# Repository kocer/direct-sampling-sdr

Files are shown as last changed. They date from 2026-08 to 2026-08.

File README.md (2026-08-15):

# Direct-Sampling SDR

A direct-sampling software-defined radio transceiver and its power
amplifier for the amateur bands from 1.8 MHz to 54 MHz.

## What the equipment does

The receiver samples the antenna signal directly. It does not use a
mixer and it does not use an intermediate frequency. Four receive
channels operate at the same time. The four channels use one clock.
Thus the channels keep a constant phase relation.

The transmitter uses the same four channels in the opposite direction.
The power amplifier increases the transmit power to a maximum of 100 W.

| Item | Value |
|---|---|
| Frequency range | 1.8 MHz to 54 MHz |
| Receive channels | 4, phase coherent |
| Transmit channels | 4 |
| ADC | AD9251BCPZ-80, 14 bit, dual, 80 MSPS |
| DAC | AD9767, 14 bit, dual, operated at 80 MSPS |
| FPGA | Lattice ECP5 LFE5U-25F, BG256 |
| Filter bands | 7 for each channel |
| Amplifier power | 5, 10, 25, 50, 75 and 100 W |
| Amplifier class | A, at all power levels |
| Host interface | 2 x gigabit ethernet |
| Sample clock | 80.000 MHz VCXO, ABLNO-V |
| Clock jitter | 81 fs narrow band, 162 fs wide band |
| Reference | 10 MHz external, or GPS |

## The three boards

| Board | Function | Size | Layers |
|---|---|---|---|
| A | Main board: ADC, DAC, FPGA, ethernet | 235 x 225 mm | 6 |
| C | RF board: filters, transmit/receive relays | 350 x 235 mm | 2 |
| D | Power amplifier: driver, finals, low-pass filters | 275 x 185 mm | 2 |

Board B does not exist. The first design had a separate clock board.
The clock circuit is now on board A, because the distance from the clock
to the ADC controls the phase accuracy.

## Signal path

The receive path:

1. The antenna connects to board C.
2. The band filter removes the unwanted signals.
3. The transmit/receive relay connects the filter to the receive path.
4. The attenuator sets the signal level.
5. Board A receives the signal.
6. The transformer makes the signal differential.
7. The ADC samples the signal.
8. The FPGA processes the samples.
9. The ethernet interface sends the data to the host.

The transmit path:

1. The host sends the data to board A.
2. The DAC makes the analog signal.
3. Board D receives the signal.
4. The driver stage increases the power.
5. The four final transistors increase the power to 100 W.
6. The low-pass filter removes the harmonics.
7. The directional coupler measures the forward and the reflected power.
8. The antenna radiates the signal.

## Why direct sampling

A superheterodyne receiver mixes the input signal to a lower frequency.
The mixer makes unwanted products. The local oscillator adds noise.
Each conversion stage adds distortion.

A direct-sampling receiver has none of these stages. The ADC samples the
antenna signal. The remaining signal path is digital, thus it is exact
and it does not change with the temperature.

The clock sets the limit at high frequency. The jitter of the clock
gives this maximum signal-to-noise ratio:

    SNR = -20 x log10(2 x pi x f x t_jitter)

The VCXO contributes 60 fs and the fan-out buffer adds 54 fs in a narrow
band or 150 fs in a wide band. Together they give 81 fs and 162 fs.

| Input frequency | Jitter | SNR limit | What limits the result |
|---|---|---|---|
| 30 MHz | 81 fs | 96 dB | The noise of the ADC |
| 500 MHz | 81 fs | 72 dB | At the limit |
| 500 MHz | 162 fs | 66 dB | The jitter of the clock |

In the amateur bands the noise of the ADC is the limit and the clock is
not. The clock becomes the limit only when the receiver undersamples
near 500 MHz. A better clock part costs ten times more, and 66 dB is
still 11 effective bits.

## Why four coherent channels

Four channels that share one clock keep a constant phase relation. This
makes these functions possible:

- Removal of a local noise source with a second antenna
- Measurement of the direction of a signal
- Increase of the antenna gain in one direction
- Measurement of meteor trails with two or more sites

A receiver with one channel cannot do these functions.

## Licenses

| Content | License |
|---|---|
| Hardware design | CERN-OHL-S-2.0 |
| Software and scripts | GPL-3.0 |
| Documentation | CC-BY-SA-4.0 |

## Repository content

| Directory | Content |
|---|---|
| `hardware/kicad/A_main` | Board A: schematic, PCB, generator scripts |
| `hardware/kicad/C_rf` | Board C |
| `hardware/kicad/D_pa` | Board D |
| `hardware/kicad/lib` | Symbols and footprints |
| `gateware/rtl` | Verilog source for the ECP5 |
| `gateware/sim` | Test benches |
| `gateware/sentez` | Synthesis and place-and-route scripts |
| `docs` | Design documentation |

The schematics are not drawn by hand. Python scripts make them. Each
script writes one sheet. To change a sheet, change the script and run
it again. The document `docs/TOOLS.md` gives the procedure.

## Status

The three schematics are complete. The electrical rule check finds no
errors on the three boards. The placement is complete. The routing is
in progress. No board is ready for manufacture.

The gateware operates in simulation. 21 test benches pass. The design
fits in the ECP5-25F and it meets the timing of all five clocks. The
receive chain, the transmit chain, the packet interface and the
control interface are complete. The SDRAM interface and the digital
predistortion do not exist.

Verification tools examine the boards and the schematics. They find
faults that the electrical rule check cannot find. An example: a
symbol pin number that does not agree with a footprint pad number
makes a net that goes nowhere, but the rule check sees a correct
wire. The commit messages give the details of each fault.

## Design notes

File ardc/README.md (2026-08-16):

# Direct-sampling SDR transceiver — ARDC technical annex

**Project:** a four-channel, phase-coherent, direct RF sampling transceiver
**For:** the amateur radio club of TEVITOL (Gebze, Kocaeli), station callsign **YM2X**
**Licence:** GPL-3.0 (gateware) · CERN-OHL-S v2 (hardware) · CC-BY-SA 4.0 (documents)

This folder is the technical annex of the ARDC grant application.

**Numbers are not written here.** They are in `VERIFICATION.md`, which
`ardc/topla.py` generates by running the tools and recording what they
report. A document that carries its own copy of the numbers becomes
old without anyone seeing it. That happened once in this project: the
bill of materials in this folder gave 150 nH for a filter inductor
when the board had 68 nH, after two redesigns.

---

## 1. What the unit does

There is no mixer and no intermediate frequency. The antenna goes to a
band-pass preselector and then to a 14-bit ADC that samples at
80 MSPS. All down-conversion, filtering and demodulation happen inside
the FPGA.

| Item | Value |
|---|---|
| Receive coverage | 1 MHz to 500 MHz (undersampling above 40 MHz) |
| Receive channels | 4, phase-coherent |
| Instantaneous window | 40 MHz per channel |
| Transmit coverage | 1.8 MHz to 30 MHz |
| Transmit power | 5 / 10 / 25 / 50 / 75 / 100 W, class A throughout |
| Clock | 80.000 MHz VCXO, less than 100 fs jitter, GPS disciplined |
| FPGA | Lattice ECP5 LFE5U-25F, caBGA-256 |
| Host interface | 2 × gigabit Ethernet |

The four phase-coherent channels are the distinctive property of the
design. `RATIONALE.md` gives the reason.

**The transmit envelope has limits.** A sampling DAC makes images as
well as the wanted frequency, and the images must be filtered. Four
channel transmit works from 160 m to 30 m. Two channel transmit works
from 160 m to 10 m. There is no transmit on 6 m: the band is above
Nyquist, the fundamental at 26 MHz to 30 MHz is stronger than the
carrier, and no practical filter removes it. Receive works on all
bands, 6 m included. Section 4.3.1 of `docs/DATASHEET.md` gives the
measurements.

---

## 2. The three boards

| Board | Role | Layers | Size |
|---|---|---|---|
| **A** — `A_main` | ADC, DAC, ECP5 FPGA, SDRAM, 2 × gigabit PHY, clock, power tree | 6 | 235 × 225 mm |
| **C** — `C_rf` | RF filter bank: 4 channels × 7 bands, protection, T/R, attenuator | 2 | 350 × 235 mm |
| **D** — `D_pa` | Power amplifier: class A 5 W to 100 W, bias servo, harmonic filter bank, SWR protection | 2 | 275 × 185 mm |

The boards connect through 2×10 and 1×6 headers. The RF paths use SMA.
Boards C and D take their shift-register data from one chain on board
A, so an added PA board needs no more pins from A.

---

## 3. Present state — the honest table

### Complete

- **Schematics.** All three boards are complete and ERC gives no
  violations. The schematics are not drawn by hand: each sheet comes
  from a Python generator (`gen_*.py`), so it is repeatable and it can
  be reviewed as source.
- **Part selection.** All three bills of materials have a verified
  order code on every line. A tool queries the supplier and checks the
  package, the value, the stock and the real properties of the part.
- **Gateware.** The Verilog RTL synthesises with Yosys and places with
  nextpnr-ecp5, and it produces a bitstream. All clocks meet their
  constraints.
- **Circuit simulation.** The receive chain, the transmit chain, the
  bias servo, the power distribution network and the thermal path are
  all simulated. Connectivity checks cannot see this class of fault.
- **Tolerance analysis.** The design is measured with real component
  tolerances and over temperature, by worst case and by Monte Carlo.
  Two filter positions were redesigned because of the result.
- **Formal verification.** Three properties are proven, and each proof
  was tested by mutation.

### Not complete — stated plainly

- **Routing is not finished.** The copper of the three boards is still
  in the automatic router. **No board in this package can go to
  manufacture.**
- **Five items need a measurement or a datasheet value.** The exposed
  pad dimensions of the RTL8211F and the AD8318, the AD8318 TADJ
  resistor at HF, the crystal stray capacitance, and the PE4312 series
  resistor timing. None of them is invented; where a choice was
  necessary, the safe direction was taken.
- **No board is built and nothing is measured.** The performance
  figures in `TASARIM.md` are calculations and datasheet values.

### Deliberately not in scope

- Enclosure, panel and cable harness design.
- Host-side software. The Ethernet packet format is defined.

---

## 4. Contents of this folder

```
ardc/
  README.md          this file
  VERIFICATION.md    generated: what ran, and what it reported
  RATIONALE.md       why direct sampling, why the ECP5, why four channels
  topla.py           the script that builds this package
  sema/              schematics of the three boards, PDF
  bom/               bills of materials of the three boards, CSV
```

Run `python3 ardc/topla.py` to rebuild the package. The script
regenerates the schematics and the bills of materials from the design
source, runs every verification tool, and writes `VERIFICATION.md`
with what they report. If a tool fails, the script says so and the
package is marked incomplete.

Related documents in the repository root: `docs/DATASHEET.md` (the
electrical specification, with the source of each row), `TASARIM.md`
(full design rationale, Turkish), `PA_TASARIM.md` (power amplifier),
`kicad/NETLIST.md` (the source of the net list).

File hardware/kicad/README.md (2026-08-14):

# KiCad çalışma dizini

```
lib/dogrudan-sdr.kicad_sym   sembol kütüphanesi
lib/gen_symbols.py           üreteç — sembolleri BU yazıyor, elle düzenleme
lib/ATTRIBUTION.md           ECP5 sembolü kaynağı ve lisansı
A_main/                      A kartı (ADC+DAC+saat+FPGA+PHY+güç)
C_frontend/                  C kartı (koruma+T/R+zayıflatıcı+ön seçici)
```

## Semboller

| Sembol | Pin | Birim | Kaynak | Durum |
|---|---|---|---|---|
| ECP5-BGA256 | 256 | 8 | Cynthion (CERN-OHL-P) | pin uyumu doğrulandı |
| AD9251 | 65 | 4 | datasheet Rev.C s.11-12 | görsel doğrulandı |
| AD9767 | 48 | 3 | datasheet Rev.G s.9-10 | pin sayımı doğrulandı |
| RTL8211F | 41 | 2 | datasheet Rev.1.1 s.14-17 | görsel doğrulandı |
| PE4312 | 21 | 1 | DOC-81482-4.01 s.15 | pin sayımı doğrulandı |
| ADP150 | 5 | 1 | datasheet Rev.E s.6 | — |
| ABLNO-V | 4 | 1 | Abracon ABLNO s.8 | **doğrulandı** |

KiCad standart kütüphanesinden ayrıca: `W25Q128JVS`, `TPS62130`, `TPS7A20`.

## Üreteci kullan, dosyayı elle düzenleme

```bash
cd lib
python3 gen_symbols.py          # kütüphaneye ekler
kicad-cli sym export svg -o /tmp/s dogrudan-sdr.kicad_sym
rsvg-convert -w 800 /tmp/s/AD9251_unit1.svg -o /tmp/x.png   # gözle bak
```

`gen_symbols.py` kutu geometrisini pin sayısı **ve isim uzunluklarından**
hesaplıyor. Elle kutu yazma; iki kere denedim, ikisinde de pin gövdesi
kutunun içinde kaldı ve o pine tel bağlanamadı.

> Üreteç kütüphaneye **ekliyor**, sıfırlamıyor. Yeniden üretmeden önce
> temiz kütüphaneyi geri yükle, yoksa semboller tekrarlanır.

## Doğrulanmış footprint'ler

Hepsi KiCad 10 standart kütüphanesinde:

```
BGA-256_14.0x14.0mm_Layout16x16_P0.8mm      ECP5 caBGA-256
QFN-64-1EP_9x9mm_P0.5mm_EP3.8x3.8mm         AD9251 LFCSP-64
LQFP-48_7x7mm_P0.5mm                        AD9767
QFN-40-1EP_5x5mm_P0.4mm_EP3.8x3.8mm         RTL8211F
QFN-20-1EP_4x4mm_P0.5mm_EP2.6x2.6mm         PE4312
TSOT-23-5                                   ADP150
```

ABLNO ayak izi bu depoda çizildi: `lib/dogrudan-sdr.pretty/`
`Oscillator_Abracon_ABLNO_4pad_14.3x8.7mm.kicad_mod`
Gövde 14.30 × 8.70 mm, 4 ped 2.5 × 1.5 mm, aralık 5.08 × 5.80 mm.

> Pin-1 işaretini ilk çizişte yanlış köşeye koydum (pad 4'ün yanına).
> Parçanın 180° ters lehimlenmesine yol açardı. SVG'ye bakınca yakalandı.
> **Her ayak izini çizdikten sonra render edip gözle bak.**

## Sıradaki adım: netlist şartnamesi

Şema üretmeden önce **hangi pin nereye** yazılacak, insan okuyabilir metin
olarak. Sebep: 256 pinlik BGA'nın bağlantılarını doğrudan `.kicad_sch`
dosyasına yazmak görsel olarak doğrulanamaz. Şartname gözden geçirilebilir,
şema ondan üretilir.

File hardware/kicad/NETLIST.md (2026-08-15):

# A KARTI — NETLİST ŞARTNAMESİ

Şema bundan üretilecek. Amaç: bağlantıları **gözden geçirilebilir** hale
getirmek. 256 pinlik BGA'yı doğrudan `.kicad_sch`'e yazmak görsel olarak
doğrulanamaz; bu dosya doğrulanabilir.

> **Pin ataması BANKA bazında.** Tek tek BGA topu yazılmıyor. FPGA pinleri
> banka içinde takas edilebilir ve doğru atama layout sırasında, yol
> kesişmelerine göre kesinleşir. Şartname bankayı ve sayıyı sabitler.

---

## 0. ECP5 banka planı

`LFE5U-25F-7BG256I`, 184 kullanılabilir I/O + bank 8'de 13 konfig pini.

| Banka | Birim | I/O | VCCIO | İşlev | Kullanılan |
|---|---|---|---|---|---|
| 6 (sol) | 6 | 32 | **1.8 V** | ADC-1 + ADC-2 (çoğullamalı) | 30 |
| 7 (sol) | 7 | 32 | **3.3 V** | SDRAM (39'un 32'si) | 32 |
| 2 (sağ) | 4 | 32 | **3.3 V** | DAC-1 çift port | 32 |
| 3 (sağ) | 5 | 32 | **1.8 V** | PHY-1 + PHY-2 RGMII | 26 |
| 0 (üst) | 2 | 24 | **3.3 V** | SDRAM taşması 7 + kontrol 15 | 22 |
| 1 (üst) | 3 | 32 | **3.3 V** | DAC-2 interleaved 18 + GPS/VCXO/LED 14 | 32 |
| 8 (alt) | 8 | 13 | **3.3 V** | konfigürasyon + SPI flash | 6 |
| — | 1 | — | — | VCC/GND/VCCAUX | 35 pin |

**Toplam 180 / 197.** Banka 1 tam dolu, marj yok — oraya bir şey daha
eklenirse başka bankadan yer açılacak.

> **Şema çizilirken düzeltildi (08_control).** Banka 0'ın 24 I/O'su
> §7'deki listeye yetmedi: `RLY_RCLK` ve T/R kontrolün dört hattı
> banka 1'e kaydı. Banka 1 böylece 32/32 doldu ve durum LED'leri
> dışarıda kaldı — onlar röle kaydırmalı yazmacının boş çıkışlarından
> sürülecek, FPGA pini harcamayacak. Gerçek dağılım şemada.

> **HER ŞEY REV A'DA DOLDURULUYOR.** Ayak izi bırakıp sonra doldurma yok:
> iki ADC, iki DAC, iki PHY, SDRAM, GPSDO, harici referans girişi. Karar
> bilinçli — parça parça yapmak yerine tek seferde tam sürüm.

### Banka gerilimi neden böyle

```
ADC veri     1.8 V   DRVDD'yi 1.8'e alıyoruz — 3.3 V CMOS anahtarlama
                     gürültüsü aynı kartta analog girişe geri kuple oluyor
DAC veri     3.3 V   AD9767 lojik-1 eşiği 2.1 V @ DVDD 3.3 V
RGMII        1.8 V   RTL8211F 3.3/2.5/1.8/1.5 destekliyor; düşük EMI
konfig       3.3 V   W25Q128 3.3 V
```

---

## 1. GÜÇ AĞACI

Giriş 9–18 V DC, ters polarite korumalı (bkz §9).

```
VIN 9-18V ─► ters polarite (P-MOSFET) ─► TPS62130 ─► +3.3V  (ana ray)
                                                       │
   ┌───────────────────────────────────────────────────┤
   │                                                   │
   ├─► TPS62130 #2 ──► +1.1V   FPGA cekirdek           │
   ├─► TPS7A2033 ────► +1.8V   FPGA bank 6/7/3 VCCIO   │
   ├─► ADP150-2.5 ───► +2.5V   FPGA VCCAUX  (ZORUNLU)  │
   ├─► ADP150-1.8 ───► +1.8V_A ADC AVDD  (AYRI ADA)    │
   ├─► ADP150-1.8 ───► +1.8V_D ADC DRVDD               │
   ├─► ADP150-3.3 ───► +3.3V_CLK  VCXO   (AYRI ADA)    │
   └─► ADP150-3.3 ───► +3.3V_A    DAC AVDD             │
                                                        │
   PHY: DVDD33, AVDD33 ◄───────────────────────────────┘
        DVDD10, AVDD10 ◄── PHY dahili regülatör (REG_OUT + 2.2µH bobin)
```

> **+2.5 V atlanmıştı.** ECP5'in VCCAUX rayı 2.5 V ister (Cynthion'un
> güç şemasından doğrulandı). İlk güç ağacında yoktu; FPGA'yı çalıştırmayan
> türden bir eksik. `ADP150AUJZ-2.5-R7`, LCSC C144257, $1.00, 302 stok.

**Kritik ayrımlar:**
- `+3.3V_CLK` sadece VCXO'yu besler, kendi LDO'su, ferrit boncukla ayrılmış.
  Besleme gürültüsü doğrudan faz gürültüsüne dönüşüyor.
- `+1.8V_A` sadece ADC AVDD. Anahtarlamalı regülatörden **beslenmez**,
  3.3 V'tan LDO ile düşürülür.
- FPGA çekirdeği ve PHY anahtarlamalıdan beslenebilir, fiziksel olarak uzak.

### Güç sıralaması

ECP5: **VCCIO (3.3) → VCCAUX (2.5) → VCC (1.1)**. TPS62130'ların EN'leri
zincirlenir. ADC: AVDD ve DRVDD sırası serbest (datasheet kısıt koymuyor).

> **Bu satır önce ters yazılmıştı** ("VCC → VCCAUX → VCCIO"). Kart
> baştan beri doğrusunu yapıyor, yanlış olan belgeydi:
> U1 (VIN_PROT→+3V3) EN'i doğrudan girişte, hep açık; U8 (+3V3→+2V5);
> U2 (+3V3→+1V1) EN'i PG_3V3'ten, yani 3.3 V oturduktan sonra kalkıyor.
> Lattice'in kendi kılavuzu da bunu istiyor (ECP5 Hardware Checklist /
> sysIO Usage Guide): *"It is recommended that the I/O buffers be
> powered-up prior to the FPGA core fabric, which means VCCIO supplies
> should be powered before VCC and VCCAUX."*
> Ayrıca eski sıra topolojik olarak imkânsızdı: +1V1 buck'ı girişini
> +3V3'ten alıyor, çekirdek rayı önce kalkamaz.
> Yanlış belgeye bakıp "sırayı düzeltelim" diyen biri çalışan bir
> tasarımı bozardı; kaynak burada yazılı ki bir daha tartışılmasın.

### Ayrıştırma

| Nerede | Ne |
|---|---|
| Her ECP5 VCC/VCCIO topu | 100 nF, topa en yakın, viası doğrudan düzleme |
| ECP5 toplu | 4× 10 µF + 2× 47 µF |
| ADC AVDD ×8 | pin başına 100 nF + toplu 10 µF |
| ADC DRVDD ×4 | pin başına 100 nF |
| VCXO Vdd | 100 nF + 10 µF + **ferrit boncuk** |
| DAC AVDD/DVDD | 100 nF her pinde |
| PHY | datasheet önerisi, 10 µF X5R (Y5V KULLANMA — datasheet uyarıyor) |

---

## 2. SAAT DAĞITIMI

```
ABLNO-V-80.000MHZ
  pin 4 Vdd  ◄── +3.3V_CLK (ayrı LDO + ferrit)
  pin 2 GND
  pin 1 Vc   ◄── GPSDO kontrol (§7)
  pin 3 OUT  ──► saat tamponu ──┬─► ADC-1 CLK+/CLK−
                                ├─► ADC-2 CLK+/CLK−
                                ├─► DAC CLK1, CLK2
                                └─► FPGA PCLK girişi (bank 6 veya 7)
```

**Saat tamponu: ADCLK846BCPZ-REEL7** (LCSC C578957, $2.31, 1640 stok).
1:6 LVDS fanout, LFCSP-24 4×4, ADI saat dağıtım ailesi.

Neden bu: LMK1D1204'ten ucuz ve altı çıkışlı (dört yetmiyor). AD9251 saat
girişi PECL/LVDS/1.8 V CMOS kabul ediyor, LVDS doğrudan bağlanıyor.

```
çıkış 1 ──► ADC-1 CLK+/CLK−     LVDS, doğrudan
çıkış 2 ──► ADC-2 CLK+/CLK−     LVDS, doğrudan
çıkış 3 ──► FPGA PCLK           LVDS girişi
çıkış 4 ──► DAC saat yolu       ** çevirici gerekiyor, §10 **
çıkış 5 ──► test noktası
çıkış 6 ──► harici referans çıkışı (opsiyonel)
```

> **DAC saati sorunlu.** AD9767'nin CLK1/CLK2 girişi CMOS seviyesi
> (DVDD 3.3 V'ta lojik-1 eşiği 2.1 V), LVDS doğrudan süremiyor. İki yol:
> LVDS→CMOS çevirici, ya da saati FPGA'dan yeniden üret. İkincisi bedava
> ama FPGA çıkış jitter'ı (ps mertebesi) verilen sinyalin faz gürültüsüne
> giriyor. **Çevirici tercih edilmeli.** §10'a taşındı.

```
√(60² + 50²) = 78 fs      VCXO 60 fs + tampon 50 fs
```

ADC saat girişi diferansiyel (PECL/LVDS/1.8 V CMOS kabul ediyor). LVCMOS
tampondan tek uçlu sürülecekse CLK− uygun şekilde biaslanmalı; tercih
**diferansiyel tampon**, faz uyumu için de daha iyi.

> **FAZ UYUMU BURADAN GELİYOR.** Dört ADC kanalı ve iki DAC kanalı aynı
> saatten besleniyor. Tampon çıkışları arasındaki gecikme farkı sabit
> olmalı; eşit uzunlukta yol çek. Gürültü iptali, yön bulma ve ışın
> şekillendirme bu eşitliğe bağlı.

---

## 3. ADC — 2× AD9251

Her çip iki kanal. Toplam dört faz-uyumlu kanal.

### 3.1 Analog giriş (çip başına, iki kanal)

```
BNC ─► C kartı (koruma, zayıflatıcı, ön seçici) ─► ADT1-1WT+ ─┬─► VIN+
                                                              └─► VIN−
                                              VCM (pin 57) ───► trafo orta ucu
```

- Trafo ADT1-1WT+, 1:1. **Pinout (Rev.G s.2):** 3 PRI DOT · 1 PRI ·
  6 SEC DOT · 4 SEC · **2 SEC CT** · 5 kullanılmıyor
- **VCM (pin 57)** trafonun ikincil orta ucuna (pin 2) → ortak mod 0.9 V
- VIN çifti: eş boy, sıkı çift, kısa
- Giriş kapasitansı 6 pF, sürüş direnci ile birlikte kutup oluşturur

**Referans devre — AD9251 Şekil 42 + Tablo 9.** İlk çizimde bunların
üçü de eksikti; trafonun birincili açık devre görüyordu, yani 50 Ω hat
hiç sonlanmıyordu.

```
SMA ─┬─ 49.9Ω → GND          hattın sonlandığı yer
     └─ trafo PRI DOT (3),  PRI (1) → GND
        trafo SEC DOT (6) ─ Rs ─┬─ VIN+
        trafo SEC     (4) ─ Rs ─┴─ VIN−     C_dif VIN+ ↔ VIN−
        trafo SEC CT  (2) ─────── VCM
```

| Giriş frekansı | Rs (her biri) | C_dif |
|---|---|---|
| 0–70 MHz | 33 Ω | 22 pF |
| 70–200 MHz | 125 Ω | takılmıyor |

Tek değer ikisine birden uymuyor; alet hem tabanbant hem alt-örnekleme
yapıyor. Şemada 33 Ω + 22 pF çizili (HF/6 m). VHF/UHF alt-örneklemede
aynı ayak izine 125 Ω takılıp C sökülüyor — hepsi 0603, kart değişmiyor,
seçim montajda.

### 3.2 Referans ve bias

| Pin | Bağlantı |
|---|---|
| 55 VREF | 1 µF → AGND (dahili referans kullanılıyor) |
| 56 SENSE | **AGND'ye** → dahili 1.0 V referans seçilir |
| 57 VCM | 0.1 µF → AGND, ve trafo orta ucuna |
| 58 RBIAS | **10 kΩ %1** → AGND |

### 3.3 Dijital çıkış → FPGA

**Çoğullama KULLANILIYOR** (MUX açık). Karar değişti — önce reddetmiştim,
iki gerekçeyle geri alındı:

```
çoğullamasız   30 hat/çip, 80 MHz     → iki çip 60 pin, bütçe tutmuyor
çoğullamalı    15 hat/çip, 160 MHz    → iki çip 30 pin
```

1. ECP5 −7 hız derecesi pin başına 400+ Mbps DDR yapıyor. 160 MHz SDR
   agresif değil.
2. **Gürültü avantajı:** 30 yerine 15 anahtarlanan hat. Hassas analog ön
   ucun yanında daha az dijital gürültü. Bunu ilk seferde kaçırmıştım.

Çip başına 15 hat, iki çip **aynı bankada** (banka 6) — zamanlama eşleşmesi
ve faz uyumu için önemli:

| ADC pini | FPGA | Not |
|---|---|---|
| D0A…D13A (27,29-36,38-42) | banka 6 | çoğullanmış veri, A ve B dönüşümlü |
| DCOA (24) | banka 6, **saat-yetenekli pin** | 160 MHz veri saati |
| D0B…D13B | **kullanılmıyor** — çoğullama modunda boşta | |
| DCOB (23) | kullanılmıyor | |

Çoğullama SPI üzerinden açılıyor (bkz datasheet "Data Output Multiplex
Option"). Kanal sırası (önce A mı B mi) SPI'dan okunacak ve firmware'de
sabitlenecek.

ORA (43) / ORB (22) aralık-dışı bayrakları: bağlanabilir ama şart değil,
FPGA'da doygunluk zaten tespit edilebilir. **Bağla** — bedava ve ADC
doyduğunu bilmek panorama için değerli.

### 3.4 Kontrol

SPI, iki çip ortak yol, ayrı seçme:

| ADC pini | FPGA / bağlantı |
|---|---|
| 44 SDIO/DCS | bank 0, ortak (çift yönlü) |
| 45 SCLK/DFS | bank 0, ortak |
| 46 ~CSB | bank 0, **çip başına ayrı** (2 hat) |
| 47 ~OEB | AGND'ye (çıkışlar hep açık) |
| 48 PDWN | bank 0, çip başına ayrı, ya da GND |
| 3 SYNC | bank 0, **iki çipe ORTAK** ← faz uyumu için kritik |

> **SYNC iki çipe ortak ve eş uzunlukta gitmeli.** İki ADC'nin iç
> bölücülerini aynı anda sıfırlıyor. Faz uyumu buna bağlı.

### 3.5 Toprak

Pin 0 (exposed paddle) **çipin tek toprak bağlantısı.** Termal via dizisi
ile doğrudan toprak düzlemine. Datasheet: "must be soldered to PCB ground".

---

## 4. DAC — 2× AD9767

Çift port modu (**MODE pin 48 = HIGH**). Interleaved kullanılmıyor: veri
yolunu 160 MHz'e çıkarır, ADC'deki aynı gerekçe.

### 4.1 Dijital (çip başına 32 hat, bank 2)

| DAC pini | FPGA |
|---|---|
| DB0P1…DB13P1 (14…1) | bank 2, port 1 veri |
| DB0P2…DB13P2 (36…23) | bank 2, port 2 veri |
| 17 WRT1, 18 CLK1 | bank 2 |
| 20 WRT2, 19 CLK2 | bank 2 |

### 4.1b İkinci AD9767 — interleaved, bank 1 (KARAR VERİLDİ)

Bank 2'yi birinci DAC tam dolduruyor. İkinci çip için çift portta 32 pin
gerekiyor, boş banka yok.

**Karar: ikinci DAC interleaved modda (MODE = LOW), bank 1'e.**

```
interleaved pin sayısı   14 veri + IQWRT + IQCLK + IQRESET + IQSEL = 18
bank 1 boş pin           ~20
```

Bedeli: tek veri yolu iki kanalı taşıyor, yani yol 160 MHz'de sürülüyor.
ECP5-25 hız derecesi −7'de yapılabilir ama zamanlama sıkı.

> **Bu paragraf değişti.** Eskiden "rev A'da doldurulmuyor, yolları çizili
> duruyor" yazıyordu. Karar "tek seferde en iyisi" olduğu için ikinci
> AD9767 **rev A'da doldurulıyor** — BOM'da iki adet var, şemada (04_dac)
> tam çizili. Dolayısıyla 160 MHz zamanlama riski rev A'yı **etkiliyor**:
> ECP5 −7'de yapılabilir ama marj dar, bringup'ta ölçülecek. Tutmazsa
> rev B'de çift porta geçilir ve bank planı yeniden düzenlenir.

### 4.2 Analog çıkış

```
IOUTA1 (46) ─┬─► rekonstrüksiyon LPF 36 MHz ─► sürücü ─► BNC
IOUTB1 (45) ─┘   diferansiyel, trafo kuplaj, 50 Ω çift sonlandirmali
```
Datasheet: "differential transformer-coupled output, 50 Ω doubly terminated,
IOUTFS = 20 mA".

### 4.3 Referans

| Pin | Bağlantı |
|---|---|
| 43 REFIO | 0.1 µF → ACOM (dahili 1.2 V referans) |
| 44 FSADJ1 | R_set → ACOM, IOUTFS = 32 × (1.2 / R_set) |
| 41 FSADJ2 | aynı |
| 42 GAINCTRL | ACOM (master/slave modu, dahili referans) |
| 37 SLEEP | FPGA bank 0 (veya ACOM) |
| 48 MODE | **+3.3V** (çift port) |

20 mA için R_set = 32 × 1.2 / 0.020 = **1.92 kΩ**.

---

## 4b. SDRAM — W9825G6KH-6I

**W9825G6KH-6I**, LCSC C97572, $7.41, 7181 stok, TSOP-54, endüstriyel.
32 MB (256 Mbit), 16 bit veri, 166 MHz.

Neden var: patlama yakalama. ECP5'in dahili blok RAM'i 1008 kbit = 126 KB,
tam hızda **0.79 ms** eder. Meteor olayı 10 ms ile birkaç saniye arası,
yani dahili RAM olayın sadece ön kenarını yakalıyor.

```
32 MB / 160 MB/s = 200 ms tam hız yakalama     ← 250 kat
```

> **160 MB/s SDRAM'e yazılabiliyor mu — hesap yapıldı, sınırda.**
>
> ```
> 16 bit @ 166 MHz SDR   = 332 MB/s tepe
> refresh + satır açma payı ~%65-75 → 215-250 MB/s sürdürülebilir   ✓
>
> 16 bit @ 100 MHz SDR   = 200 MB/s tepe
> aynı pay              → 130-150 MB/s                              ✗
> ```
>
> Yani SDRAM'i **133 MHz'in altında koşturamayız.** "Rahat olsun" diye
> 100 MHz seçilirse tam hız yakalama tutmaz ve 200 ms rakamı düşer.
> W9825G6KH-**6I** zaten 166 MHz'lik parça, marj var ama yönlendirme
> buna göre yapılacak: CLK seri sonlandırmalı, DQ grubuyla eş boy.
>
> **Ayrıca: tam hızda yakalanan tek kanal.** Dört kanal aynı anda
> 4 × 160 = 640 MB/s eder, hiçbir şekilde olmaz. Dört kanallı yakalama
> için desimasyon şart (kanal başına ~20 MSPS). Meteor/girişim
> yakalamada tek kanal tam hız, yön bulmada dört kanal desimeli.

**DDR3 değil, SDR SDRAM.** Kasten: DDR3 yönlendirmesi (fly-by, ODT,
kalibrasyon) rev A'ya ağır yük. SDR SDRAM tek çip, düz yönlendirme,
LiteX'in `LiteDRAM`'i destekliyor.

| Sinyal | Adet | Banka |
|---|---|---|
| DQ0–15 | 16 | 7 |
| A0–A12 | 13 | 7 (9) + 0 (4) |
| BA0–BA1 | 2 | 0 |
| CLK, CKE, ~CS, ~RAS, ~CAS, ~WE | 6 | 7 |
| DQM0–1 | 2 | 0 |
| **toplam** | **39** | 32 + 7 |

Adres hatlarının bir kısmı banka 0'a taşıyor. Veri yolu (DQ) ve strobe
tek bankada kalıyor — zamanlama açısından önemli olan bu.

CLK hattı eş boy ve mümkünse seri sonlandırmalı. 166 MHz'de yol uzunluğu
farkı setup marjını yiyor.

---

## 5. ETHERNET — 2× RTL8211F

### 5.1 RGMII → FPGA bank 3 (1.8 V)

| PHY pini | FPGA | Yön |
|---|---|---|
| 20 TXC, 18 TXD0, 17 TXD1, 16 TXD2, 15 TXD3, 19 TXCTL | bank 3 | FPGA → PHY |
| 27 RXC, 25 RXD0, 24 RXD1, 23 RXD2, 22 RXD3, 26 RXCTL | bank 3 | PHY → FPGA |

**Uzunluk eşleme:** TXC ile TXD[3:0]/TXCTL grubu ±5 mm içinde; RXC ile
RXD grubu aynı. Gruplar arası eşleme gerekmez.

MDC (13) ve MDIO (14): **iki PHY ortak**, MDIO'ya 1.5 kΩ pull-up (1.8 V).
PHY adresleri strap ile ayrılır (aşağı).

### 5.2 Strap dirençleri — reset anında okunuyor

Pin 22/23/24/25/26/27 hem RGMII verisi hem strap. Reset sırasında
seviyeleri okunuyor, sonra normal işlev.

| Pin | Strap | PHY-1 | PHY-2 |
|---|---|---|---|
| 22 PHYAD0 | PHY adresi bit 0 | pull-down | **pull-up** |
| 27 PHYAD1 | bit 1 | pull-down | pull-down |
| 26 PHYAD2 | bit 2 | pull-down | pull-down |
| 24 TXDLY | TXC'ye 2 ns gecikme | **pull-up** | **pull-up** |
| 25 RXDLY | RXC'ye 2 ns gecikme | **pull-up** | **pull-up** |
| 23 PLLOFF | ALDPS'te PLL kapat | pull-down | pull-down |

TXDLY/RXDLY yukarı çekilerek RGMII'nin 2 ns iç gecikmesi PHY'da üretilir;
FPGA tarafında gecikme yaratmak gerekmez. Adres 0 ve 1 olur.

> Strap dirençleri **1 kΩ**, RGMII sinyal bütünlüğünü bozmayacak kadar
> yüksek, strap'i belirleyecek kadar düşük.

### 5.3 Saat

```
25 MHz kristal (X322525MOB4SI) ─► XTAL_IN (36) / XTAL_OUT (37)
yük kondansatörleri kristal spec'ine göre
```
İki PHY'a **ayrı kristal** (paylaşım denenmesin, PHY'ın kendi osilatörü var).
CLKOUT (35) boşta bırakılır.

### 5.4 MDI ve manyetik

```
MDIP0/N0 (1,2) ┐
MDIP1/N1 (4,5) ├─► HR911105A (dahili manyetik + RJ45)
MDIP2/N2 (6,7) │
MDIP3/N3 (9,10)┘
```
Çift içi eş boy, çiftler arası eşleme gerekmez. Bob Smith sonlandırma
manyetik tarafında.

### 5.5 Regülatör ve referans

| Pin | Bağlantı |
|---|---|
| 39 RSET | datasheet direnci → GND |
| 30 REG_OUT | **2.2 µH veya 4.7 µH bobin** → DVDD10/AVDD10 (anahtarlamalı reg) |
| 32/33/34 LED0-2 | LED + direnç → 3.3 V (ve strap görevi) |
| 12 ~PHYRSTB | FPGA bank 3, ≥10 ms low |
| 31 ~INTB | FPGA bank 3, 3.3 V pull-up |
| 28 DVDD_RG | **+1.8 V** (RGMII I/O gerilimi) |
| 32 CFG_EXT | **pull-up** → harici güç kaynağı modu (DVDD_RG'yi biz veriyoruz) |

> Datasheet uyarısı: REG_OUT bobini ve çıkış kondansatörü seçimi kritik,
> **Y5V seramik kullanma** (s.46-53 dalgalanma ölçümleri).

---

## 6. KONFİGÜRASYON — bank 8

```
W25Q128JVS ─► ECP5 master SPI modu
  CS   ◄── ~CSSPI / PB15A
  CLK  ◄── CCLK
  MOSI ◄── DOUT/~CSO / PB15B
  MISO ──► ~HOLD/DI/BUSY / PB15A grubu
```

| ECP5 | Bağlantı |
|---|---|
| CFG0/1/2 | master SPI modu için datasheet kombinasyonu |
| ~PROGRAMN | 10 kΩ pull-up + buton |
| INITN | 10 kΩ pull-up |
| DONE | 10 kΩ pull-up + LED |
| TCK/TMS/TDI/TDO | **JTAG başlığı** (2.54 mm, 6 pin) |

JTAG başlığı şart — bringup'ta flash boş olacak, JTAG'den yüklenecek.

---

## 7. KONTROL VE MUHTELİF — bank 0/1

| İşlev | Hat | Banka |
|---|---|---|
| ADC SPI (SDIO, SCLK) | 2 | 0 |
| ADC ~CSB ×2 | 2 | 0 |
| ADC SYNC (ortak) | 1 | 0 |
| DAC SLEEP | 1 | 0 |
| PE4312 #1 (Data, Clock, LE) | 3 | 0 |
| PE4312 #2 | 3 | 0 |
| C kartı röle kaydırmalı yazmaç (SER, SRCLK) | 2 | 0 |
| röle RCLK (banka 0'dan taştı) | 1 | **1** |
| T/R kontrol (banka 0'dan taştı) | 4 | **1** |
| **GPS 1PPS girişi** | 1 | 1, saat-yetenekli pin |
| GPS UART (RX/TX) | 2 | 1 |
| VCXO Vc → DAC (SPI: CS, CLK, DIN) | 3 | 1 |
| Durum LED'leri | 4 | 1 |
| Hata ayıklama UART | 2 | 1 |
| Harici 10 MHz ref girişi (opsiyonel) | 1 | 1, saat-yetenekli |

**GPS 1PPS saat-yetenekli pine bağlanmalı** — kenarı doğrudan sayaçla
yakalanacak, yumuşak I/O'da jitter olur.

---

## 8. KART ARASI — A ↔ C

| Sinyal | Adet | Not |
|---|---|---|
| RF anten girişi | 4 | koaks kuyruk ya da SMA kart-arası |
| RF veriş çıkışı | 2 | aynı |
| Röle kontrol (kaydırmalı yazmaç) | 3 | + güç ve toprak |
| T/R kontrol | 4 | port başına |
| PE4312 seri hat | 6 | iki zayıflatıcı |
| +3.3 V, +12 V, GND | 3 | röle bobinleri 12 V |

Konnektör: RF için koaks kuyruk (kart-arası SMA sinyal bütünlüğü için
daha iyi ama pahalı), dijital için 2.54 mm başlık.

---

## 9. GİRİŞ KORUMASI VE BESLEME

```
XT60 ─► P-MOSFET ters polarite ─► TVS (SMBJ20A) ─► sigorta 2 A ─► TPS62130
```
- P-MOSFET ters polarite: düşük düşüş, akü ucu ters takılınca kurtarır
- TVS 20 V: akü hattındaki geçici aşırı gerilim
- Sigorta 2 A: 2.8 W @ 9 V = 310 mA, 2 A bol marj

---

## 10. AÇIK KARARLAR — şema çizilmeden kapanacak

1. ~~İkinci AD9767'nin pinleri~~ **KAPANDI** — interleaved, bank 1. §4.1b
2. ~~Saat tamponu parçası~~ **KAPANDI** — ADCLK846. §2
2b. ~~ADCLK846 eklemeli jitter~~ **KAPANDI** — Rev.C Tablo 1:
   54 fs (12 kHz–20 MHz), 86 fs (10 Hz–100 MHz), 150 fs geniş bant.
   VCXO ile toplam **81 fs dar bant / 162 fs geniş bant.**
   SNR tavanı: 30 MHz'de 96 dB (ADC'nin kendi gürültüsü sınır),
   500 MHz'de 66–72 dB (**saat jitter'ı sınırlıyor**). UHF alt-örneklemede
   ~11 bit efektif; kabul edildi. Daha iyisi LMK04828 sınıfı, on kat pahalı.
2c. ~~DAC saati LVDS→CMOS çevirici~~ **KAPANDI** — `SN65LVDS2DBVR`,
   LCSC C38204, $0.36, 1244 stok, SOT-23-5. İki adet, DAC başına bir.
   ADCLK846'nın CMOS modu kullanılamadı: çıkışı 1.8 V CMOS olurdu,
   AD9767'nin lojik-1 eşiği 2.1 V.
2d. **ADCLK846 VS = 1.8 V, 3.3 V değil.** Veri sayfası başlığı. Güç
   ağacında saat bölümü baştan 3.3 V varsayılmıştı; tampona kendi
   `+1V8_CLK` rayı eklendi (01_power U9, ADP150-1.8, +2.5 V'tan
   besleniyor). Bu ray olmadan tampon hiç çalışmaz.
2e. **VCXO → tampon seviye uyumu.** VCXO çıkışı 3.3 V LVCMOS, ADCLK846
   girişinin azami seviyesi **1.8 V p-p**: "Larger voltage swings can turn
   on the protection diodes and can degrade jitter performance."
   Doğrudan bağlansaydı koruma diyotları iletime girer, aletin manşet
   özelliği ilk bağlantıda ölürdü. 220R/100R bölücü (1.03 V p-p) +
   AC kuplaj + VREF (VS/2) bias eklendi.
3. **ECP5 saat-yetenekli pinler.** Hangi banka hangi PLL girişine bağlı —
   Lattice pinout dosyasından çıkarılacak. DCOA/DCOB ve 80 MHz saat oraya
   gidecek.
4. **PHY REG_OUT bobini** değeri ve kondansatör tipi (datasheet s.46-53).
5. **AD9251 SYNC kullanımı** — iki çipi gerçekten hizalıyor mu, yoksa
   ek prosedür mü gerekiyor? Datasheet "Channel/Chip Synchronization"
   bölümü okunacak.
6. **Kart ölçüsü ve kutu** — layout başlamadan kutu seçilecek.

### Şema çizilirken açılan yeni maddeler

7. **ADT1-1WT+ pinout.** Sembol CD542 gövdesinin alışıldık dizilimiyle
   çizildi, veri sayfası elde yok. Yanlışsa RX ön ucunun tamamı ölü.
   Kart basılmadan pin 1/3/4/5/6 tek tek doğrulanacak. (03_adc)
8. **MAGJACK PARÇASI DEĞİŞTİ — HR911105A gigabit değilmiş.** Veri sayfası
   kapağı: "for 10/100Base-T NIC Applications". Şemasında yalnızca **iki**
   çift sargı var (TD, RD); gigabit dört çift ister. O parçayla iki GbE
   portu 100 Mbit'e düşerdi — aletin veri borusu on kat daralır, dört
   kanal IQ akışı imkânsız olurdu. BOM'a alınıp basılsaydı kart çöpe
   gitmezdi ama Ethernet'in tamamı yeniden tasarlanırdı.
   **Yeni parça: HR911130A**, LCSC C54408, $1.58, 6005 stok.
   Hâlâ açık: 130A'nın pinout'u ve ayak izi doğrulanmadı (KiCad'de
   sadece 105A'nın ayak izi var, gövde aynı mı bilinmiyor). Bacaklar
   şemada numarayla duruyor. **HR911130A veri sayfası gerekiyor.**
   (06_ethernet)
9. **W9825G6KH pin dizilimi** JEDEC 54 bacaklı x16 SDRAM standardından
   girildi. Özellikle 40. bacak (bazı üreticilerde NC, bazılarında ikinci
   CKE) doğrulanacak. (05_sdram)
10. **VCXO Vc DAC parçası** seçilmedi. 16 bit, düşük gürültülü, SPI;
    beslemesi +3.3V_CLK. Şemada başlık olarak duruyor. (08_control)
11. **Harici 10 MHz'in doğrudan FPGA girişine bağlanması.** ECP5 girişinin
    10 MHz sinüsü (>0.5 Vpp) yakalayacağı varsayıldı, komparatör konmadı.
    Bringup'ta ölçülecek. (08_control)
12. **Harici 10 MHz girişinde DC yolu yok — DEVRE HATASI.** Çizdiğim
    ağ: SMA → 50R → 100nF seri → FPGA. Kondansatörden sonra girişin
    hiçbir DC referansı yok, bacak havada kalıyor. Üstelik DC bias
    eklense bile 3.3 V LVCMOS eşikleri (VIH ~2.0 V, VIL ~0.8 V) 0.5 Vpp
    sinüsle aşılmıyor. İki çözüm:
    - **(a) diferansiyel giriş:** sinyal P bacağına, orta-gerilim bias
      N bacağına; ECP5 diferansiyel alıcısı küçük sinyali yakalar.
      Bedeli **bir pin daha** — banka 1 zaten 32/32, yer açmak lazım.
    - **(b) komparatör:** TLV3501 / LMV7219 sınıfı, SOT-23-5, ~$1.
      Pin harcamıyor, BOM'a bir satır ekliyor.
    Seçim yapılmadan bu giriş çalışmaz. Şimdilik (b) öneriliyor:
    banka 1'de yer yok ve harici referans zaten opsiyonel bir özellik,
    bir dolarlık parça pin planını bozmaktan ucuz.

14. **ADT1-1WT+ 75 Ω'luk bir parça.** Veri sayfası kapağı: "RF
    Transformer 75Ω 0.4 to 800 MHz". Empedans oranı 1:1 olduğu için
    50 Ω sistemde de dönüşüm yapıyor, ama parça 75 Ω için
    karakterize edilmiş — 50 Ω'da dönüş kaybı bozuluyor (|Γ| = 0.2,
    ~0.18 dB uyumsuzluk kaybı). ADC girişini yüksek empedanslı ve
    49.9 Ω'la sonlandırılmış sürdüğümüz için etkisi sınırlı, ama
    **TX tarafında SMA gerçek 50 Ω yüke bakıyor**, orada daha önemli.
    Mini-Circuits'in 50 Ω 1:1 muadilleriyle (ADT1-1+, TC1-1-13M+
    sınıfı) frekans aralığı ve fiyat karşılaştırılacak. Şu anki BOM
    satırı kalıyor; değişirse aynı CD542 gövdesi kullanılabiliyorsa
    kart değişmez.

13. **CFG[2:0] kombinasyonu** — Master SPI için Lattice sysCONFIG (TN1260)
    tablosundan. Her bacakta hem yukarı hem aşağı direnç ayak izi var,
    biri doldurulacak. **Değer girilmeden kart basılmaz.** (07_fpga_power)

---

## 11. ŞEMA DURUMU (kicad/A_main)

| Sayfa | Durum | ERC |
|---|---|---|
| 01_power | tam | temiz |
| 02_clock | **boş** — ADCLK846 veri sayfası bekliyor | — |
| 03_adc | tam | temiz |
| 04_dac | tam | temiz |
| 05_sdram | tam | temiz |
| 06_ethernet | tam (magjack eşlemesi hariç) | temiz |
| 07_fpga_power | tam | temiz |
| 08_control | tam | temiz |

Projede hata (error) kalmadı. Kalan uyarılar tek tek yukarıdaki açık
maddelere karşılık geliyor: 4 ADC saat hattı (02_clock), 24 magjack
bacağı + 16 MDI (§10.8), 4 zayıflatıcı RF ucu (C kartında, kasıtlı),
VCXO_VC (§10.10).

Üretim: `cd kicad/A_main && ./build.sh` — iskeleti kurar, sekiz sayfayı
üretir, kanonikleştirir, ERC koşar. `./build.sh pdf` PDF ve SVG de çıkarır.

## 11. DRC status, board A

Clean except two categories, both understood:

| Category | Count | Status |
|---|---|---|
| `unconnected_items` | 499 | Expected — board is placed, not routed |
| `copper_edge_clearance` | 49 | **By design** — edge-mount connector pads must touch the board edge |
| everything else | 0 | Courtyard overlaps, clearance, mask bridges, shorts: none |

The 49 edge-clearance violations belong to the SMA connectors (J20-J23,
J30-J33, J61), the magjacks (J40, J41) and the interboard headers. Their
pads reach the board outline because that is what an edge-mount part is.

A `kenar_montaj` PCB group is created by `ayir.py` and `dogrudan_sdr_A.kicad_dru`
grants it `edge_clearance (min 0mm)`. KiCad applies this to the footprint
bodies but **not** to their pads — `memberOfGroup()` does not resolve a pad
to its parent footprint's group. The remaining 49 must therefore be reviewed
and excluded individually in the GUI before fabrication, or the rule rewritten
against a drawn rule area once the outline is final.

A blanket exemption was deliberately not used: it would also hide a genuine
edge violation in the middle of the board.

### Verified placement geometry

| Constraint | Result |
|---|---|
| ADCLK846 to ADC-1 / ADC-2 | 30.0 mm / 30.0 mm, delta **0.00 mm** |
| RX chain SMA to transformer, all 4 | 29.5 mm, identical |
| RX chain transformer to ADC, all 4 | 36.2 mm, identical |
| Courtyard overlaps | 0 |
| Connectors on board edge | 17 of 19 (J1 power, J10 JTAG interior by choice) |
| FPGA decoupling | back side, 2.5 mm grid under the BGA |
| Mounting holes | H1-H4, four corners, 5 mm inset |

## 12. FPGA ball assignment is derived from geometry

The sheet generators used to map bank pins to bus signals alphabetically:

    io7 = sorted(n for n, nm in B7.items() if nm.startswith("PL"))
    for p, net in zip(io7, nets7): ...

"A10, A11, A12, B2, B3..." carries no information about where a ball
physically sits. SDRAM DQ0 could land on a ball at the far side of the
package, forcing its track to cut diagonally across the whole bundle.
Every such cut costs a via, a layer change, an impedance discontinuity
and extra delay, and it makes length matching impractical.

An ECP5 user I/O is interchangeable within its bank, so this mapping is
ours to choose. `ball_atama.py` reads the placed board, projects both
ends of each bus onto the axis perpendicular to the bundle, sorts both,
and pairs them in order. A monotonic mapping cannot cross.

Two constraints are preserved: the bank never changes (same I/O voltage,
same driver delay, same temperature behaviour), and differential and
clock-capable pins are left alone.

The flow is two-pass — generate, place, compute, regenerate — and
converges in one iteration because placement coordinates come from the
floorplan, not from the netlist.

### Result, board A

| Bundle | Lines | Crossings | Mean length | Spread |
|---|---|---|---|---|
| ADC1 | 16 | 0 | 59.6 mm | 7.5 mm |
| ADC2 | 16 | 0 | 91.2 mm | 5.1 mm |
| SDRAM bank 7 | 25 | 0 | 61.3 mm | 17.7 mm |
| SDRAM bank 0 | 7 | 0 | 54.4 mm | 6.4 mm |
| DAC1 port 1 | 14 | 0 | 86.5 mm | 8.7 mm |
| DAC1 port 2 | 14 | 0 | 93.2 mm | 8.2 mm |
| DAC2 | 14 | 0 | 63.3 mm | 8.1 mm |
| PHY1 RGMII | 12 | 0 | 69.2 mm | 6.4 mm |
| PHY2 RGMII | 12 | 0 | 92.5 mm | 1.5 mm |
| **Total** | **130** | **0** | | |

Before: 116 crossings. The spread column is the meander budget for the
length-matching pass.

SDRAM is measured as two bundles because its address lines overflow into
bank 0. They are two physically separate corridors on opposite faces of
the FPGA; measuring them as one list counted them as crossing each other
when they never share a channel.

## 13. Clocks were on pins with no clock capability

Eight of the nine clock nets landed on ordinary I/O balls. Only
SD_CLK_FPGA was on a PCLK pin, and only by chance -- the ball assignment
was alphabetical, so nothing steered a clock towards a clock pin.

A clock on a general I/O does not enter the clock tree directly. It goes
through general routing, collects skew and jitter, and at 125 MHz RGMII
receive it does not close timing. This would not have shown up until
gateware bring-up, on fabricated boards.

The ECP5 pin capability table is extracted from prjtrellis-db
(`ECP5/LFE5U-25F/iodb.json`, YosysHQ, open source) into `ecp5_saat.py`
so the build needs no network. CABGA256 has 36 clock-capable balls:
PCLKT/PCLKC are primary clock inputs, GR_PCLK reach the clock tree
through general routing and are the second choice.

`ball_atama.py` now places clocks before anything else, then lets the
geometric sort fill in around them.

| Net | Was | Now | Function |
|---|---|---|---|
| ADC1_DCO | N4 | M1 | PCLKT6_0 |
| ADC2_DCO | P1 | M2 | PCLKC6_0 |
| PHY1_RXC | K12 | M16 | PCLKT3_0 |
| PHY1_TXC | M11 | L16 | PCLKT3_1 |
| PHY2_RXC | N16 | M15 | PCLKC3_0 |
| PHY2_TXC | P13 | L15 | PCLKC3_1 |
| REF10_IN | D9 | B8 | PCLKC1_0 |
| SD_CLK_FPGA | K2 | J1 | PCLKT7_1 |

GPS_1PPS is deliberately left on an ordinary pin. At 1 Hz it never
enters the clock tree; it is captured against the system clock, and
spending a PCLK on it would waste one.

Clocks are assigned as a group rather than one at a time. Assigning them
in sequence let one clock take another's pin -- PHY1_RXC moved onto
PHY2_RXC's ball and ERC reported three violations. Every (clock, pin)
pair is now ranked by distance from the clock's own peripheral pad and
handed out nearest-first, each clock and each pin used once. Ranking by
distance also matters for crossings: taking the first free PCLK
satisfied the constraint but ran ADC1's data clock through the middle of
its own bundle, crossing five data lines.

Bundle crossings went from 0 to 6 as a result, all of them in the four
bundles that carry a clock. That is the right trade -- a clock pinned to
PCLK is worth more than a via on one line -- and the other five bundles
are still at zero.

## 14. W9825G6KH pinout verified against the datasheet

Closed. The symbol was built from the JEDEC 54-pin x16 layout with a
note that pin 40 differs between vendors -- No Connect on some, a second
CKE on others -- and had to be checked before fabrication.

Checked against Winbond's own datasheet, revision A04
(<https://www.winbond.com/resource-files/w9825g6kh_a04.pdf>). All 54 pins
were extracted from the pin table and compared with the symbol
mechanically rather than by eye. Every pin matches. Pin 40 is **NC**.

The only difference the comparison reported was pin 22, where the
datasheet writes A10/AP and the symbol writes A10. Same pin; AP is the
auto-precharge role the pin takes during a read or write command.

Confirmed in passing: 15 LDQM, 16 WE, 17 CAS, 18 RAS, 19 CS, 20 BS0,
21 BS1, 35 A11, 36 A12, 37 CKE, 38 CLK, 39 UDQM, 41 VSS.

Remaining open items are the HR911130A footprint against a 1:1 print,
and the AD8318 TADJ resistor value, which needs a temperature sweep at
bring-up rather than a document.

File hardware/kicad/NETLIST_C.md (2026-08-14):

# C KARTI — RF ön uç şartnamesi

A kartı bitti (`kicad/A_main`, 264 bileşen, ERC temiz). Bu kart onun
anten tarafı: koruma, T/R, zayıflatıcı, bant filtresi bankası.

---

## 0. Neden dört özdeş zincir

Bu aletin ayırt edici özelliği dört faz-uyumlu kanal. Faz uyumu ADC'de
başlamıyor, **antende** başlıyor: dört yolun genlik ve faz cevabı aynı
değilse gürültü iptali, yön bulma ve ışın şekillendirme çalışmaz.

Bu yüzden dört RX zinciri **birebir aynı** olmak zorunda — aynı röle,
aynı filtre, aynı yol uzunluğu. "Bir kanala filtre koyalım, ötekiler
düz geçsin" kalıcı faz farkı yaratır ve kalibrasyonla tam kapanmaz
(bant kenarlarında faz eğimi frekansla değişir).

**Sonuç: ne yapılırsa dört kere yapılıyor.** Aşağıdaki adetler hep ×4.

---

## 1. Röle seçimi — KİLİTLENEN röle şart

İlk hesap kartı düşürdü:

```
normal röle, 12 V bobin, ~30 mA
dört kanal x bir aktif bant = 4 role surekli cekili
4 x 12 V x 30 mA = 1.44 W     A kartinin toplam butcesi 2.8 W
```

Sadece filtre seçimi güç bütçesinin yarısını yiyordu. Saha modunda
aküyle çalışacak bir alette kabul edilemez.

**Kilitlenen (latching) röle**: sadece anahtarlama anında akım çeker,
sonra sıfır. Bir HF filtre bankasında zaten standart çözüm.

| Parça | LCSC | Stok | Fiyat | Not |
|---|---|---|---|---|
| **G6KU-2F-Y-TR DC5** | C2153173 | 7613 | $0.84 | Omron, 2 Form C, kilitlenen, RF için (50 Ω, 3 GHz'e kadar) |
| TQ2SA-L2-5V-Z | C2684450 | 3102 | $1.88 | Panasonic, çift bobin, alternatif |
| AGQ200A12Z | C2684439 | 7454 | $0.70 | Panasonic, ucuz alternatif |

**G6KU seçildi.** G6K ailesi RF sinyal rölesi olarak zaten standart;
U harfi kilitlenen sürüm. 2 Form C, yani **tek röle bir filtre
bölümünün hem girişini hem çıkışını** anahtarlıyor.

Bobin 5 V → C kartında bir +5 V rayı gerekiyor. Kilitlenen olduğu için
akım sadece darbe süresince (~20 ms) akıyor; küçük bir buck yeter.

---

## 2. Bant planı — KARAR BEKLİYOR

Filtre bankası kartın boyunu ve maliyetini belirleyen tek şey.

| Seçenek | Bant | Röle (×4 kanal) | Filtre parçası | Röle maliyeti |
|---|---|---|---|---|
| **A** dar | 5 | 20 | ~160 | $17 |
| **B** tam | 7 | 28 | ~224 | $24 |
| **C** geniş | 9 | 36 | ~288 | $30 |

Seçenek **B** (7 pozisyon) öneriliyor:

```
1  160 m      1.8 - 2.0 MHz
2  80/60 m    3.5 - 5.4
3  40/30 m    7.0 - 10.2
4  20/17 m    14.0 - 18.2
5  15/12/10 m 21.0 - 29.7
6  6 m        50 - 54
7  BYPASS     doğrudan geçiş — VHF/UHF alt-örnekleme ve genel tarama
```

7. pozisyon şart: alet HF telsizi değil, 1–500 MHz alıcısı. Bant
filtresi bandın dışını öldürür; uydu, radiosonde ve UHF deneyleri
bypass'tan geçecek.

Maliyet farkı küçük (5 ↔ 7 arası $7 ve ~64 pasif parça). Asıl bedel
**kart alanı**: bölüm başına ~18 × 12 mm, 28 bölüm ≈ 6000 mm² sadece
filtreler. Kartı 200 × 150 mm bandına oturtuyor. 2 katman olduğu için
maliyeti düşük.

> **Bu kararı vermeden filtre çizilmez.** Bant sayısı kartın ölçüsünü,
> ölçü de kutuyu belirliyor.

---

## 3. Kanal başına zincir

```
anten SMA
  │
  ├─ gaz deşarj tüpü → toprak            yıldırım / statik
  ├─ SMBJ TVS                            hızlı geçici
  │
  T/R rölesi (G6KU)  ──TX──► TX yolu (A kartından IOUT)
  │
  RX
  │
  ├─ PIN limitleyici (BAV99 sırt sırta)  yakındaki vericiye karşı
  │
  bant filtresi bankası (7 pozisyon, G6KU ×7)
  │
  PE4312 zayıflatıcı 0-31.5 dB
  │
  A kartına (koaks kuyruk)
```

### Koruma katmanları — neden üç tane

Okul istasyonunda kendi vericimiz aynı çatıda. Üç ayrı tehdit:

1. **Yıldırım / statik** — gaz deşarj tüpü, kilovoltları toprağa
2. **Hızlı geçici** — TVS, nanosaniye mertebesinde kenetler
3. **Yakın verici** — PIN/diyot limitleyici, sürekli RF gücü sınırlar

Üçü farklı zaman ölçeğinde çalışıyor; biri diğerinin yerine geçmiyor.
Gaz tüpü yavaş (µs), TVS hızlı ama sürekli güç taşımaz, diyot
limitleyici sürekli çalışır ama kilovolt görürse ölür.

---

## 4. Zayıflatıcı — açılış durumu kritik

PE4312 ×2 A kartından buraya taşındı (RF zincirinin parçası).

> **Dört kanal için dört zayıflatıcı gerekiyor**, iki değil. Faz uyumu
> zincirlerin özdeş olmasını şart koşuyor. BOM'da iki vardı; bu şartname
> dörde çıkarıyor. Ek maliyet 2 × $1.45 = $2.90, ve A kartında iki
> kontrol hattı seti daha gerekiyor — **banka 0 dolu, yer yok.**
>
> Çözüm: dört zayıflatıcı **aynı seri hattı** paylaşsın, LE hatları
> ayrı olsun. Data+Clock ortak (2 hat) + 4 LE = 6 hat. Şu an ayrılan
> hat sayısı da 6. **A kartı değişmiyor**, sadece anlamı değişiyor.
> C kartı şeması bunu böyle bağlayacak.

Açılış durumu (veri sayfası s.6): seri modda bile C0.5–C16 bacaklarındaki
seviye belirliyor. Altısı da 10k ile yukarı → **31.5 dB**, alıcı en sağır
halinde açılıyor. Boş bırakılsa zayıflatma tanımsız olurdu.

---

## 5. Röle sürücü

28 filtre + 4 T/R = **32 kilitlenen röle**. Tek bobinli kilitlenen röle
her iki yön için de darbe ister → sürücü iki yönlü olmalı.

| Yaklaşım | Parça | Hat | Not |
|---|---|---|---|
| kaydırmalı yazmaç + sürücü | TPIC6B595 ×5 | 3 | 40 çıkış, açık drenaj, 150 mA |
| H köprü dizisi | pahalı | — | tek bobinli röleyi iki yönde sürer |

Tek bobinli G6KU için **iki TPIC6B595 seti** (biri "set", biri "reset")
ya da yarım köprü. En basit: her röleye iki açık drenaj çıkışı
(set ve reset), yani 64 çıkış → **TPIC6B595 ×8**, $0.68 × 8 = $5.44.

3 hat (SER, SRCLK, RCLK) A kartından geliyor, zaten ayrılmış.

---

## 6. Güç

```
VIN_PROT (9-18 V, A kartından)
  └─► buck ─► +5 V   role bobinleri (darbeli)
+3V3 (A kartından)   PE4312 VDD, kaydırmalı yazmaç lojik
```

Röleler kilitlenen olduğu için sürekli tüketim ~0. Darbe sırasında
32 × 100 mA olası ama **hepsi aynı anda anahtarlanmaz** — firmware
sırayla darbeler. 5 V rayı 200 mA yeterli.

---

## 7. Kart arası

A kartındaki iki başlık (`J63` 2×10, `J65` 1×6) + RF için koaks kuyruk.

| Sinyal | Adet | Nerede |
|---|---|---|
| RLY_SER, RLY_SRCLK, RLY_RCLK | 3 | J63 |
| TR1..TR4 | 4 | J63 |
| ATT_DATA, ATT_CLK (ortak) | 2 | J63/J65 |
| ATT_LE ×4 | 4 | J63/J65 |
| VIN_PROT, +3V3, GND | 3 | ikisinde de |
| RF RX ×4, RF TX ×4 | 8 | **koaks kuyruk**, başlık DEĞİL |

Dijital hatların yanında toprak var (J63'te her tek pin sinyal, çift pin
toprak) — röleler 12 V anahtarlıyor ve kenarları sert, yanındaki RF'e
kuplaj yapmasın.

---

## 8. Açık kararlar

1. **Bant sayısı** (§2). Kartın ölçüsünü belirliyor. 7 öneriliyor.
2. **Kutu.** A ve C aynı kutuya mı, ayrı mı? Layout ikisi için de
   kutudan sonra başlıyor.
3. **Filtre topolojisi ve Q.** JLCPCB'de yüksek Q'lu RF bobini yok;
   jenerik bobinle 5. derece Chebyshev'in kenar dikliği ve ekleme
   kaybı hesaplanacak. Yetmezse bobinler ayrı getirtilip elde
   lehimlenecek — kartın geri kalanı yine dizdirilebilir.
4. **UHF T/R rölesi.** G6K 3 GHz'e kadar spec'li, sorun yok. Ama
   6 m üstü için filtre bankası bypass'ta kalıyor; UHF ön seçici
   isteniyorsa ayrı bir pozisyon gerekir.
5. **Gaz deşarj tüpü parçası** seçilmedi.

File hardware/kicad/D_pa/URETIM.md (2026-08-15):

# Board D — Fabrication Notes

## Copper weight

Order board D with **2 oz (70 um) outer copper**. Do not order 1 oz.

In class A at 100 W the amplifier takes 6.67 A from the 50 V rail. On
1 oz copper, IPC-2221 asks about 4 mm of track width for that current at
a 20 C rise. A 4 mm track does not find a path on a crowded two-layer
board; the router ran for half an hour without finishing.

At 2 oz the same current at the same temperature rise needs 2.2 mm,
which routes. JLCPCB lists 2 oz outer copper as a standard option.

This is the correct choice for a 100 W amplifier for its own sake. The
copper also carries heat away from the device tabs.

## Other requirements

| Item | Value |
|---|---|
| Layers | 2 |
| Outer copper | 2 oz (70 um) |
| Thickness | 1.6 mm |
| Surface finish | ENIG |
| Minimum track | 0.25 mm |
| Minimum clearance | 0.3 mm |

The edge-mount connector pads reach the board outline. This is by
design. Do not pull them back.

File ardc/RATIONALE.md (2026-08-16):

# Technical rationale — four decisions

This document gives the four main decisions of the design and the
reason for each. The Turkish original is `docs/gerekce.md`; the longer form is
`TASARIM.md` in the repository root.

---

## 1. Why direct sampling

The predecessor of this project was a direct-conversion receiver with
a Tayloe detector. It was a good receiver, and it met three ceilings:

| Problem | With the Tayloe detector | With direct sampling |
|---|---|---|
| Instantaneous window | 96 kHz, the limit of the audio codec | **40 MHz**, all of HF at once |
| Phase noise | The noise of the local oscillator goes into the signal | **No local oscillator** |
| Transmit cleanliness | Software I/Q calibration, −25 dBc to −50 dBc | **No analogue modulator** |

When you remove the mixer you do not remove only a part. The phase
noise of the local oscillator, the intermodulation of the mixer, the
I/Q imbalance and the image frequency all go with it. Two sources of
error remain: the jitter of the sample clock, and the linearity of the
ADC. Both are measurable and both are in a datasheet. They are not
quantities that you chase with calibration.

**The cost, stated plainly:** all of HF enters the chip at the same
time. A megawatt broadcast station at 6 MHz takes the top of the ADC
while you listen at 14 MHz. This, not the number of bits, is the real
weakness of a direct-sampling receiver.

**The answer, without a compromise:** the usual answer is a
preselector, but a preselector removes the ability to see the whole
band. The AD9251 is a **dual** ADC, so the design does both:

```
main antenna -> protection -+- ADC-1A - no preselector ----> panorama and raw IQ
                            +- ADC-1B - switched bandpass -> serious receiver
```

One chip, one clock. The datasheet gives −110 dBc of crosstalk between
the channels, so the wide path does not pollute the narrow one. Board
C exists for this switched filter bank: 4 channels × 7 bands.

The band filters also do a second job that only appeared under
simulation. Above Nyquist, every signal folds onto the band, and after
the fold the receiver cannot tell it from the wanted signal. The
filters are the only protection. Two positions needed a transmission
zero for this reason; `VERIFICATION.md` records the measurement.

---

## 2. Why four channels — beam steering and noise cancelling

The second AD9251 makes four channels. All four take the same VCXO, so
they are phase-coherent. Three things start here that two separate
receivers cannot do:

**Noise cancelling.** The station is on a school campus, with
switching power supplies, LED lighting and chargers. If you sample the
noise with a separate antenna and subtract it adaptively from the main
channel, you can gain 10 dB to 20 dB in the real world.

**Direction finding.** Two antennas, a phase difference, an angle of
arrival. Radiosonde chasing, interference hunting, the direction of a
meteor trail.

**Beam forming.** Two vertical antennas give a steerable null. You can
suppress a station in a direction that you do not want.

All three depend on phase coherence, and phase coherence comes from
the common clock. This has a cost: one VCXO cannot drive two ADCs
directly, so a buffer with low additive jitter is necessary.

```
sqrt(100^2 + 50^2) = 112 fs        VCXO 100 fs + buffer 50 fs
```

From 100 fs to 112 fs, which does not matter. But the buffer must be a
part that specifies its additive jitter. If it does not, the whole
clock budget is lost.

Phase coherence is kept on the transmit side also: the four transmit
channels take the same clock, so the transmit beam can be steered.
This is why board C has four attenuators. The specification said two.
Phase coherence requires the chains to be **identical**, so you cannot
attenuate two channels and leave two.

---

## 3. Why the ECP5 (LFE5U-25F)

**A fully open toolchain.** Yosys, nextpnr-ecp5 and Project Trellis go
from source to bitstream with no vendor software. For a school club
this is not a question of licence but of continuity: when the student
graduates, the toolchain must still be possible to install, and it
must not be behind an account. The gateware in this repository is
really built with that chain.

**The variant follows from supply.** The LFE5U-45F cannot be obtained
in practice. The LFE5U-25F is available, and the `I` in `-7BG256I`
means the industrial temperature range, −40 °C to +100 °C. For a unit
that will sit on a cliff, in the sun, in a sealed box, that matters
more than the commercial grade.

**The size of the ECP5-25 set the architecture.** The naive approach,
a full-rate mixer for each of eight channels, needs 32 multipliers and
the device has 28. A two-stage DDC solves it:

```
ADC -> COMMON first decimator (CIC, no multipliers)  80 MHz -> 10 MHz
         +- channels 1..8: NCO, mixer, FIR -> 50 kHz
         |  (one multiplier set, shared in time)
         +- wide path: raw IQ output
```

The FIR load is 8 × 50 kHz × 100 taps, which is 40 M MAC/s, or about
half a multiplier at 80 MHz. The bottleneck is not the DSP count; it
is the timing closure of the full-rate CIC.

The measured use is LUT4 49 %, DSP 78 %, block RAM 21 %. There is room
in the logic and none in the multipliers, which shows that the design
was built to the multiplier budget.

**Why a BGA-256 was accepted.** The smaller packages do not give
enough I/O. Two ADCs need 28 data lines, two DACs need 31, the SDRAM
needs 39, and two gigabit PHYs need 24. With the control bus and the
board-to-board connections, the banks fill: bank 1 is at 32 of 32. A
0.8 mm pitch BGA is the limit that a 6-layer board can carry in the
standard process of the manufacturer.

---

## 4. Why a class-A power amplifier

Direct sampling uses no analogue modulator on transmit; the output of
the DAC is already clean. The only place that can spoil it is the
power amplifier. A class-AB stage makes crossover distortion and gives
back the spectral cleanliness that direct sampling won.

Class A does not make it. The cost is efficiency, about 233 W of heat
for 100 W of output, and a school station can pay it: a fixed
installation, mains power, a suitable heatsink. In exchange there is a
measurable intermodulation figure and a spectrum that needs no digital
predistortion.

What this forces onto the board: a bias servo for each device, flange
temperature measurement with a cut-off, and forward and reflected
power measurement with SWR protection. Most of the parts on board D
are this protection and feedback chain. The output stage itself is
four IRFP250N devices.

**Two consequences were measured, not assumed.**

The bias servo has a single-fault destruction path. If the measurement
arm opens, the measured current reads zero and the integrator drives
the gate to the supply rail. Simulation gives 57.6 A and 2878 W in
each device, against a continuous limit of 214 W. A gate clamp does
not solve it, because the transconductance is 8 S and 1 V above the
threshold already gives 8 A. The board detects the condition already,
but `PA_INHIBIT` removes only the driver supply, and in a class-A
stage the quiescent current does the damage. A signal that
short-circuits the integrator capacitor closes the path.

The mounting method matters more than the heatsink. The tab of the
TO-247 package is the drain, and this is a push-pull stage, so the
devices cannot go directly on a common heatsink. With an insulated
pad the device drops 55 °C inside itself at 58.3 W, and no heatsink
can correct that drop. The requirement is an AlN ceramic pad and
forced air, with a heatsink of 0.24 °C/W or better.

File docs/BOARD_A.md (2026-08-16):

# Board A — Main Board

Board A holds the converters, the FPGA, the clock and the host
interface. The board has 6 layers and it measures 235 x 225 mm.

## Layer stack

| Layer | Function |
|---|---|
| 1 | Signal, RF and high-speed |
| 2 | Ground |
| 3 | Signal |
| 4 | Power |
| 5 | Signal |
| 6 | Ground |

Layer 2 is a continuous ground plane. The plane has no split below the
ADC. A split in the ground below a converter makes the return current
go around the split. This adds inductance and it makes the noise worse.

## Receive chain

Each channel has these parts in this order:

1. SMA connector at the board edge
2. Termination resistor, 49.9 ohm
3. Transformer ADT1-1WT+, ratio 1:1
4. Two series resistors, one for each polarity
5. Differential capacitor
6. ADC input

The four chains have the same geometry. The distance from the SMA to
the transformer is 28.9 mm in all four chains. The distance from the
transformer to the ADC is 36.2 mm in all four chains.

The transformer makes the signal differential. The ADC needs a
differential input. The transformer also removes the direct current and
it isolates the antenna from the board ground.

**Note:** The ADT1-1WT+ has an impedance of 75 ohm. It is not 50 ohm.
The termination resistor corrects for this.

## Clock

The clock circuit has these parts:

| Reference | Part | Function |
|---|---|---|
| Y10 | VCXO | Makes the reference frequency |
| U15 | ADCLK846 | Divides the clock to the two ADCs |

The buffer U15 is at the same distance from each ADC. The distance is
30.0 mm to ADC 1 and 30.0 mm to ADC 2. The difference is 0.00 mm.

**Warning:** Do not move the clock buffer. A difference in the two
clock paths makes a phase error between the ADCs. You cannot calibrate
this error, because it changes with the temperature.

## FPGA banks

The peripherals are on the side of the FPGA bank that connects to them:

| Bank | Peripheral | Side of the FPGA |
|---|---|---|
| 0 | Control, SDRAM address overflow | Top |
| 1 | GPS, debug, transmit/receive control | Top |
| 2 | DAC 1 | Right, upper |
| 3 | Ethernet PHY 1 and 2 | Right, lower |
| 6 | ADC 1 and ADC 2 | Left, lower |
| 7 | SDRAM data | Left, upper |

## Ball assignment

The ball assignment is not alphabetical. A script calculates it from the
board geometry.

An ECP5 user input/output can change place with another input/output in
the same bank. Thus the assignment is a design choice. The script
projects the two ends of each bus on the axis that is at 90 degrees to
the bus. Then it sorts the two ends and it connects them in order. A
mapping in the same order cannot cross.

Result: 130 signals in 9 buses, 6 crossings. The 6 crossings are in the
four buses that contain a clock.

| Bus | Signals | Crossings | Mean length | Difference |
|---|---|---|---|---|
| ADC 1 | 16 | 0 | 59.5 mm | 7.8 mm |
| ADC 2 | 16 | 1 | 91.3 mm | 6.8 mm |
| SDRAM bank 7 | 25 | 0 | 61.3 mm | 17.7 mm |
| SDRAM bank 0 | 7 | 0 | 54.4 mm | 6.4 mm |
| DAC 1 port 1 | 14 | 0 | 86.5 mm | 8.7 mm |
| DAC 1 port 2 | 14 | 0 | 93.2 mm | 8.2 mm |
| DAC 2 | 14 | 0 | 63.3 mm | 8.0 mm |
| PHY 1 RGMII | 12 | 2 | 69.1 mm | 4.8 mm |
| PHY 2 RGMII | 12 | 3 | 92.6 mm | 1.7 mm |

The last column shows the difference between the longest signal and the
shortest signal. This is the quantity of meander that the routing must
add.

## Clock pins

Each clock connects to a clock-capable ball. The ECP5 calls these balls
PCLKT and PCLKC.

| Signal | Ball | Function of the ball |
|---|---|---|
| ADC1_DCO | M1 | PCLKT6_0 |
| ADC2_DCO | M2 | PCLKC6_0 |
| PHY1_RXC | M16 | PCLKT3_0 |
| PHY1_TXC | L16 | PCLKT3_1 |
| PHY2_RXC | M15 | PCLKC3_0 |
| PHY2_TXC | L15 | PCLKC3_1 |
| REF10_IN | B8 | PCLKC1_0 |
| SD_CLK_FPGA | J1 | PCLKT7_1 |

**Warning:** A clock on a normal input/output does not go directly into
the clock tree. It goes through the general routing and it collects
skew. The RGMII receive clock operates at 125 MHz. At this frequency
the timing does not close.

GPS_1PPS is on a normal input/output. This is correct. A signal at 1 Hz
does not go into the clock tree.

## Decoupling

Each decoupling capacitor is at the power pin that it decouples.

| Quantity | Value |
|---|---|
| Capacitors | 75 |
| Mean distance to the pin | 2.8 mm |
| Median distance | 2.7 mm |
| Maximum distance | 7.1 mm |
| Distance less than 3 mm | 52 |

The capacitors for the FPGA are on the bottom of the board. They are in
a grid with 2.5 mm between the positions. A capacitor at each ball is
not possible: the balls have 0.8 mm between them and a 0402 capacitor
needs 1.5 mm.

**Counting the capacitors is not enough.** What matters is the
impedance that the chip sees on the rail, against frequency. No
connectivity check can see this: the schematic is correct, the netlist
is correct, the design rule check is clean, and the rail still rings.

A simulation of the network found that the 1.8 V rails had no bulk
capacitor at all. The regulator loop holds the impedance low to about
100 kHz, and the ceramics hold it above about 1 MHz. Between them
there was nothing. This result does not depend on any assumption about
the transient current: a rail with no bulk capacitor is a gap whatever
you assume.

In the upper band the impedance comes from the mounting inductance
divided by the number of capacitors, not from the value of the
capacitor. So where the impedance was too high, the number changed and
not the value.

## Reset

There is no external reset and no button. A counter in the `clk_sys`
domain makes the power-on reset.

The chip has five clock domains. The reset went directly to all of
them, and a structural check found that it was the source of 44
crossings. The danger is at the release: the falling edge of the reset
is random against the edges of the other clocks, so one register
catches it and its neighbour does not, and they leave reset in
different cycles.

Each domain now has its own two-register reset synchroniser. The
synchroniser is fully synchronous, with an initial value. An
asynchronous reset was tried first, in the usual form, and all five
placement seeds then failed timing: on the ECP5 an asynchronous reset
goes to the LSR input of each flip-flop and the reset becomes a global
signal on a limited routing resource. An asynchronous assert is not
necessary here, because the FPGA sets all registers at configuration.

## Status indicators

| Reference | Color | Function |
|---|---|---|
| D60 | Green | The gateware operates and the PLL is locked |
| D61 | Blue | The receive chain makes data |
| D62 | Red | The transmitter operates |
| D63 | Yellow | Ethernet traffic |

The anode connects to +3V3. The FPGA pulls the cathode to ground. The
ECP5 input/output sinks more current than it sources. A 3.3 V bank
sinks 8 mA.

Each indicator has a 1 kilohm resistor. The current is 1.6 mA.

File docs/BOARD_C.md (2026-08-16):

# Board C — RF Board

Board C holds the band filters, the transmit/receive relays and the
attenuators. The board has 2 layers and it measures 350 x 235 mm.

**Warning:** The board carries 100 W during transmission.

## Structure

The board has four channels. Each channel has seven bands.

| Position | Content | Y coordinate |
|---|---|---|
| Channel 1 | Antenna 1 to receiver 1 | 25 mm |
| Channel 2 | Antenna 2 to receiver 2 | 80 mm |
| Channel 3 | Antenna 3 to receiver 3 | 135 mm |
| Channel 4 | Antenna 4 to receiver 4 | 190 mm |

The four channels have the same geometry. Each part is at the same
relative position in its channel. Thus the four signal paths have the
same length.

| Measurement | Value in all four channels |
|---|---|
| SMA to band 1 | 41.0 mm |
| Band 1 to band 7 | 240.0 mm |
| Band 7 to the transmit/receive relay | 26.0 mm |
| Relay to the output | 40.9 mm |

**Warning:** Do not move one channel without the other three. The
value of this board is the phase relation between the four channels.

## Signal path in one channel

Receive:

1. The antenna connects to the SMA connector at the left edge.
2. The protection circuit limits the voltage.
3. The transmit/receive relay is not energized, thus it connects the
   antenna to the receive path.
4. The band filter removes the unwanted signals.
5. The attenuator PE4312 sets the level.
6. The signal goes to board A.

Transmit:

1. The signal comes from board A.
2. The transmit/receive relay is energized, thus it connects the
   transmit path to the antenna.
3. The antenna radiates the signal.

**Note:** The transmit path does not go through the band filter of
board C. Board D contains the low-pass filter for the transmit path.

## Connectors

Each channel has one antenna connector and two connectors to board A.

| Connector | Function |
|---|---|
| J1 to J4 | Antenna 1 to 4, left edge |
| J82 to J85 | Receive output to board A, right edge |
| J86 to J89 | Transmit input from board A, right edge |
| J80, J81 | Control, bottom edge |
| J90 | Control to board D, bottom edge |

## Protection

The receive path has three protection stages. Each stage operates on a
different time scale.

| Stage | Part | Event | Time |
|---|---|---|---|
| 1 | Gas discharge tube | Lightning, static | Microseconds |
| 2 | TVS diode | Fast transient | Nanoseconds |
| 3 | Diode limiter | Nearby transmitter | Continuous |

One stage cannot replace another stage. A transmitter can be near the
antenna. Thus all three stages are necessary.

The second pole of the transmit/receive relay connects the filter
return line to ground during transmission. This protects the front end
of the adjacent channel.

## Band filters

Each position is a three-pole ladder bandpass filter. All inductors
are SMD.

**The first design passed nothing.** It used three top-coupled
resonators. Simulation showed that the peak of every band was BELOW
the band it had to pass, and the band itself was 24 dB to 41 dB down.
The receiver would have been deaf on every band.

The cause: the coupling capacitors sit in parallel with the
resonators and pull the frequency down, and the design did not
compensate. A top-coupled structure is for a narrow band. The
positions here are wide: 80 m and 60 m together need 3.5 MHz to
5.4 MHz, which is 44 % fractional bandwidth. A ladder is the correct
structure at that width.

```
F_A --+-- Ls --- Cs --+-- F_B
      |               |
    Lp||Cp          Lp||Cp
      |               |
     GND             GND
```

**No toroids.** The first ladder design used T50 toroids on the three
lowest bands, for the higher Q of 150 against 40. Two costs were
measured. Three toroids do not fit in one filter section: the
courtyard is 13.8 mm and three need 42.4 mm, and eight overlaps
appeared across four channels. And four channels × three bands ×
three inductors is 48 parts to wind by hand, which no assembly
machine can place.

With Q = 40 the worst band edge goes from 0.68 dB to 1.71 dB on
160 m. At the low end of HF the atmospheric noise sets the noise
floor, so 1 dB of noise figure has no measurable effect. The
transmit side is different: there is 100 W there, and board D does
use toroids.

**Two positions have a transmission zero.** The ADC samples at
80 MSPS, so any signal above 40 MHz folds onto the band and cannot
then be separated from the wanted signal. The band filter is the
only protection.

On 15 m to 10 m a signal at 50.3 MHz folds onto 29.7 MHz, and that
frequency is inside the 6 m band: the station's own transmitter
lands on its own receiver. A capacitor across the series inductor
gives a zero above the band.

On 6 m the interference comes from below, at 30 MHz. A series-arm
trap cannot help, because it always puts the zero above the
passband. A capacitor in series with the shunt inductor gives a zero
below the band.

**The values are chosen for tolerance, not for nominal.** The first
values maximised the nominal result. Monte Carlo analysis then
showed that only 54 % of boards would pass on 6 m, because that band
is 7.7 % wide and a ±5 % tolerance moves the resonance by about 5 %.
The filters are now designed for a band that is wider than the
necessary band, by the tolerance. The nominal rejection is lower and
99.9 % of boards pass.

`ardc/VERIFICATION.md` carries the current numbers.

## Relay control

The relay drivers are in one line at the bottom edge of the board. The
RF channels are above them.

**Note:** The pulse into a latching relay coil is some amperes. Do not
put this current next to an RF channel. The coil lines go up between the
band positions. There is 40 mm between the positions. The lines are on
an inner layer, below the ground plane.

| Reference | Part | Function |
|---|---|---|
| U60 to U66 | 74HC595 | Shift registers |
| U70 to U83 | DRV8833 | Relay drivers |
| KT1 to KT4 | G6K-2F-Y | Transmit/receive relays |

**Warning:** The transmit/receive relay is a single-side-stable type.
It is not a latching type. A latching relay keeps its position when it
has no power. If the power fails during transmission, a latching relay
keeps the antenna connected to the amplifier. Then 100 W can go into the
receiver input. A single-side-stable relay returns to the receive
position. The safe condition must come from the hardware and not from
the software.

The band relays are latching. This is correct: a band selection has no
safety function, and a latching relay uses no continuous coil power.

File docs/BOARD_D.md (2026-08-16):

# Board D — Power Amplifier

Board D increases the transmit power. The board has 2 layers and it
measures 240 x 185 mm.

**Warning:** The board operates at 50 V. The output is 100 W of radio
frequency energy. The heatsink becomes hot. Do not touch the board when
it operates.

## Power levels

The amplifier gives these output levels:

    5 W, 10 W, 25 W, 50 W, 75 W, 100 W

The amplifier operates in class A at each level. The bias current
changes with the level. The class does not change.

    Idq = Pout / (0.3 x Vcc)

| Output | Bias current | DC input |
|---|---|---|
| 5 W | 0.33 A | 17 W |
| 10 W | 0.67 A | 33 W |
| 25 W | 1.67 A | 83 W |
| 50 W | 3.33 A | 167 W |
| 75 W | 5.00 A | 250 W |
| 100 W | 6.67 A | 333 W |

**Note:** In class A the direct current does not change with the
signal. The amplifier takes the full current when there is no signal.
This is the cost of class A. The result is that the third-order
intermodulation stays low at all levels.

## Signal path

The signal goes from the left to the right. There is no return path.

| Reference | Part | Function |
|---|---|---|
| J10 | SMA | Input from board A |
| U10 | PE4312 | Digital attenuator, sets the drive level |
| U11 | PGA-103+ | Preamplifier |
| T12 | BN43-202, 2:3 | Driver output transformer |
| Q20, Q21 | IRF530N | Driver transistors |
| T10 | BN43-202, 3:1 | Final input transformer |
| Q10 to Q13 | IRFP250N | Final transistors, 4 |
| T11 | BN43-3312, 2:4 | Final output transformer |
| KL1 to KL7 | G2RL-2 | Low-pass filter selection |
| T20, T21 | FT50-43, 1:32 | Directional coupler |
| U30, U31 | AD8318 | Power detectors |
| J40 | Terminal | Antenna output |

## Thermal design

The four final transistors dissipate 233 W at 100 W of output. Each
transistor dissipates 58 W.

The four transistors are in one line at the top edge of the board. The
tab of each transistor points away from the board.

**Do not put the tabs on one common bar.** The tab of the TO-247
package is the drain, and this is a push-pull stage: the two arms have
different drain voltages. A common bar short-circuits the primary of
the output transformer. Each device needs an insulated pad.

The insulation costs temperature, and the cost is more than half of
the budget. At 58.3 W the device drops 70 °C inside itself with mica
and grease, 55 °C with an AlN ceramic pad, and 50 °C with a thick AlN
pad. No heatsink can correct that drop: even with a perfect heatsink
the junction sits that much above the heatsink surface.

The first two thermal steps see the power of ONE device. The
heatsink-to-air step sees the TOTAL power. Confusing these changes the
answer by a factor of two.

For a 40 °C ambient and a 150 °C junction limit, the heatsink must be
0.24 °C/W or better, with forced air. Natural convection cannot remove
233 W.

**Warning:** The transistors must be in one line and they must have the
same thermal path. A transistor at a different temperature has a
different bias. A difference in the bias makes the intermodulation
worse.

## Symmetry

The amplifier uses a push-pull circuit. The two arms must be equal. If
the arms are not equal, the even harmonics do not cancel.

| Measurement | Value |
|---|---|
| Driver Q20 to final Q10 | 19.5 mm |
| Driver Q20 to final Q11 | 19.5 mm |
| Driver Q21 to final Q12 | 19.5 mm |
| Driver Q21 to final Q13 | 19.5 mm |
| Arm 1 to the output transformer | 73.3 mm |
| Arm 2 to the output transformer | 73.3 mm |

## Low-pass filter bank

The bank has 7 sections. Each section has a relay and a filter. The
filter is a Chebyshev type of the 5th order with 0.1 dB of ripple.

| Section | Band | Cut-off frequency |
|---|---|---|
| 1 | 160 m | 2.2 MHz |
| 2 | 80 m | 6.0 MHz |
| 3 | 40 m | 11 MHz |
| 4 | 30 m and 20 m | 19 MHz |
| 5 | 17 m and 15 m | 31 MHz |
| 6 | 12 m and 10 m | 56 MHz |
| 7 | 6 m | Bypass |

**Warning:** Use powdered-iron cores. Do not use ferrite cores. At
100 W a ferrite core saturates. A saturated core makes harmonics. The
filter must remove harmonics, thus a ferrite core defeats the filter.

The inductors of two adjacent sections are at 90 degrees to each other.
Two inductors in the same direction have a mutual inductance. Then the
signal of one band goes into the stop band of the other band.

The relays are the G2RL-2 type. The contact rating is 8 A at 250 VAC.

**Note:** A signal relay is not sufficient. At 100 W into 50 ohm the
current is 1.4 A and the peak voltage is 100 V. A 1 A signal relay welds
at the first operation.

## Bias fault protection

Each device has its own closed-loop bias servo: a sense resistor, an
INA240A1 current amplifier, an LM358 integrator, and the gate.

The measurement arm is a single point of failure. If it opens, the
measured current reads zero, the integrator cannot close the error,
and it drives the gate to the supply rail. Simulation gives 57.6 A
and 2878 W in each device against a continuous limit of 214 W.

A gate clamp does not solve this. The transconductance is 8 S, so 1 V
above the threshold already gives 8 A, and a safe clamp voltage would
be too near the operating point.

`PA_INHIBIT` alone does not solve it either. It removes the driver
supply, and in a class-A stage the quiescent current does the damage,
not the drive.

`BIAS_KILL` short-circuits the integrator capacitor. A pull-down on
the gate is not sufficient: the integrator would stay charged at the
rail and the gate would jump when the fault cleared. With the
capacitor short-circuited the op-amp follows the set voltage and the
gate stays at 0.33 V, against a threshold of 3.2 V.

## Measurement

The directional coupler gives two samples: the forward power and the
reflected power. Each sample goes to an AD8318 logarithmic detector.

The coupler ratio is -30 dB. At 100 W the sample is 100 mW, which is
+20 dBm. An attenuator of 20 dB follows. Thus the detector receives
0 dBm at 100 W and -30 dBm at 100 mW. The full power range is inside
the input range of the detector.

The TADJ pin of each detector has a 500 ohm resistor to ground. This
resistor sets the temperature correction.

**Note:** Do not connect TADJ directly to ground. The datasheet gives
no value of 0 ohm. Without the resistor the intercept moves with the
temperature. The amplifier dissipates 233 W, thus the temperature
changes. If the power measurement moves, the protection operates at the
wrong level.

The value of 500 ohm is the recommended value at four of the six
frequencies in the datasheet table. HF is below the table. Measure the
correct value during the temperature test.

## Antenna output

The signal goes from the coupler to terminal J40. A short coaxial cable
connects J40 to an SO-239 connector on the enclosure.

**Note:** The connector is on the enclosure and not on the board. The
station cables use PL-259 connectors. An adapter at each joint makes a
loss and it makes a contact that can fail.

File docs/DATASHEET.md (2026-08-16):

# Direct-Sampling SDR Transceiver — Data Sheet

**Preliminary. No board is manufactured. Every number in this document has a
source label. Read the label before you use the number.**

Document revision A, 16 August 2026.
Project `dogrudan-sdr`, amateur radio club of TEVİTÖL, station callsign YM2X.

---

## 1. Description

The unit is a four-channel phase-coherent direct-sampling transceiver for
amateur radio. It has no mixer and no intermediate frequency. The antenna
feeds a band-pass preselector. A 14-bit analog-to-digital converter (ADC)
then samples the radio-frequency (RF) signal at 80 MSPS. The field
programmable gate array (FPGA) does all down-conversion and filtering.

Four receive channels keep a constant phase relation. This lets the user do
adaptive noise cancellation, direction finding and beam forming. A host
computer controls the unit through gigabit Ethernet.

The unit has three printed circuit boards. Board A holds the converters, the
clock, the FPGA and the Ethernet interface. Board C holds the protection, the
transmit/receive switch and the preselector. Board D holds the power
amplifier (PA).

### 1.1 Key features

| Feature | Value | Source |
|---|---|---|
| Receive coverage | 1 MHz to 500 MHz | design |
| Receive channels | 4, phase-coherent | design |
| Transmit coverage | 1.8 MHz to 30 MHz | design |
| Transmit channels | 4, phase-coherent with receive | design |
| Transmit power | 5 W to 100 W, class A | TARGET — not verified |
| ADC | 2 × AD9251, dual 14-bit, 80 MSPS | datasheet |
| DAC | 2 × AD9767, dual 14-bit | datasheet |
| FPGA | Lattice ECP5 LFE5U-25F, BGA-256 | datasheet |
| Reference clock | 80.000 MHz VCXO, GPS-disciplined | datasheet |
| Host interface | 2 × 1000BASE-T | design |
| Burst memory | 32 MB SDRAM | datasheet |

---

## 2. Absolute maximum ratings

Do not exceed these limits. The unit can fail permanently above them.

| Parameter | Symbol | Min | Max | Unit | Source |
|---|---|---|---|---|---|
| Logic supply, board A input | VIN_PROT | −0.3 | 20 | V | TPS62130 datasheet (SLVSBC3F), Table 7.1 |
| PA supply, board D input | VIN50 | −65 | 65 | V | LM74700-Q1 datasheet |
| PA supply, protected rail | +50V | 0 | 54 | V | SMBJ54A stand-off voltage |
| ADC analog supply | +1V8_A | 0 | 2.0 | V | AD9251 datasheet, Table 3 |
| ADC digital supply | +1V8_D | 0 | 2.0 | V | AD9251 datasheet, Table 3 |
| DAC analog supply | +3V3_A | −0.3 | 6.5 | V | AD9767 datasheet (Rev. C), Table 4 |
| RF input, receive port | — | — | +10 | dBm | TARGET — not verified |
| Detector RF input | — | — | +12 | dBm | AD8318 datasheet (Rev. B), Table 2, single-ended re 50 Ω |
| Operating temperature | TA | −40 | +85 | °C | industrial-grade parts, for example RTL8211FI-CG |

**Warning.** The 1.8 V rails feed the ADC. The ADC absolute maximum is 2.0 V.
A wrong regulator part number destroys both ADCs at the first power-up. The
tool `kicad/regulator_denetim.py` checks each part number against its output
rail.

---

## 3. Recommended operating conditions

| Parameter | Min | Typical | Max | Unit | Source |
|---|---|---|---|---|---|
| Logic supply (board A, XT60) | 9 | 12 | 17 | V | TPS62130 datasheet, Table 7.3 |
| Logic supply current | — | 230 | — | mA at 12 V | calculated, 2.8 W budget |
| PA supply (board D, terminal) | 45 | 50 | 54 | V | design |
| PA supply current at 100 W | — | 6.7 | — | A | calculated, class A |
| Antenna impedance | — | 50 | — | Ω | design |
| Host link | — | 1000BASE-T | — | — | design |

---

## 4. Electrical characteristics

Each row shows where the number comes from. Rows marked "TARGET — not
verified" have no measurement and no simulation. They are design goals.

### 4.1 Receive path

| Parameter | Value | Source |
|---|---|---|
| Sample rate | 80.000 MSPS | datasheet, ABLNO-V VCXO |
| ADC resolution | 14 bit | datasheet, AD9251 |
| Instantaneous bandwidth per channel | 40 MHz (first Nyquist zone) | calculated |
| Output sample rate to host | 1.25 MSPS per channel | design, `ddc_kanal.v` |
| Decimation range (CIC) | R = 1 to 2048 | design, `cic_azalt.v` |
| Sample word to host | 24 bit signed, I and Q | design, `paketleyici.v` |
| Preselector insertion loss | 0.52 dB to 1.72 dB | simulated (ngspice), `filtre_tasarim.py` |
| Preselector band-edge loss | 0.97 dB to 2.37 dB | simulated (ngspice), `filtre_tasarim.py` |
| Step attenuator range | 0 dB to 31.5 dB, 0.5 dB step | datasheet, PE4312 |
| Chain loss, antenna to ADC pin | 2.2 dB to 8.2 dB | simulated (ngspice), `zincir_sim.py` |
| In-band flatness | 0.01 dB to 1.72 dB | simulated (ngspice), `zincir_sim.py` |
| Alias rejection | 53 dB to 124 dB | simulated (ngspice), `zincir_sim.py` |
| Antenna power for ADC full scale | +3.0 dBm to +12.8 dBm | calculated from chain loss |
| Noise figure | — | TARGET — not verified |
| Dynamic range | — | TARGET — not verified |

**Alias rejection.** The ADC samples at 80 MSPS. Nyquist is 40 MHz. Any
signal above 40 MHz folds onto the band as `|f − 80|`. After the fold,
the receiver cannot tell it from the wanted signal. Digital processing
cannot remove it.

The preselector is the only protection. Two bands needed a transmission
zero to meet the 40 dB requirement:

- On 15 m to 10 m, a signal at 50.3 MHz folds onto 29.7 MHz. That
  frequency is inside the 6 m band. A capacitor across the series
  inductor gives a zero above the band. Rejection went from 24 dB to
  55 dB.
- On 6 m, a signal at 30.0 MHz folds onto 50.0 MHz. A series-arm trap
  cannot help, because it always puts the zero above the passband. A
  capacitor in series with the shunt inductor gives a zero below the
  band. Rejection went from 36 dB to 68 dB.

Inductor Q is not one number. The suppliers give Q at different
frequencies, and some give none. The chain is therefore simulated at
Q = 25, 40 and 60. All six bands meet the requirement at all three
values. Only 160 m is sensitive: the loss goes from 6.0 dB to 11.8 dB.
At 160 m the atmospheric noise sets the noise floor, so the effect is
not measurable.

### 4.2 Clock

| Parameter | Value | Source |
|---|---|---|
| VCXO frequency | 80.000 MHz | datasheet, ABLNO-V |
| VCXO jitter | 90.3 fs at 50 MHz | datasheet, ABLNO-V |
| Clock buffer additive jitter | 54 fs narrowband, 150 fs broadband | datasheet, ADCLK846 |
| SNR limit at 30 MHz, 81 fs | 96 dB | calculated |
| SNR limit at 500 MHz, 81 fs | 72 dB | calculated |
| Reference input | 10 MHz, SMA | design |

The clock jitter sets the signal-to-noise ratio (SNR) ceiling. The formula is
`SNR = −20·log₁₀(2π·f·t_jitter)`. Below 50 MHz the ADC noise floor is the
limit. Above 100 MHz the clock jitter becomes the limit.

### 4.3 Transmit path

| Parameter | Value | Source |
|---|---|---|
| DAC resolution | 14 bit | datasheet, AD9767 |
| DAC write clock | 80 MHz | design |
| DAC update rate, 4-channel mode | 40 MSPS per channel | measured, `dac_cogullu.v` |
| DAC update rate, 2-channel mode | 80 MSPS per channel | design |
| Reconstruction filter | none — see 4.3.1 | simulated, `tx_zincir_sim.py` |
| PA class | A, all stages | design |
| PA output power | 100 W | TARGET — not verified |
| PA supply current at 100 W | 6.7 A at 50 V | calculated |
| PA dissipation at 100 W | 233 W | calculated |
| Final device | 4 × IRFP250N | datasheet |
| Reverse-polarity switch loss | 0.17 W at 6.67 A | calculated, LM74700-Q1 + IRFB4110 |
| Harmonic suppression, 2nd | 58.7 dB to 83.7 dB | simulated (ngspice), `lpf_sim.py` |
| Harmonic suppression, 3rd | 76.3 dB to 98.8 dB | simulated (ngspice), `lpf_sim.py` |
| Output filter insertion loss | 0.45 dB to 1.44 dB | simulated (ngspice), `lpf_sim.py` |
| Intermodulation distortion | — | TARGET — not verified |
| Efficiency | — | TARGET — not verified |
| Drive level for 100 W | +22.4 dBm | calculated, `kazanc_butcesi.py` |
| Required heatsink | ≤ 0.24 °C/W, forced air | calculated, `termal_hesap.py` |
| Device mounting | AlN ceramic pad, insulated | required — see below |
| Temperature rise inside device | 55 °C at 58.3 W | calculated, `termal_hesap.py` |
| Driver chain maximum | +39.0 dBm | calculated, `kazanc_butcesi.py` |
| Gate swing for full output | 0.42 V peak per arm | calculated, `kazanc_butcesi.py` |
| Drain voltage swing for 100 W | 29.9 V peak (50 V supply) | calculated |
| Bias servo crossover frequency | 25.7 Hz | simulated (ngspice), `bias_sim.py` |
| Bias servo phase margin | 90° | simulated (ngspice), `bias_sim.py` |
| Bias settling time to 5% | 106 ms | simulated (ngspice), `bias_sim.py` |

**Cooling.** Class A gives the most linear operating point, but it makes
heat. At 100 W output the DC input is 333 W. The difference, 233 W, is
heat. Each device dissipates 58.3 W.

Do not mount the devices directly on the heatsink. The tab of the
TO-247 package is the drain. This is a push-pull stage, and the two arms
have different drain voltages. Direct mounting short-circuits the output
transformer primary. Use an insulated pad.

The insulation costs temperature. With an AlN ceramic pad the device
drops 55 °C internally, at 58.3 W. A heatsink cannot correct this drop.
Even with a perfect heatsink, the junction is 55 °C above the heatsink
surface.

The first two thermal steps see the power of ONE device. The
heatsink-to-air step sees the TOTAL power. Do not confuse these.

For a 40 °C ambient and a 150 °C junction limit, the heatsink must be
0.24 °C/W or better. Forced air is necessary. Natural convection cannot
remove this power.

A fan failure is a hazard. The board measures the flange temperature
with a TMP235. It reduces power at 85 °C and cuts at 100 °C. This
measures the correct quantity: not that the fan turns, but that the heat
leaves.

**Bias servo.** Each final device has its own closed-loop bias servo. A
0.01 Ω resistor senses the source current. An INA240A1 amplifies it 20
times. An LM358 integrator drives the gate. Separate servos are
necessary: paralleled MOSFETs have different threshold voltages, and
one device can take most of the current.

The loop is stable. The crossover is at 25.7 Hz and the phase margin is
90°. The bias reaches the set value in 106 ms.

The measurement arm is a single point of failure. If it opens, the
measured current reads zero. The integrator cannot then correct the
error. It drives the gate to the supply rail. Simulation gives 10.4 V
at the gate after 285 ms. That is 57.6 A and 2878 W in each device. The
continuous limit of the IRFP250N is 214 W.

A gate clamp does not solve this. The transconductance is 8 S, so 1 V
above the threshold already gives 8 A. A safe clamp voltage would be
too near the operating point.

The board detects the condition already: the FPGA compares the measured
current with the set value. But `PA_INHIBIT` removes only the driver
supply. In a class-A stage the quiescent current does the damage, not
the drive.

The fix is `BIAS_KILL`. It short-circuits the integrator capacitor. The
op-amp then follows the set voltage and the gate stays at 0.33 V. The
threshold is 3.2 V, so the device stays off. A pull-down on the gate
alone is not sufficient: the integrator would stay charged at the rail,
and the gate would jump to 10.5 V when the fault clears.

Simulation gives 0.00 A peak current after the fault with `BIAS_KILL`.

#### 4.3.1 Transmit envelope

The unit has no reconstruction filter. The DAC output goes to a
transformer and then to board D. The harmonic filter on board D is the
only filter in the transmit path.

A sampling DAC does not make one frequency. It makes the wanted
frequency and also images at `|k·fs ± fd|`. The zero-order hold gives
each image a different level. The relation is
`|H(f)| = |sin(πf/fs) / (πf/fs)|`.

This function falls slowly. If the carrier is near Nyquist, the
hold attenuates the carrier. An image at a lower frequency can then be
stronger than the carrier.

Simulation gives these limits. Use the unit only inside this envelope.

| Band | 4-channel mode (40 MSPS) | 2-channel mode (80 MSPS) |
|---|---|---|
| 160 m | yes | yes |
| 80 m | yes | yes |
| 60 m | yes | yes |
| 40 m, 30 m | yes | yes |
| 20 m, 17 m | **no** | yes |
| 15 m, 12 m, 10 m | **no** | yes |
| 6 m | **no** | **no** |

The reasons are these:

- In 4-channel mode on 20 m, the carrier is 18.2 MHz and the first
  image is 21.8 MHz. The ratio is 1.2. A filter cannot separate them.
- In 4-channel mode on 10 m, the carrier is above Nyquist. The carrier
  is itself an image. The fundamental at 10.3 MHz is 10 dB stronger.
- On 6 m, the same problem occurs in both modes. At 80 MSPS the band
  is still above Nyquist. The fundamental at 26 MHz to 30 MHz is 7 dB
  stronger than the carrier.

Receive works on all bands, 6 m included. Section 4.1 gives the
alias rejection. The limit applies only to transmit.

To transmit on 6 m, use an external transverter.

### 4.4 Gateware

| Parameter | Value | Source |
|---|---|---|
| Logic cells used | 11885 / 24288 (49 %) | measured (nextpnr), `sentez/pnr.log` |
| Flip-flops used | 11186 / 24288 (46 %) | measured (nextpnr) |
| Multipliers used | 22 / 28 (78 %) | measured (nextpnr) |
| Block RAM used | 12 / 56 (21 %) | measured (nextpnr) |
| Input/output pins used | 121 / 197 (61 %) | measured (nextpnr) |
| `clk_sys` maximum frequency | 86.57 MHz (target 80.00 MHz) | measured (nextpnr) |
| `clk_eth` maximum frequency | 134.59 MHz (target 125.00 MHz) | measured (nextpnr) |
| `rgmii_rxc` maximum frequency | 140.06 MHz (target 125.00 MHz) | measured (nextpnr) |
| ADC capture clock margin | 164.20 MHz and 168.01 MHz (target 80.00 MHz) | measured (nextpnr) |
| Placement seeds that meet timing | 4 of 5 | measured (nextpnr) |

The multiplier use is 78 %. This is the tightest resource. A fifth receive
channel does not fit in this device.

`clk_eth` was the bottleneck. The CRC32 byte step in the transmit path
was written as a bit-serial loop, and the eight steps depend on each
other, so the tool builds a long chain. Six placement seeds failed in
a row at 112 MHz to 124 MHz. The function is linear, so it was
flattened into a balanced XOR tree by a generator that extracts the
transform from the reference algorithm. The equivalence is proven in
`sim/tb_crc32.v`. Four of five seeds now meet timing.

---

## 5. Block diagram

```mermaid
flowchart LR
  ANT[4 × antenna<br/>SMA] --> C

  subgraph C["Board C — RF front end (2 layers)"]
    PROT[Gas tube +<br/>TVS + limiter] --> TR[T/R relay]
    TR --> BPF[7-band<br/>preselector]
    BPF --> ATT[PE4312<br/>0 to 31.5 dB]
  end

  ATT --> A
  subgraph A["Board A — Converter and logic (6 layers)"]
    ADC[2 × AD9251<br/>14 bit, 80 MSPS] --> FPGA
    FPGA[ECP5 LFE5U-25F<br/>4 × DDC, 4 × DUC]
    FPGA --> DAC[2 × AD9767<br/>14 bit]
    VCXO[80 MHz VCXO] --> CLK[ADCLK846<br/>fan-out]
    CLK --> ADC
    CLK --> DAC
    GPS[GPS 1PPS] --> FPGA
    FPGA <--> SDRAM[32 MB SDRAM]
    FPGA <--> PHY[2 × RTL8211F<br/>1000BASE-T]
  end

  PHY --> HOST[Host computer]
  DAC --> D
  subgraph D["Board D — Power amplifier (2 layers)"]
    DRV[Driver stages] --> FIN[4 × IRFP250N<br/>class A]
    FIN --> LPF[7-position<br/>harmonic filter]
    LPF --> CPL[Directional coupler<br/>+ 2 × AD8318]
  end
  CPL --> OUT[Antenna<br/>SO-239]
```

---

## 6. Board descriptions

### 6.1 Board A — converter and logic

Board A is the centre of the unit. It has 6 copper layers and 297 placed
footprints. The outline is 235.1 mm × 225.1 mm. The BOM has 290 components
in 79 lines. The rest are mounting holes, fiducials and test points.

The board holds these functions:

- Two AD9251 dual ADCs give four receive channels.
- Two AD9767 dual DACs give four transmit channels.
- One ECP5 LFE5U-25F FPGA does all signal processing.
- One 80 MHz VCXO and one ADCLK846 buffer make the clock.
- Two RTL8211F PHYs give two gigabit Ethernet ports.
- One 32 MB SDRAM holds burst captures.
- One power tree makes all rails from a 9 V to 17 V input.

The 6-layer stack is necessary. The FPGA is a 256-ball BGA with 0.8 mm pitch.
Escape routing from the inner ball rows needs more than two signal layers.

### 6.2 Board C — RF front end

Board C has 2 copper layers and 406 placed footprints. The BOM has 392
components in 59 lines. The outline is 350.1 mm × 235.1 mm. It is the largest board because the preselector has
4 channels × 7 band positions.

Each channel has this chain:

1. A gas discharge tube and a TVS diode protect the input.
2. A non-latching relay (G6K-2F-Y) selects transmit or receive.
3. A 7-position band filter bank selects the band.
4. A PE4312 step attenuator sets the level.

The filters are ladder band-pass sections with three resonators. All
inductors are surface-mount parts. Board C carries no wound magnetics.

The filter relays are latching (G6KU-2F-Y). A latching relay holds its
position with no coil current. This saves 1.44 W, which is half of the
board A power budget. The transmit/receive relay is not latching, on
purpose: it must fall back to receive when the power fails.

The seventh relay position is a through path with no filter. It is the
default state, and it gives wideband coverage for VHF and UHF
undersampling.

### 6.3 Board D — power amplifier

Board D has 2 copper layers and 265 placed footprints. The BOM has 243
components in 109 lines. The outline is 275.1 mm × 185.1 mm.

The amplifier is class A in every stage. Class A gives the lowest
intermodulation distortion but the worst efficiency. At 100 W output the
board dissipates about 233 W. The final stage uses four IRFP250N devices in
parallel. Four devices are necessary for the heat, not for the current.

The output filter bank has seven positions. Each position is a 5-pole
Chebyshev low-pass filter with two traps. The traps put transmission zeros on
the second and third harmonic. All output filter inductors are hand-wound
toroids. Ferrite cores must not be used here, because ferrite saturates at
100 W and then generates the harmonics that the filter must remove.

### 6.4 Board interfaces

| From | To | Connector | Signals |
|---|---|---|---|
| A | C | J63 ↔ J80, 2×10 header | +3V3, VIN_PROT, relay chain, T/R, attenuator bus |
| A | C | J65 ↔ J81, 1×6 header | attenuator latch enables 2 to 4 |
| C | A | J82…J85, SMA | four receive signals |
| A | C | J30…J33 ↔ J86…J89, SMA | four transmit signals |
| A | D | J66 ↔ J31, 2×10 header | attenuator bus, bias control, PA inhibit |
| C | D | J90 ↔ J32, 1×6 header | relay shift-register chain |
| D | C | J20, SMA | digital pre-distortion feedback |
| D | next PA | J33, 2×10 header | control bus for a second amplifier |

---

## 7. Power tree

Board A makes all logic rails. Board C and board D take their logic supply
from board A through the inter-board headers.

```
XT60 9-17 V
  |  reverse polarity: DMP3098L P-MOSFET, 12 V zener gate clamp
  |  2 A fuse, SMBJ20A TVS
  +-> VIN_PROT ---> U1  TPS62130 buck  -> +3V3   (111 pads)
  |                  |                     |
  |                  |                     +-> U2 TPS62130 buck -> +1V1  (14 pads, FPGA core)
  |                  |                     +-> U3 TPS7A2018 LDO -> +1V8  (20 pads, FPGA VCCIO)
  |                  |                     +-> U4 ADP150-1.8    -> +1V8_A (35 pads, ADC AVDD)
  |                  |                     +-> U5 ADP150-1.8    -> +1V8_D (19 pads, ADC DRVDD)
  |                  |                     +-> U8 ADP150-2.5    -> +2V5  (9 pads, FPGA VCCAUX)
  |                  |                     |     +-> U9 ADP150-1.8 -> +1V8_CLK (13 pads, ADCLK846)
  |                  |                     +-> FB6 ferrite 600R -> +3V3_CLK (5 pads, VCXO chain)
  |                  |                     +-> FB7 ferrite 600R -> +3V3_A  (9 pads, DAC AVDD)
  +-> to board C ---> U90 TPS62130 buck -> +5V   (63 pads, relay coils)
  +-> +3V3 to board C and board D

Terminal block 45-54 V (board D)
  +-> U52 LM74700-Q1 ideal diode + IRFB4110 -> +50V (10 pads, PA finals)
        +-> U50 LM5164 buck -> +12V (30 pads, drivers and relays)
              +-> U51 TPS62130 buck -> +5V (30 pads, detectors and logic)
```

Notes on the tree:

- Rail names and pad counts come from the board files. They are extracted,
  not estimated.
- `+3V3_CLK` and `+3V3_A` use ferrite beads, not regulators. A regulator
  cannot make 3.3 V from a 3.3 V input. See section 11.1.
- `+1V8_CLK` comes from `+2V5`, not from `+3V3`. This halves the dissipation
  in the TSOT-23-5 package.
- Board C and board D have no ground source. The ground comes through the
  headers.

---

## 8. Connectors

All pin lists come from the board files.

### 8.1 Board A

| Reference | Function | Type |
|---|---|---|
| J1 | 9–18 V power input | XT60 |
| J10 | FPGA JTAG | 2×3 header, 2.54 mm |
| J20…J23 | Receive inputs A1, B1, A2, B2 | SMA edge mount |
| J30…J33 | Transmit outputs TX1…TX4 | SMA edge mount |
| J40, J41 | Gigabit Ethernet | HR911130A RJ45 |
| J60 | GPS module | 1×6 header |
| J61 | 10 MHz reference | SMA edge mount |
| J62 | VCXO control DAC module | 1×6 header |
| J63 | To board C, main | 2×10 header |
| J64 | Debug UART, 3.3 V | 1×4 header |
| J65 | To board C, second | 1×6 header |
| J66 | To board D | 2×10 header |

**J63 — to board C (2×10).** Odd pins carry signals. Even pins 2 to 16 carry
the header ground.

| Pin | Net | Pin | Net |
|---|---|---|---|
| 1 | +3V3 | 11 | TR2 |
| 3 | RLY_SER | 13 | TR3 |
| 5 | RLY_SRCLK | 15 | TR4 |
| 7 | RLY_RCLK | 17 | ATT_DATA |
| 9 | TR1 | 18 | ATT_CLK |
| | | 19 | ATT1_LE |
| | | 20 | VIN_PROT |

**J66 — to board D (2×10).** Odd pins carry signals. Even pins carry the
header ground.

| Pin | Net | Pin | Net |
|---|---|---|---|
| 1 | +3V3 | 11 | BIAS_CS2 |
| 3 | ATT_DATA | 13 | PA_ADC_CS |
| 5 | ATT_CLK | 15 | PA_INHIBIT |
| 7 | PA_ATT_LE | 17 | ADC_SDIO |
| 9 | BIAS_CS1 | 19 | GND_HDR |

**J60 — GPS module (1×6).** 1 = +3V3, 2 = GPS_RX, 3 = GPS_TX,
4 = GPS_1PPS, 5 = GND, 6 = GND.

**J62 — VCXO control DAC (1×6).** 1 = +3V3_CLK, 2 = VCXO_CS, 3 = VCXO_CLK,
4 = VCXO_DIN, 5 = VCXO_VC, 6 = GND.

**J64 — debug UART (1×4).** 1 = +3V3, 2 = DBG_RX, 3 = DBG_TX, 4 = GND.

**J10 — JTAG (2×3).** 1 = TCK, 2 = TDO, 3 = TMS, 4 = +3V3, 5 = TDI, 6 = GND.

### 8.2 Board C

| Reference | Function | Type |
|---|---|---|
| J1…J4 | Antenna inputs 1 to 4 | SMA edge mount |
| J80 | To board A, main | 2×10 header |
| J81 | To board A, second | 1×6 header |
| J82…J85 | Receive outputs to board A | SMA edge mount |
| J86…J89 | Transmit inputs from board A | SMA edge mount |
| J90 | To board D | 1×6 header |

**J81 (1×6).** 1 = ATT2_LE, 2 = ATT3_LE, 3 = ATT4_LE, 4 = VIN_PROT,
5 = +3V3, 6 = GND.

**J90 (1×6).** 1 = RLY_SER_OUT, 2 = RLY_SRCLK, 3 = RLY_RCLK, 4 = +3V3,
5 = GND, 6 = GND.

### 8.3 Board D

| Reference | Function | Type |
|---|---|---|
| J10 | Drive input from board A, TX1 | SMA edge mount |
| J20 | Pre-distortion feedback to board C | SMA edge mount |
| J30 | 50 V supply input | 2-pin terminal block, 5.08 mm |
| J31 | To board A | 2×10 header |
| J32 | From board C | 1×6 header |
| J33 | To the next PA module | 2×10 header |
| J40 | Antenna output to the SO-239 panel jack | 2-pin terminal block |

**J30.** 1 = VIN50, 2 = GND. **J40.** 1 = ANT_OUT, 2 = GND.

**J33 — to the next PA (2×10).** 1 = +3V3, 3 = ATT_DATA, 5 = ATT_CLK,
7 = ADC_SDIO, 9 = RLY_SER_NEXT, 11 = RLY_SRCLK, 13 = RLY_RCLK,
15 = PA_INHIBIT. All even pins are ground.

---

## 9. Filter performance

This is the strongest part of the document. Every number below comes from an
ngspice AC analysis of the exact component values in the schematic. The
inductor Q is included. Run the tools to reproduce the numbers.

### 9.1 Receive preselector, board C

Topology: three-resonator ladder band-pass, 3-pole Chebyshev, 0.1 dB ripple.
Inductor Q = 40 (surface-mount). Component values are E12, because E12 is
stocked everywhere. The simulation uses the same E12 values as the
schematic.

Tool: `kicad/filtre_tasarim.py`.

| Position | Centre (MHz) | Fractional BW | Insertion loss (dB) | Band-edge loss (dB) | 2nd-harmonic rejection (dB) |
|---|---|---|---|---|---|
| 160 m | 1.90 | 0.26 | 1.31 | 1.71 | 41.7 |
| 80/60 m | 4.33 | 0.59 | 0.52 | 0.97 | 21.7 |
| 40/30 m | 8.43 | 0.53 | 0.73 | 1.49 | 26.6 |
| 20/17 m | 15.95 | 0.42 | 0.83 | 1.04 | 28.6 |
| 15/10 m | 24.97 | 0.51 | 0.71 | 1.00 | 22.2 |
| 6 m | 51.96 | 0.23 | 1.72 | 2.37 | 45.1 |

Each of the four channels has its own copy of these six sections. A seventh
relay position gives the through path.
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

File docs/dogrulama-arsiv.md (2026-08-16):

> **ARSIV — 15 Agustos 2026 anlik goruntusu.**
>
> Bu belge ARDC paketinden CIKARILDI ve arsiv olarak burada duruyor.
> Icindeki sayilar yazildigi andaki tasarima ait ve o tarihten sonra
> iki ayri yeniden tasarim oldu (katlanma bastirmasi ve tolerans
> merkezleme), ustune formal dogrulama ve CDC duzeltmeleri geldi.
>
> GUNCEL DOGRULAMA KANITI: `ardc/VERIFICATION.md`. O dosya elle
> yazilmiyor — `ardc/topla.py` araclari kosturup ciktilarini yakalayarak
> uretiyor, yani eskiyemez. Bu belgenin eskimesi de zaten o araci
> yazmanin sebebi oldu.
>
> Burada tutulmasinin sebebi: hangi hatanin NASIL bulundugunu anlatiyor
> ve o anlatim hala degerli.
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

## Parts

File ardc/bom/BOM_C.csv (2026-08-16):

Comment | Designator | Footprint | LCSC
0R | R107,R108,R116,R117,R125,R126,R134,R135,R607,R608,R612,R613,R617,R618,R622,R623,R627,R628,R632,R633,R637,R638,R642,R643,R647,R648,R652,R653,R657,R658,R662,R663,R667,R668,R672,R673,R677,R678,R682,R683,R90 | Resistor_SMD:R_0603_1608Metric | C21189
1.5uH | L1022,L1061,L1100,L1139 | Inductor_SMD:L_1210_3225Metric | BASE
100k | R104,R113,R122,R131 | Resistor_SMD:R_0603_1608Metric | C25741
100nF | C407,C408,C416,C417,C425,C426,C434,C435 | Capacitor_SMD:C_0402_1005Metric | C1525
100nF | C600,C601,C602,C603,C604,C605,C606,C611,C616,C621,C626,C631,C636,C641,C646,C651,C656,C661,C666,C671,C676,C681,C686,C82,C84 | Capacitor_SMD:C_0603_1608Metric | C1525
105k | R80 | Resistor_SMD:R_0603_1608Metric | C25081
10k | R400,R401,R402,R403,R404,R405,R406,R409,R410,R411,R412,R413,R414,R415,R418,R419,R420,R421,R422,R423,R424,R427,R428,R429,R430,R431,R432,R433,R690 | Resistor_SMD:R_0603_1608Metric | C25744
10nF | C609,C614,C619,C624,C629,C634,C639,C644,C649,C654,C659,C664,C669,C674,C679,C684 | Capacitor_SMD:C_0603_1608Metric | BASE
10uF | C83 | Capacitor_SMD:C_1206_3216Metric | C15850
1200pF | C1007,C1009,C1032,C1035,C1046,C1048,C1071,C1074,C1085,C1087,C1110,C1113,C1124,C1126,C1149,C1152 | Capacitor_SMD:C_0603_1608Metric | BASE
12pF | C1038,C1077,C1116,C1155 | Capacitor_SMD:C_0603_1608Metric | BASE
180pF | C1017,C1056,C1095,C1134 | Capacitor_SMD:C_0603_1608Metric | BASE
18uH | L1004,L1043,L1082,L1121 | Inductor_SMD:L_1210_3225Metric | BASE
1N4148WS | D102,D105,D106,D111,D114,D115,D120,D123,D124,D129,D132,D133 | Diode_SMD:D_SOD-323 | C129905
1k | R103,R112,R121,R130 | Resistor_SMD:R_0603_1608Metric | C21190
1uH | L1000,L1002,L1006,L1008,L1039,L1041,L1045,L1047,L1078,L1080,L1084,L1086,L1117,L1119,L1123,L1125 | Inductor_SMD:L_1210_3225Metric | BASE
2.2uF | C610,C615,C620,C625,C630,C635,C640,C645,C650,C655,C660,C665,C670,C675,C680,C685 | Capacitor_SMD:C_0603_1608Metric | BASE
2.2uH | L1016,L1055,L1094,L1133 | Inductor_SMD:L_1210_3225Metric | C1017
2.2uH | L80 | Inductor_SMD:L_Taiyo-Yuden_NR-30xx | C1017
20k | R81 | Resistor_SMD:R_0603_1608Metric | C25765
220nH | L1018,L1020,L1057,L1059,L1096,L1098,L1135,L1137 | Inductor_SMD:L_0603_1608Metric | BASE
22pF | C1030,C1069,C1108,C1147 | Capacitor_SMD:C_0603_1608Metric | C1554
22uF | C80,C81 | Capacitor_SMD:C_0603_1608Metric | C45783
2N7002 | QT1,QT2,QT3,QT4 | Package_TO_SOT_SMD:SOT-23 | C8545
3.3uH | L1010,L1049,L1088,L1127 | Inductor_SMD:L_1210_3225Metric | BASE
33nH | L1031,L1034,L1070,L1073,L1109,L1112,L1148,L1151 | Inductor_SMD:L_0603_1608Metric | BASE
390nH | L1028,L1067,L1106,L1145 | Inductor_SMD:L_0805_2012Metric | BASE
390pF | C1005,C1011,C1033,C1036,C1044,C1050,C1072,C1075,C1083,C1089,C1111,C1114,C1122,C1128,C1150,C1153 | Capacitor_SMD:C_0603_1608Metric | BASE
470nH | L1012,L1014,L1051,L1053,L1090,L1092,L1129,L1131 | Inductor_SMD:L_0805_2012Metric | BASE
470pF | C1019,C1021,C1058,C1060,C1097,C1099,C1136,C1138 | Capacitor_SMD:C_0603_1608Metric | BASE
560pF | C1025,C1027,C1064,C1066,C1103,C1105,C1142,C1144 | Capacitor_SMD:C_0603_1608Metric | BASE
6800pF | C1001,C1003,C1040,C1042,C1079,C1081,C1118,C1120 | Capacitor_SMD:C_0603_1608Metric | BASE
680pF | C1013,C1015,C1052,C1054,C1091,C1093,C1130,C1132 | Capacitor_SMD:C_0603_1608Metric | BASE
68nH | L1024,L1026,L1063,L1065,L1102,L1104,L1141,L1143 | Inductor_SMD:L_0603_1608Metric | BASE
68pF | C1023,C1062,C1101,C1140 | Capacitor_SMD:C_0603_1608Metric | BASE
74HC595D | U60,U61,U62,U63,U64,U65,U66 | Package_SO:SOIC-16_3.9x9.9mm_P1.27mm | C5947
820nH | L1037,L1076,L1115,L1154 | Inductor_SMD:L_1210_3225Metric | BASE
82pF | C1029,C1068,C1107,C1146 | Capacitor_SMD:C_0603_1608Metric | BASE
A kartina | J80 | Connector_PinHeader_2.54mm:PinHeader_2x10_P2.54mm_Vertical | EL
A kartina #2 | J81 | Connector_PinHeader_2.54mm:PinHeader_1x06_P2.54mm_Vertical | EL
D kartina | J90 | Connector_PinHeader_2.54mm:PinHeader_1x06_P2.54mm_Vertical | EL
DRV8833PWPR | U70,U71,U72,U73,U74,U75,U76,U77,U78,U79,U80,U81,U82,U83,U84,U85 | Package_SO:HTSSOP-16-1EP_4.4x5mm_P0.65mm_EP3.4x5mm_Mask2.46x2.31mm_ThermalVias | C53055901
G6K-2F-Y | KT1,KT2,KT3,KT4 | Relay_SMD:Relay_DPDT_Omron_G6K-2F-Y | C80087
G6KU-2F-Y | K11,K12,K13,K14,K15,K16,K17,K21,K22,K23,K24,K25,K26,K27,K31,K32,K33,K34,K35,K36,K37,K41,K42,K43,K44,K45,K46,K47 | Relay_SMD:Relay_DPDT_Omron_G6K-2F-Y | C2153173
GDT 90V | E100,E109,E118,E127 | dogrudan-sdr:GDT_Disc_D12mm_W3.9mm_P7.5mm | C2909520
PE4312C-Z | U40,U41,U42,U43 | Package_DFN_QFN:TQFN-20-1EP_4x4mm_P0.5mm_EP2.1x2.1mm | C500480
RX1 -> A | J82 | Connector_Coaxial:SMA_Amphenol_132289_EdgeMount | C496550
RX2 -> A | J83 | Connector_Coaxial:SMA_Amphenol_132289_EdgeMount | C496550
RX3 -> A | J84 | Connector_Coaxial:SMA_Amphenol_132289_EdgeMount | C496550
RX4 -> A | J85 | Connector_Coaxial:SMA_Amphenol_132289_EdgeMount | C496550
SMA anten 1 | J1 | Connector_Coaxial:SMA_Amphenol_132289_EdgeMount | C496550
SMA anten 2 | J2 | Connector_Coaxial:SMA_Amphenol_132289_EdgeMount | C496550
SMA anten 3 | J3 | Connector_Coaxial:SMA_Amphenol_132289_EdgeMount | C496550
SMA anten 4 | J4 | Connector_Coaxial:SMA_Amphenol_132289_EdgeMount | C496550
SMBJ20A | D101,D110,D119,D128 | Diode_SMD:D_SMB | C364296
TPS62130 | U90 | Package_DFN_QFN:VQFN-16-1EP_3x3mm_P0.5mm_EP1.68x1.68mm | C337502
TX1 <- A | J86 | Connector_Coaxial:SMA_Amphenol_132289_EdgeMount | C496550
TX2 <- A | J87 | Connector_Coaxial:SMA_Amphenol_132289_EdgeMount | C496550
TX3 <- A | J88 | Connector_Coaxial:SMA_Amphenol_132289_EdgeMount | C496550
TX4 <- A | J89 | Connector_Coaxial:SMA_Amphenol_132289_EdgeMount | C496550

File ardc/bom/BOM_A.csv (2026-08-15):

Comment | Designator | Footprint | LCSC
0R | R450,R691,R692,R801 | Resistor_SMD:R_0603_1608Metric | C21189
1.5k | R690 | Resistor_SMD:R_0603_1608Metric | C4310
1.92k 1% | R401,R402,R404,R405 | Resistor_SMD:R_0603_1608Metric | C23025
100R | R207,R209,R211,R220,R221,R222,R230 | Resistor_SMD:R_0603_1608Metric | C25076
100k | R1,R2,R3 | Resistor_SMD:R_0603_1608Metric | C25741
100nF | C200,C201,C202,C203,C204,C205,C206,C207,C208,C209,C210,C211,C212,C213,C220,C221,C222,C223,C224,C225,C226,C227,C228,C240,C241,C242,C243,C244,C245,C246,C247,C400,C401,C402,C403,C404,C405,C406,C407,C408,C409,C410,C411,C412,C413,C414,C415,C420,C421,C422,C423,C424,C425,C426,C427,C460,C461,C470,C471,C472,C473,C700,C701,C702,C703,C704,C705,C706,C707,C720,C721,C722,C723,C724,C725,C726,C727 | Capacitor_SMD:C_0402_1005Metric | C1525
100nF | C19,C200,C202,C203,C204,C205,C208,C21,C210,C211,C212,C318,C321,C4,C400,C403,C500,C501,C502,C503,C504,C505,C6,C900,C901,C902 | Capacitor_SMD:C_0603_1608Metric | C1525
100nF 2kV | C615,C631 | Capacitor_SMD:C_0603_1608Metric | C336276
10k | R20,R21,R36,R37,R38,R5,R609,R625,R901,R902,R903,R904 | Resistor_SMD:R_0603_1608Metric | C25744
10k 1% | R317,R320 | Resistor_SMD:R_0603_1608Metric | C25744
10uF | C430,C431,C480,C481 | Capacitor_SMD:C_0402_1005Metric | C15850
10uF | C101,C102,C103,C105,C107,C108,C18,C20,C201,C206,C506 | Capacitor_SMD:C_0603_1608Metric | C15850
10uF | C5 | Capacitor_SMD:C_0805_2012Metric | C15850
10uF | C3 | Capacitor_SMD:C_1206_3216Metric | C15850
10uF X5R | C607,C623 | Capacitor_SMD:C_0603_1608Metric | C15850
12V | D2 | Diode_SMD:D_SOD-323 | C8062
18pF | C611,C612,C627,C628 | Capacitor_SMD:C_0603_1608Metric | C1584
1k | R212,R213,R39,R60,R600,R601,R602,R603,R604,R605,R61,R616,R617,R618,R619,R62,R620,R621,R63 | Resistor_SMD:R_0603_1608Metric | C21190
1uF | C10,C11,C12,C13,C14,C15,C16,C17,C22,C23,C316,C319 | Capacitor_SMD:C_0603_1608Metric | C52923
2.2k 1% | R608,R624 | Resistor_SMD:R_0603_1608Metric | C4190
2.2uH | L1,L2 | Inductor_SMD:L_Taiyo-Yuden_NR-30xx | C1017
220R | R210 | Resistor_SMD:R_0603_1608Metric | C25091
22R | R550 | Resistor_SMD:R_0603_1608Metric | C25092
22pF | C303,C307,C311,C315 | Capacitor_SMD:C_0603_1608Metric | C1554
22uF | C1,C2 | Capacitor_SMD:C_0603_1608Metric | C45783
22uF | C106 | Capacitor_SMD:C_1206_3216Metric | C45783
25MHz CL12pF | Y610,Y626 | Crystal:Crystal_SMD_3225-4Pin_3.2x2.5mm | C9006
26.7k | R6 | Resistor_SMD:R_0603_1608Metric | C25765
2A | F1 | Fuse:Fuse_1206_3216Metric | C371166
32k | R4 | Resistor_SMD:R_0603_1608Metric | C25768
330R | R613,R614,R629,R630 | Resistor_SMD:R_0603_1608Metric | C25104
33R 1% | R301,R302,R305,R306,R309,R310,R313,R314 | Resistor_SMD:R_0603_1608Metric | C25105
4.7k | R32 | Resistor_SMD:R_0603_1608Metric | C23162
4.7uH | L606,L622 | Inductor_SMD:L_0805_2012Metric | C1018
470R | R31,R35 | Resistor_SMD:R_0603_1608Metric | C23179
47uF | C100,C104 | Capacitor_SMD:C_1206_3216Metric | C46653
49.9R 1% | R300,R304,R308,R312 | Resistor_SMD:R_0603_1608Metric | C25107
50R 1% | R406,R407,R408,R409,R410,R411,R412,R413,R900 | Resistor_SMD:R_0603_1608Metric | C22775
ABLNO-V-80.000MHZ | Y10 | dogrudan-sdr:Oscillator_Abracon_ABLNO_4pad_14.3x8.7mm | C5378891
AD9251BCPZ-80 | U20,U21 | Package_DFN_QFN:QFN-64-1EP_9x9mm_P0.5mm_EP4.7x4.7mm | C653380
AD9767ASTZ | U30,U31 | Package_QFP:LQFP-48_7x7mm_P0.5mm | C653820
ADCLK846BCPZ | U15 | Package_DFN_QFN:HVQFN-24-1EP_4x4mm_P0.5mm_EP2.5x2.5mm | C578957
ADP150-1.8 | U4,U5,U9 | Package_TO_SOT_SMD:TSOT-23-5 | C141959
ADP150-2.5 | U8 | Package_TO_SOT_SMD:TSOT-23-5 | C144257
ADT1-1WT+ | T1,T10,T11,T12,T13,T2,T3,T4 | RF_Mini-Circuits:Mini-Circuits_CD542_H2.84mm | C6835853
C kartina | J63 | Connector_PinHeader_2.54mm:PinHeader_2x10_P2.54mm_Vertical | EL
C kartina #2 | J65 | Connector_PinHeader_2.54mm:PinHeader_1x06_P2.54mm_Vertical | EL
D kartina | J66 | Connector_PinHeader_2.54mm:PinHeader_2x10_P2.54mm_Vertical | EL
DAC modul | J62 | Connector_PinHeader_2.54mm:PinHeader_1x06_P2.54mm_Vertical | EL
DMP3098L | Q1 | Package_TO_SOT_SMD:SOT-23 | C155039
GPS modul | J60 | Connector_PinHeader_2.54mm:PinHeader_1x06_P2.54mm_Vertical | EL
HR911130A | J40,J41 | dogrudan-sdr:RJ45_Hanrun_HR911130A | C54408
JTAG 2x3 | J10 | Connector_PinHeader_2.54mm:PinHeader_2x03_P2.54mm_Vertical | EL
LFE5U-25F-7BG256I | U10 | Package_BGA:BGA-256_14.0x14.0mm_Layout16x16_P0.8mm_Ball0.45mm_Pad0.32mm_NSMD | C1550762
PROG | SW1 | Button_Switch_SMD:SW_SPST_TL3342 | C318884
RTL8211FI-CG | U40,U41 | Package_DFN_QFN:QFN-40-1EP_5x5mm_P0.4mm_EP3.6x3.6mm | C717681
SMA 10MHz ref | J61 | Connector_Coaxial:SMA_Amphenol_132289_EdgeMount | C496550
SMA A1 | J20 | Connector_Coaxial:SMA_Amphenol_132289_EdgeMount | C496550
SMA A2 | J22 | Connector_Coaxial:SMA_Amphenol_132289_EdgeMount | C496550
SMA B1 | J21 | Connector_Coaxial:SMA_Amphenol_132289_EdgeMount | C496550
SMA B2 | J23 | Connector_Coaxial:SMA_Amphenol_132289_EdgeMount | C496550
SMA TX1 | J30 | Connector_Coaxial:SMA_Amphenol_132289_EdgeMount | C496550
SMA TX2 | J31 | Connector_Coaxial:SMA_Amphenol_132289_EdgeMount | C496550
SMA TX3 | J32 | Connector_Coaxial:SMA_Amphenol_132289_EdgeMount | C496550
SMA TX4 | J33 | Connector_Coaxial:SMA_Amphenol_132289_EdgeMount | C496550
SMBJ20A | D1 | Diode_SMD:D_SMB | C364296
SN65LVDS2DBVR | U16,U17,U18 | Package_TO_SOT_SMD:SOT-23-5 | C38204
TLV3501AIDBVR | U62 | Package_TO_SOT_SMD:SOT-23-6 | C193413
TPS62130 | U1,U2 | Package_DFN_QFN:VQFN-16-1EP_3x3mm_P0.5mm_EP1.68x1.68mm | C337502
TPS7A2018 | U3 | Package_TO_SOT_SMD:SOT-23-5 | C963430
UART 3.3V | J64 | Connector_PinHeader_2.54mm:PinHeader_1x04_P2.54mm_Vertical | EL
W25Q128JVSIQ | U11 | Package_SO:SOIC-8_5.3x5.3mm_P1.27mm | C97521
W9825G6KH-6I | U50 | Package_SO:TSOP-II-54_22.2x10.16mm_P0.8mm | C97572
XT60 | J1 | Connector_Wire:SolderWire-1.5sqmm_1x02_P6mm_D1.7mm_OD3mm_Relief | C98732
ferrit 600R | FB10,FB6,FB7 | Inductor_SMD:L_0603_1608Metric | C1015
kirmizi | D62 | LED_SMD:LED_0805_2012Metric | C84256
mavi | D61 | LED_SMD:LED_0805_2012Metric | C2293
sari | D63 | LED_SMD:LED_0805_2012Metric | C2296
yesil | D10 | LED_SMD:LED_0603_1608Metric | C72043
yesil | D60 | LED_SMD:LED_0805_2012Metric | C72043

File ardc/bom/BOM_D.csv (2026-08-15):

Comment | Designator | Footprint | LCSC
0.01R 2W | RS1,RS2,RS3,RS4 | Resistor_SMD:R_2512_6332Metric | C2907226
0R | R500,R501,R690 | Resistor_SMD:R_0603_1608Metric | C21189
1.1pF | C560 | Capacitor_SMD:C_0603_1608Metric | BASE
1.6pF | C534 | Capacitor_SMD:C_0603_1608Metric | BASE
1000pF | C522 | Capacitor_THT:C_Disc_D7.5mm_W5.0mm_P5.00mm | BASE
100R | R304,R308,R312,R316 | Resistor_SMD:R_0603_1608Metric | C25076
100k | R601,R606,R608 | Resistor_SMD:R_0603_1608Metric | C25741
100nF | C10,C11,C110,C111,C12,C230,C231,C232,C233,C300,C301,C407,C408,C409,C413,C414,C415,C441,C442,C443,C444,C460,C461,C600,C609,C617,C651,C660,C665,C667,C690 | Capacitor_SMD:C_0603_1608Metric | C1525
100nF | C662 | Capacitor_SMD:C_0805_2012Metric | C1525
100nF | C202 | Capacitor_SMD:C_1206_3216Metric | C1525
105k | R604 | Resistor_SMD:R_0603_1608Metric | C25081
10R | R106,R108,R240,R241,R242,R243 | Resistor_SMD:R_0603_1608Metric | C25190
10k | R100,R101,R102,R103,R104,R105,R107,R109,R302,R305,R306,R309,R310,R313,R314,R317,R470,R603,R99 | Resistor_SMD:R_0603_1608Metric | C25744
10uF | C204,C650 | Capacitor_SMD:C_1206_3216Metric | C15850
10uH bogucu | L11 | Inductor_SMD:L_0805_2012Metric | C1019
10uH bogucu | L20 | dogrudan-sdr:L_Toroid_T50_Vertical | C1019
110pF | C561 | Capacitor_THT:C_Disc_D7.5mm_W5.0mm_P5.00mm | BASE
120pF | C520 | Capacitor_THT:C_Disc_D7.5mm_W5.0mm_P5.00mm | BASE
13pF | C559 | Capacitor_THT:C_Disc_D7.5mm_W5.0mm_P5.00mm | BASE
140k | R602 | Resistor_SMD:R_0603_1608Metric | C25742
1500pF | C513 | Capacitor_THT:C_Disc_D7.5mm_W5.0mm_P5.00mm | BASE
150pF | C529 | Capacitor_THT:C_Disc_D7.5mm_W5.0mm_P5.00mm | BASE
15pF | C512,C556 | Capacitor_SMD:C_0603_1608Metric | BASE
15pF | C555 | Capacitor_THT:C_Disc_D7.5mm_W5.0mm_P5.00mm | BASE
1600pF | C500,C508 | Capacitor_THT:C_Disc_D7.5mm_W5.0mm_P5.00mm | BASE
160pF | C536,C544,C549 | Capacitor_THT:C_Disc_D7.5mm_W5.0mm_P5.00mm | BASE
180pF | C506 | Capacitor_THT:C_Disc_D7.5mm_W5.0mm_P5.00mm | BASE
18pF | C551 | Capacitor_THT:C_Disc_D7.5mm_W5.0mm_P5.00mm | C1584
19R1 | R404,R410 | Resistor_SMD:R_0603_1608Metric | C400656
1N4148WS | D607,D610,D611,D612,D613,D614,D615,D616 | Diode_SMD:D_SOD-323 | C129905
1R | R200,R201 | Resistor_SMD:R_2512_6332Metric | C22859
1k | R244,R245,R246,R247 | Resistor_SMD:R_0603_1608Metric | C21190
1nF | C401,C403 | Capacitor_SMD:C_0603_1608Metric | BASE
1nF | C206,C208 | Capacitor_SMD:C_1206_3216Metric | BASE
1uF | C303,C307,C311,C315 | Capacitor_SMD:C_0603_1608Metric | C52923
1uF | C203 | Capacitor_SMD:C_1206_3216Metric | C52923
1uH bogucu | L10 | Inductor_SMD:L_0805_2012Metric | C1016
2.2uF | C663 | Capacitor_SMD:C_1210_3225Metric | BASE
2.2uH | L51 | Inductor_SMD:L_Taiyo-Yuden_NR-30xx | C1017
200pF | C511 | Capacitor_THT:C_Disc_D7.5mm_W5.0mm_P5.00mm | BASE
20k | R605 | Resistor_SMD:R_0603_1608Metric | C25765
220pF | C406,C412 | Capacitor_SMD:C_0603_1608Metric | BASE
22nF | C661 | Capacitor_SMD:C_0805_2012Metric | BASE
22pF | C530 | Capacitor_SMD:C_0603_1608Metric | C1554
22uF | C666 | Capacitor_SMD:C_0603_1608Metric | C45783
22uF | C664 | Capacitor_SMD:C_1206_3216Metric | C45783
247R | R405,R411 | Resistor_SMD:R_0603_1608Metric | C25100
24pF | C542 | Capacitor_THT:C_Disc_D7.5mm_W5.0mm_P5.00mm | BASE
2700pF | C504 | Capacitor_THT:C_Disc_D7.5mm_W5.0mm_P5.00mm | BASE
270pF | C527,C535,C540 | Capacitor_THT:C_Disc_D7.5mm_W5.0mm_P5.00mm | BASE
2N7002 | Q31,Q32,Q40,QK1,QK2,QK3,QK4,QL1,QL2,QL3,QL4,QL5,QL6,QL7 | Package_TO_SOT_SMD:SOT-23 | C8545
3.3pF | C563 | Capacitor_THT:C_Disc_D7.5mm_W5.0mm_P5.00mm | BASE
3.9pF | C525 | Capacitor_SMD:C_0603_1608Metric | BASE
360pF | C502 | Capacitor_THT:C_Disc_D7.5mm_W5.0mm_P5.00mm | BASE
3pF | C521,C564 | Capacitor_SMD:C_0603_1608Metric | BASE
4.7pF | C507,C516 | Capacitor_SMD:C_0603_1608Metric | BASE
430pF | C531 | Capacitor_THT:C_Disc_D7.5mm_W5.0mm_P5.00mm | BASE
470uF | C601,C602 | Capacitor_THT:CP_Radial_D16.0mm_P7.50mm | BASE
47pF | C547 | Capacitor_THT:C_Disc_D7.5mm_W5.0mm_P5.00mm | BASE
47uH | L50 | Inductor_SMD:L_Taiyo-Yuden_NR-30xx | C1020
5.6pF | C552 | Capacitor_SMD:C_0603_1608Metric | BASE
500R | R160,R161 | Resistor_SMD:R_0603_1608Metric | BASE
50V giris | J30 | TerminalBlock_CUI:TerminalBlock_CUI_TB007-508-02_1x02_P5.08mm_Horizontal | C395880
51R | R416 | Resistor_SMD:R_0603_1608Metric | BASE
51R 1% | R400,R402 | Resistor_SMD:R_2512_6332Metric | C22790
51pF | C524 | Capacitor_THT:C_Disc_D7.5mm_W5.0mm_P5.00mm | BASE
560pF | C518,C526 | Capacitor_THT:C_Disc_D7.5mm_W5.0mm_P5.00mm | BASE
56R 1W | R10 | Resistor_SMD:R_2512_6332Metric | C22787
56pF | C503 | Capacitor_SMD:C_0603_1608Metric | BASE
6.2pF | C548 | Capacitor_SMD:C_0603_1608Metric | BASE
6.8pF | C539,C543 | Capacitor_SMD:C_0603_1608Metric | BASE
62pF | C538,C557,C565 | Capacitor_THT:C_Disc_D7.5mm_W5.0mm_P5.00mm | BASE
74HC595D | U56 | Package_SO:SOIC-16_3.9x9.9mm_P1.27mm | C5947
75pF | C533 | Capacitor_THT:C_Disc_D7.5mm_W5.0mm_P5.00mm | BASE
820R | R205,R207 | Resistor_SMD:R_2512_6332Metric | C23253
820pF | C509,C517 | Capacitor_THT:C_Disc_D7.5mm_W5.0mm_P5.00mm | BASE
91pF | C515,C545,C553 | Capacitor_THT:C_Disc_D7.5mm_W5.0mm_P5.00mm | BASE
A kartina | J31 | Connector_PinHeader_2.54mm:PinHeader_2x10_P2.54mm_Vertical | EL
A kartindan TX1 | J10 | Connector_Coaxial:SMA_Amphenol_132289_EdgeMount | C496550
AD8318ACPZ | U60,U61 | Package_DFN_QFN:NXP_VQFN-16-1EP_4x4mm_P0.65mm_EP2.1x2.1mm | C578694
ANTEN -> panel SO-239 | J40 | TerminalBlock_Altech:Altech_AK100_1x02_P5.00mm | EL
BN43-202 2:1 | T10 | dogrudan-sdr:XFMR_Toroid_4P_Vertical | EL
BN43-202 2:3 CT | T12 | dogrudan-sdr:XFMR_Toroid_5P_Vertical | EL
BN43-202 3:1 | T30 | dogrudan-sdr:XFMR_Toroid_4P_Vertical | EL
BN43-3312 2:4 CT | T31 | dogrudan-sdr:XFMR_Toroid_5P_Vertical | EL
C kartindan | J32 | Connector_PinHeader_2.54mm:PinHeader_1x06_P2.54mm_Vertical | EL
DPD -> C karti | J20 | Connector_Coaxial:SMA_Amphenol_132289_EdgeMount | C496550
FT50-43 1:32 | T20,T21 | dogrudan-sdr:XFMR_Toroid_4P_Vertical | EL
G2RL-2 DC12 | KL1,KL2,KL3,KL4,KL5,KL6,KL7 | Relay_THT:Relay_DPDT_Omron_G2RL-2 | C120133
G6K-2F-Y | K20 | Relay_SMD:Relay_DPDT_Omron_G6K-2F-Y | C80087
INA240A1DR | U31,U32,U33,U34 | Package_SO:SOIC-8_3.9x4.9mm_P1.27mm | C2060769
IRF530N | Q20,Q21 | Package_TO_SOT_THT:TO-220-3_Vertical | C2565
IRFB4110PBF | Q30 | Package_TO_SOT_THT:TO-220-3_Vertical | C2650
IRFP250N | Q10,Q11,Q12,Q13 | Package_TO_SOT_THT:TO-247-3_Vertical | C2580
LM358 | U41,U42 | Package_SO:SOIC-8_3.9x4.9mm_P1.27mm | C7950
LM5164DDAR | U50 | Package_SO:SOIC-8-1EP_3.9x4.9mm_P1.27mm_EP2.29x3mm_ThermalVias | C477928
LM74700QDBVRQ1 | U52 | Package_TO_SOT_SMD:SOT-23-6 | C2941042
MCP3208T-CI/SL | U57 | Package_SO:SOIC-16_3.9x9.9mm_P1.27mm | C626764
MCP4922-E/SL | U20,U21 | Package_SO:SOIC-14_3.9x8.7mm_P1.27mm | C39851
MCP9700AT | U55 | Package_TO_SOT_SMD:SOT-23 | C97258
PE4312C-Z | U10 | Package_DFN_QFN:TQFN-20-1EP_4x4mm_P0.5mm_EP2.1x2.1mm | C500480
PGA-103+ | U11 | Package_TO_SOT_SMD:SOT-89-3 | C3008207
SMBJ54A | D31 | Diode_SMD:D_SMB | C151266
T50-6 10s | L554 | dogrudan-sdr:L_Toroid_T50_Vertical | ?
T50-6 7s | L558,L562 | dogrudan-sdr:L_Toroid_T50_Vertical | EL
T50-6 9s | L546,L550 | dogrudan-sdr:L_Toroid_T50_Vertical | EL
T68-2 10s | L537,L541 | dogrudan-sdr:L_Toroid_T68_Vertical | EL
T68-2 12s | L528,L532 | dogrudan-sdr:L_Toroid_T68_Vertical | EL
T94-2 15s | L519,L523 | dogrudan-sdr:L_Toroid_T94_Vertical | EL
T94-2 17s | L510,L514 | dogrudan-sdr:L_Toroid_T94_Vertical | EL
T94-2 24s | L501,L505 | dogrudan-sdr:L_Toroid_T94_Vertical | EL
TPS62130 | U51 | Package_DFN_QFN:VQFN-16-1EP_3x3mm_P0.5mm_EP1.68x1.68mm | C337502
sonraki PA | J33 | Connector_PinHeader_2.54mm:PinHeader_2x10_P2.54mm_Vertical | EL

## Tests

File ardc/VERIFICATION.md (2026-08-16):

# Verification evidence

Project `dogrudan-sdr`. Amateur radio club of TEVITOL, station
callsign YM2X.

**This file is generated.** `python3 ardc/topla.py` writes it. Each
number below comes from a tool that ran when the file was written.
If a tool fails, the script stops and no package is produced.

Date of this package: 2026-08-16

---

## 1. Schematic checks

These tools examine the schematic and the netlist. They find faults
that ERC cannot see, because ERC looks at the schematic alone.

| Check | Result |
|---|---|
| Symbol pins against footprint pads | pass |
| Pads with no net | pass |
| Netlist against the design intent | pass |
| Schematic rules | pass |
| Regulator part number against its rail | pass |

## 2. Circuit simulation

Connectivity can be correct while the values are wrong. These runs
measure the circuit, not the connections. Each one found a fault
that would have made a board unusable.

| Simulation | Result | Tool |
|---|---|---|
| Receive chain, antenna to ADC pin | pass | `kicad/zincir_sim.py` |
| Transmit harmonic filters | pass | `kicad/lpf_sim.py` |
| Transmit chain, DAC images | pass | `kicad/tx_zincir_sim.py` |
| PA bias servo, stability and fault | pass | `kicad/bias_sim.py` |
| Power distribution network impedance | pass | `kicad/pdn_sim.py` |
| Gain budget from device parameters | pass | `kicad/kazanc_butcesi.py` |
| Thermal budget | pass | `kicad/termal_hesap.py` |
| Tolerance and Monte Carlo | pass | `kicad/tolerans_sim.py` |

## 3. Gateware verification

| Item | Value |
|---|---|
| Checks that pass | 29 |
| Checks that fail | 0 |

The set includes module testbenches, a full-chip simulation with an
observer on every output pin, gate-level runs against the
synthesised netlist, a structural clock-domain-crossing check, and
three formal proofs. Each formal proof was tested by mutation: a
proof that passes but catches nothing gives false confidence.

## 4. Timing

| Clock | Achieved | Required | Result |
|---|---|---|---|
| adc1_dco | 164.20 MHz | 80.00 MHz | pass |
| adc2_dco | 168.01 MHz | 80.00 MHz | pass |
| clk_eth | 134.59 MHz | 125.00 MHz | pass |
| clk_sys | 86.57 MHz | 80.00 MHz | pass |
| rgmii_rxc | 140.06 MHz | 125.00 MHz | pass |

## 5. Bill of materials

| Board | Lines | Components |
|---|---|---|
| A | 80 | 303 |
| C | 60 | 404 |
| D | 113 | 252 |

Every line has a verified order code. A separate tool queries the
supplier and checks three things: the package and the value must
agree exactly, the stock must exceed the quantity, and the real
properties of the part must suit the circuit. That last check found
filter capacitors specified as X7R, and trap capacitors rated at
50 V in a position that carries 93 V.

Through-hole parts do not go into machine assembly. `ELLE_TAKILAN.md`
on board D lists them with the necessary specification.

## 6. Files in this package

| File | Content |
|---|---|
| `sema/` | Schematics of the three boards, PDF |
| `bom/` | Bill of materials of the three boards, CSV |
| `VERIFICATION.md` | This file |
| `README.md` | What the unit is and what it is for |
| `RATIONALE.md` | Why the four main design decisions were made |

The schematics and the bills of materials are regenerated from the
source of this package. They cannot be older than the design.

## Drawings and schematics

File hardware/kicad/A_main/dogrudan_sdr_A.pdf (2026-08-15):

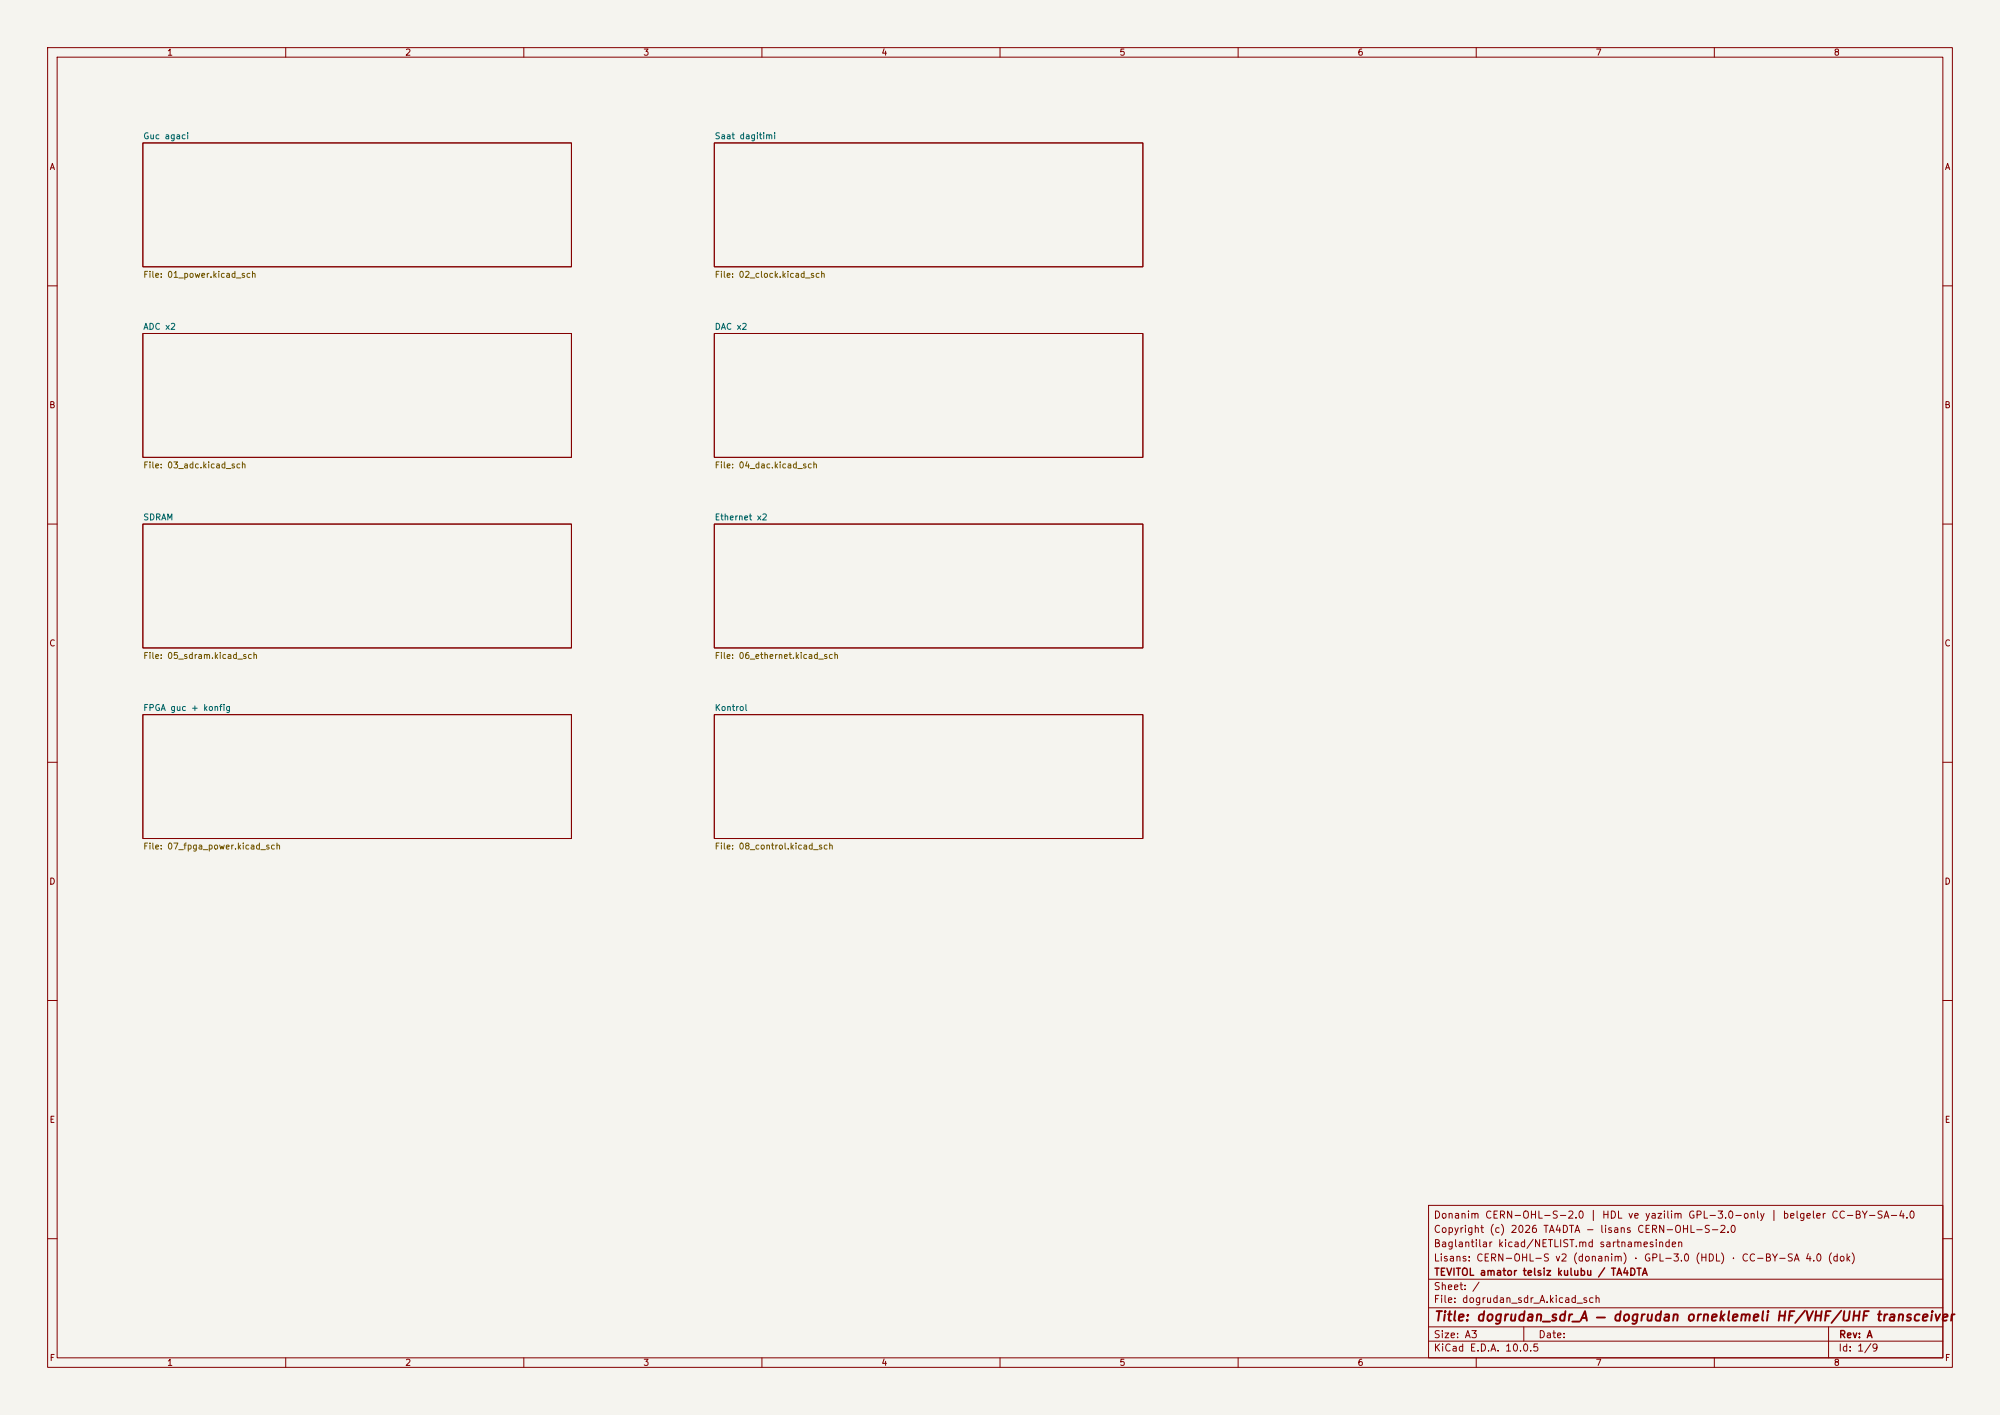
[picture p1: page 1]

Donanim CERN-OHL-S-2.0 | HDL ve yazilim GPL-3.0-only | belgeler CC-BY-SA-4.0
Copyright (c) 2026 TA4DTA - lisans CERN-OHL-S-2.0
Baglantilar kicad/NETLIST.md sartnamesinden
Lisans: CERN-OHL-S v2 (donanim) · GPL-3.0 (HDL) · CC-BY-SA 4.0 (dok)
TEVITOL amator telsiz kulubu / TA4DTA
Sheet: /
File: dogrudan_sdr_A.kicad_sch
Title: dogrudan_sdr_A — dogrudan orneklemeli HF/VHF/UHF transceiver

Size: A3 | Rev: A
KiCad E.D.A. 10.0.5 | Id: 1/9 | F Date:

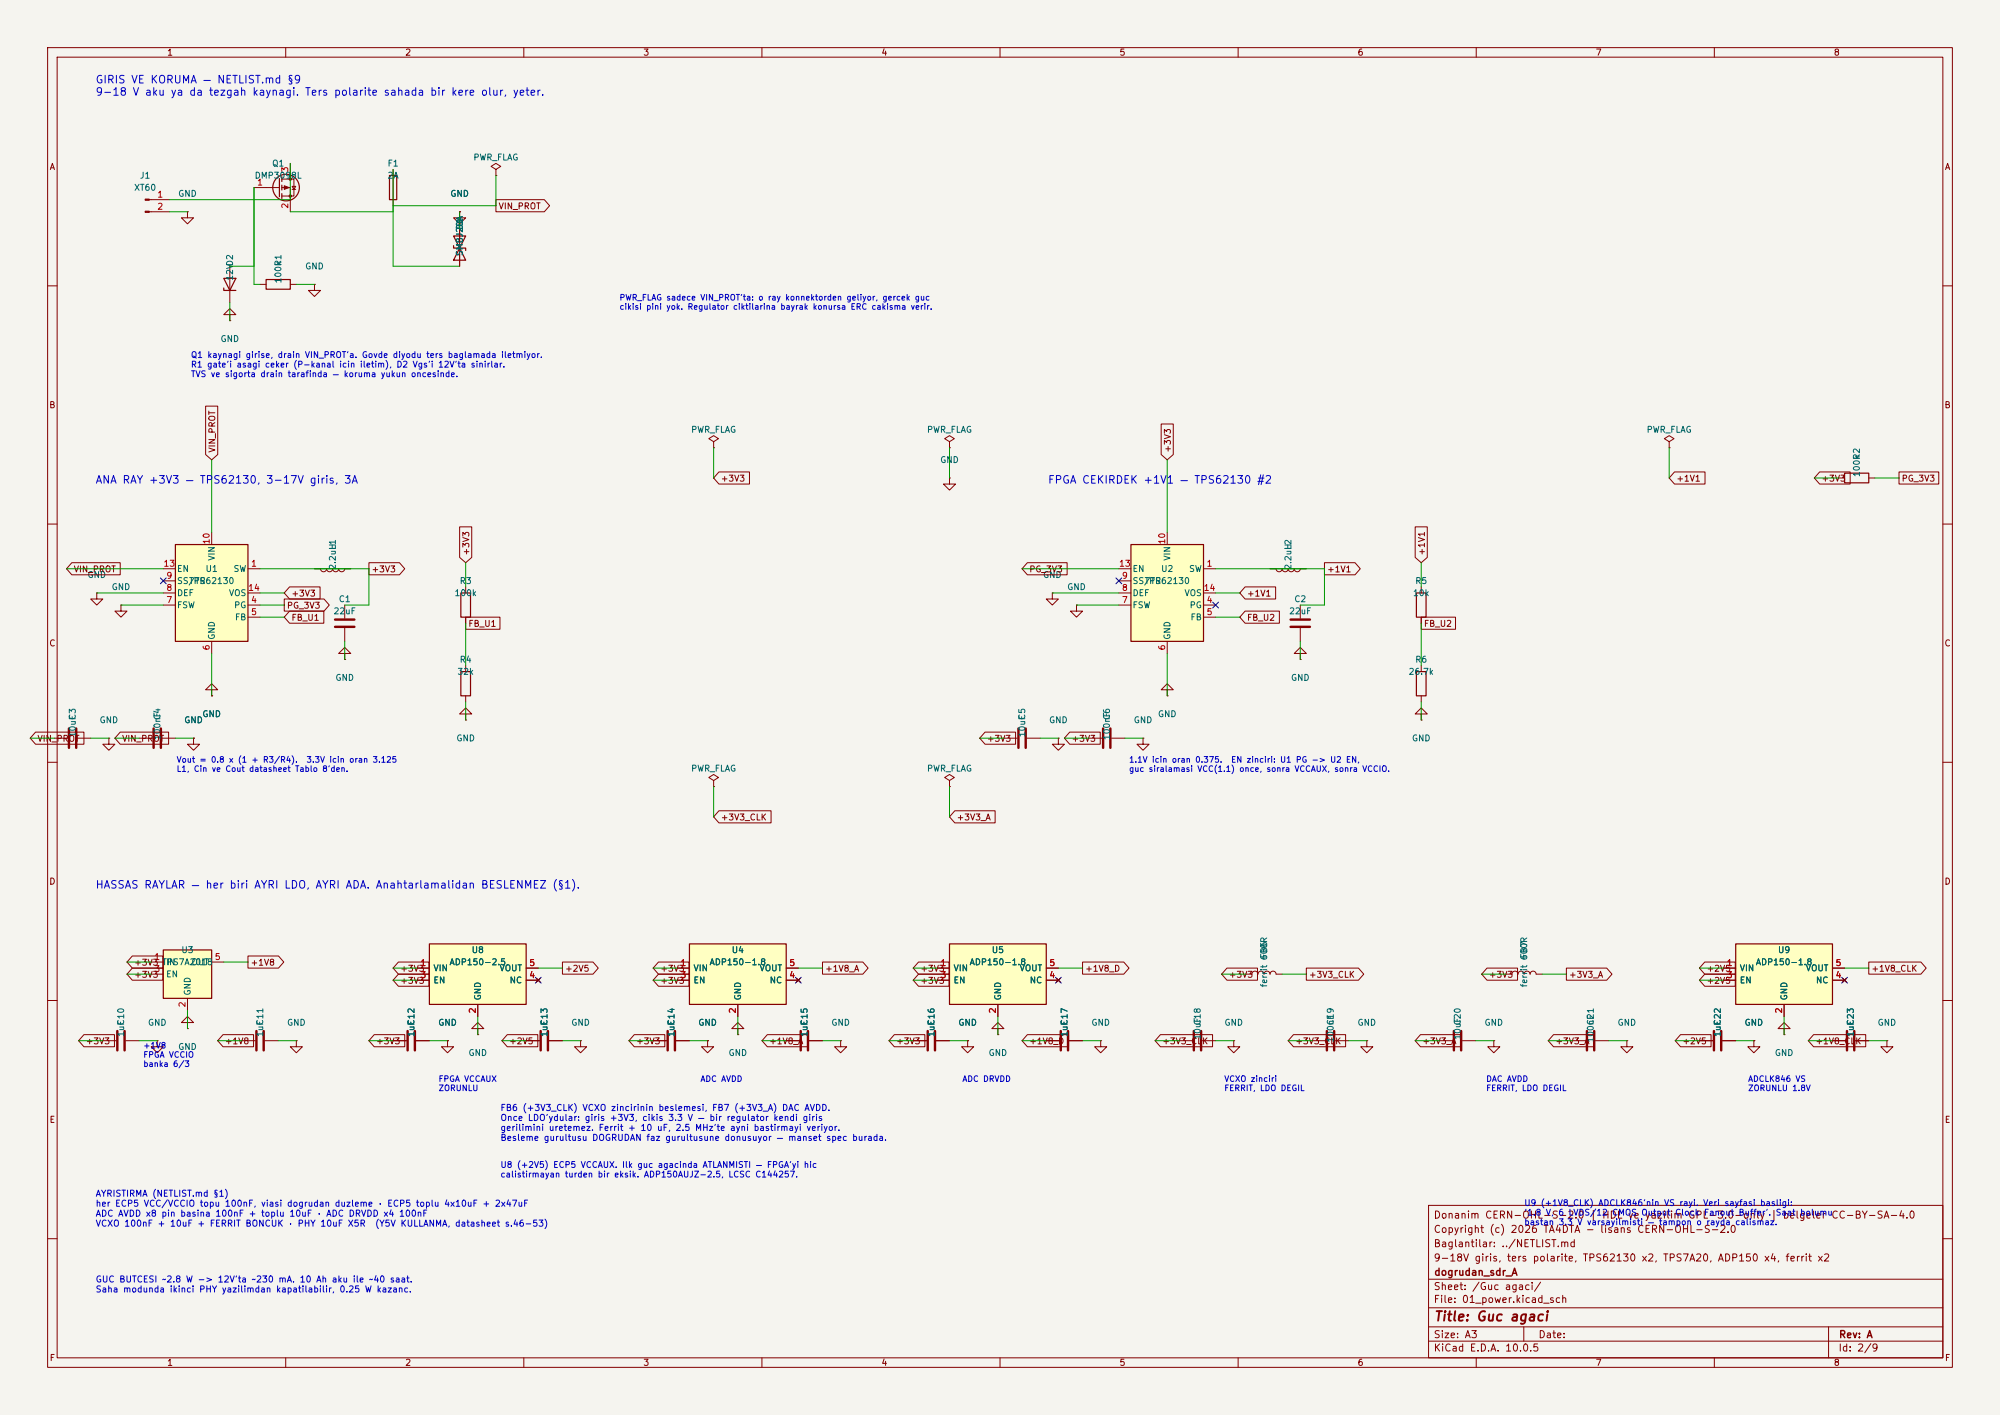
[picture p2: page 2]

Q1 kaynagi girise, drain VIN_PROT'a. Govde diyodu ters baglamada iletmiyor. R1 gate'i asagi ceker (P-kanal icin iletim), D2 Vgs'i 12V'ta sinirlar. TVS ve sigorta drain tarafinda — koruma yukun oncesinde. GIRIS VE KORUMA — NETLIST.md §9

cikisi pini yok. Regulator ciktilarina bayrak konursa ERC cakisma verir.
GND C5 10uF GND

L1, Cin ve Cout datasheet Tablo 8'den. HASSAS RAYLAR — her biri AYRI LDO, AYRI ADA. Anahtarlamalidan BESLENMEZ (§1).

VCXO 100nF + 10uF + FERRIT BONCUK · PHY 10uF X5R (Y5V KULLANMA, datasheet s.46-53) +1V8

bastan 3.3 V varsayilmisti — tampon o rayda calismaz. ADCLK846 VS

ZORUNLU GUC BUTCESI ~2.8 W -> 12V'ta ~230 mA. 10 Ah aku ile ~40 saat. Saha modunda ikinci PHY yazilimdan kapatilabilir, 0.25 W kazanc. AYRISTIRMA (NETLIST.md §1) her ECP5 VCC/VCCIO topu 100nF, viasi dogrudan duzleme · ECP5 toplu 4x10uF + 2x47uF

FB6 (+3V3_CLK) VCXO zincirinin beslemesi, FB7 (+3V3_A) DAC AVDD. Once LDO'ydular: giris +3V3, cikis 3.3 V — bir regulator kendi giris

gerilimini uretemez. Ferrit + 10 uF, 2.5 MHz'te ayni bastirmayi veriyor. Besleme gurultusu DOGRUDAN faz gurultusune donusuyor — manset spec burada. U8 (+2V5) ECP5 VCCAUX. Ilk guc agacinda ATLANMISTI — FPGA'yi hic

calistirmayan turden bir eksik. ADP150AUJZ-2.5, LCSC C144257.

U9 (+1V8_CLK) ADCLK846'nin VS rayi. Veri sayfasi basligi:
'1.8 V, 6 LVDS/12 CMOS Output Clock Fanout Buffer'. Saat bolumu

ADC AVDD x8 pin basina 100nF + toplu 10uF · ADC DRVDD x4 100nF

Donanim CERN-OHL-S-2.0 | HDL ve yazilim GPL-3.0-only | belgeler CC-BY-SA-4.0
Copyright (c) 2026 TA4DTA - lisans CERN-OHL-S-2.0
Baglantilar: ../NETLIST.md
9-18V giris, ters polarite, TPS62130 x2, TPS7A20, ADP150 x4, ferrit x2
dogrudan_sdr_A
Sheet: /Guc agaci/
File: 01_power.kicad_sch
Title: Guc agaci

Size: A3 | Rev: A

F Date:

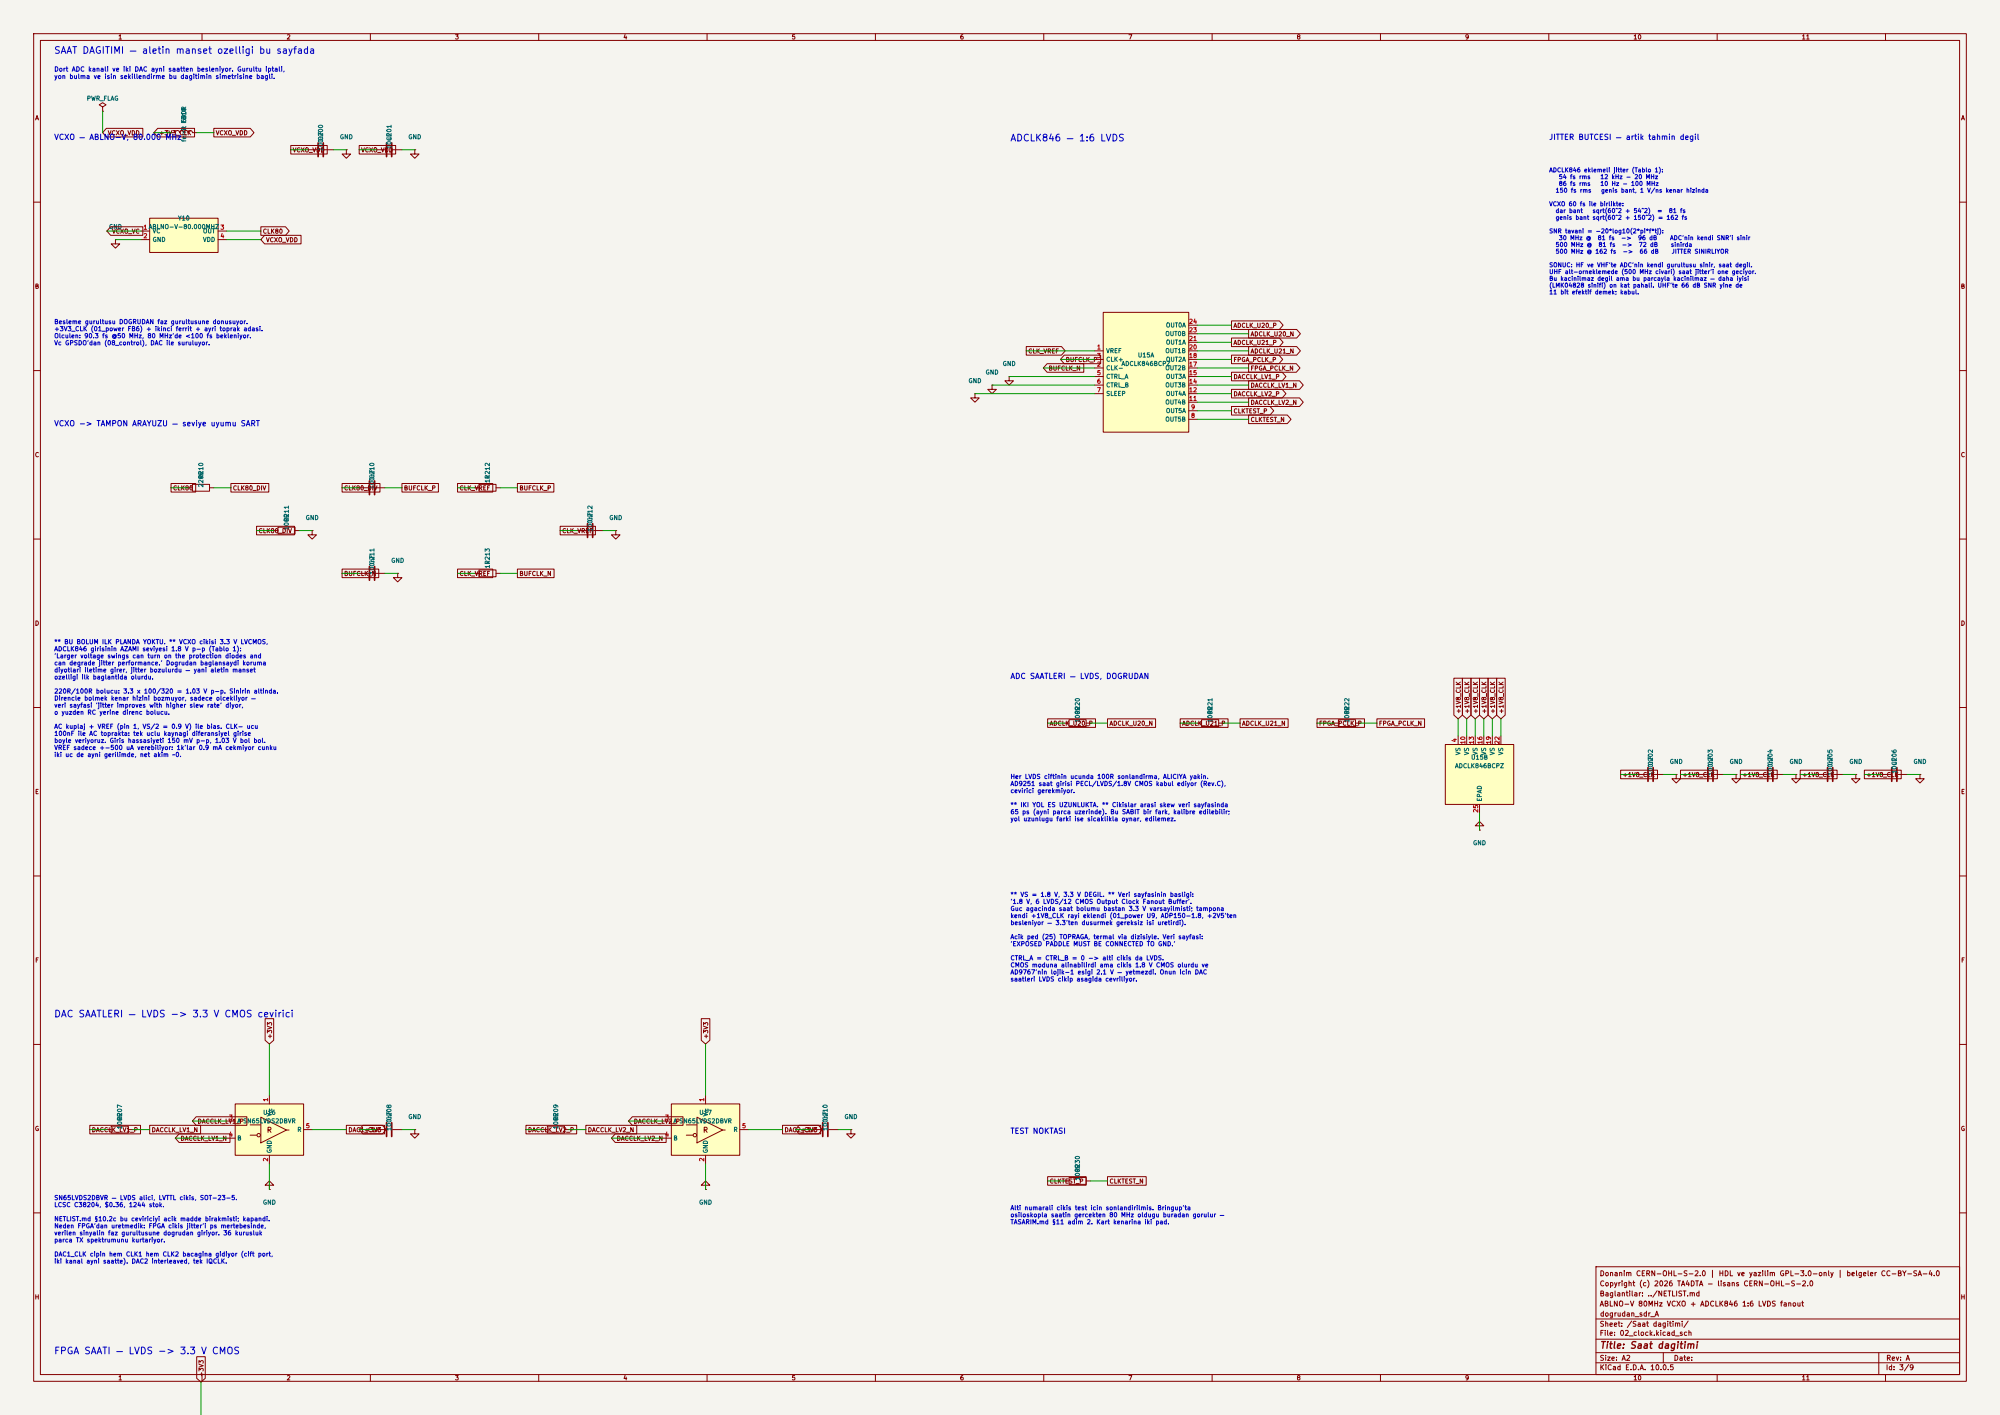
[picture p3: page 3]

SAAT DAGITIMI — aletin manset ozelligi bu sayfada

Dort ADC kanali ve iki DAC ayni saatten besleniyor. Gurultu iptali, yon bulma ve isin sekillendirme bu dagitimin simetrisine bagli.

SONUC: HF ve VHF'te ADC'nin kendi gurultusu sinir, saat degil. UHF alt-orneklemede (500 MHz civari) saat jitter'i one geciyor. Bu kacinilmaz degil ama bu parcayla kacinilmaz — daha iyisi

(LMK04828 sinifi) on kat pahali. UHF'te 66 dB SNR yine de 11 bit efektif demek; kabul.

Besleme gurultusu DOGRUDAN faz gurultusune donusuyor. +3V3_CLK (01_power FB6) + ikinci ferrit + ayri toprak adasi. Olculen: 90.3 fs @50 MHz, 80 MHz'de <100 fs bekleniyor. Vc GPSDO'dan (08_control), DAC ile suruluyor.

iki uc de ayni gerilimde, net akim ~0. FPGA SAATI — LVDS -> 3.3 V CMOS

VCXO -> TAMPON ARAYUZU — seviye uyumu SART

** BU BOLUM ILK PLANDA YOKTU. ** VCXO cikisi 3.3 V LVCMOS, ADCLK846 girisinin AZAMI seviyesi 1.8 V p-p (Tablo 1):

'Larger voltage swings can turn on the protection diodes and
can degrade jitter performance.' Dogrudan baglansaydi koruma
diyotlari iletime girer, jitter bozulurdu — yani aletin manset ozelligi ilk baglantida olurdu. 220R/100R bolucu: 3.3 x 100/320 = 1.03 V p-p. Sinirin altinda. Direncle bolmek kenar hizini bozmuyor, sadece olcekliyor —

ADC SAATLERI — LVDS, DOGRUDAN

veri sayfasi 'jitter improves with higher slew rate' diyor, o yuzden RC yerine direnc bolucu. AC kuplaj + VREF (pin 1, VS/2 = 0.9 V) ile bias. CLK- ucu 100nF ile AC toprakta: tek uclu kaynagi diferansiyel girise

4 VS 10 VS 13 VS 16 VS 19 VS 22 EPAD 25 U15B
Donanim CERN-OHL-S-2.0 | HDL ve yazilim GPL-3.0-only | belgeler CC-BY-SA-4.0 VS

boyle veriyoruz. Giris hassasiyeti 150 mV p-p, 1.03 V bol bol. VREF sadece +-500 uA verebiliyor: 1k'lar 0.9 mA cekmiyor cunku

Her LVDS ciftinin ucunda 100R sonlandirma, ALICIYA yakin. AD9251 saat girisi PECL/LVDS/1.8V CMOS kabul ediyor (Rev.C), cevirici gerekmiyor. ** IKI YOL ES UZUNLUKTA. ** Cikislar arasi skew veri sayfasinda 65 ps (ayni parca uzerinde). Bu SABIT bir fark, kalibre edilebilir;

yol uzunlugu farki ise sicaklikla oynar, edilemez. ** VS = 1.8 V, 3.3 V DEGIL. ** Veri sayfasinin basligi:
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

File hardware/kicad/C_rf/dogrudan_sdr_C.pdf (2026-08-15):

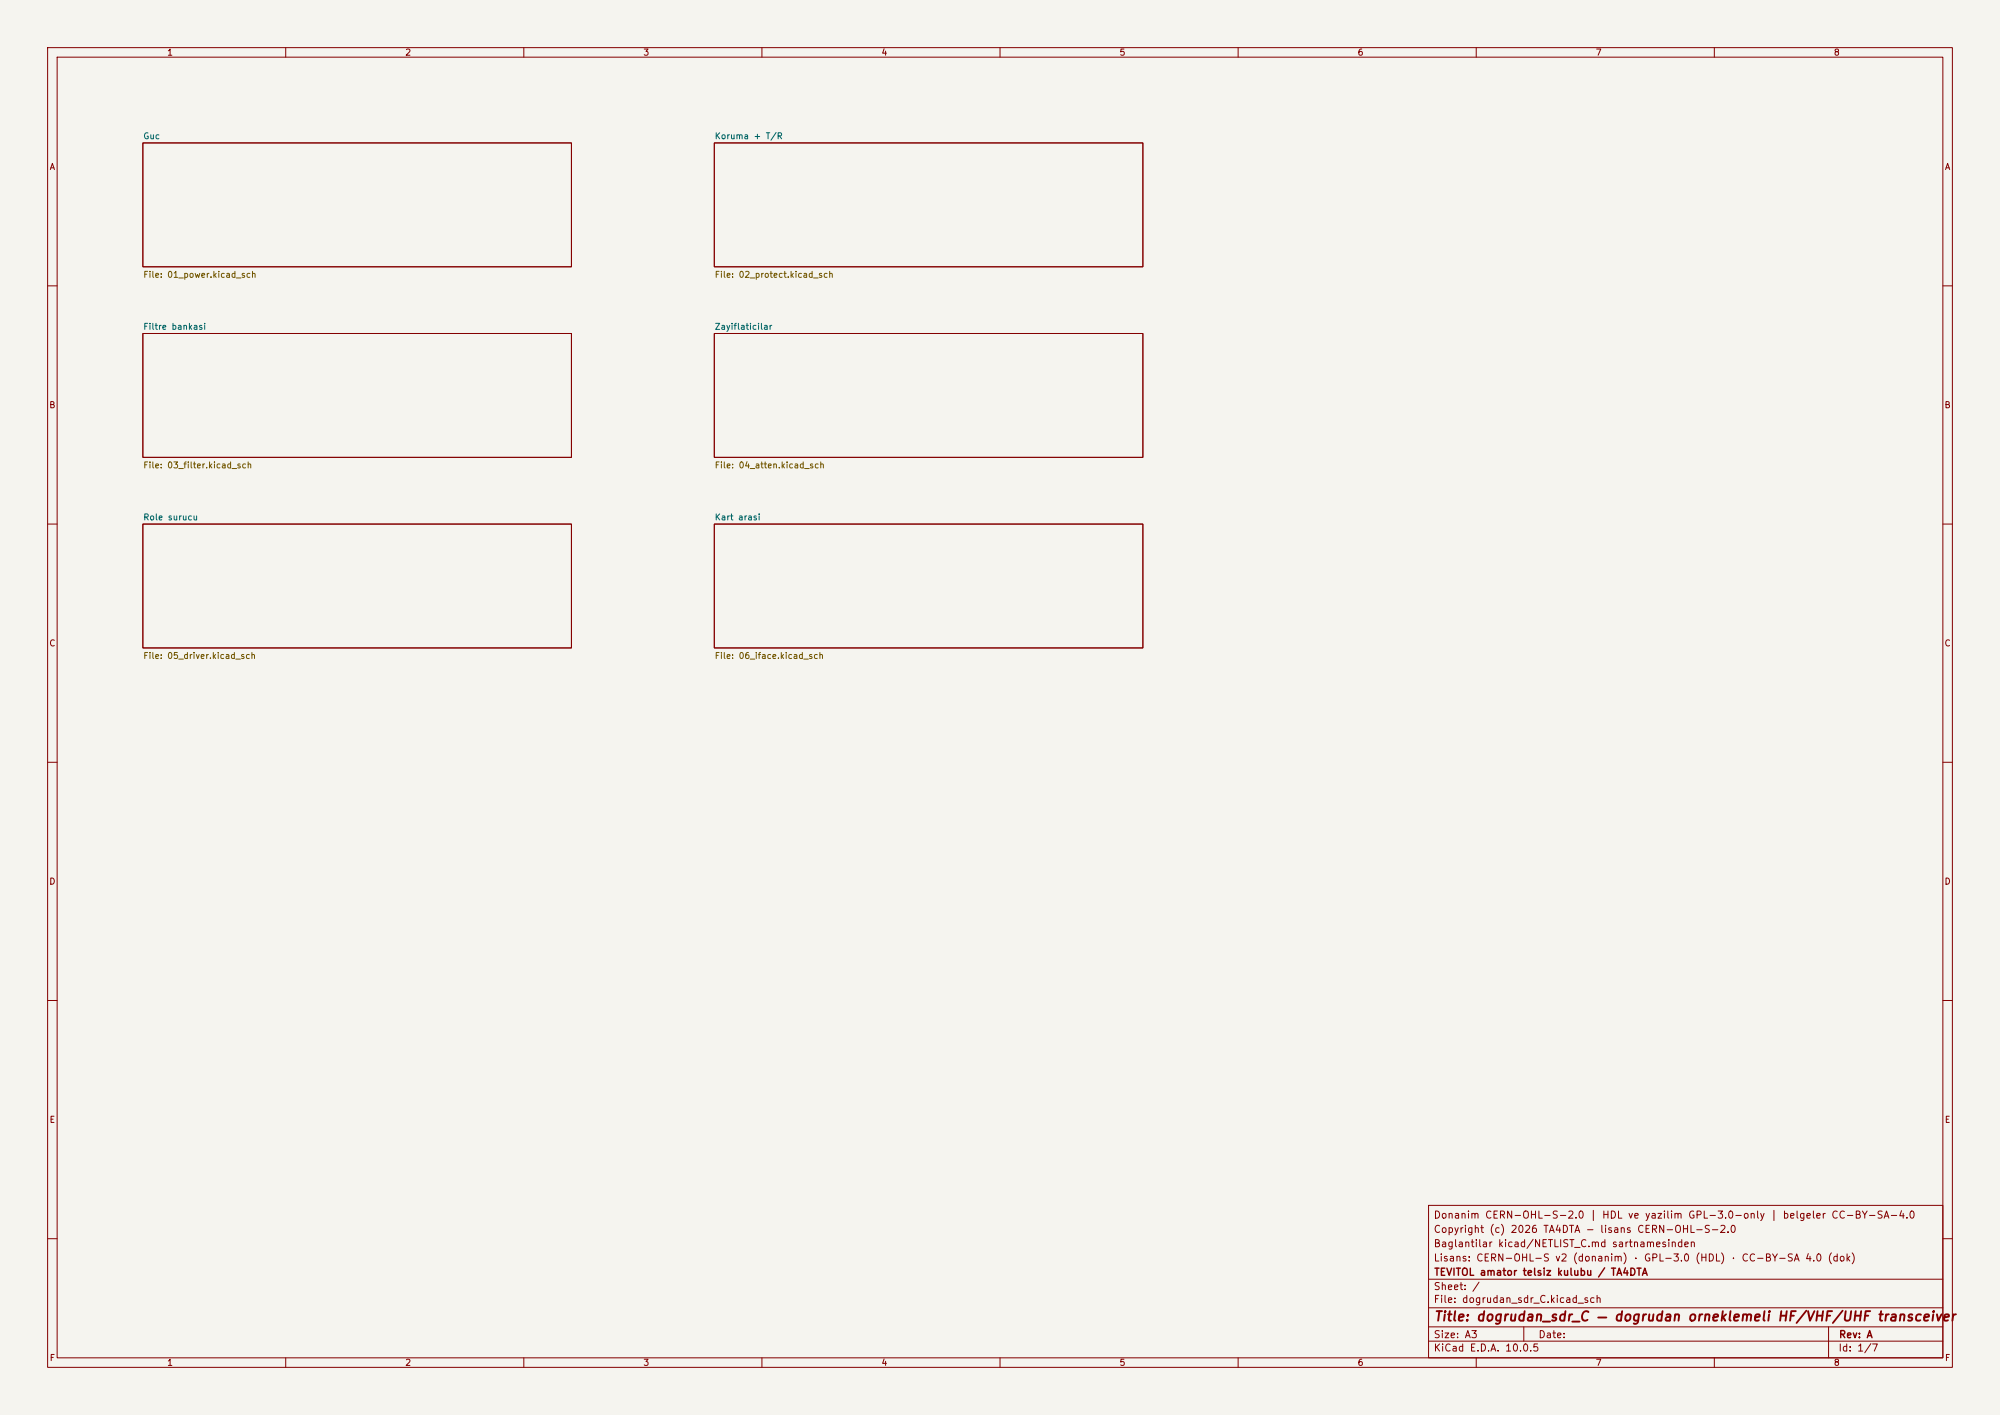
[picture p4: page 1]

File: 02_protect.kicad_sch Kart arasi File: 06_iface.kicad_sch

Donanim CERN-OHL-S-2.0 | HDL ve yazilim GPL-3.0-only | belgeler CC-BY-SA-4.0
Copyright (c) 2026 TA4DTA - lisans CERN-OHL-S-2.0
Baglantilar kicad/NETLIST_C.md sartnamesinden
Lisans: CERN-OHL-S v2 (donanim) · GPL-3.0 (HDL) · CC-BY-SA 4.0 (dok)
TEVITOL amator telsiz kulubu / TA4DTA
Sheet: /
File: dogrudan_sdr_C.kicad_sch
Title: dogrudan_sdr_C — dogrudan orneklemeli HF/VHF/UHF transceiver

Size: A3 | Rev: A
KiCad E.D.A. 10.0.5 | Id: 1/7 | F Date:

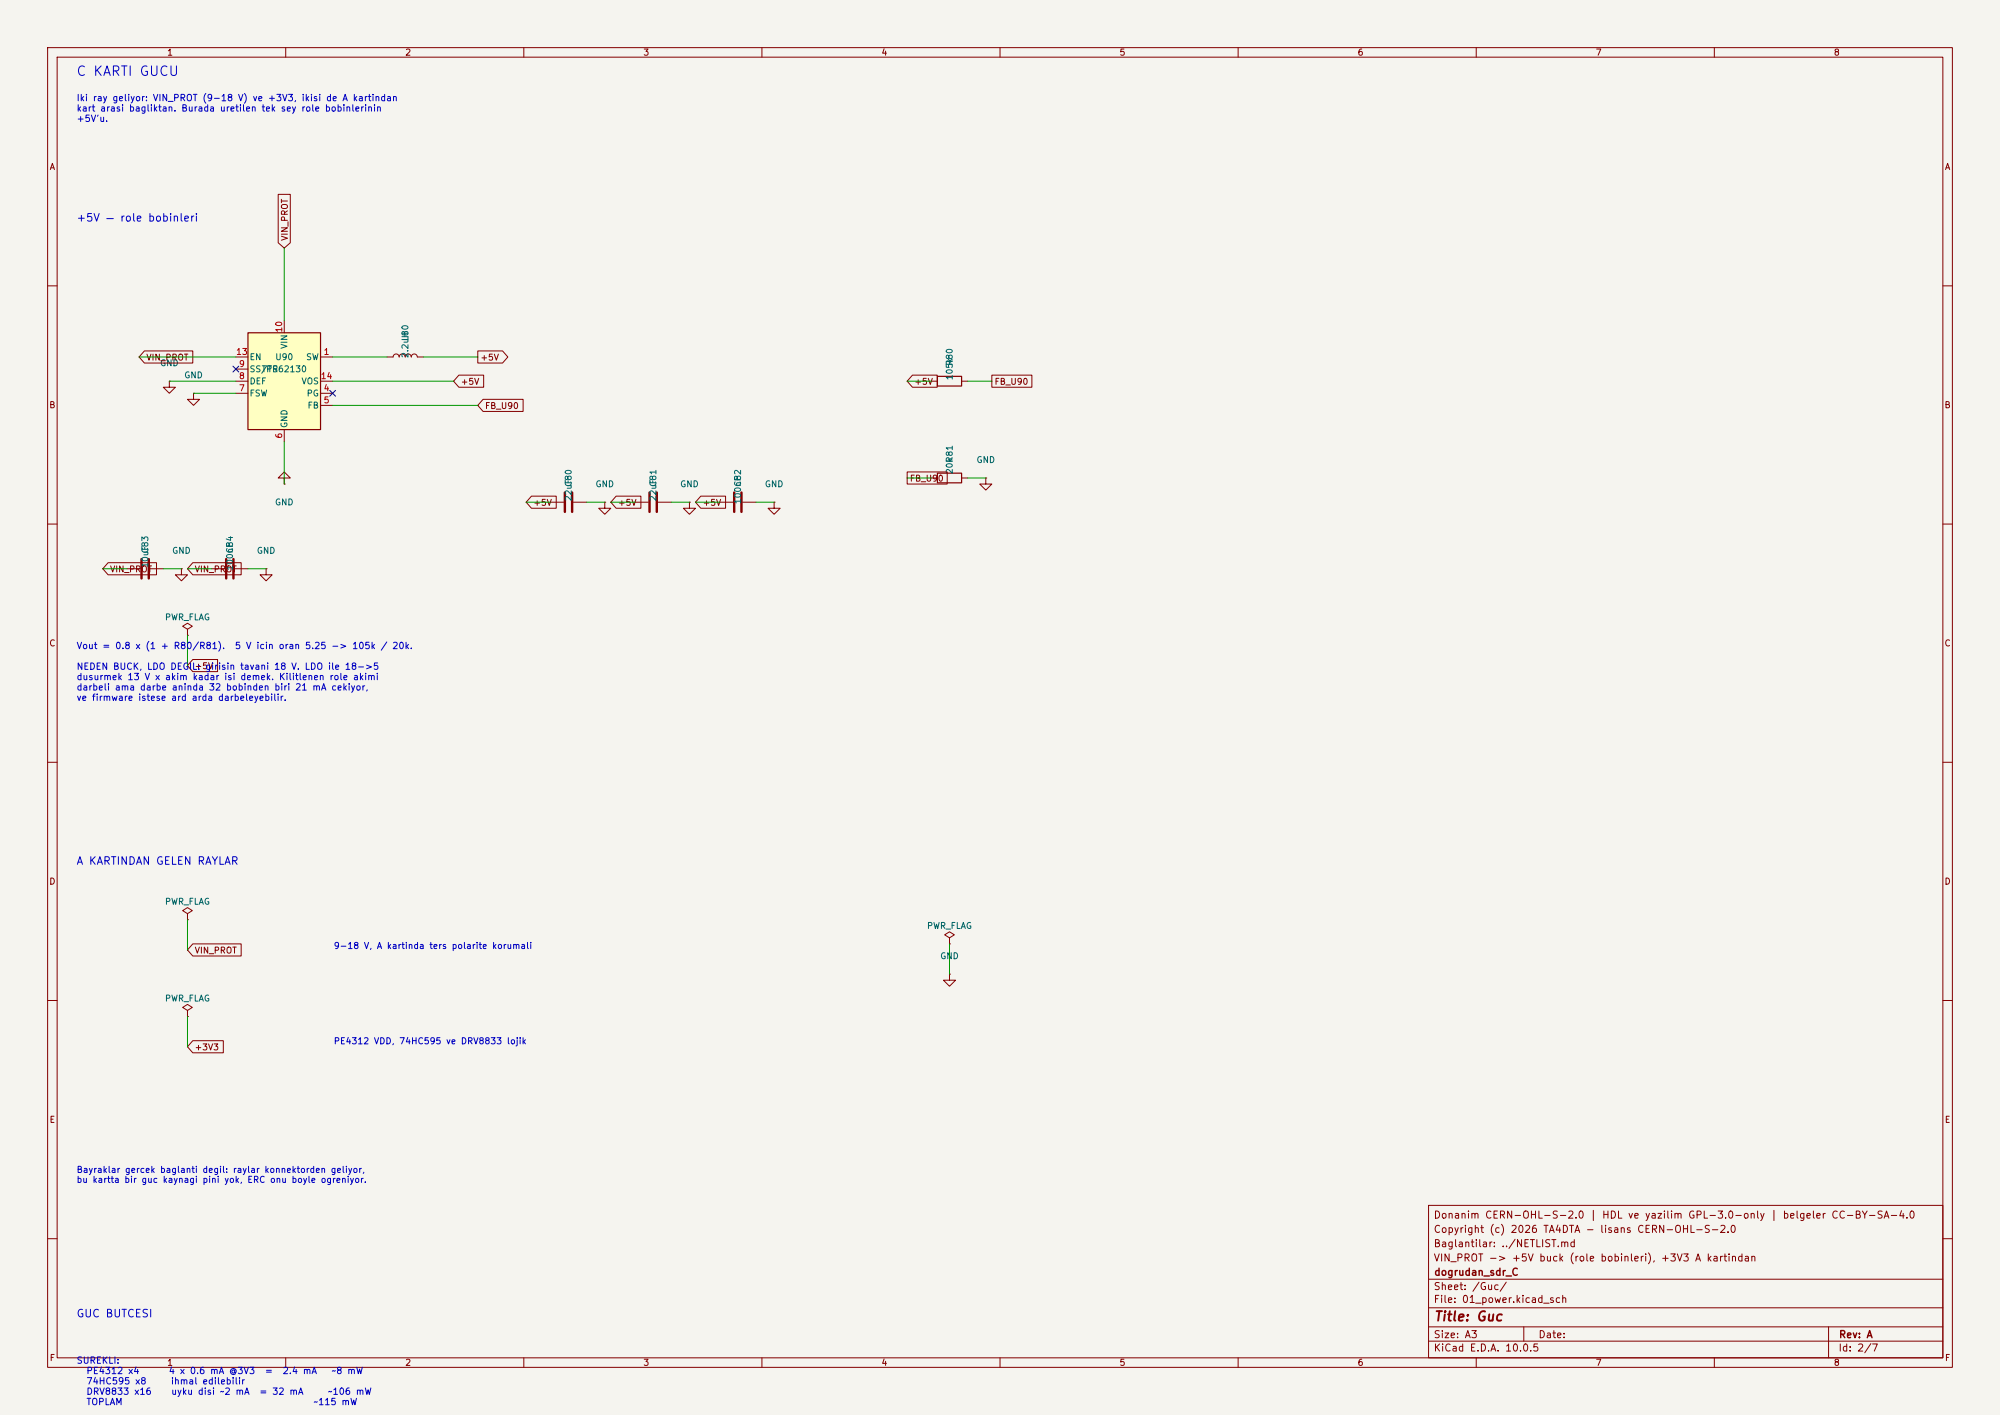
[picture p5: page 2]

Iki ray geliyor: VIN_PROT (9-18 V) ve +3V3, ikisi de A kartindan
kart arasi bagliktan. Burada uretilen tek sey role bobinlerinin +5V'u.

Vout = 0.8 x (1 + R80/R81). 5 V icin oran 5.25 -> 105k / 20k. NEDEN BUCK, LDO DEGIL: girisin tavani 18 V. LDO ile 18->5

dusurmek 13 V x akim kadar isi demek. Kilitlenen role akimi darbeli ama darbe aninda 32 bobinden biri 21 mA cekiyor, ve firmware istese ard arda darbeleyebilir.

9-18 V, A kartinda ters polarite korumali

Bayraklar gercek baglanti degil: raylar konnektorden geliyor, bu kartta bir guc kaynagi pini yok, ERC onu boyle ogreniyor.

Copyright (c) 2026 TA4DTA - lisans CERN-OHL-S-2.0
Baglantilar: ../NETLIST.md
VIN_PROT -> +5V buck (role bobinleri), +3V3 A kartindan
dogrudan_sdr_C
Sheet: /Guc/
File: 01_power.kicad_sch
Title: Guc

Size: A3 | Rev: A

F Date:

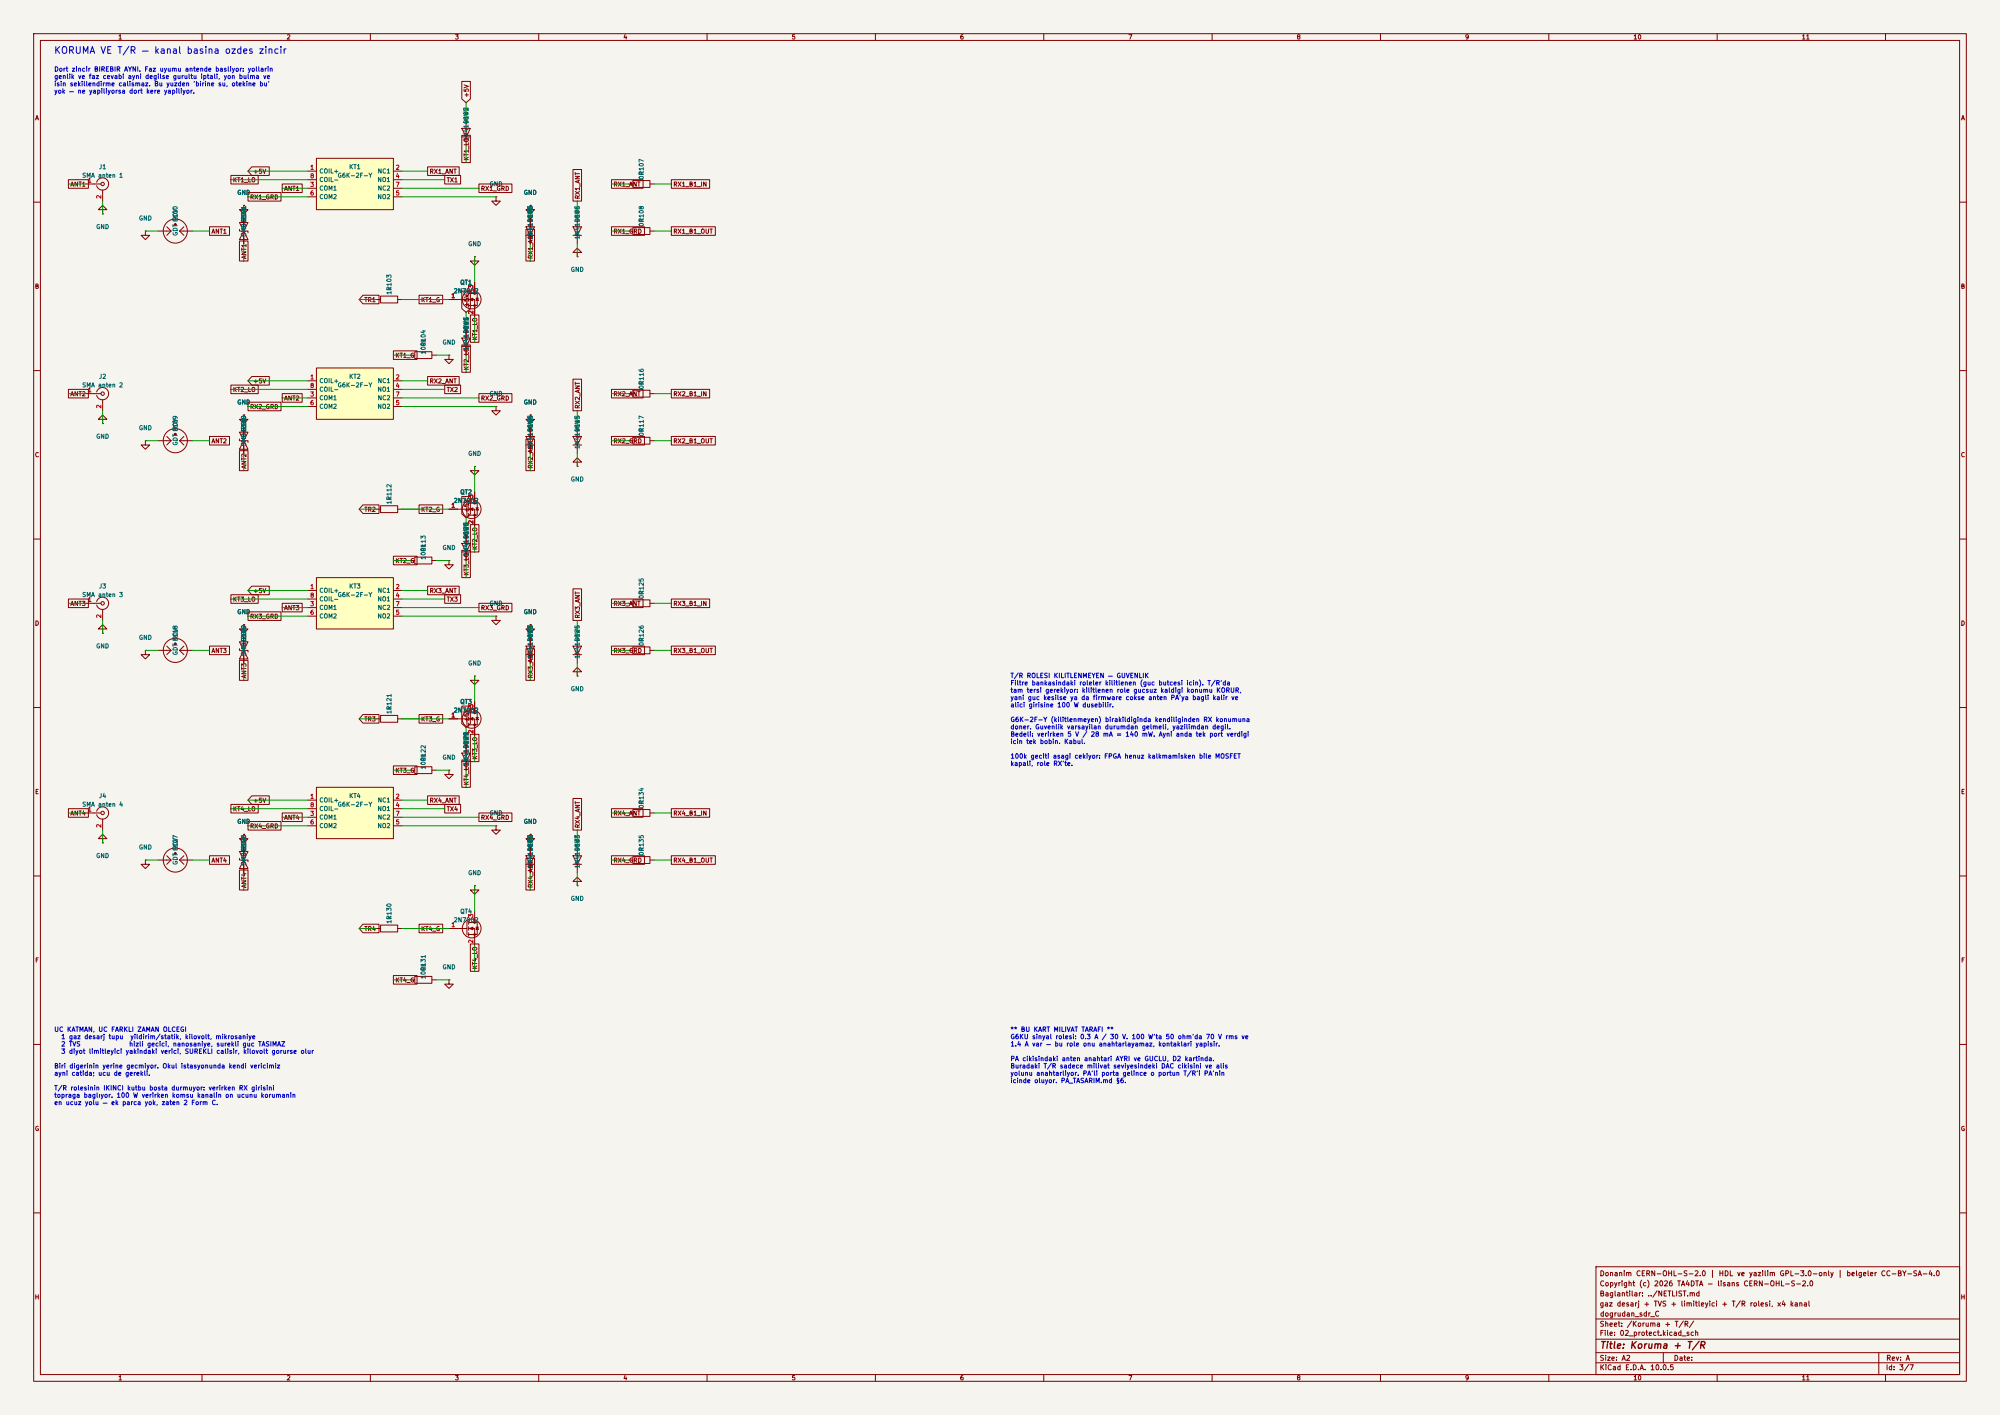
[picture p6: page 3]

RX1_B1_OUT KORUMA VE T/R — kanal basina ozdes zincir Dort zincir BIREBIR AYNI. Faz uyumu antende basliyor: yollarin
ANT1
TR2 +5V ANT1
TX2 RX2_ANT RX4_GRD
GND

genlik ve faz cevabi ayni degilse gurultu iptali, yon bulma ve
isin sekillendirme calismaz. Bu yuzden 'birine su, otekine bu' yok — ne yapiliyorsa dort kere yapiliyor.
RX1_GRD

T/R ROLESI KILITLENMEYEN — GUVENLIK
Filtre bankasindaki roleler kilitlenen (guc butcesi icin). T/R'da
tam tersi gerekiyor: kilitlenen role gucsuz kaldigi konumu KORUR,
yani guc kesilse ya da firmware cokse anten PA'ya bagli kalir ve alici girisine 100 W dusebilir. G6K-2F-Y (kilitlenmeyen) birakildiginda kendiliginden RX konumuna

doner. Guvenlik varsayilan durumdan gelmeli, yazilimdan degil. Bedeli: verirken 5 V / 28 mA = 140 mW. Ayni anda tek port verdigi

icin tek bobin. Kabul. 100k geciti asagi cekiyor: FPGA henuz kalkmamisken bile MOSFET kapali, role RX'te. ** BU KART MILIVAT TARAFI ** G6KU sinyal rolesi: 0.3 A / 30 V. 100 W'ta 50 ohm'da 70 V rms ve 1.4 A var — bu role onu anahtarlayamaz, kontaklari yapisir. PA cikisindaki anten anahtari AYRI ve GUCLU, D2 kartinda. Buradaki T/R sadece milivat seviyesindeki DAC cikisini ve alis

3 diyot limitleyici yakindaki verici, SUREKLI calisir, kilovolt gorurse olur Biri digerinin yerine gecmiyor. Okul istasyonunda kendi vericimiz ayni catida; ucu de gerekli.

yolunu anahtarliyor. PA'li porta gelince o portun T/R'i PA'nin

T/R rolesinin IKINCI kutbu bosta durmuyor: verirken RX girisini
topraga baglıyor. 100 W verirken komsu kanalin on ucunu korumanin
en ucuz yolu — ek parca yok, zaten 2 Form C.

Copyright (c) 2026 TA4DTA - lisans CERN-OHL-S-2.0
Baglantilar: ../NETLIST.md
gaz desarj + TVS + limitleyici + T/R rolesi, x4 kanal
dogrudan_sdr_C
Sheet: /Koruma + T/R/
File: 02_protect.kicad_sch
Title: Koruma + T/R

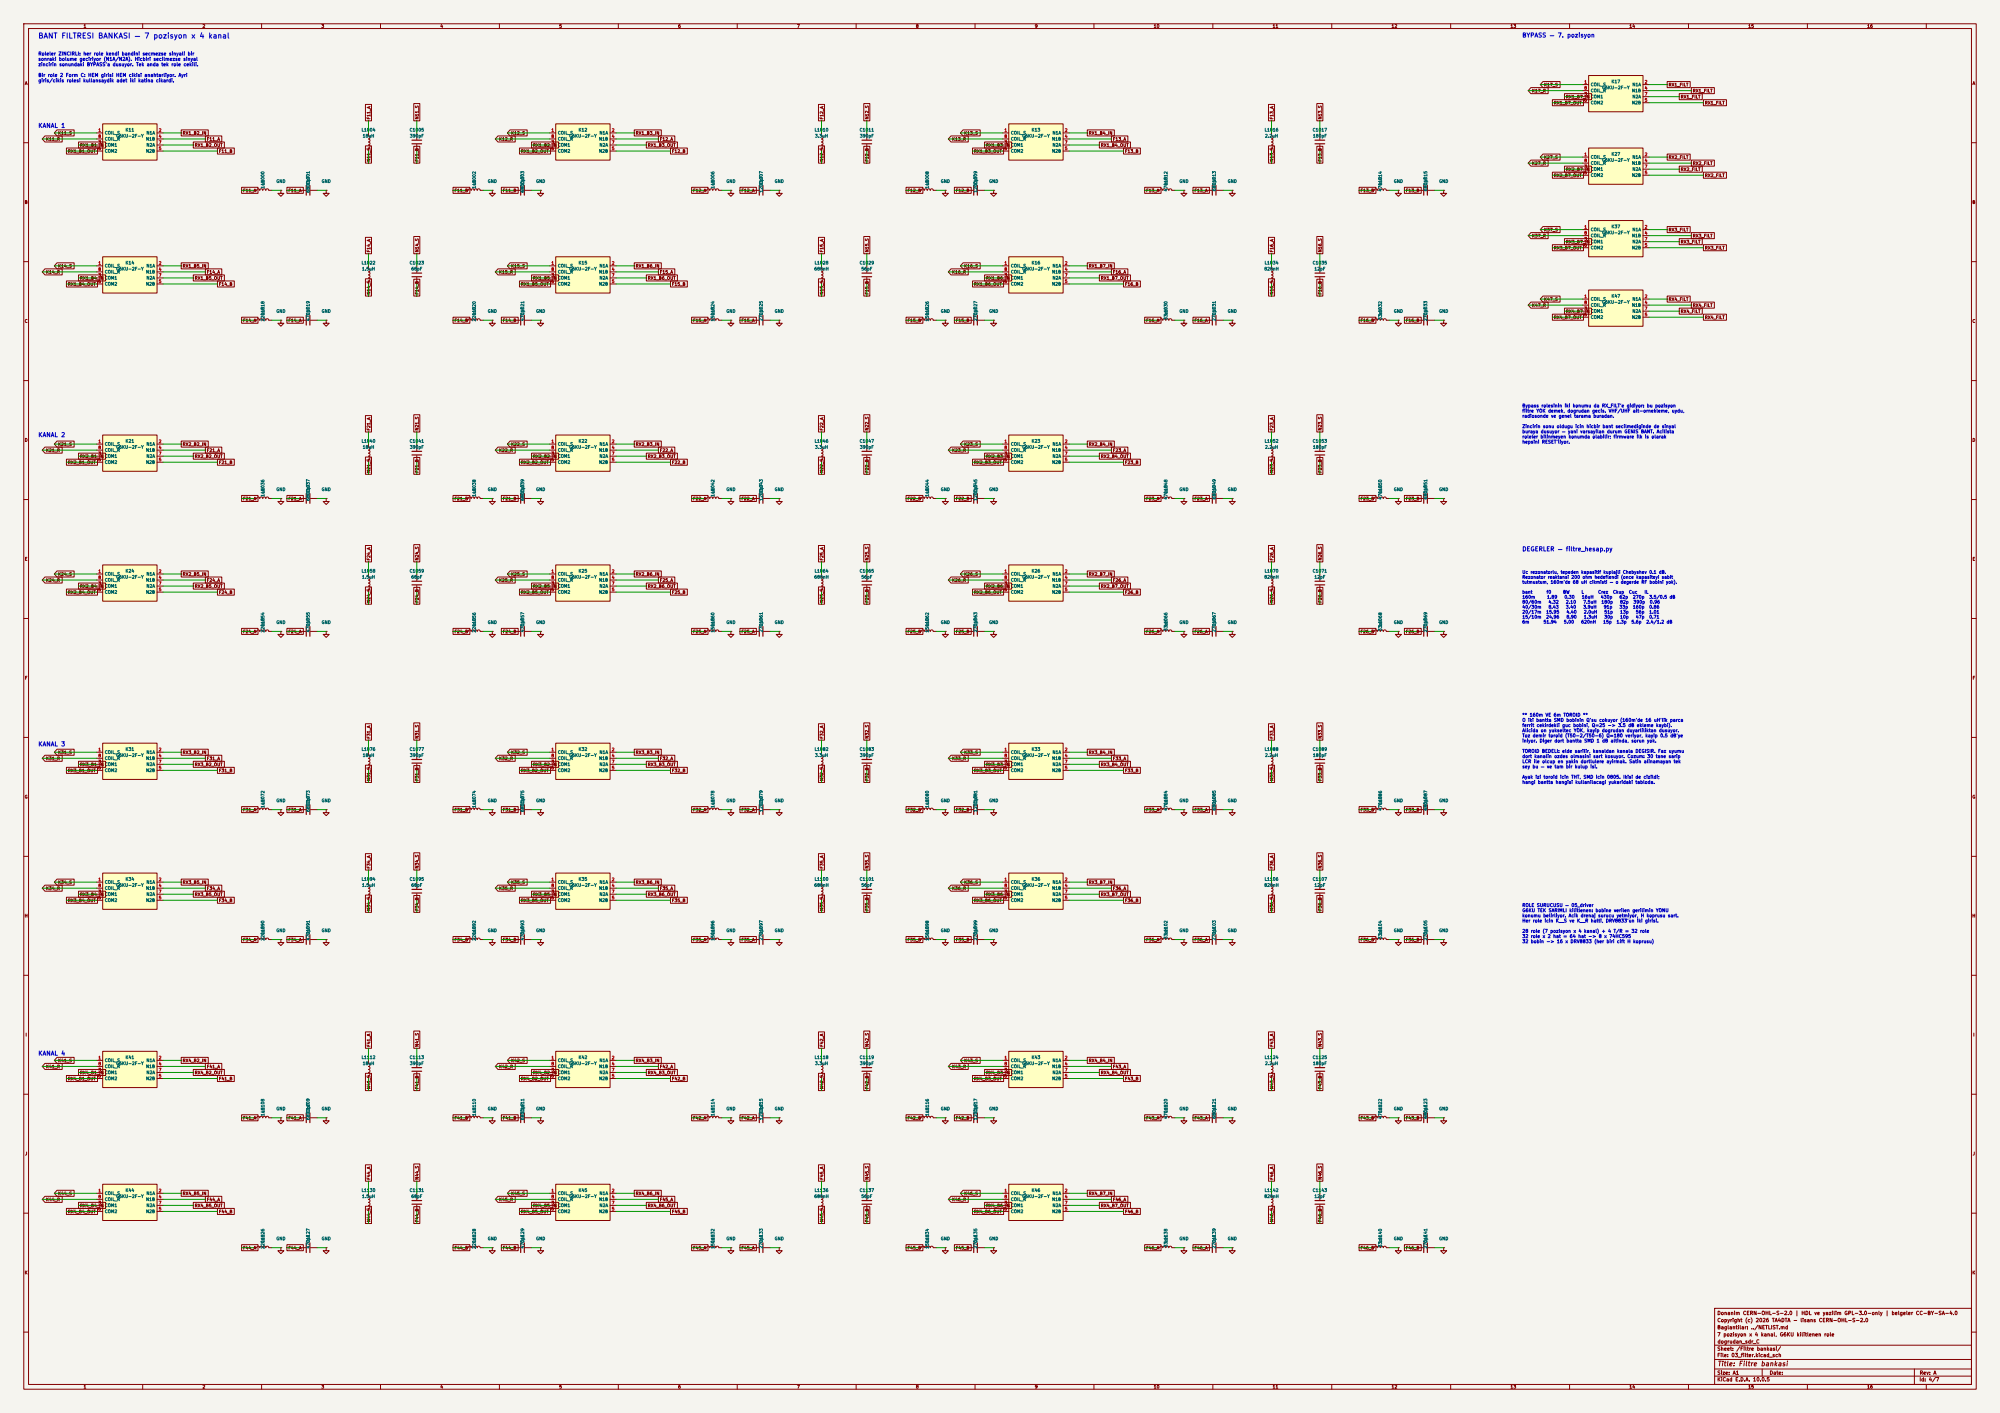
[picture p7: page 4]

BANT FILTRESI BANKASI — 7 pozisyon x 4 kanal

Roleler ZINCIRLI: her role kendi bandini secmezse sinyali bir sonraki bolume geciriyor (N1A/N2A). Hicbiri secilmezse sinyal zincirin sonundaki BYPASS'a dusuyor. Tek anda tek role cekili. Bir role 2 Form C: HEM girisi HEM cikisi anahtarliyor. Ayri

giris/cikis rolesi kullansaydik adet iki katina cikardi. KANAL 1

filtre YOK demek, dogrudan gecis. VHF/UHF alt-ornekleme, uydu, radiosonde ve genel tarama buradan. Zincirin sonu oldugu icin hicbir bant secilmediginde de sinyal

buraya dusuyor — yani varsayilan durum GENIS BANT. Acilista
roleler bilinmeyen konumda olabilir; firmware ilk is olarak hepsini RESET'liyor.

Uc rezonatorlu, tepeden kapasitif kuplajli Chebyshev 0.1 dB. Rezonator reaktansi 200 ohm hedeflendi (once kapasiteyi sabit

** 160m VE 6m TOROID ** O iki bantta SMD bobinin Q'su cokuyor (160m'de 16 uH'lik parca

ferrit cekirdekli guc bobini, Q=25 -> 3.5 dB ekleme kaybi). Alicida on yukseltec YOK, kayip dogrudan duyarliliktan dusuyor. Toz demir toroid (T50-2/T50-6) Q=180 veriyor, kayip 0.5 dB'ye

iniyor. Diger dort bantta SMD 1 dB altinda, sorun yok. TOROID BEDELI: elde sarilir, kanaldan kanala DEGISIR. Faz uyumu
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

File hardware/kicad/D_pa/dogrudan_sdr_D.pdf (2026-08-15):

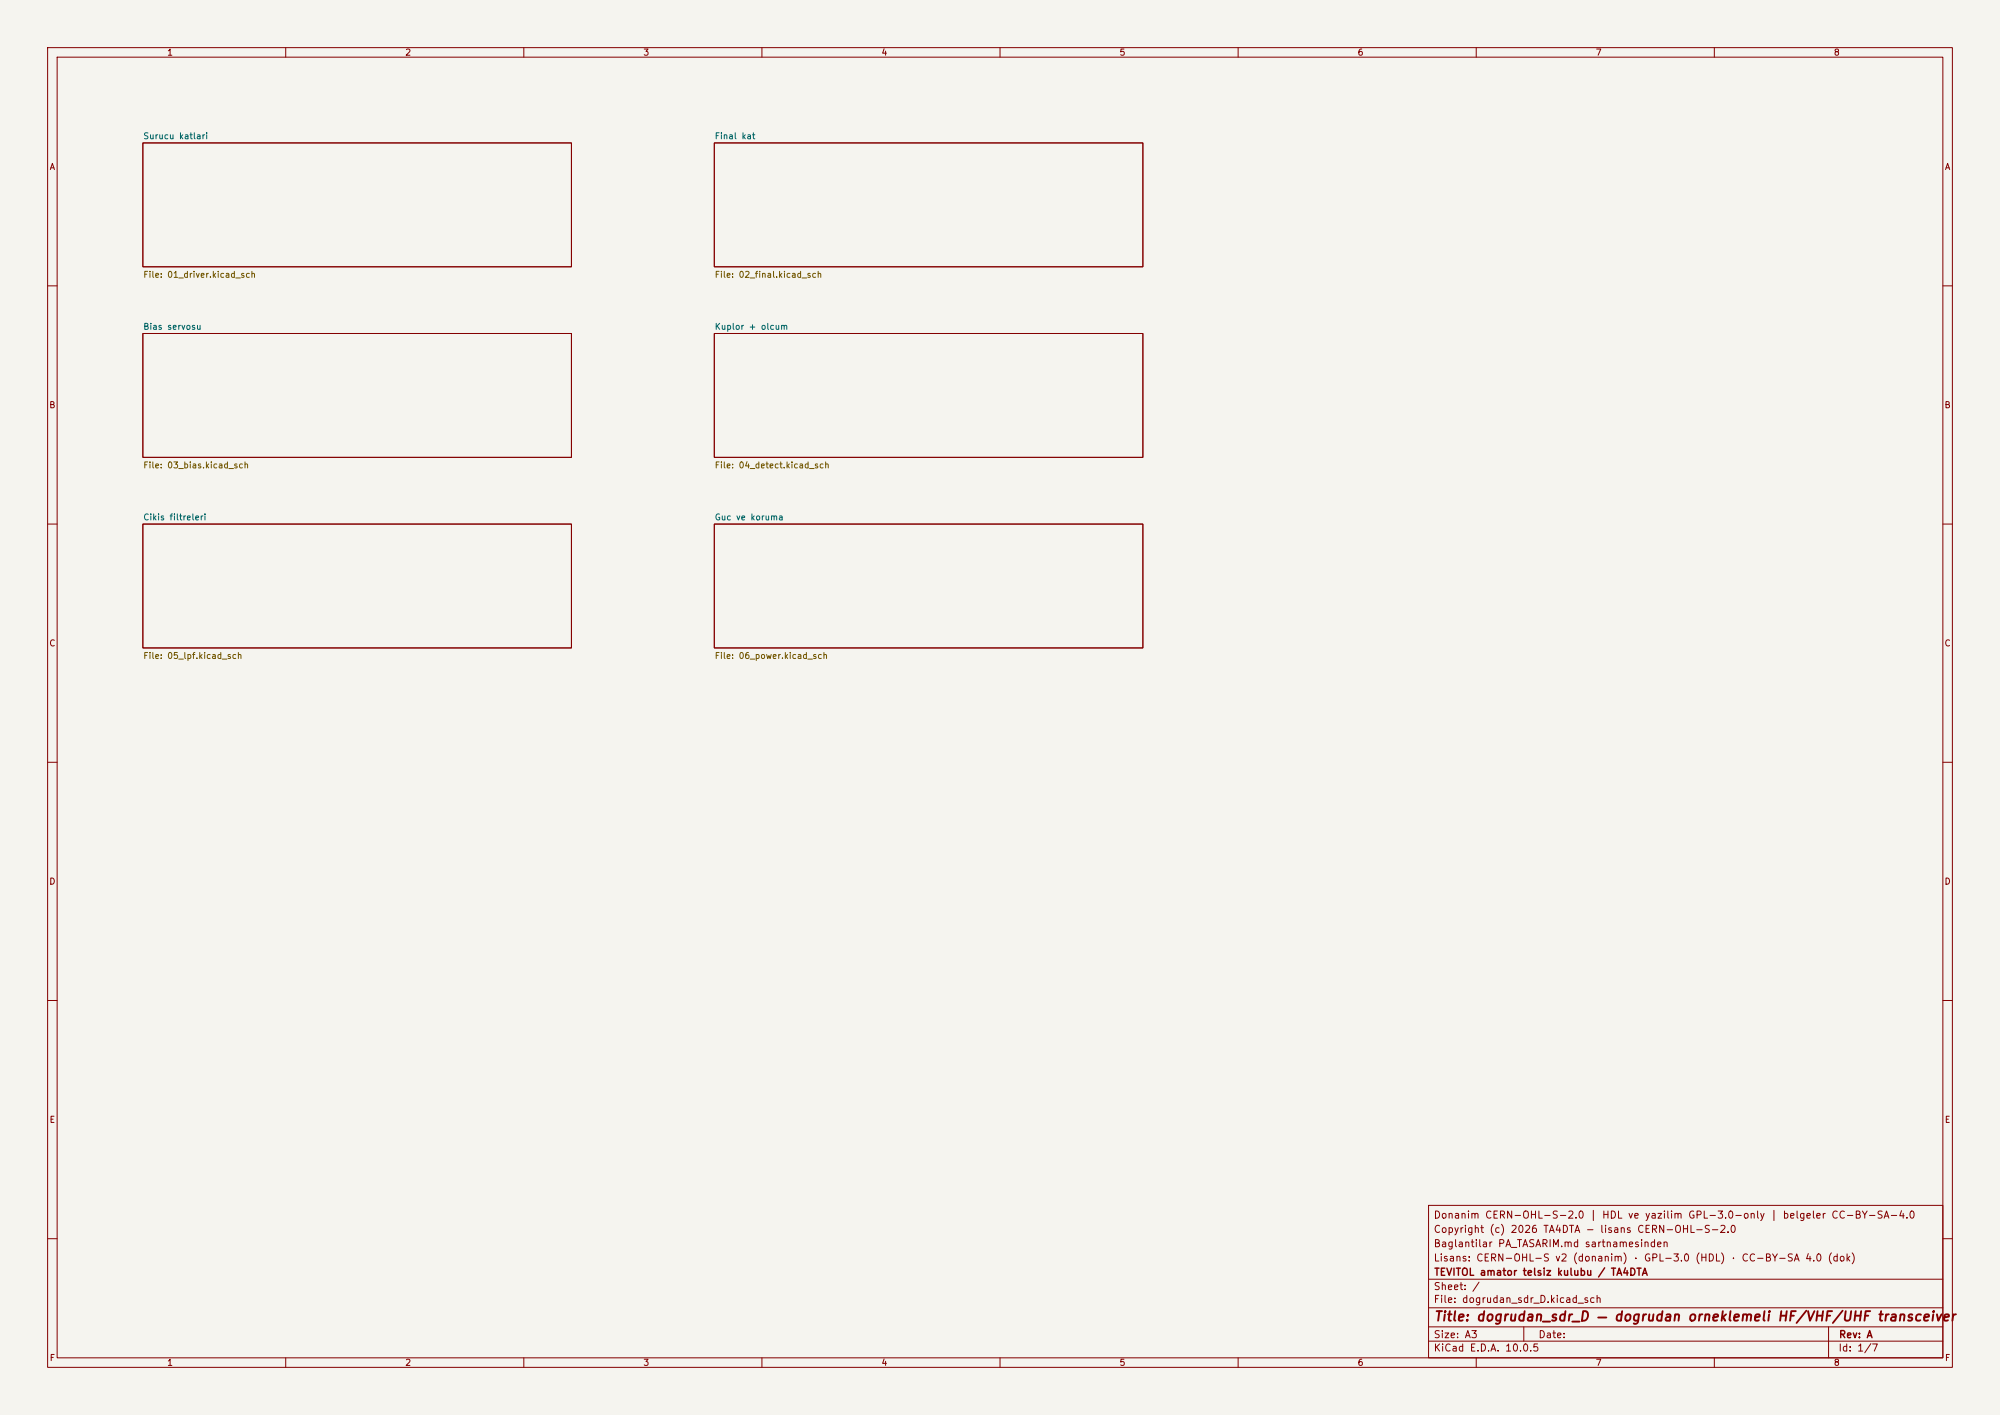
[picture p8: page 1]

Final kat File: 02_final.kicad_sch Bias servosu

File: 04_detect.kicad_sch Cikis filtreleri File: 05_lpf.kicad_sch

Donanim CERN-OHL-S-2.0 | HDL ve yazilim GPL-3.0-only | belgeler CC-BY-SA-4.0
Copyright (c) 2026 TA4DTA - lisans CERN-OHL-S-2.0
Baglantilar PA_TASARIM.md sartnamesinden
Lisans: CERN-OHL-S v2 (donanim) · GPL-3.0 (HDL) · CC-BY-SA 4.0 (dok)
TEVITOL amator telsiz kulubu / TA4DTA
Sheet: /
File: dogrudan_sdr_D.kicad_sch
Title: dogrudan_sdr_D — dogrudan orneklemeli HF/VHF/UHF transceiver

Size: A3 | Rev: A
KiCad E.D.A. 10.0.5 | Id: 1/7 | F Date:

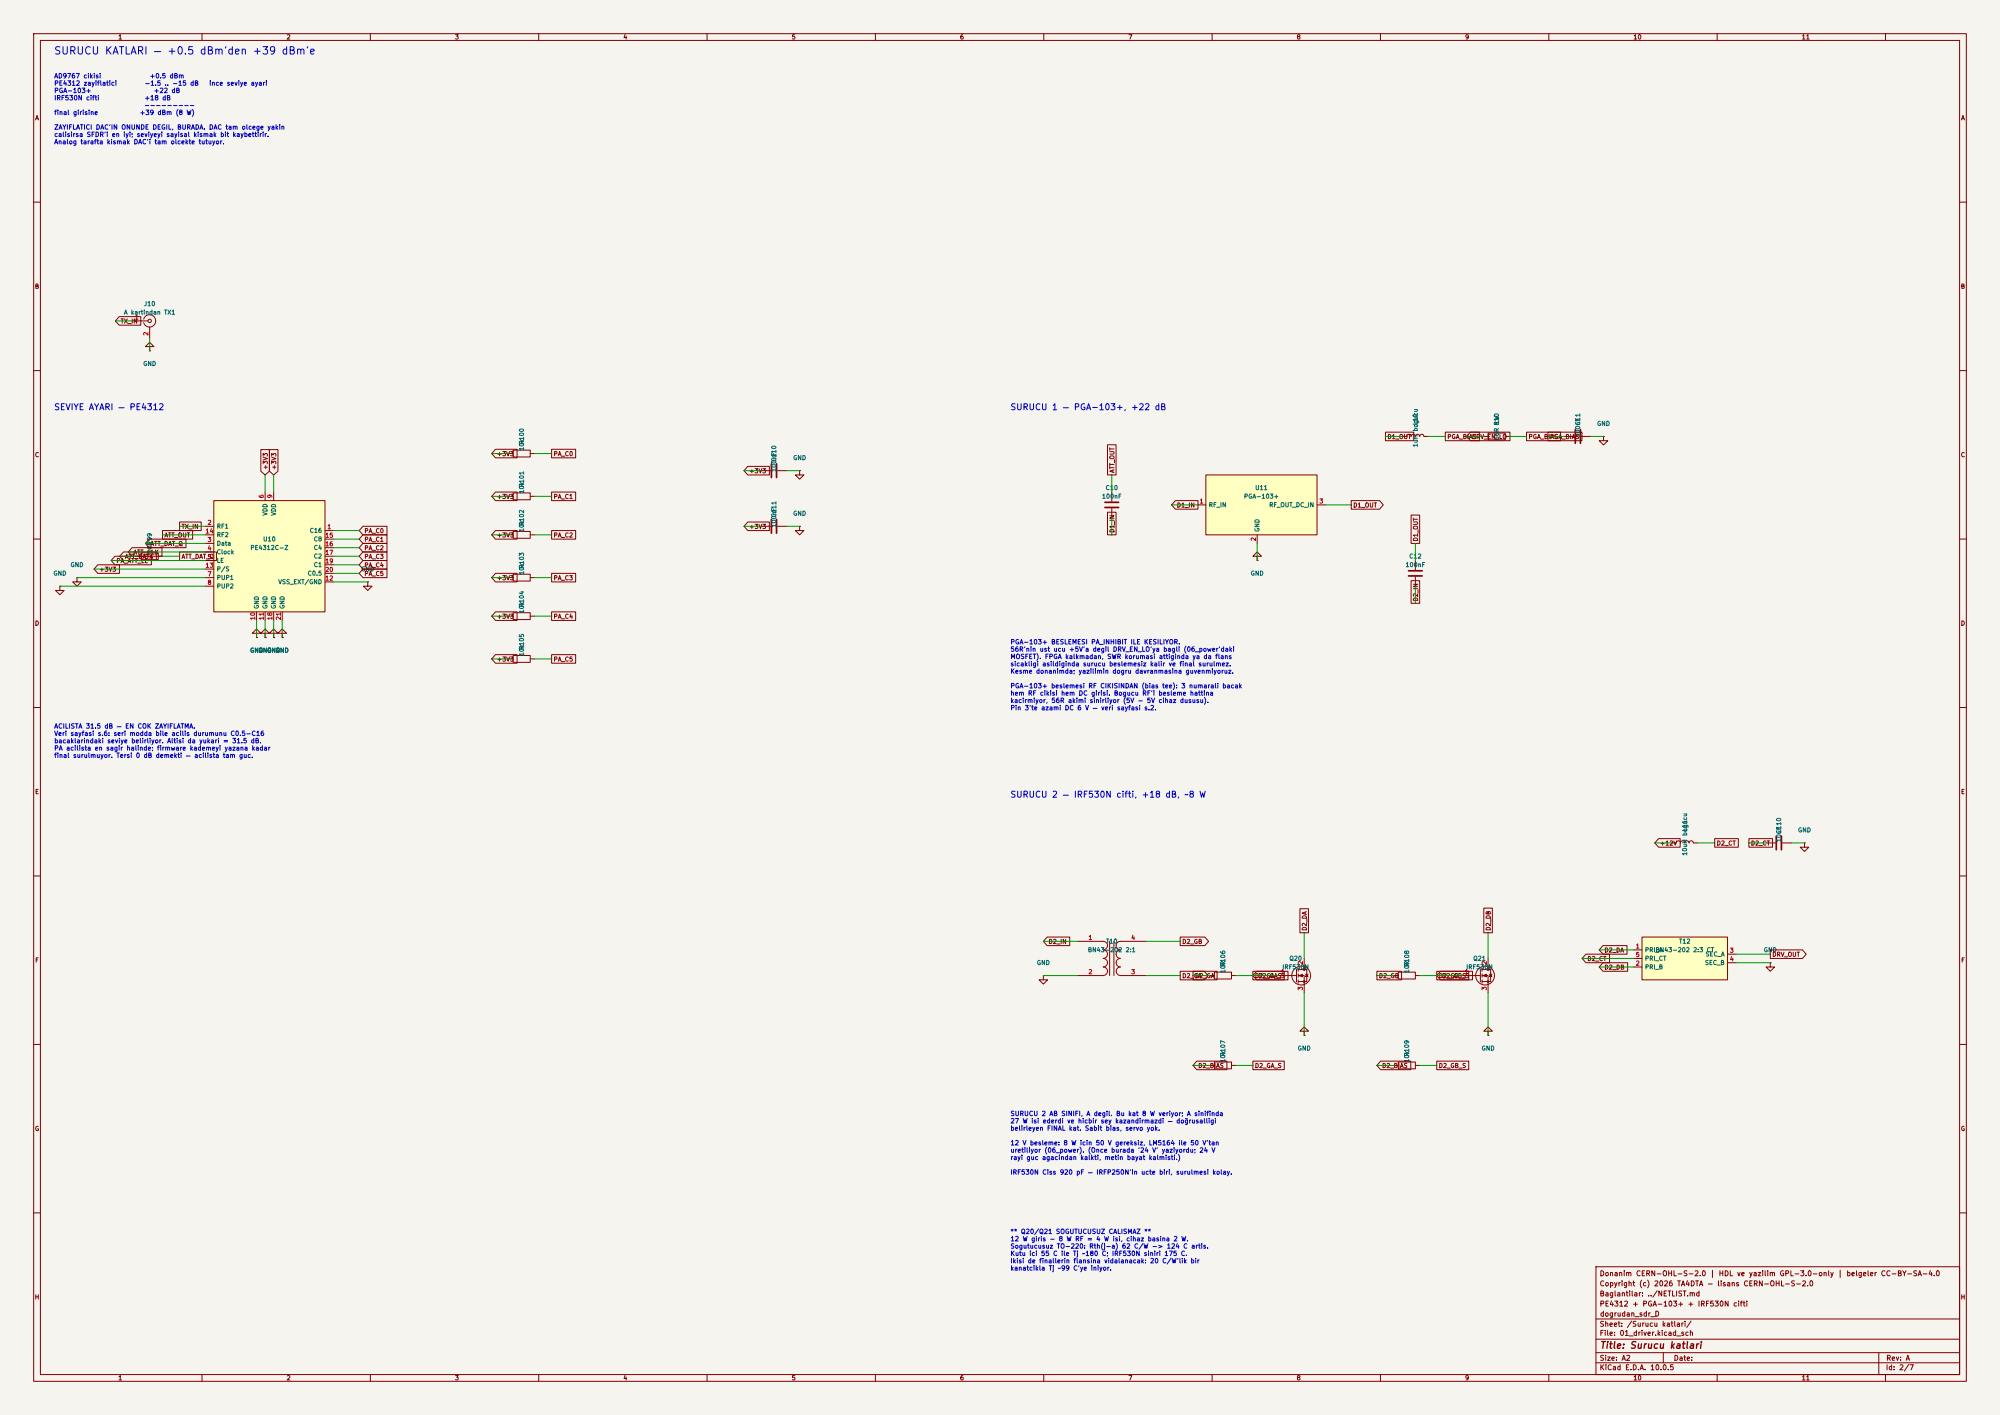
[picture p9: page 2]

SURUCU KATLARI — +0.5 dBm'den +39 dBm'e

calisirsa SFDR'i en iyi; seviyeyi sayisal kismak bit kaybettirir.
Analog tarafta kismak DAC'i tam olcekte tutuyor.

PGA-103+ BESLEMESI PA_INHIBIT ILE KESILIYOR. 56R'nin ust ucu +5V'a degil DRV_EN_LO'ya bagli (06_power'daki MOSFET). FPGA kalkmadan, SWR korumasi attiginda ya da flans

sicakligi asildiginda surucu beslemesiz kalir ve final surulmez. Kesme donanimda; yazilimin dogru davranmasina guvenmiyoruz. PGA-103+ beslemesi RF CIKISINDAN (bias tee): 3 numarali bacak hem RF cikisi hem DC girisi. Bogucu RF'i besleme hattina

kacirmiyor, 56R akimi sinirliyor (5V - 5V cihaz dususu). Pin 3'te azami DC 6 V — veri sayfasi s.2.

ACILISTA 31.5 dB — EN COK ZAYIFLATMA. Veri sayfasi s.6: seri modda bile acilis durumunu C0.5-C16

bacaklarindaki seviye belirliyor. Altisi da yukari = 31.5 dB. PA acilista en sagir halinde; firmware kademeyi yazana kadar

Donanim CERN-OHL-S-2.0 | HDL ve yazilim GPL-3.0-only | belgeler CC-BY-SA-4.0 L11 10uH bogucu

SURUCU 2 AB SINIFI, A degil. Bu kat 8 W veriyor; A sinifinda 27 W isi ederdi ve hicbir sey kazandirmazdi — doğrusalligi

belirleyen FINAL kat. Sabit bias, servo yok. 12 V besleme: 8 W icin 50 V gereksiz, LM5164 ile 50 V'tan

uretiliyor (06_power). (Once burada '24 V' yaziyordu; 24 V
rayi guc agacindan kalkti, metin bayat kalmisti.)

IRF530N Ciss 920 pF — IRFP250N'in ucte biri, surulmesi kolay. ** Q20/Q21 SOGUTUCUSUZ CALISMAZ ** 12 W giris - 8 W RF = 4 W isi, cihaz basina 2 W. Sogutucusuz TO-220: Rth(j-a) 62 C/W -> 124 C artis. Kutu ici 55 C ile Tj ~180 C; IRF530N siniri 175 C.

Ikisi de finallerin flansina vidalanacak: 20 C/W'lik bir kanatcikla Tj ~99 C'ye iniyor.

Copyright (c) 2026 TA4DTA - lisans CERN-OHL-S-2.0
Baglantilar: ../NETLIST.md
PE4312 + PGA-103+ + IRF530N cifti
dogrudan_sdr_D
Sheet: /Surucu katlari/
File: 01_driver.kicad_sch
Title: Surucu katlari

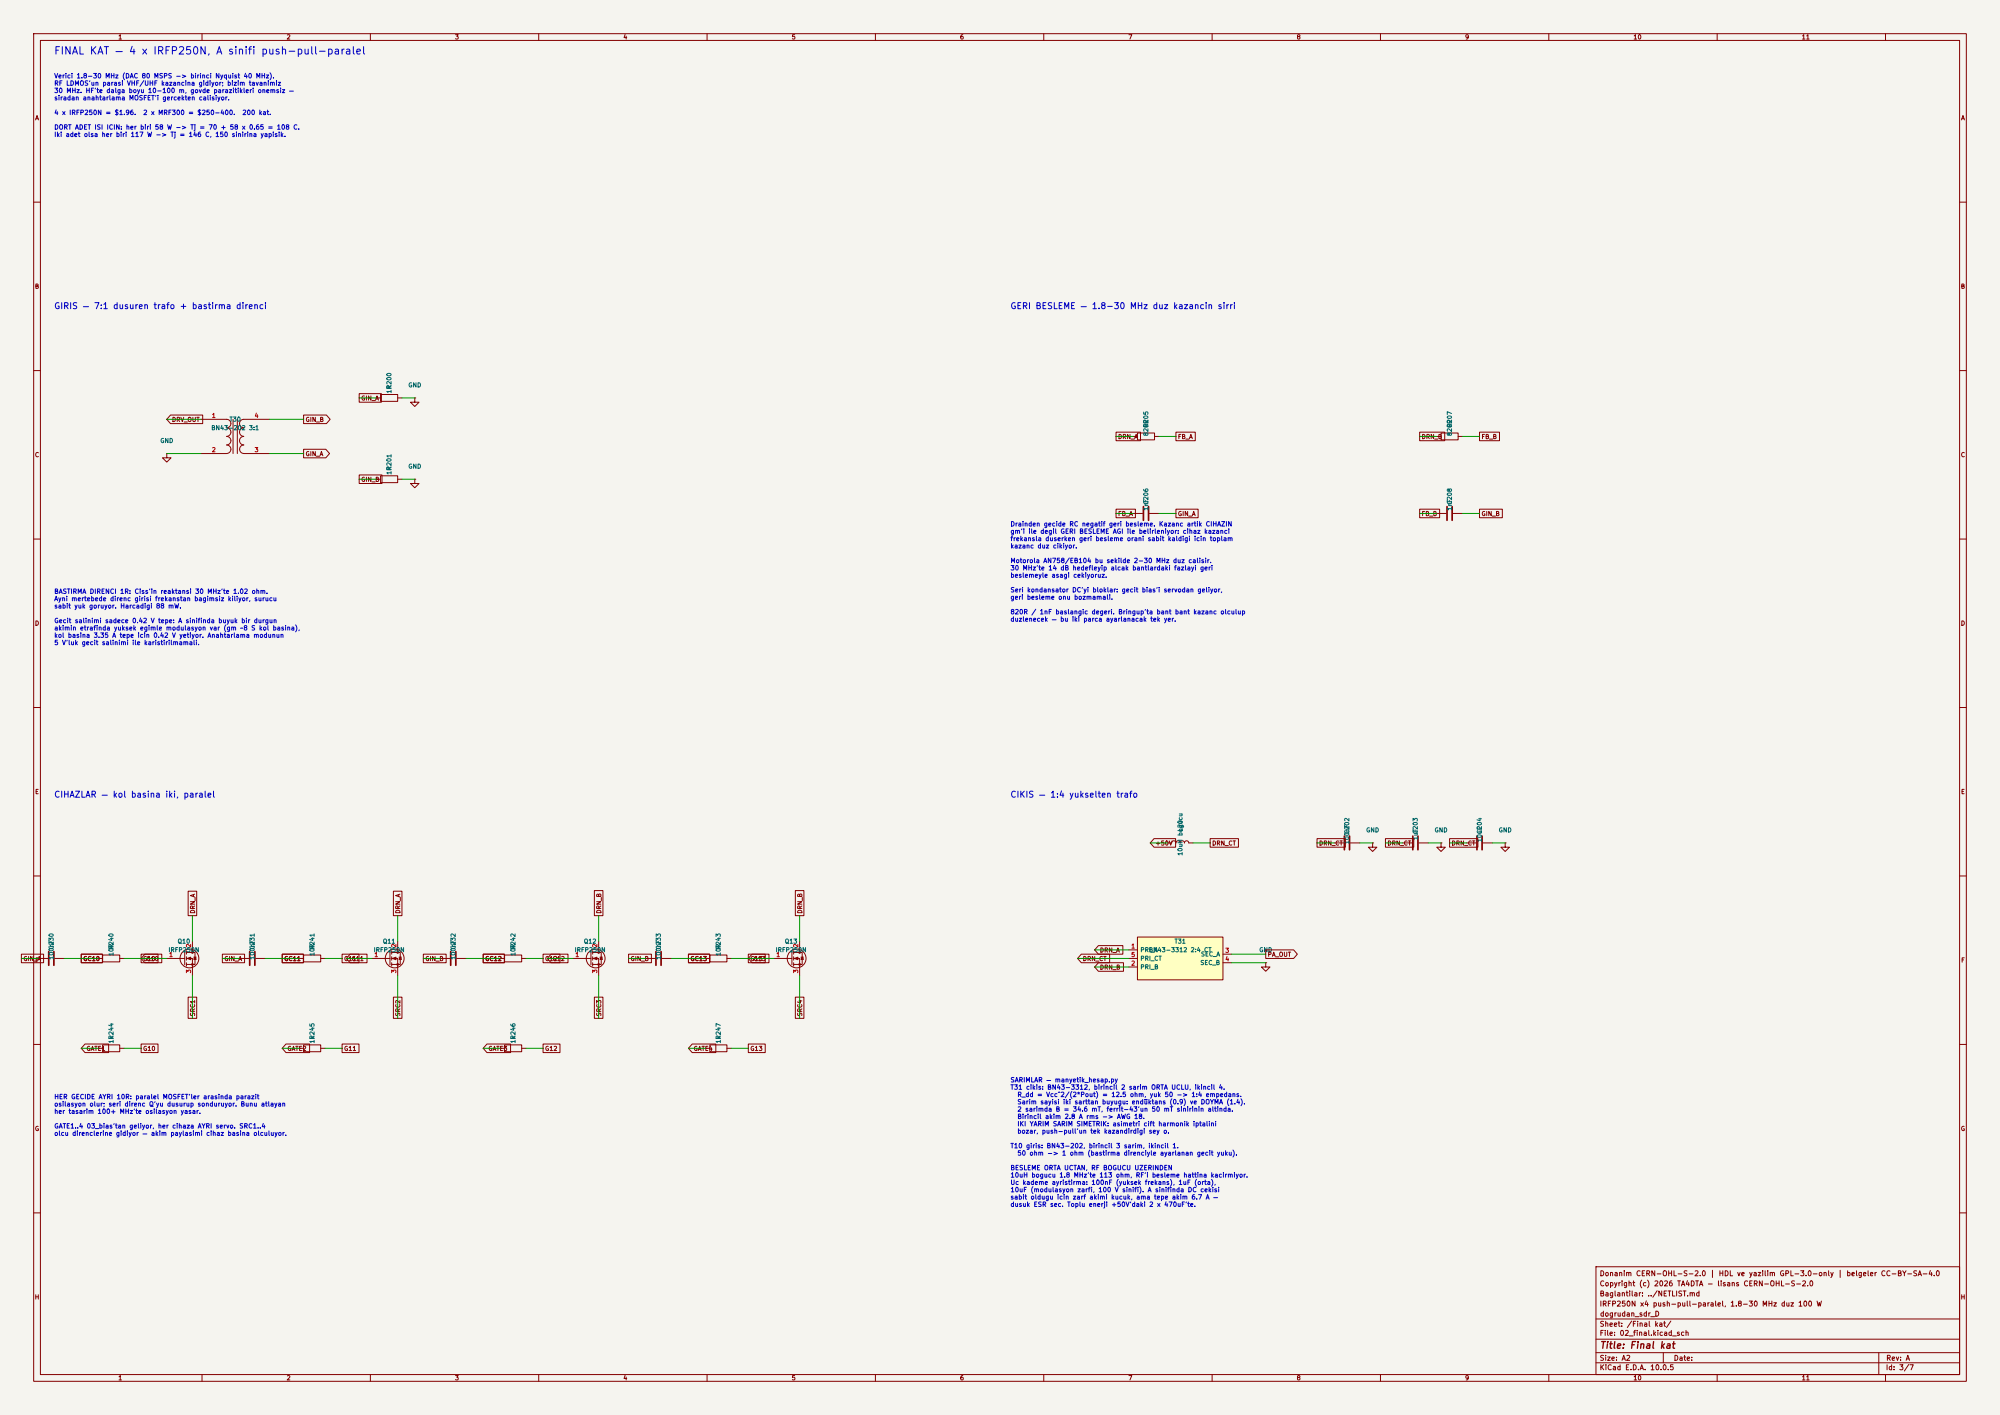
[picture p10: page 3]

FINAL KAT — 4 x IRFP250N, A sinifi push-pull-paralel

Verici 1.8-30 MHz (DAC 80 MSPS -> birinci Nyquist 40 MHz). RF LDMOS'un parasi VHF/UHF kazancina gidiyor; bizim tavanimiz 30 MHz. HF'te dalga boyu 10-100 m, govde parazitikleri onemsiz —

Iki adet olsa her biri 117 W -> Tj = 146 C, 150 sinirina yapisik.

GERI BESLEME — 1.8-30 MHz duz kazancin sirri Drainden gecide RC negatif geri besleme. Kazanc artik CIHAZIN

gm'i ile degil GERI BESLEME AGI ile belirleniyor: cihaz kazanci frekansla duserken geri besleme orani sabit kaldigi icin toplam

kazanc duz cikiyor. Motorola AN758/EB104 bu sekilde 2-30 MHz duz calisir. 30 MHz'te 14 dB hedefleyip alcak bantlardaki fazlayi geri

beslemeyle asagi cekiyoruz. Seri kondansator DC'yi bloklar: gecit bias'i servodan geliyor,

sabit yuk goruyor. Harcadigi 88 mW. Gecit salinimi sadece 0.42 V tepe: A sinifinda buyuk bir durgun

geri besleme onu bozmamali. 820R / 1nF baslangic degeri. Bringup'ta bant bant kazanc olculup

duzlenecek — bu iki parca ayarlanacak tek yer. CIKIS — 1:4 yukselten trafo

akimin etrafinda yuksek egimle modulasyon var (gm ~8 S kol basina), kol basina 3.35 A tepe icin 0.42 V yetiyor. Anahtarlama modunun 5 V'luk gecit salinimi ile karistirilmamali. CIHAZLAR — kol basina iki, paralel

SARIMLAR — manyetik_hesap.py
T31 cikis: BN43-3312, birincil 2 sarim ORTA UCLU, ikincil 4. R_dd = Vcc^2/(2*Pout) = 12.5 ohm, yuk 50 -> 1:4 empedans. Sarim sayisi iki sarttan buyugu: endüktans (0.9) ve DOYMA (1.4). 2 sarimda B = 34.6 mT, ferrit-43'un 50 mT sinirinin altinda. Birincil akim 2.8 A rms -> AWG 18.

HER GECIDE AYRI 10R: paralel MOSFET'ler arasinda parazit
osilasyon olur; seri direnc Q'yu dusurup sonduruyor. Bunu atlayan
her tasarim 100+ MHz'te osilasyon yasar. GATE1..4 03_bias'tan geliyor, her cihaza AYRI servo. SRC1..4
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

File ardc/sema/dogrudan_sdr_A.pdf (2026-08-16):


Donanim CERN-OHL-S-2.0 | HDL ve yazilim GPL-3.0-only | belgeler CC-BY-SA-4.0
Copyright (c) 2026 TA4DTA - lisans CERN-OHL-S-2.0
Baglantilar kicad/NETLIST.md sartnamesinden
Lisans: CERN-OHL-S v2 (donanim) · GPL-3.0 (HDL) · CC-BY-SA 4.0 (dok)
TEVITOL amator telsiz kulubu / TA4DTA
Sheet: /
File: dogrudan_sdr_A.kicad_sch
Title: dogrudan_sdr_A — dogrudan orneklemeli HF/VHF/UHF transceiver

Size: A3 | Rev: A
KiCad E.D.A. 10.0.5 | Id: 1/9 | F Date:

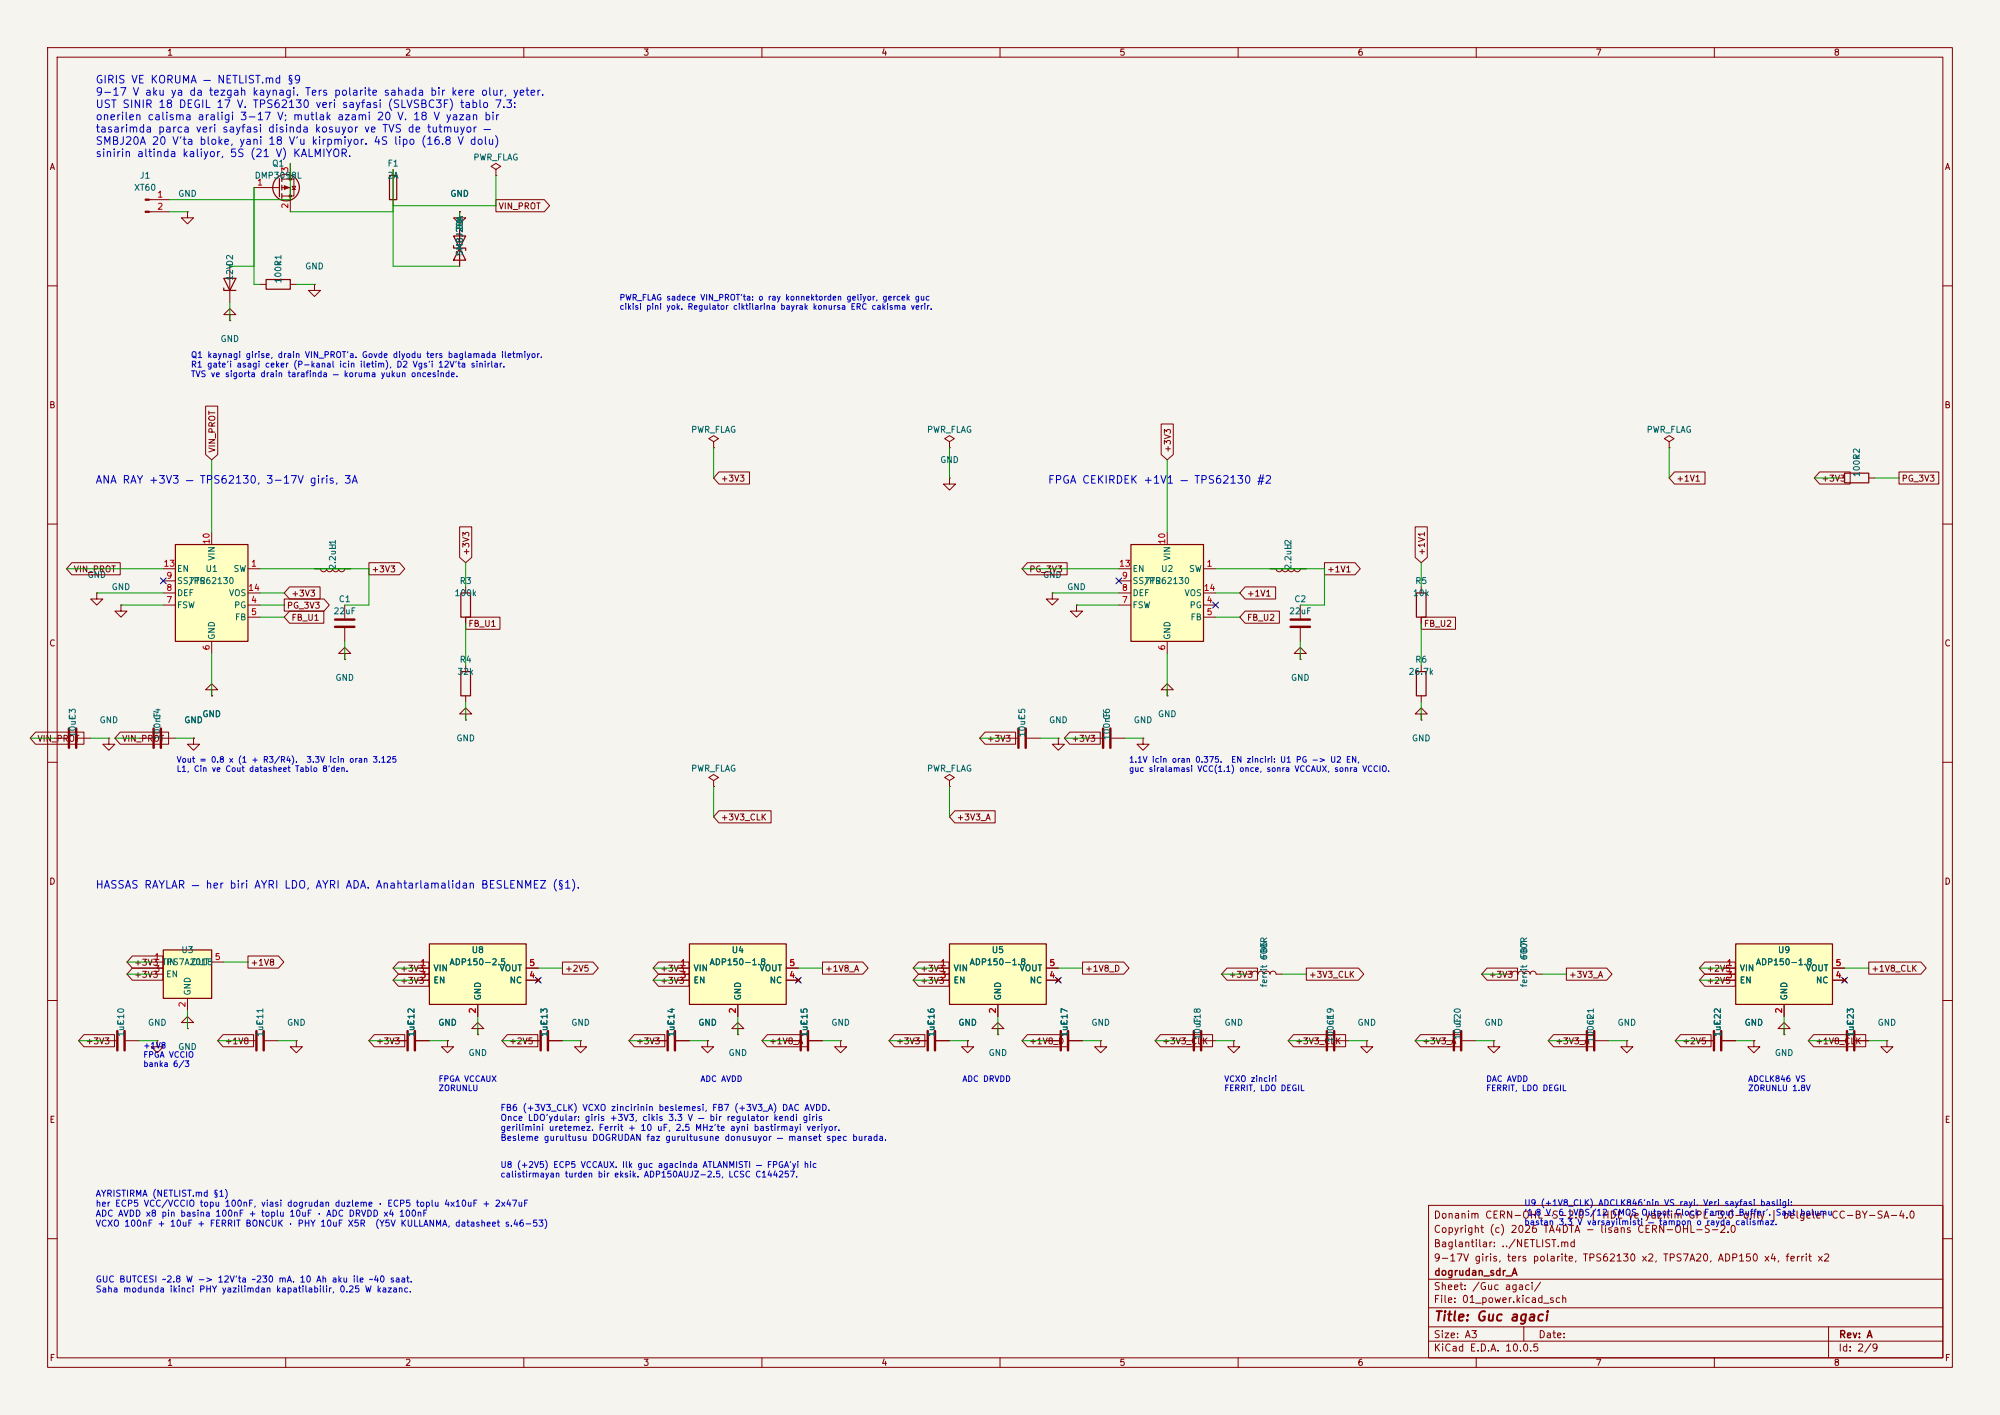
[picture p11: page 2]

cikisi pini yok. Regulator ciktilarina bayrak konursa ERC cakisma verir. GIRIS VE KORUMA — NETLIST.md §9
9-17 V aku ya da tezgah kaynagi. Ters polarite sahada bir kere olur, yeter.
UST SINIR 18 DEGIL 17 V. TPS62130 veri sayfasi (SLVSBC3F) tablo 7.3:
onerilen calisma araligi 3-17 V; mutlak azami 20 V. 18 V yazan bir
tasarimda parca veri sayfasi disinda kosuyor ve TVS de tutmuyor —
SMBJ20A 20 V'ta bloke, yani 18 V'u kirpmiyor. 4S lipo (16.8 V dolu)
sinirin altinda kaliyor, 5S (21 V) KALMIYOR.

PWR_FLAG sadece VIN_PROT'ta: o ray konnektorden geliyor, gercek guc

FERRIT, LDO DEGIL Vout = 0.8 x (1 + R3/R4). 3.3V icin oran 3.125

1.1V icin oran 0.375. EN zinciri: U1 PG -> U2 EN, guc siralamasi VCC(1.1) once, sonra VCCAUX, sonra VCCIO. FPGA VCCAUX

L1, Cin ve Cout datasheet Tablo 8'den. GUC BUTCESI ~2.8 W -> 12V'ta ~230 mA. 10 Ah aku ile ~40 saat. Saha modunda ikinci PHY yazilimdan kapatilabilir, 0.25 W kazanc. AYRISTIRMA (NETLIST.md §1) her ECP5 VCC/VCCIO topu 100nF, viasi dogrudan duzleme · ECP5 toplu 4x10uF + 2x47uF

Donanim CERN-OHL-S-2.0 | HDL ve yazilim GPL-3.0-only | belgeler CC-BY-SA-4.0 C23 1uF

VCXO 100nF + 10uF + FERRIT BONCUK · PHY 10uF X5R (Y5V KULLANMA, datasheet s.46-53) +1V8

gerilimini uretemez. Ferrit + 10 uF, 2.5 MHz'te ayni bastirmayi veriyor. Besleme gurultusu DOGRUDAN faz gurultusune donusuyor — manset spec burada. ADC AVDD

calistirmayan turden bir eksik. ADP150AUJZ-2.5, LCSC C144257. FB6 (+3V3_CLK) VCXO zincirinin beslemesi, FB7 (+3V3_A) DAC AVDD. Once LDO'ydular: giris +3V3, cikis 3.3 V — bir regulator kendi giris

U8 (+2V5) ECP5 VCCAUX. Ilk guc agacinda ATLANMISTI — FPGA'yi hic

U9 (+1V8_CLK) ADCLK846'nin VS rayi. Veri sayfasi basligi:
'1.8 V, 6 LVDS/12 CMOS Output Clock Fanout Buffer'. Saat bolumu

ADC AVDD x8 pin basina 100nF + toplu 10uF · ADC DRVDD x4 100nF

Copyright (c) 2026 TA4DTA - lisans CERN-OHL-S-2.0
Baglantilar: ../NETLIST.md
9-17V giris, ters polarite, TPS62130 x2, TPS7A20, ADP150 x4, ferrit x2
dogrudan_sdr_A
Sheet: /Guc agaci/
File: 01_power.kicad_sch
Title: Guc agaci

Size: A3 | Rev: A

F Date:

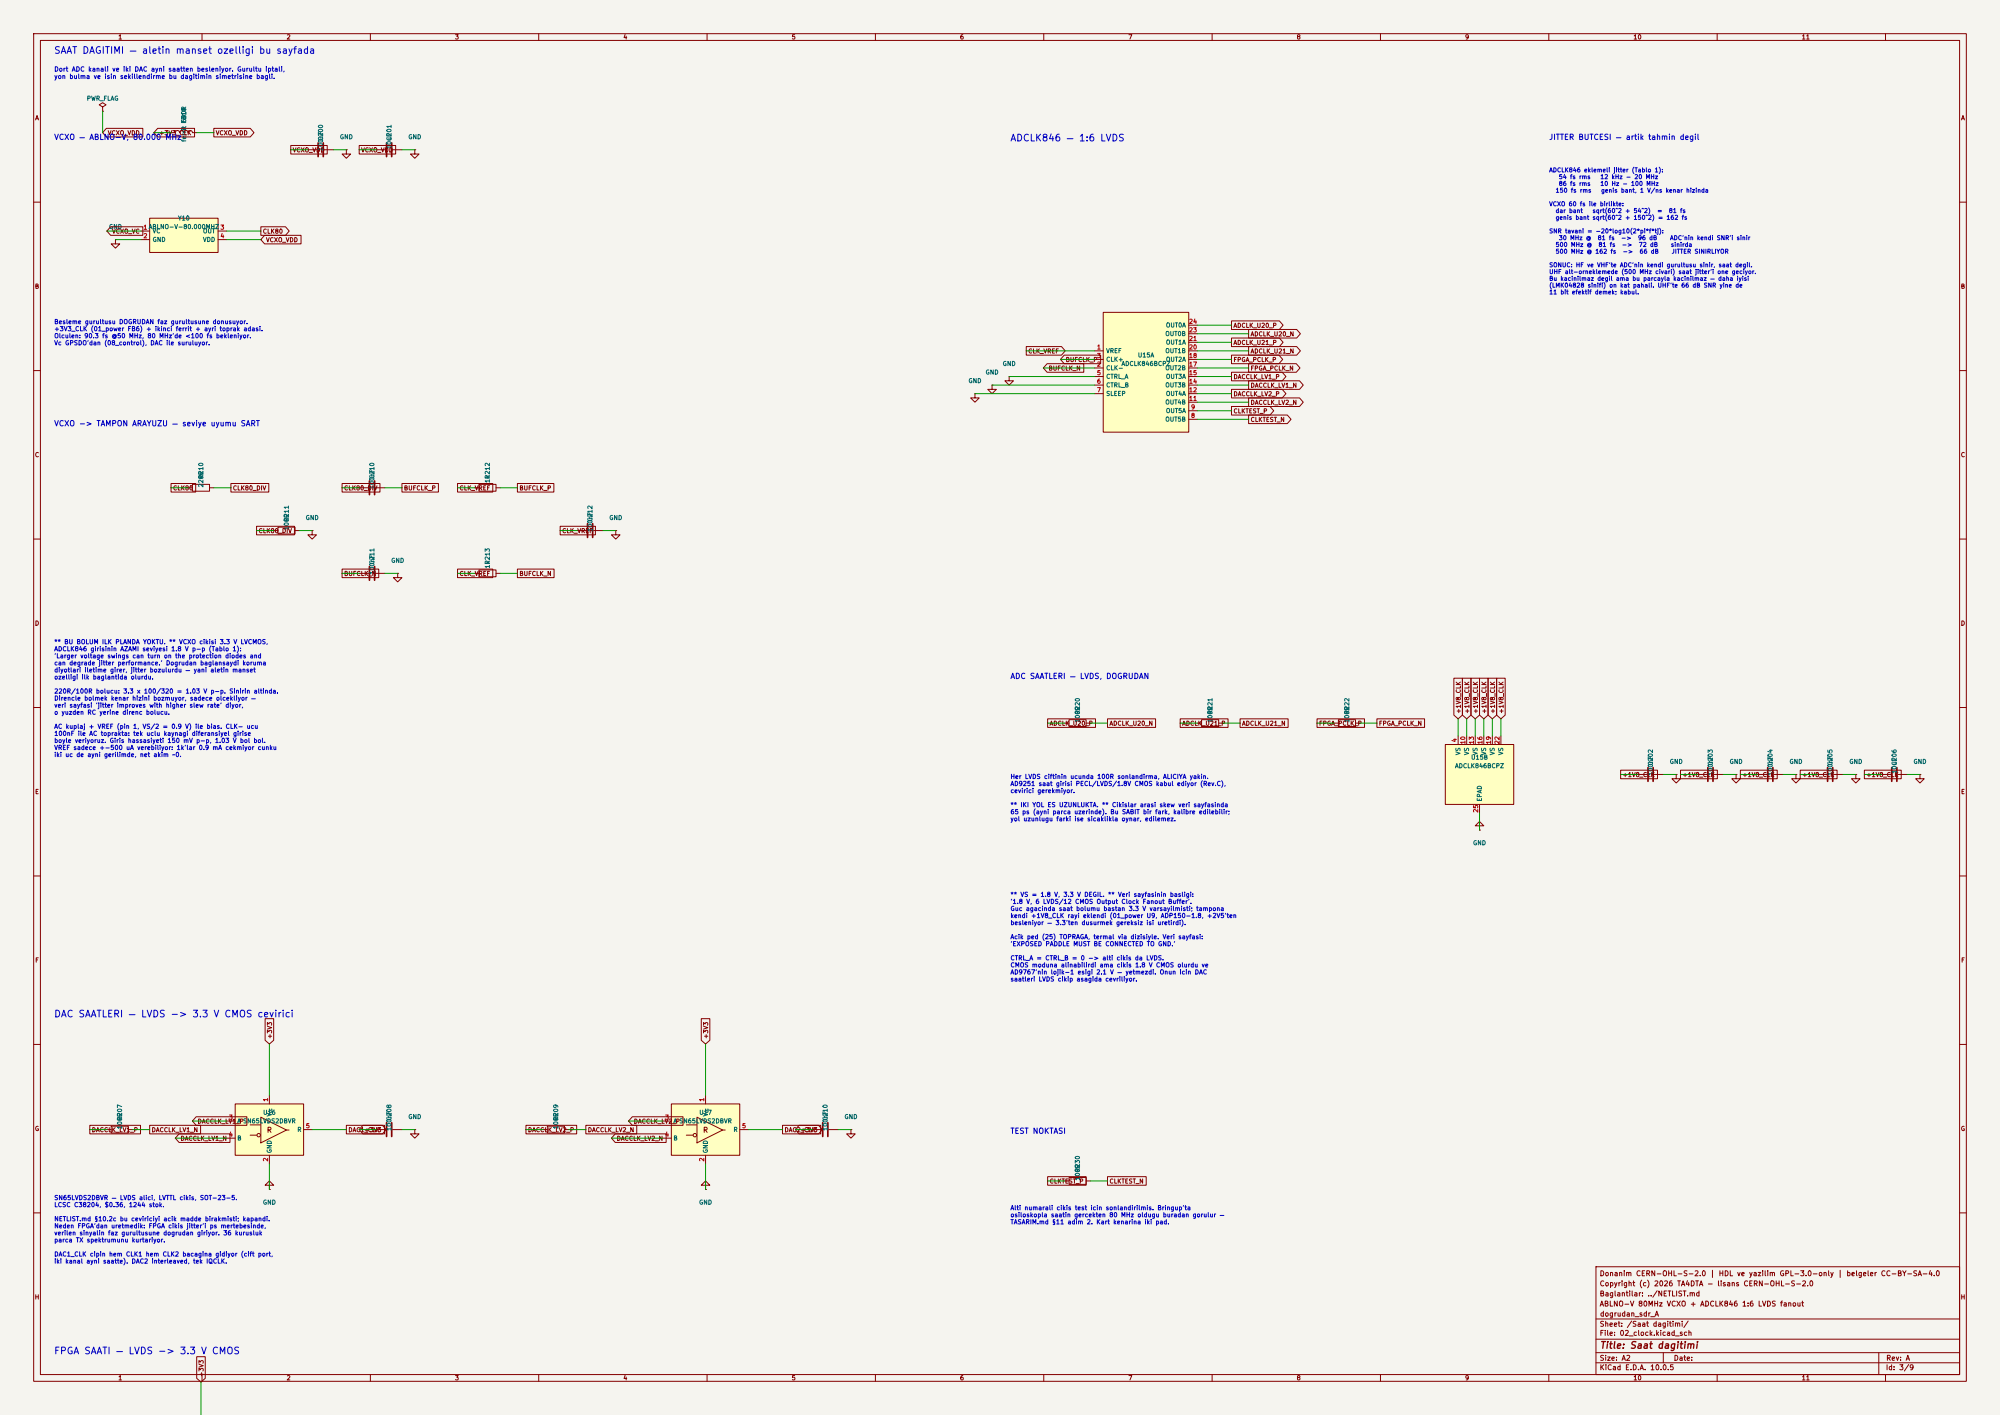
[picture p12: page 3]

(LMK04828 sinifi) on kat pahali. UHF'te 66 dB SNR yine de 11 bit efektif demek; kabul. SAAT DAGITIMI — aletin manset ozelligi bu sayfada

VCXO — ABLNO-V, 80.000 MHz Dort ADC kanali ve iki DAC ayni saatten besleniyor. Gurultu iptali, yon bulma ve isin sekillendirme bu dagitimin simetrisine bagli.

SONUC: HF ve VHF'te ADC'nin kendi gurultusu sinir, saat degil. UHF alt-orneklemede (500 MHz civari) saat jitter'i one geciyor. Bu kacinilmaz degil ama bu parcayla kacinilmaz — daha iyisi

Besleme gurultusu DOGRUDAN faz gurultusune donusuyor. +3V3_CLK (01_power FB6) + ikinci ferrit + ayri toprak adasi. Olculen: 90.3 fs @50 MHz, 80 MHz'de <100 fs bekleniyor. Vc GPSDO'dan (08_control), DAC ile suruluyor. ** BU BOLUM ILK PLANDA YOKTU. ** VCXO cikisi 3.3 V LVCMOS, ADCLK846 girisinin AZAMI seviyesi 1.8 V p-p (Tablo 1):

VCXO -> TAMPON ARAYUZU — seviye uyumu SART

'Larger voltage swings can turn on the protection diodes and
can degrade jitter performance.' Dogrudan baglansaydi koruma
diyotlari iletime girer, jitter bozulurdu — yani aletin manset ozelligi ilk baglantida olurdu. 220R/100R bolucu: 3.3 x 100/320 = 1.03 V p-p. Sinirin altinda. Direncle bolmek kenar hizini bozmuyor, sadece olcekliyor —

ADC SAATLERI — LVDS, DOGRUDAN

veri sayfasi 'jitter improves with higher slew rate' diyor, o yuzden RC yerine direnc bolucu. AC kuplaj + VREF (pin 1, VS/2 = 0.9 V) ile bias. CLK- ucu 100nF ile AC toprakta: tek uclu kaynagi diferansiyel girise

4 VS 10 VS 13 VS 16 VS 19 VS 22 EPAD 25 U15B

boyle veriyoruz. Giris hassasiyeti 150 mV p-p, 1.03 V bol bol. VREF sadece +-500 uA verebiliyor: 1k'lar 0.9 mA cekmiyor cunku

iki uc de ayni gerilimde, net akim ~0.
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

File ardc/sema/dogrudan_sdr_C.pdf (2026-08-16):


Donanim CERN-OHL-S-2.0 | HDL ve yazilim GPL-3.0-only | belgeler CC-BY-SA-4.0
Copyright (c) 2026 TA4DTA - lisans CERN-OHL-S-2.0
Baglantilar kicad/NETLIST_C.md sartnamesinden
Lisans: CERN-OHL-S v2 (donanim) · GPL-3.0 (HDL) · CC-BY-SA 4.0 (dok)
TEVITOL amator telsiz kulubu / TA4DTA
Sheet: /
File: dogrudan_sdr_C.kicad_sch
Title: dogrudan_sdr_C — dogrudan orneklemeli HF/VHF/UHF transceiver

Size: A3 | Rev: A
KiCad E.D.A. 10.0.5 | Id: 1/7 | F Date:


Iki ray geliyor: VIN_PROT (9-17 V) ve +3V3, ikisi de A kartindan
kart arasi bagliktan. Burada uretilen tek sey role bobinlerinin +5V'u. +5V — role bobinleri

Donanim CERN-OHL-S-2.0 | HDL ve yazilim GPL-3.0-only | belgeler CC-BY-SA-4.0 C80 22uF GND

dusurmek 13 V x akim kadar isi demek. Kilitlenen role akimi darbeli ama darbe aninda 32 bobinden biri 21 mA cekiyor, ve firmware istese ard arda darbeleyebilir.

Copyright (c) 2026 TA4DTA - lisans CERN-OHL-S-2.0
Baglantilar: ../NETLIST.md
VIN_PROT -> +5V buck (role bobinleri), +3V3 A kartindan
dogrudan_sdr_C
Sheet: /Guc/
File: 01_power.kicad_sch
Title: Guc

Size: A3 | Rev: A

F Date:


KORUMA VE T/R — kanal basina ozdes zincir D101 SMBJ20A D110 SMBJ20A GND
GND D123 1N4148WS GND

genlik ve faz cevabi ayni degilse gurultu iptali, yon bulma ve
isin sekillendirme calismaz. Bu yuzden 'birine su, otekine bu' yok — ne yapiliyorsa dort kere yapiliyor.

T/R ROLESI KILITLENMEYEN — GUVENLIK
Filtre bankasindaki roleler kilitlenen (guc butcesi icin). T/R'da
tam tersi gerekiyor: kilitlenen role gucsuz kaldigi konumu KORUR,
yani guc kesilse ya da firmware cokse anten PA'ya bagli kalir ve alici girisine 100 W dusebilir. G6K-2F-Y (kilitlenmeyen) birakildiginda kendiliginden RX konumuna

doner. Guvenlik varsayilan durumdan gelmeli, yazilimdan degil. Bedeli: verirken 5 V / 28 mA = 140 mW. Ayni anda tek port verdigi

icin tek bobin. Kabul. 100k geciti asagi cekiyor: FPGA henuz kalkmamisken bile MOSFET kapali, role RX'te.

3 diyot limitleyici yakindaki verici, SUREKLI calisir, kilovolt gorurse olur Biri digerinin yerine gecmiyor. Okul istasyonunda kendi vericimiz ayni catida; ucu de gerekli.

yolunu anahtarliyor. PA'li porta gelince o portun T/R'i PA'nin
icinde oluyor. PA_TASARIM.md §6.

T/R rolesinin IKINCI kutbu bosta durmuyor: verirken RX girisini
topraga baglıyor. 100 W verirken komsu kanalin on ucunu korumanin

Donanim CERN-OHL-S-2.0 | HDL ve yazilim GPL-3.0-only | belgeler CC-BY-SA-4.0
Copyright (c) 2026 TA4DTA - lisans CERN-OHL-S-2.0
Baglantilar: ../NETLIST.md
gaz desarj + TVS + limitleyici + T/R rolesi, x4 kanal
dogrudan_sdr_C
Sheet: /Koruma + T/R/
File: 02_protect.kicad_sch
Title: Koruma + T/R


BANT FILTRESI BANKASI — 7 pozisyon x 4 kanal
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

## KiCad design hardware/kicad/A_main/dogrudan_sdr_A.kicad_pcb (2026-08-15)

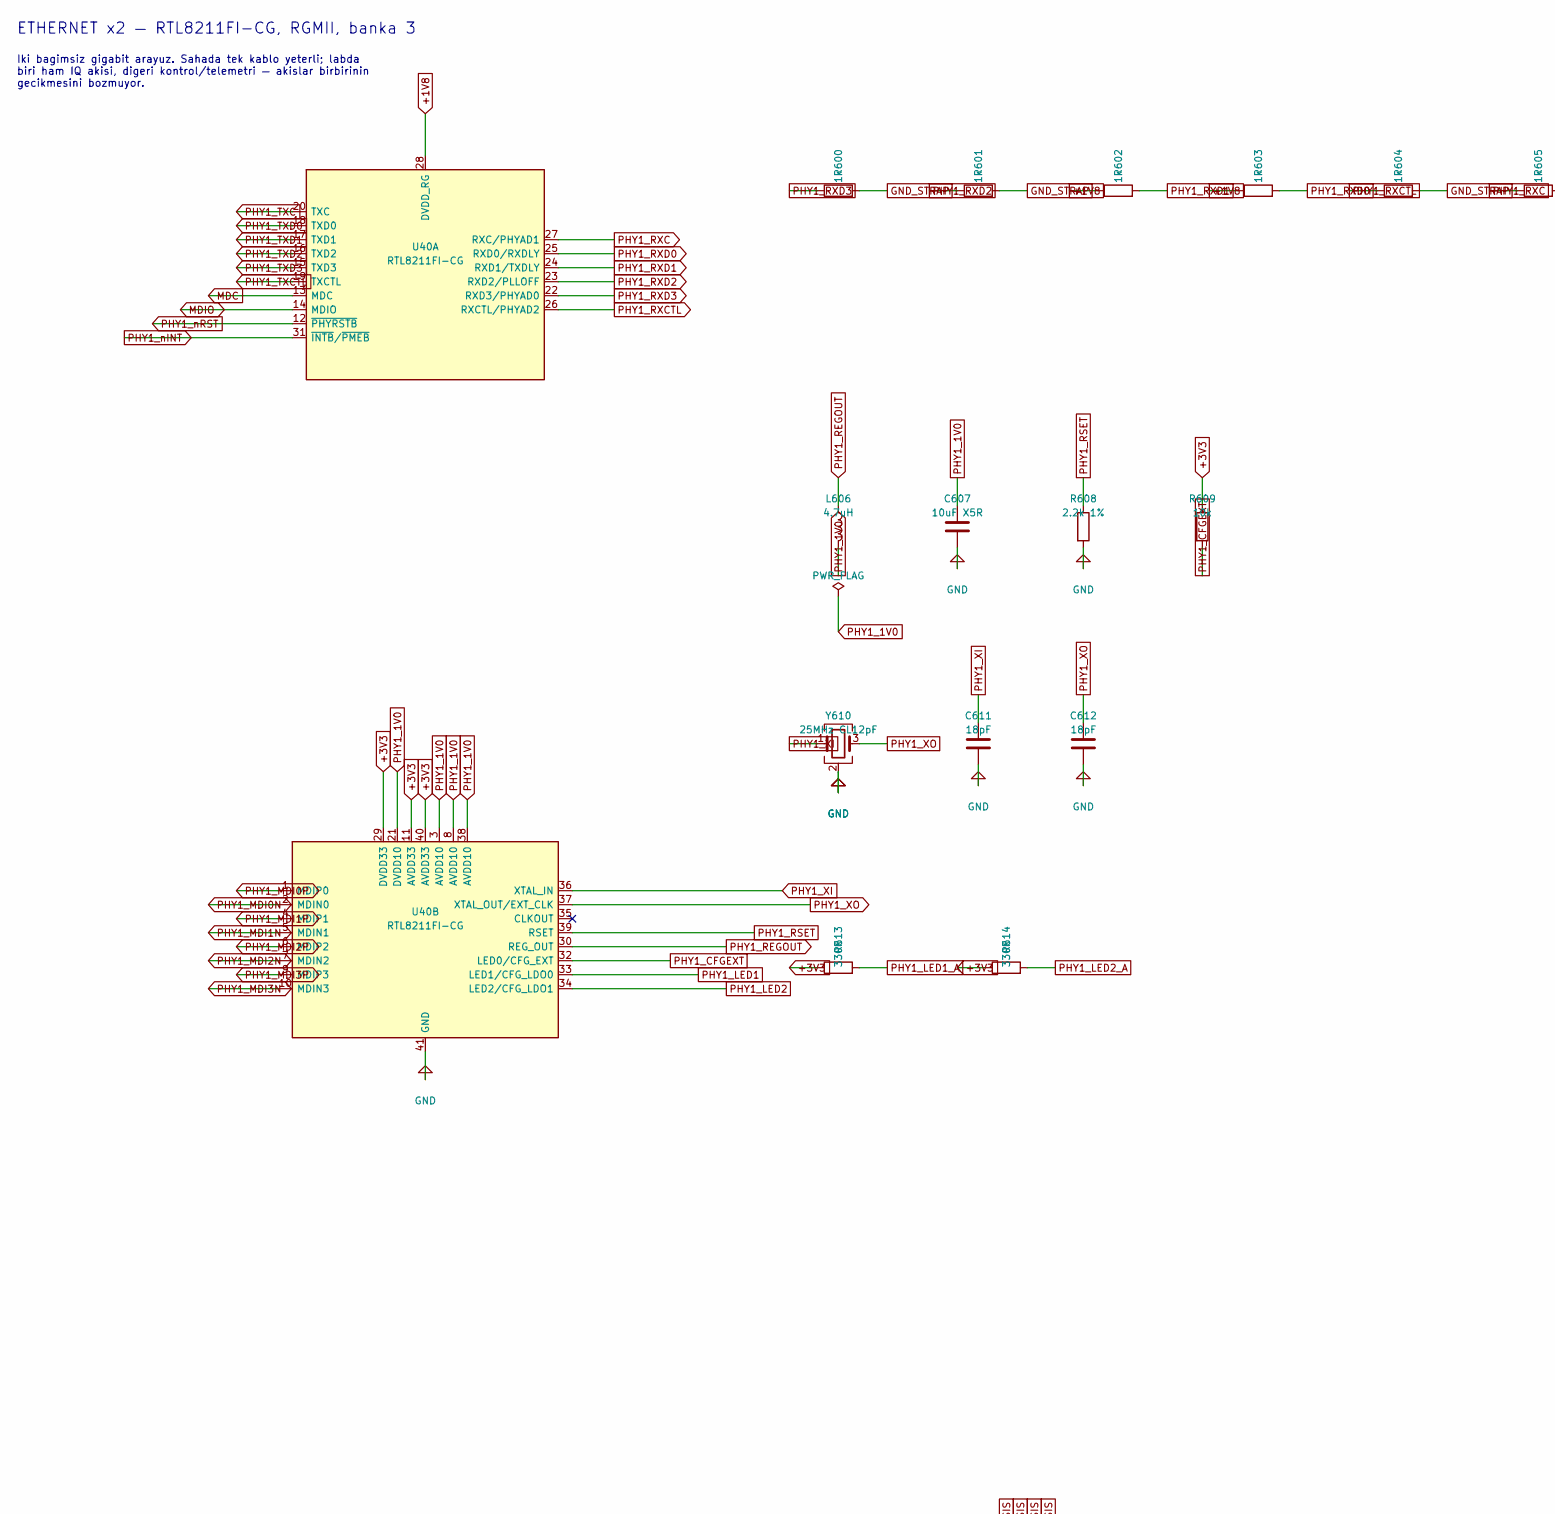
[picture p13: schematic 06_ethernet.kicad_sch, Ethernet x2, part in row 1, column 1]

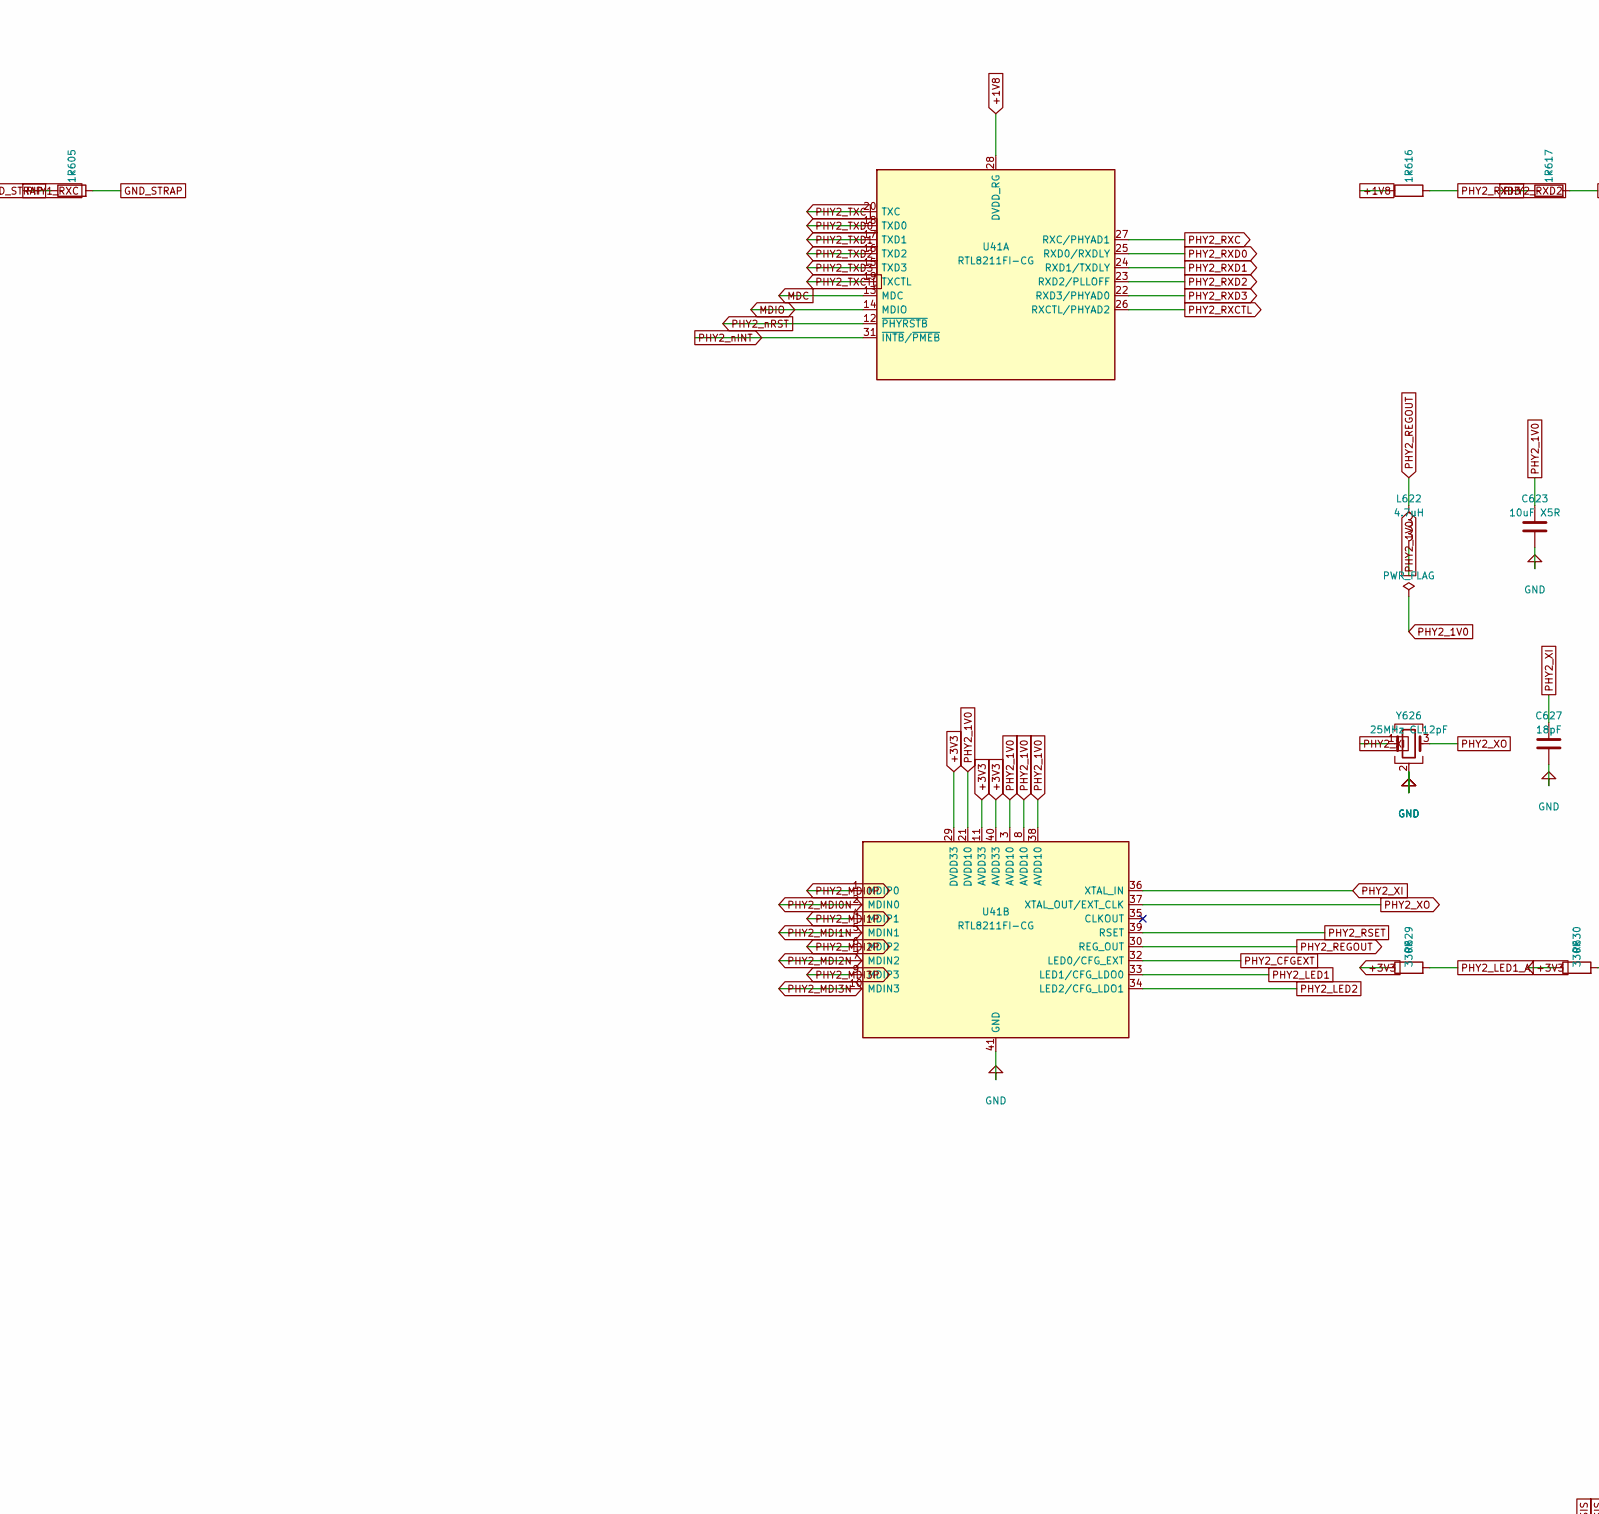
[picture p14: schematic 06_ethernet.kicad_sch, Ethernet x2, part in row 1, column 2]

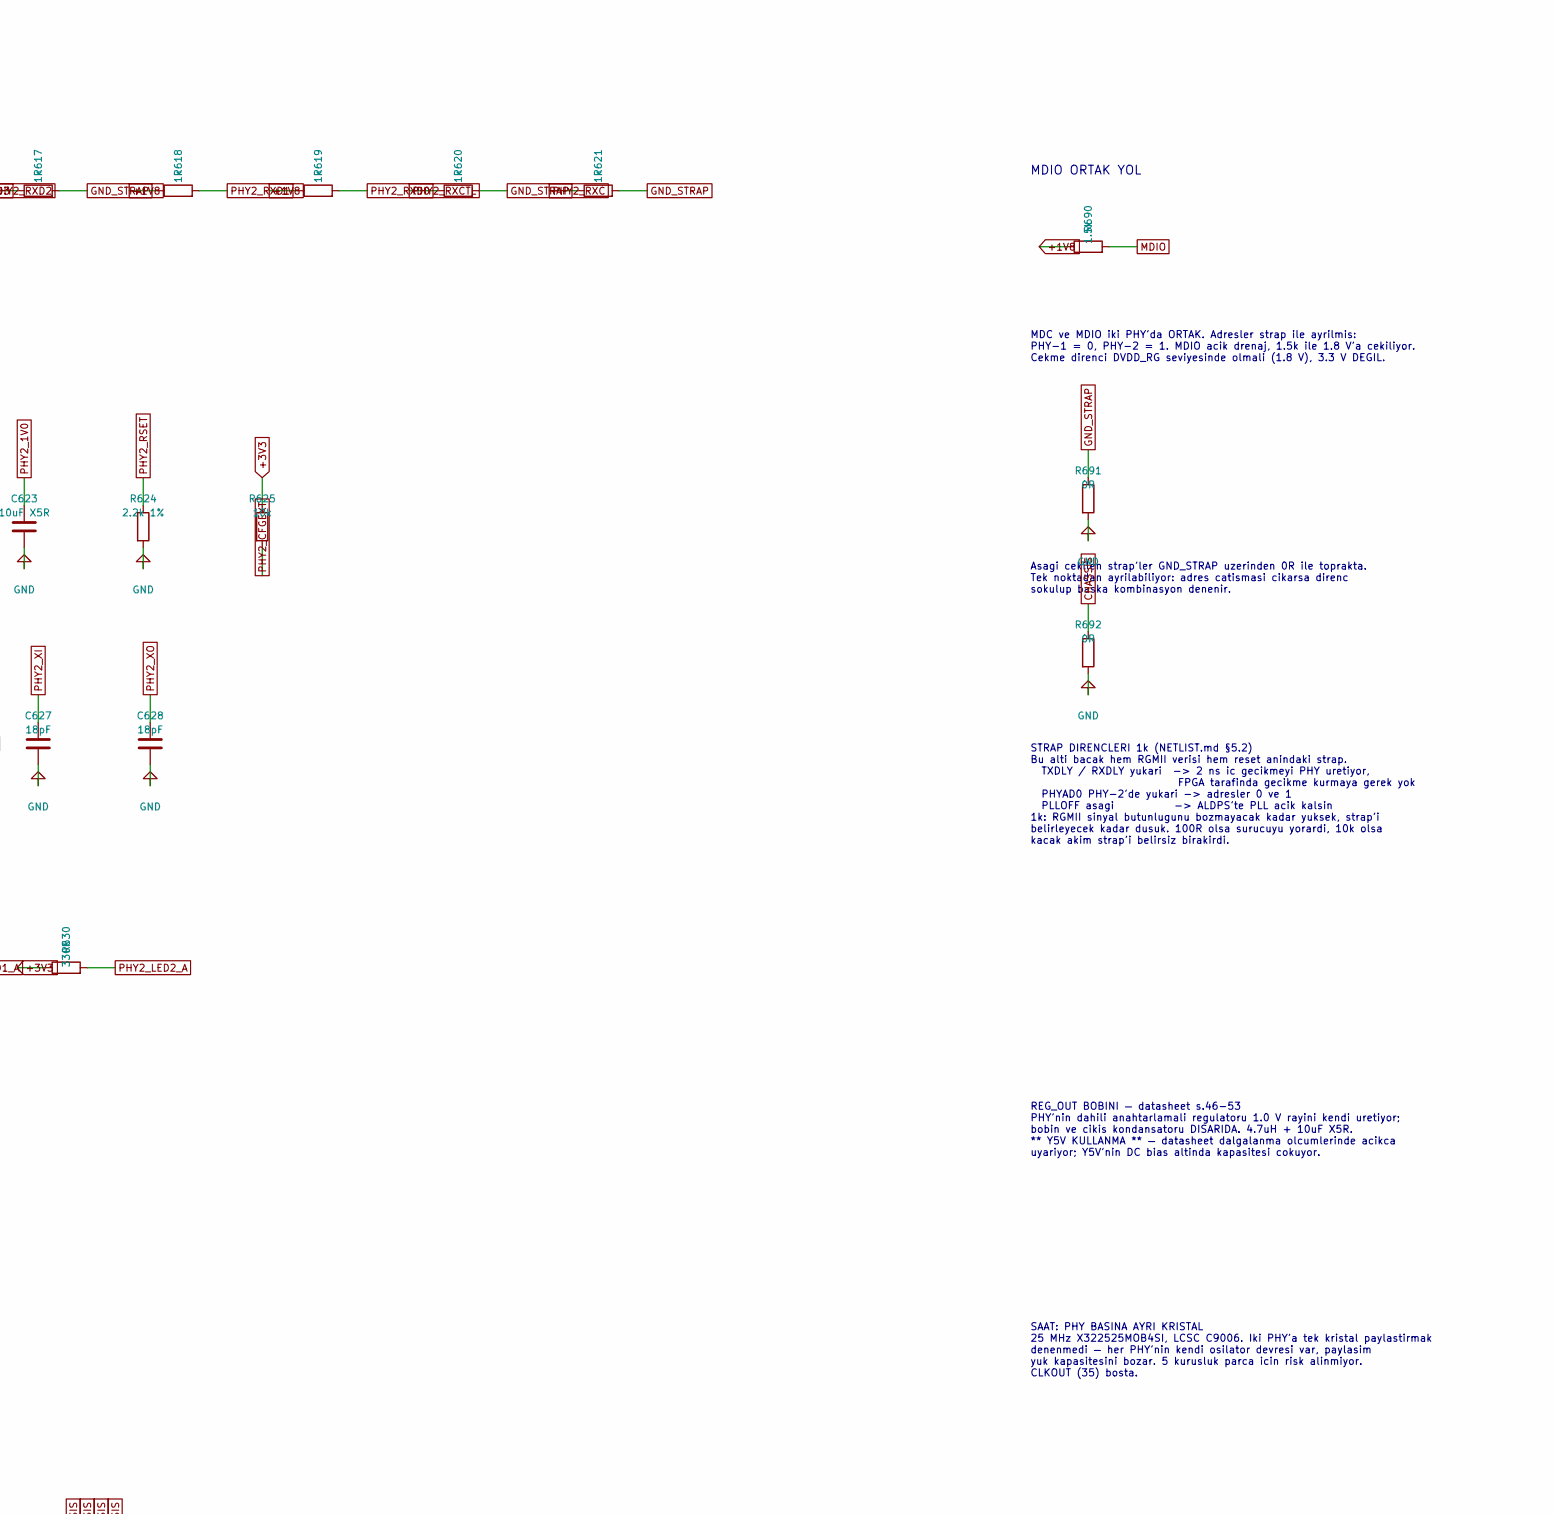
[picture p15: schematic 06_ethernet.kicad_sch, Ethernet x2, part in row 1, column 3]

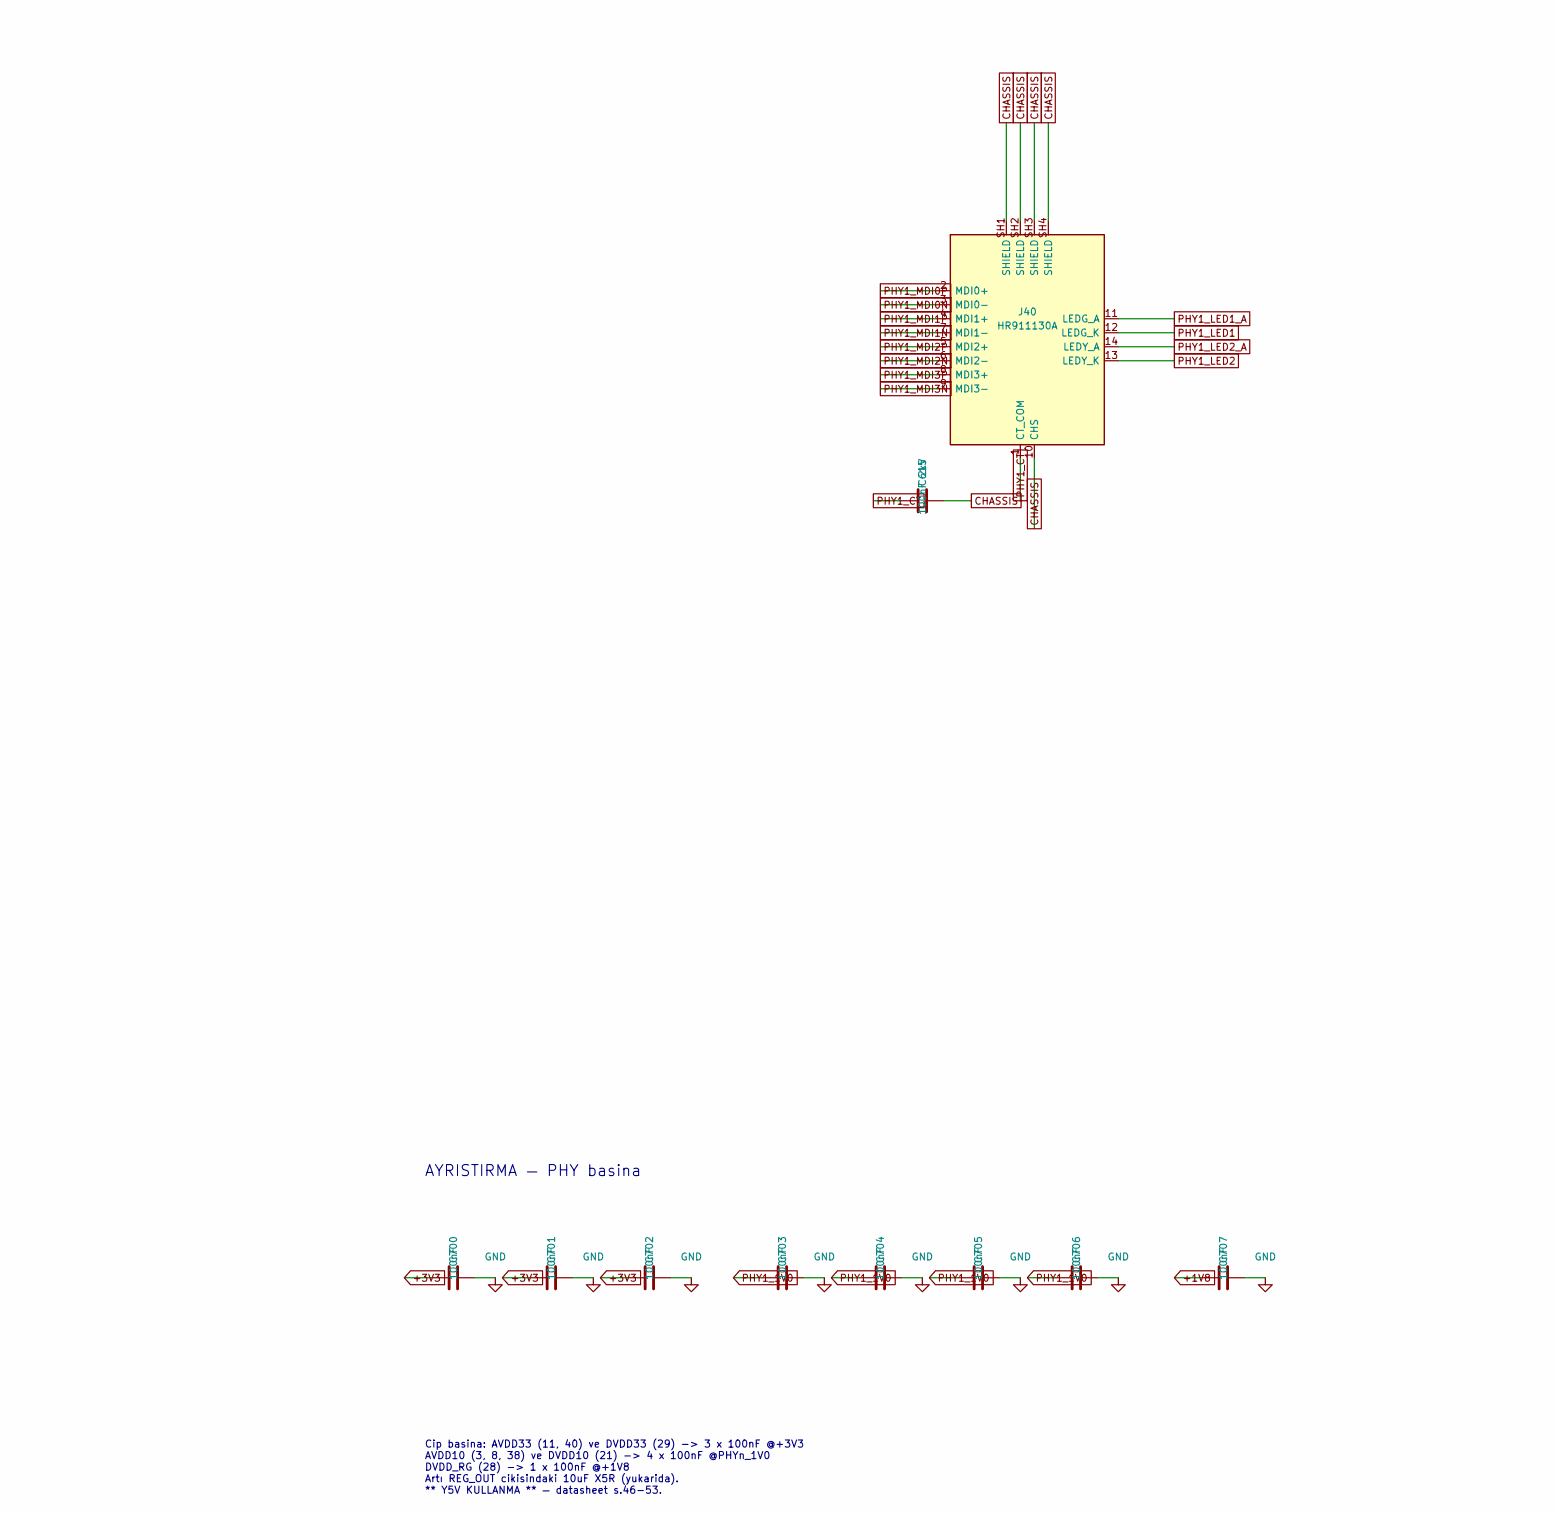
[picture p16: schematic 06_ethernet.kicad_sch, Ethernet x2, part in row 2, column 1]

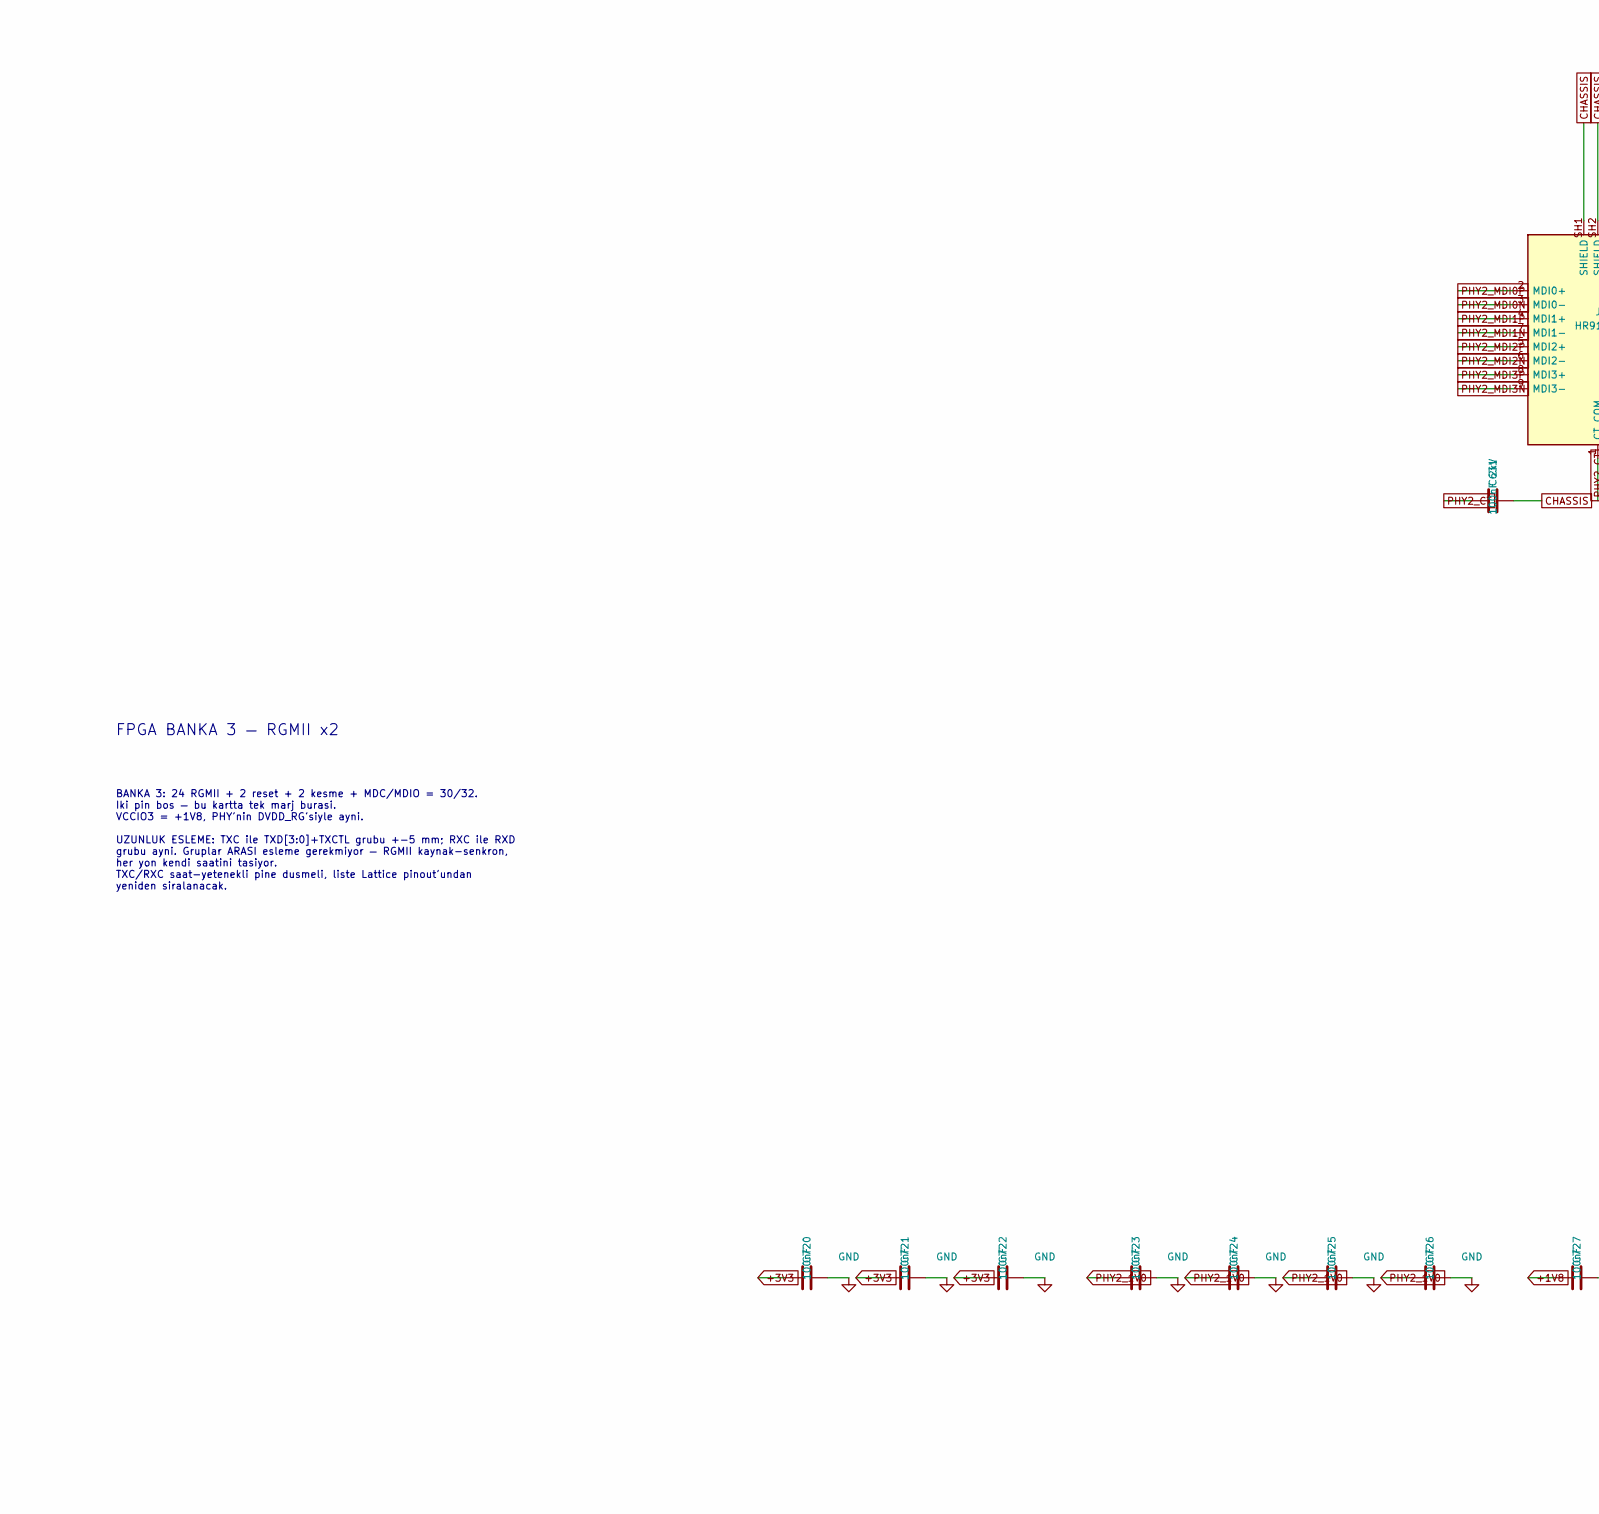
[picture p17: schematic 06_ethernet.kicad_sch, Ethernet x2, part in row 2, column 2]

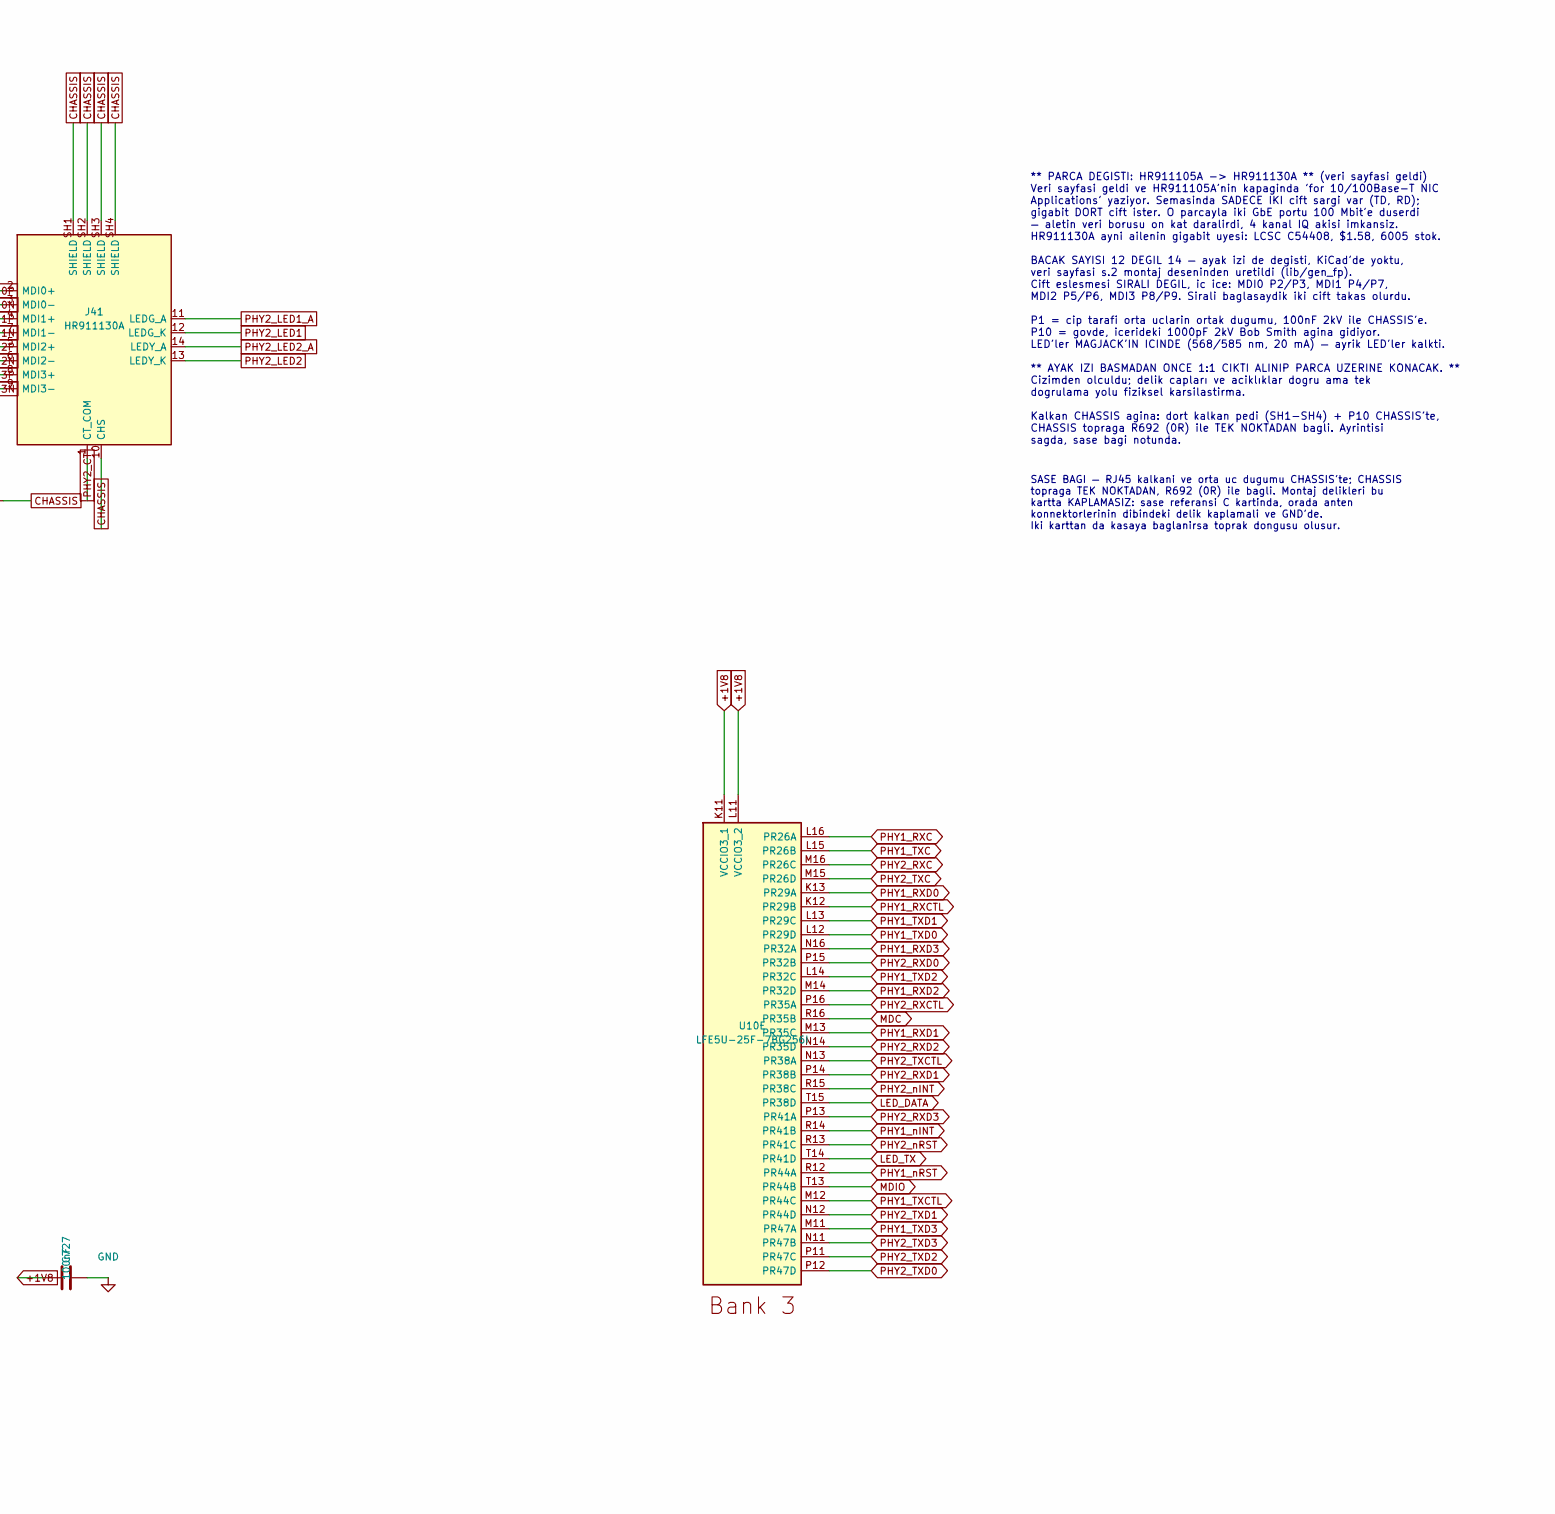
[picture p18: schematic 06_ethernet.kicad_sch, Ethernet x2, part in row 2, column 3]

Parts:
C607, C623: 10uF X5R; C_0603_1608Metric
C611, C612, C627, C628: 18pF; C_0603_1608Metric
C615, C631: 100nF 2kV; C_0603_1608Metric
C700, C701, C702, C703, C704, C705, C706, C707, C720, C721, C722, C723, C724, C725, C726, C727: 100nF; C_0402_1005Metric
J40, J41: HR911130A; RJ45_Hanrun_HR911130A
L606, L622: 4.7uH; L_0805_2012Metric
R600, R601, R602, R603, R604, R605, R616, R617, R618, R619, R620, R621: 1k; R_0603_1608Metric
R608, R624: 2.2k 1%; R_0603_1608Metric
R609, R625: 10k; R_0603_1608Metric
R613, R614, R629, R630: 330R; R_0603_1608Metric
R690: 1.5k; R_0603_1608Metric
R691, R692: 0R; R_0603_1608Metric
U10: LFE5U-25F-7BG256I; BGA-256_14.0x14.0mm_Layout16x16_P0.8mm_Ball0.45mm_Pad0.32mm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
U40, U41: RTL8211FI-CG; QFN-40-1EP_5x5mm_P0.4mm_EP3.6x3.6mm
Y610, Y626: 25MHz CL12pF; Crystal_SMD_3225-4Pin_3.2x2.5mm

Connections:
+1V8: C707.1, C727.1, R602.1, R603.1, R616.1, R618.1, R619.1, R690.1, U10.K11 (VCCIO3_1), U10.L11 (VCCIO3_2), U40.28 (DVDD_RG), U41.28 (DVDD_RG); also elsewhere on the board
CHASSIS: C615.2, C631.2, J40.10 (CHS), J40.SH1 (SHIELD), J40.SH2 (SHIELD), J40.SH3 (SHIELD), J40.SH4 (SHIELD), J41.10 (CHS), J41.SH1 (SHIELD), J41.SH2 (SHIELD), J41.SH3 (SHIELD), J41.SH4 (SHIELD), R692.1
GND_STRAP: R600.2, R601.2, R604.2, R605.2, R617.2, R620.2, R621.2, R691.1
LED_DATA: U10.T15 (PR38D); also elsewhere on the board
LED_TX: U10.T14 (PR41D); also elsewhere on the board
MDC: U10.R16 (PR35B), U40.13 (MDC), U41.13 (MDC)
MDIO: R690.2, U10.T13 (PR44B), U40.14 (MDIO), U41.14 (MDIO)
PHY1_CFGEXT: R609.2, U40.32 (LED0/CFG_EXT)
PHY1_CT: C615.1, J40.1 (CT_COM)
PHY1_LED1: J40.12 (LEDG_K), U40.33 (LED1/CFG_LDO0)
PHY1_LED1_A: J40.11 (LEDG_A), R613.2
PHY1_LED2: J40.13 (LEDY_K), U40.34 (LED2/CFG_LDO1)
PHY1_LED2_A: J40.14 (LEDY_A), R614.2
PHY1_MDI0N: J40.3 (MDI0-), U40.2 (MDIN0)
PHY1_MDI0P: J40.2 (MDI0+), U40.1 (MDIP0)
PHY1_MDI1N: J40.7 (MDI1-), U40.5 (MDIN1)
PHY1_MDI1P: J40.4 (MDI1+), U40.4 (MDIP1)
PHY1_MDI2N: J40.6 (MDI2-), U40.7 (MDIN2)
PHY1_MDI2P: J40.5 (MDI2+), U40.6 (MDIP2)
PHY1_MDI3N: J40.9 (MDI3-), U40.10 (MDIN3)
PHY1_MDI3P: J40.8 (MDI3+), U40.9 (MDIP3)
PHY1_REGOUT: L606.1, U40.30 (REG_OUT)
PHY1_RSET: R608.1, U40.39 (RSET)
PHY1_RXC: R605.1, U10.L16 (PR26A), U40.27 (RXC/PHYAD1)
PHY1_RXCTL: R604.1, U10.K12 (PR29B), U40.26 (RXCTL/PHYAD2)
PHY1_RXD0: R603.2, U10.K13 (PR29A), U40.25 (RXD0/RXDLY)
PHY1_RXD1: R602.2, U10.M13 (PR35C), U40.24 (RXD1/TXDLY)
PHY1_RXD2: R601.1, U10.M14 (PR32D), U40.23 (RXD2/PLLOFF)
PHY1_RXD3: R600.1, U10.N16 (PR32A), U40.22 (RXD3/PHYAD0)
PHY1_TXC: U10.L15 (PR26B), U40.20 (TXC)
PHY1_TXCTL: U10.M12 (PR44C), U40.19 (TXCTL)
PHY1_TXD0: U10.L12 (PR29D), U40.18 (TXD0)
PHY1_TXD1: U10.L13 (PR29C), U40.17 (TXD1)
PHY1_TXD2: U10.L14 (PR32C), U40.16 (TXD2)
PHY1_TXD3: U10.M11 (PR47A), U40.15 (TXD3)
PHY1_XI: C611.1, U40.36 (XTAL_IN), Y610.1
PHY1_XO: C612.1, U40.37 (XTAL_OUT/EXT_CLK), Y610.3
PHY1_nINT: U10.R14 (PR41B), U40.31 (~INTB/~PMEB)
PHY1_nRST: U10.R12 (PR44A), U40.12 (~PHYRSTB)
PHY2_CFGEXT: R625.2, U41.32 (LED0/CFG_EXT)
PHY2_CT: C631.1, J41.1 (CT_COM)
PHY2_LED1: J41.12 (LEDG_K), U41.33 (LED1/CFG_LDO0)
PHY2_LED1_A: J41.11 (LEDG_A), R629.2
PHY2_LED2: J41.13 (LEDY_K), U41.34 (LED2/CFG_LDO1)
PHY2_LED2_A: J41.14 (LEDY_A), R630.2
PHY2_MDI0N: J41.3 (MDI0-), U41.2 (MDIN0)
PHY2_MDI0P: J41.2 (MDI0+), U41.1 (MDIP0)
PHY2_MDI1N: J41.7 (MDI1-), U41.5 (MDIN1)
PHY2_MDI1P: J41.4 (MDI1+), U41.4 (MDIP1)
PHY2_MDI2N: J41.6 (MDI2-), U41.7 (MDIN2)
PHY2_MDI2P: J41.5 (MDI2+), U41.6 (MDIP2)
PHY2_MDI3N: J41.9 (MDI3-), U41.10 (MDIN3)
PHY2_MDI3P: J41.8 (MDI3+), U41.9 (MDIP3)
PHY2_REGOUT: L622.1, U41.30 (REG_OUT)
PHY2_RSET: R624.1, U41.39 (RSET)
PHY2_RXC: R621.1, U10.M16 (PR26C), U41.27 (RXC/PHYAD1)
PHY2_RXCTL: R620.1, U10.P16 (PR35A), U41.26 (RXCTL/PHYAD2)
PHY2_RXD0: R619.2, U10.P15 (PR32B), U41.25 (RXD0/RXDLY)
PHY2_RXD1: R618.2, U10.P14 (PR38B), U41.24 (RXD1/TXDLY)
PHY2_RXD2: R617.1, U10.N14 (PR35D), U41.23 (RXD2/PLLOFF)
PHY2_RXD3: R616.2, U10.P13 (PR41A), U41.22 (RXD3/PHYAD0)
PHY2_TXC: U10.M15 (PR26D), U41.20 (TXC)
PHY2_TXCTL: U10.N13 (PR38A), U41.19 (TXCTL)
PHY2_TXD0: U10.P12 (PR47D), U41.18 (TXD0)
PHY2_TXD1: U10.N12 (PR44D), U41.17 (TXD1)
PHY2_TXD2: U10.P11 (PR47C), U41.16 (TXD2)
PHY2_TXD3: U10.N11 (PR47B), U41.15 (TXD3)
PHY2_XI: C627.1, U41.36 (XTAL_IN), Y626.1
PHY2_XO: C628.1, U41.37 (XTAL_OUT/EXT_CLK), Y626.3
PHY2_nINT: U10.R15 (PR38C), U41.31 (~INTB/~PMEB)
PHY2_nRST: U10.R13 (PR41C), U41.12 (~PHYRSTB)

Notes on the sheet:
REG_OUT BOBINI — datasheet s.46-53 PHY'nin dahili anahtarlamali regulatoru 1.0 V rayini kendi uretiyor; bobin ve cikis kondansatoru DISARIDA. 4.7uH + 10uF X5R. ** Y5V KULLANMA ** — datasheet dalgalanma olcumlerinde acikca uyariyor; Y5V'nin DC bias altinda kapasitesi cokuyor.
MDIO ORTAK YOL
FPGA BANKA 3 — RGMII x2
SAAT: PHY BASINA AYRI KRISTAL 25 MHz X322525MOB4SI, LCSC C9006. Iki PHY'a tek kristal paylastirmak denenmedi — her PHY'nin kendi osilator devresi var, paylasim yuk kapasitesini bozar. 5 kurusluk parca icin risk alinmiyor. CLKOUT (35) bosta.
MDC ve MDIO iki PHY'da ORTAK. Adresler strap ile ayrilmis: PHY-1 = 0, PHY-2 = 1. MDIO acik drenaj, 1.5k ile 1.8 V'a cekiliyor. Cekme direnci DVDD_RG seviyesinde olmali (1.8 V), 3.3 V DEGIL.
STRAP DIRENCLERI 1k (NETLIST.md §5.2) Bu alti bacak hem RGMII verisi hem reset anindaki strap. TXDLY / RXDLY yukari -> 2 ns ic gecikmeyi PHY uretiyor, FPGA tarafinda gecikme kurmaya gerek yok PHYAD0 PHY-2'de yukari -> adresler 0 ve 1 PLLOFF asagi -> ALDPS'te PLL acik kalsin 1k: RGMII sinyal butunlu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
ETHERNET x2 — RTL8211FI-CG, RGMII, banka 3
Cip basina: AVDD33 (11, 40) ve DVDD33 (29) -> 3 x 100nF @+3V3 AVDD10 (3, 8, 38) ve DVDD10 (21) -> 4 x 100nF @PHYn_1V0 DVDD_RG (28) -> 1 x 100nF @+1V8 Artı REG_OUT cikisindaki 10uF X5R (yukarida). ** Y5V KULLANMA ** — datasheet s.46-53.
SASE BAGI — RJ45 kalkani ve orta uc dugumu CHASSIS'te; CHASSIS topraga TEK NOKTADAN, R692 (0R) ile bagli. Montaj delikleri bu kartta KAPLAMASIZ: sase referansi C kartinda, orada anten konnektorlerinin dibindeki delik kaplamali ve GND'de. Iki karttan da kasaya baglanirsa toprak dongusu olusur.
** PARCA DEGISTI: HR911105A -> HR911130A ** (veri sayfasi geldi) Veri sayfasi geldi ve HR911105A'nin kapaginda 'for 10/100Base-T NIC Applications' yaziyor. Semasinda SADECE IKI cift sargi var (TD, RD); gigabit DORT cift ister. O parcayla iki GbE portu 100 Mbit'e duserdi — aletin veri borusu on kat 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
BANKA 3: 24 RGMII + 2 reset + 2 kesme + MDC/MDIO = 30/32. Iki pin bos — bu kartta tek marj burasi. VCCIO3 = +1V8, PHY'nin DVDD_RG'siyle ayni. UZUNLUK ESLEME: TXC ile TXD[3:0]+TXCTL grubu +-5 mm; RXC ile RXD grubu ayni. Gruplar ARASI esleme gerekmiyor — RGMII kaynak-senkron, her yon kendi saatini ta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
Asagi cekilen strap'ler GND_STRAP uzerinden 0R ile toprakta. Tek noktadan ayrilabiliyor: adres catismasi cikarsa direnc sokulup baska kombinasyon denenir.
AYRISTIRMA — PHY basina
Iki bagimsiz gigabit arayuz. Sahada tek kablo yeterli; labda biri ham IQ akisi, digeri kontrol/telemetri — akislar birbirinin gecikmesini bozmuyor.

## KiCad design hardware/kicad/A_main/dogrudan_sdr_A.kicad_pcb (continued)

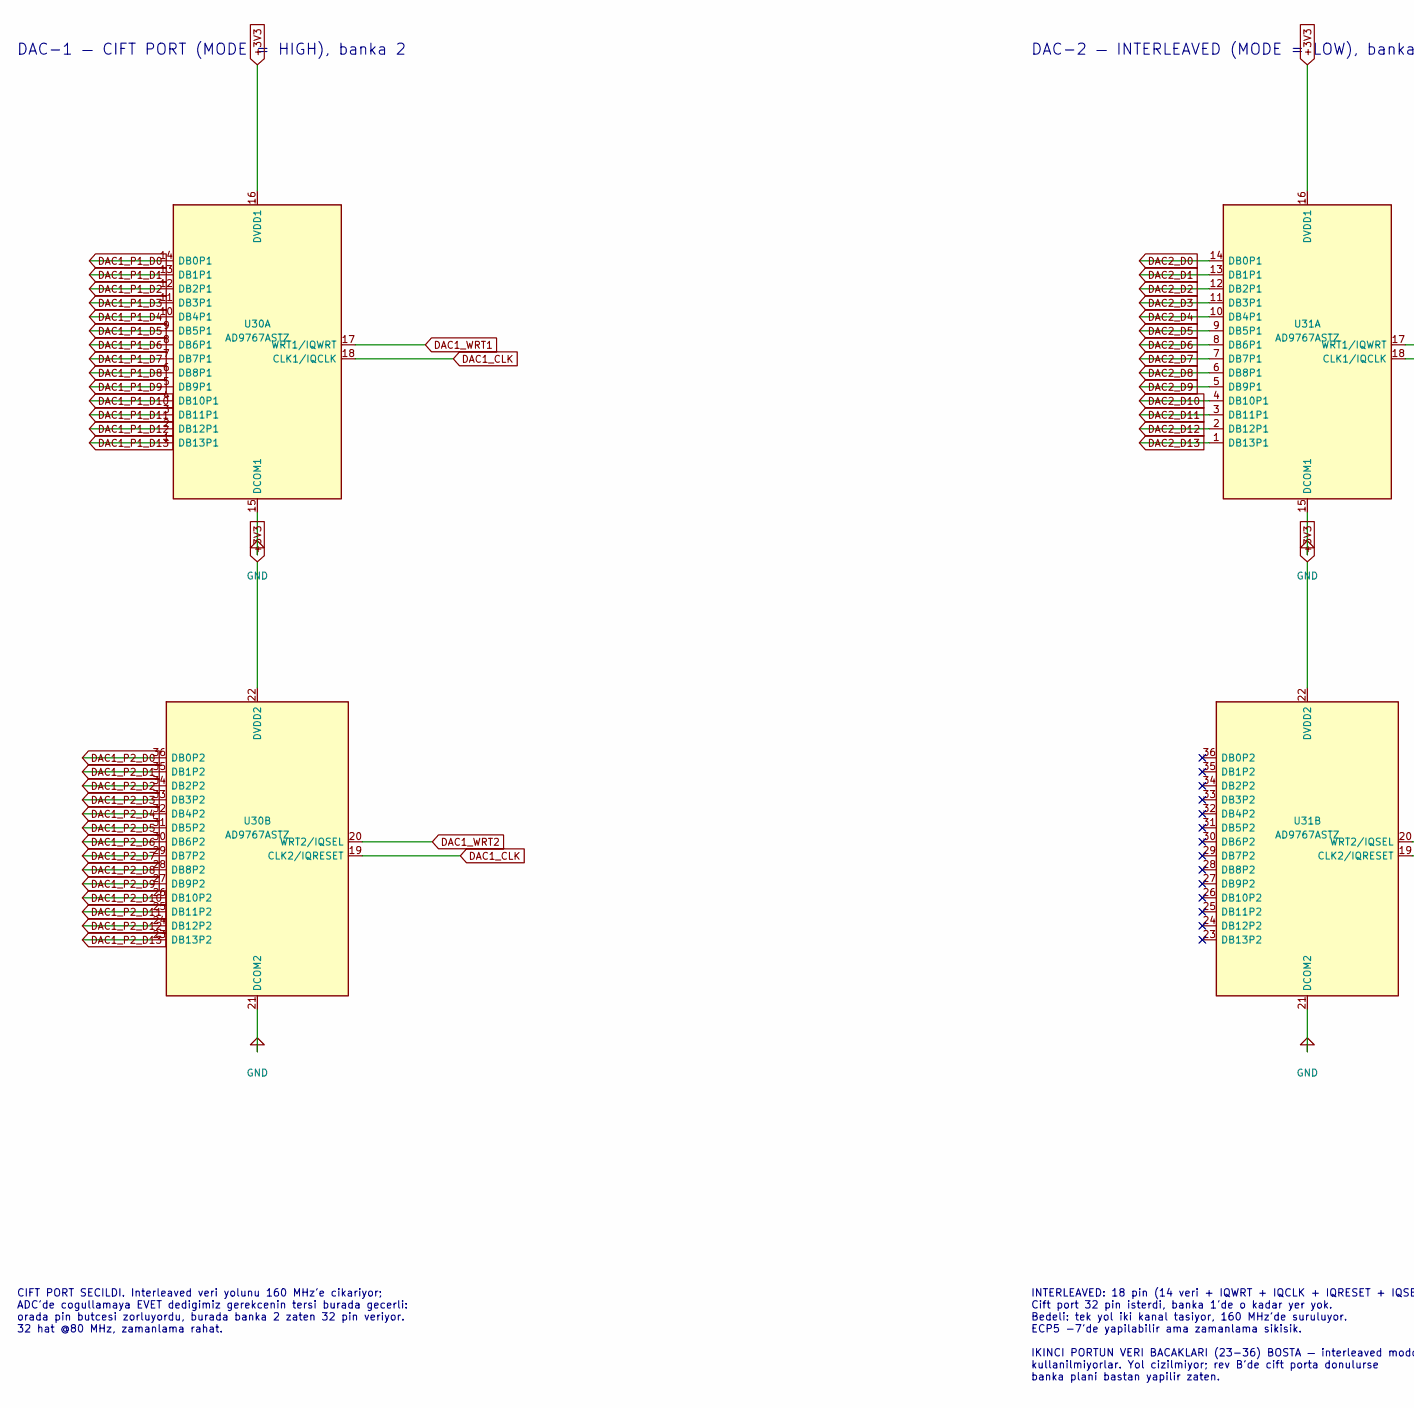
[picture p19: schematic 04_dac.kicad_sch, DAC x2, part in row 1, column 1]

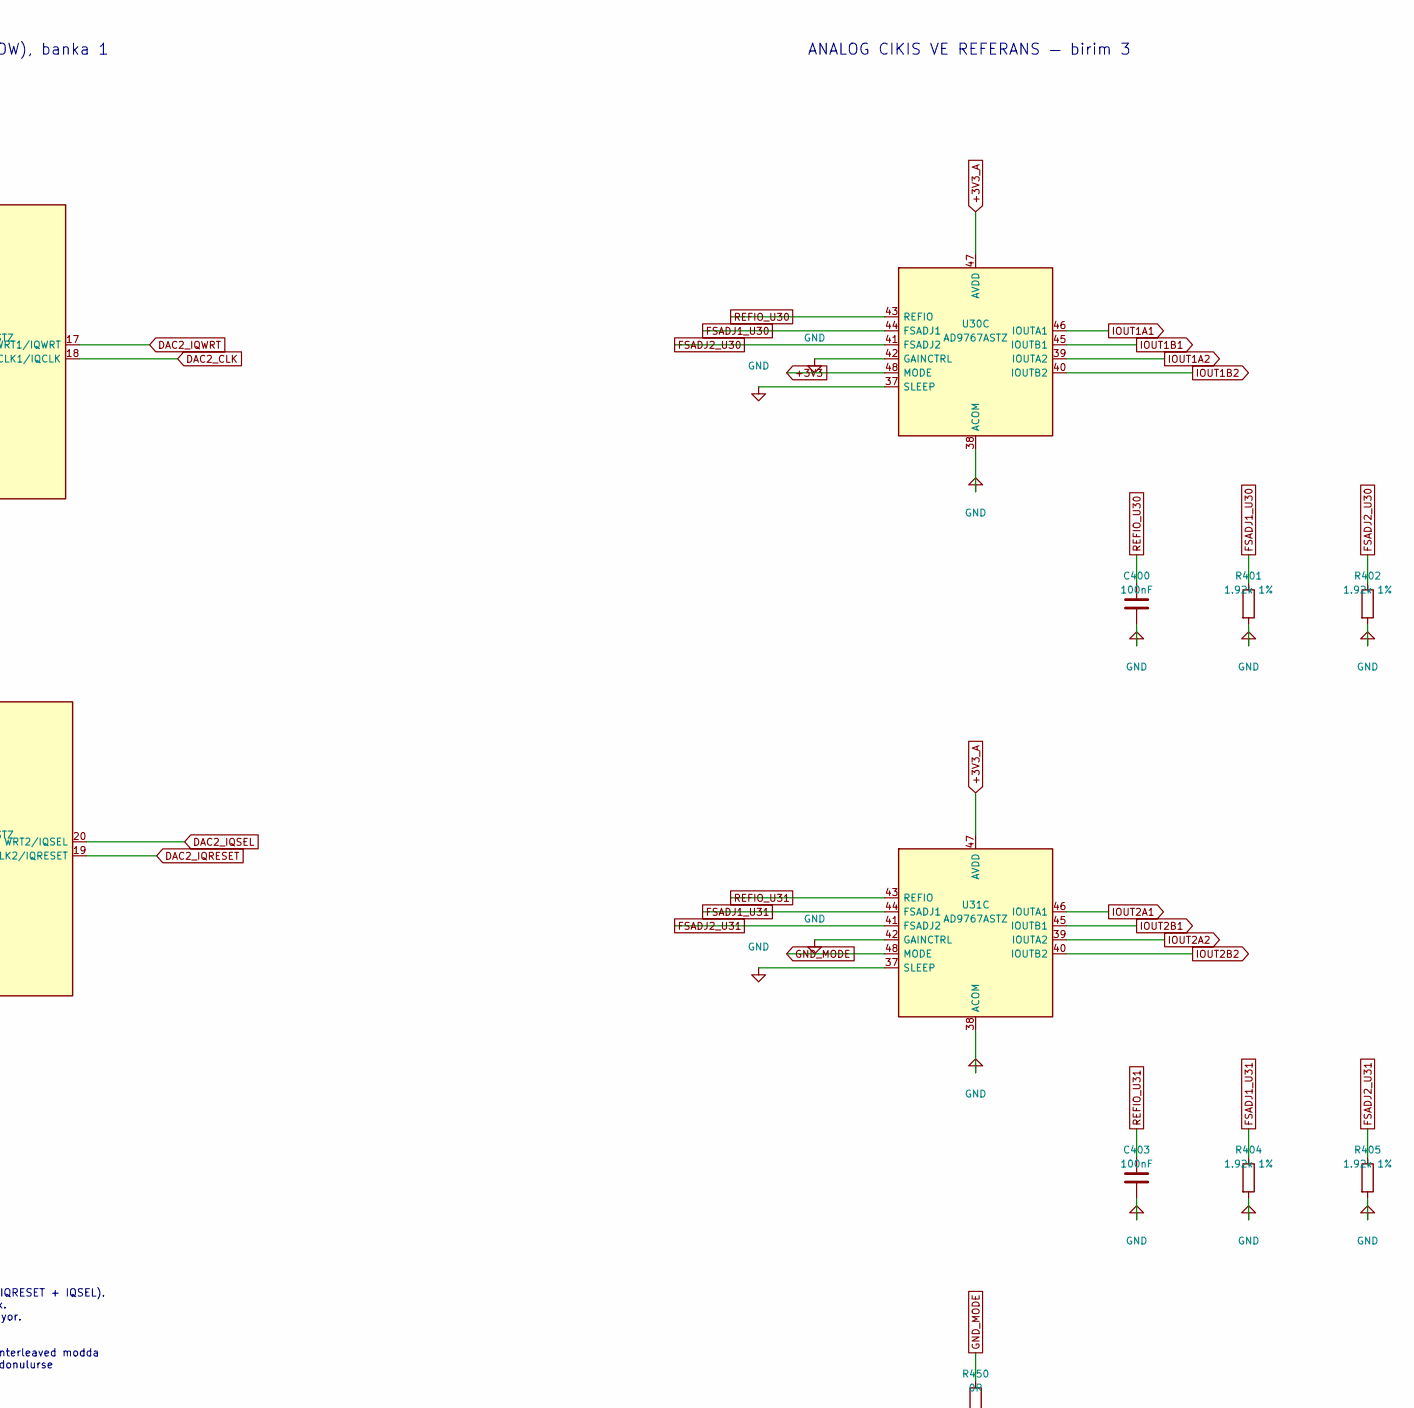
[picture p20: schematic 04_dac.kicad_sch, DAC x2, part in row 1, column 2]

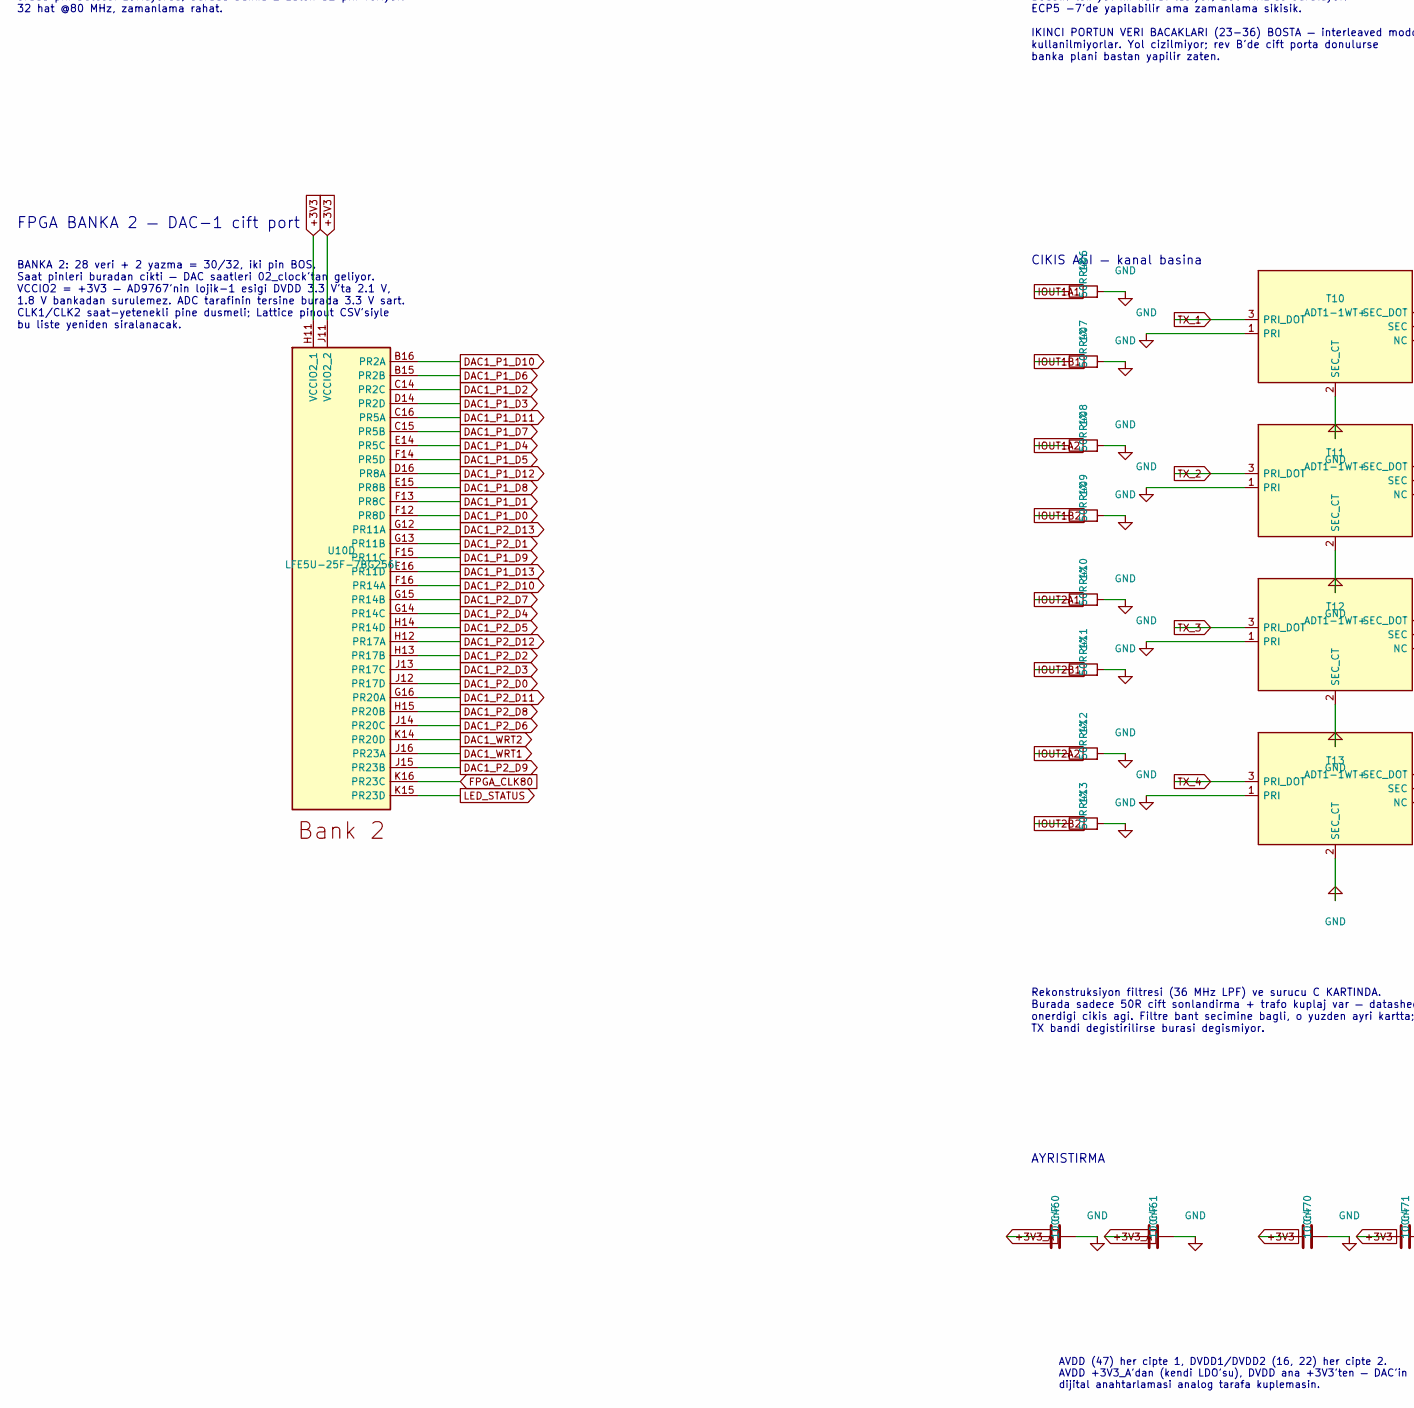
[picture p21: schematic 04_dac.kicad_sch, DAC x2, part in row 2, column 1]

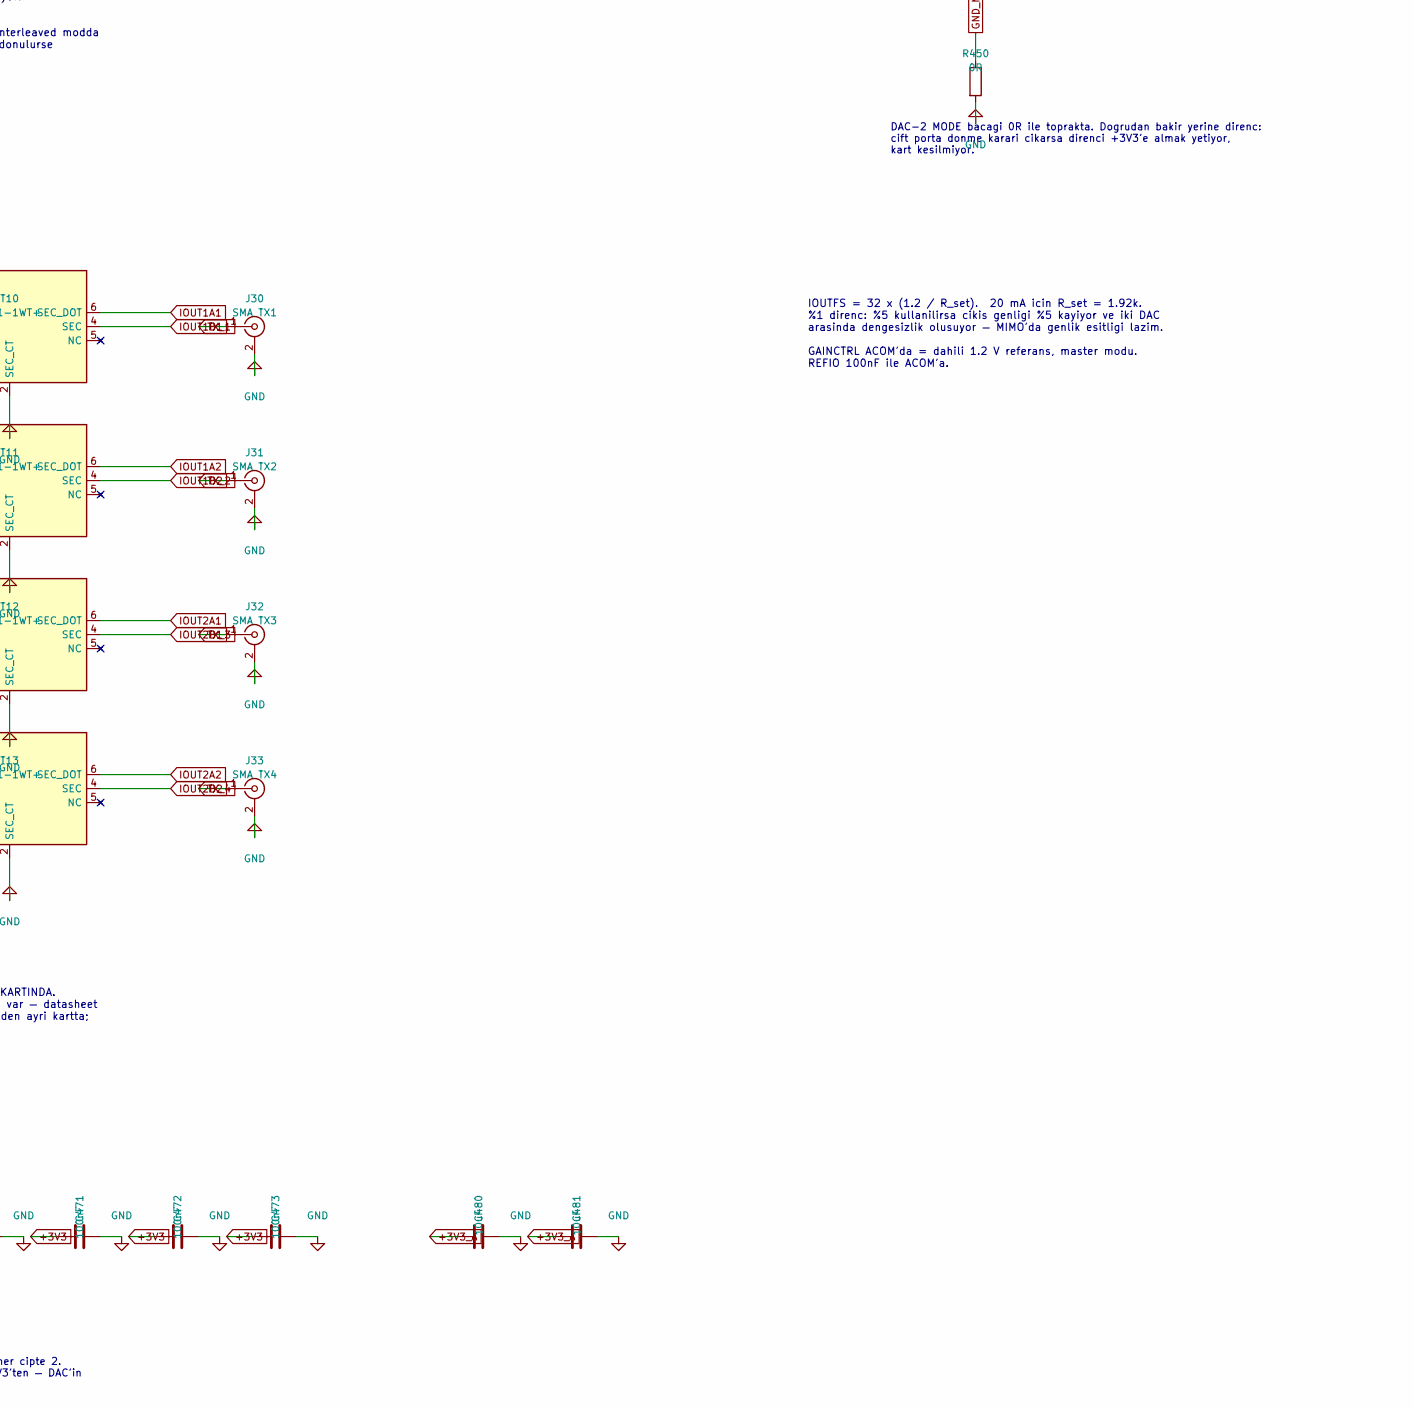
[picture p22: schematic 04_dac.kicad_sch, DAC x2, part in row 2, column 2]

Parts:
C400, C403: 100nF; C_0603_1608Metric
C460, C461, C470, C471, C472, C473: 100nF; C_0402_1005Metric
C480, C481: 10uF; C_0402_1005Metric
J30: SMA TX1; SMA_Amphenol_132289_EdgeMount
J31: SMA TX2; SMA_Amphenol_132289_EdgeMount
J32: SMA TX3; SMA_Amphenol_132289_EdgeMount
J33: SMA TX4; SMA_Amphenol_132289_EdgeMount
R401, R402, R404, R405: 1.92k 1%; R_0603_1608Metric
R406, R407, R408, R409, R410, R411, R412, R413: 50R 1%; R_0603_1608Metric
R450: 0R; R_0603_1608Metric
T10, T11, T12, T13: ADT1-1WT+; Mini-Circuits_CD542_H2.84mm
U10: LFE5U-25F-7BG256I; BGA-256_14.0x14.0mm_Layout16x16_P0.8mm_Ball0.45mm_Pad0.32mm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
U30, U31: AD9767ASTZ; LQFP-48_7x7mm_P0.5mm

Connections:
DAC1_CLK: U30.18 (CLK1/IQCLK), U30.19 (CLK2/IQRESET); also elsewhere on the board
DAC1_P1_D0: U10.F12 (PR8D), U30.14 (DB0P1)
DAC1_P1_D1: U10.F13 (PR8C), U30.13 (DB1P1)
DAC1_P1_D2: U10.C14 (PR2C), U30.12 (DB2P1)
DAC1_P1_D3: U10.D14 (PR2D), U30.11 (DB3P1)
DAC1_P1_D4: U10.E14 (PR5C), U30.10 (DB4P1)
DAC1_P1_D5: U10.F14 (PR5D), U30.9 (DB5P1)
DAC1_P1_D6: U10.B15 (PR2B), U30.8 (DB6P1)
DAC1_P1_D7: U10.C15 (PR5B), U30.7 (DB7P1)
DAC1_P1_D8: U10.E15 (PR8B), U30.6 (DB8P1)
DAC1_P1_D9: U10.F15 (PR11C), U30.5 (DB9P1)
DAC1_P1_D10: U10.B16 (PR2A), U30.4 (DB10P1)
DAC1_P1_D11: U10.C16 (PR5A), U30.3 (DB11P1)
DAC1_P1_D12: U10.D16 (PR8A), U30.2 (DB12P1)
DAC1_P1_D13: U10.E16 (PR11D), U30.1 (DB13P1)
DAC1_P2_D0: U10.J12 (PR17D), U30.36 (DB0P2)
DAC1_P2_D1: U10.G13 (PR11B), U30.35 (DB1P2)
DAC1_P2_D2: U10.H13 (PR17B), U30.34 (DB2P2)
DAC1_P2_D3: U10.J13 (PR17C), U30.33 (DB3P2)
DAC1_P2_D4: U10.G14 (PR14C), U30.32 (DB4P2)
DAC1_P2_D5: U10.H14 (PR14D), U30.31 (DB5P2)
DAC1_P2_D6: U10.J14 (PR20C), U30.30 (DB6P2)
DAC1_P2_D7: U10.G15 (PR14B), U30.29 (DB7P2)
DAC1_P2_D8: U10.H15 (PR20B), U30.28 (DB8P2)
DAC1_P2_D9: U10.J15 (PR23B), U30.27 (DB9P2)
DAC1_P2_D10: U10.F16 (PR14A), U30.26 (DB10P2)
DAC1_P2_D11: U10.G16 (PR20A), U30.25 (DB11P2)
DAC1_P2_D12: U10.H12 (PR17A), U30.24 (DB12P2)
DAC1_P2_D13: U10.G12 (PR11A), U30.23 (DB13P2)
DAC1_WRT1: U10.J16 (PR23A), U30.17 (WRT1/IQWRT)
DAC1_WRT2: U10.K14 (PR20D), U30.20 (WRT2/IQSEL)
DAC2_CLK: U31.18 (CLK1/IQCLK); also elsewhere on the board
DAC2_D0: U31.14 (DB0P1); also elsewhere on the board
DAC2_D1: U31.13 (DB1P1); also elsewhere on the board
DAC2_D2: U31.12 (DB2P1); also elsewhere on the board
DAC2_D3: U31.11 (DB3P1); also elsewhere on the board
DAC2_D4: U31.10 (DB4P1); also elsewhere on the board
DAC2_D5: U31.9 (DB5P1); also elsewhere on the board
DAC2_D6: U31.8 (DB6P1); also elsewhere on the board
DAC2_D7: U31.7 (DB7P1); also elsewhere on the board
DAC2_D8: U31.6 (DB8P1); also elsewhere on the board
DAC2_D9: U31.5 (DB9P1); also elsewhere on the board
DAC2_D10: U31.4 (DB10P1); also elsewhere on the board
DAC2_D11: U31.3 (DB11P1); also elsewhere on the board
DAC2_D12: U31.2 (DB12P1); also elsewhere on the board
DAC2_D13: U31.1 (DB13P1); also elsewhere on the board
DAC2_IQRESET: U31.19 (CLK2/IQRESET); also elsewhere on the board
DAC2_IQSEL: U31.20 (WRT2/IQSEL); also elsewhere on the board
DAC2_IQWRT: U31.17 (WRT1/IQWRT); also elsewhere on the board
FPGA_CLK80: U10.K16 (PR23C); also elsewhere on the board
FSADJ1_U30: R401.1, U30.44 (FSADJ1)
FSADJ1_U31: R404.1, U31.44 (FSADJ1)
FSADJ2_U30: R402.1, U30.41 (FSADJ2)
FSADJ2_U31: R405.1, U31.41 (FSADJ2)
GND_MODE: R450.1, U31.48 (MODE)
IOUT1A1: R406.1, T10.6 (SEC_DOT), U30.46 (IOUTA1)
IOUT1A2: R408.1, T11.6 (SEC_DOT), U30.39 (IOUTA2)
IOUT1B1: R407.1, T10.4 (SEC), U30.45 (IOUTB1)
IOUT1B2: R409.1, T11.4 (SEC), U30.40 (IOUTB2)
IOUT2A1: R410.1, T12.6 (SEC_DOT), U31.46 (IOUTA1)
IOUT2A2: R412.1, T13.6 (SEC_DOT), U31.39 (IOUTA2)
IOUT2B1: R411.1, T12.4 (SEC), U31.45 (IOUTB1)
IOUT2B2: R413.1, T13.4 (SEC), U31.40 (IOUTB2)
LED_STATUS: U10.K15 (PR23D); also elsewhere on the board
TX_1: J30.1 (In), T10.3 (PRI_DOT)
TX_2: J31.1 (In), T11.3 (PRI_DOT)
TX_3: J32.1 (In), T12.3 (PRI_DOT)
TX_4: J33.1 (In), T13.3 (PRI_DOT)

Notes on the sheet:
INTERLEAVED: 18 pin (14 veri + IQWRT + IQCLK + IQRESET + IQSEL). Cift port 32 pin isterdi, banka 1'de o kadar yer yok. Bedeli: tek yol iki kanal tasiyor, 160 MHz'de suruluyor. ECP5 -7'de yapilabilir ama zamanlama sikisik. IKINCI PORTUN VERI BACAKLARI (23-36) BOSTA — interleaved modda kullanilmiyorl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
AYRISTIRMA
IOUTFS = 32 x (1.2 / R_set). 20 mA icin R_set = 1.92k. %1 direnc: %5 kullanilirsa cikis genligi %5 kayiyor ve iki DAC arasinda dengesizlik olusuyor — MIMO'da genlik esitligi lazim. GAINCTRL ACOM'da = dahili 1.2 V referans, master modu. REFIO 100nF ile ACOM'a.
BANKA 2: 28 veri + 2 yazma = 30/32, iki pin BOS. Saat pinleri buradan cikti — DAC saatleri 02_clock'tan geliyor. VCCIO2 = +3V3 — AD9767'nin lojik-1 esigi DVDD 3.3 V'ta 2.1 V, 1.8 V bankadan surulemez. ADC tarafinin tersine burada 3.3 V sart. CLK1/CLK2 saat-yetenekli pine dusmeli; Lattice pinout CSV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
ANALOG CIKIS VE REFERANS — birim 3
DAC-2 MODE bacagi 0R ile toprakta. Dogrudan bakir yerine direnc: cift porta donme karari cikarsa direnci +3V3'e almak yetiyor, kart kesilmiyor.
FPGA BANKA 2 — DAC-1 cift port
DAC-2 — INTERLEAVED (MODE = LOW), banka 1
CIKIS AGI — kanal basina
DAC-1 — CIFT PORT (MODE = HIGH), banka 2
CIFT PORT SECILDI. Interleaved veri yolunu 160 MHz'e cikariyor; ADC'de cogullamaya EVET dedigimiz gerekcenin tersi burada gecerli: orada pin butcesi zorluyordu, burada banka 2 zaten 32 pin veriyor. 32 hat @80 MHz, zamanlama rahat.
Rekonstruksiyon filtresi (36 MHz LPF) ve surucu C KARTINDA. Burada sadece 50R cift sonlandirma + trafo kuplaj var — datasheet onerdigi cikis agi. Filtre bant secimine bagli, o yuzden ayri kartta; TX bandi degistirilirse burasi degismiyor.
AVDD (47) her cipte 1, DVDD1/DVDD2 (16, 22) her cipte 2. AVDD +3V3_A'dan (kendi LDO'su), DVDD ana +3V3'ten — DAC'in dijital anahtarlamasi analog tarafa kuplemasin.

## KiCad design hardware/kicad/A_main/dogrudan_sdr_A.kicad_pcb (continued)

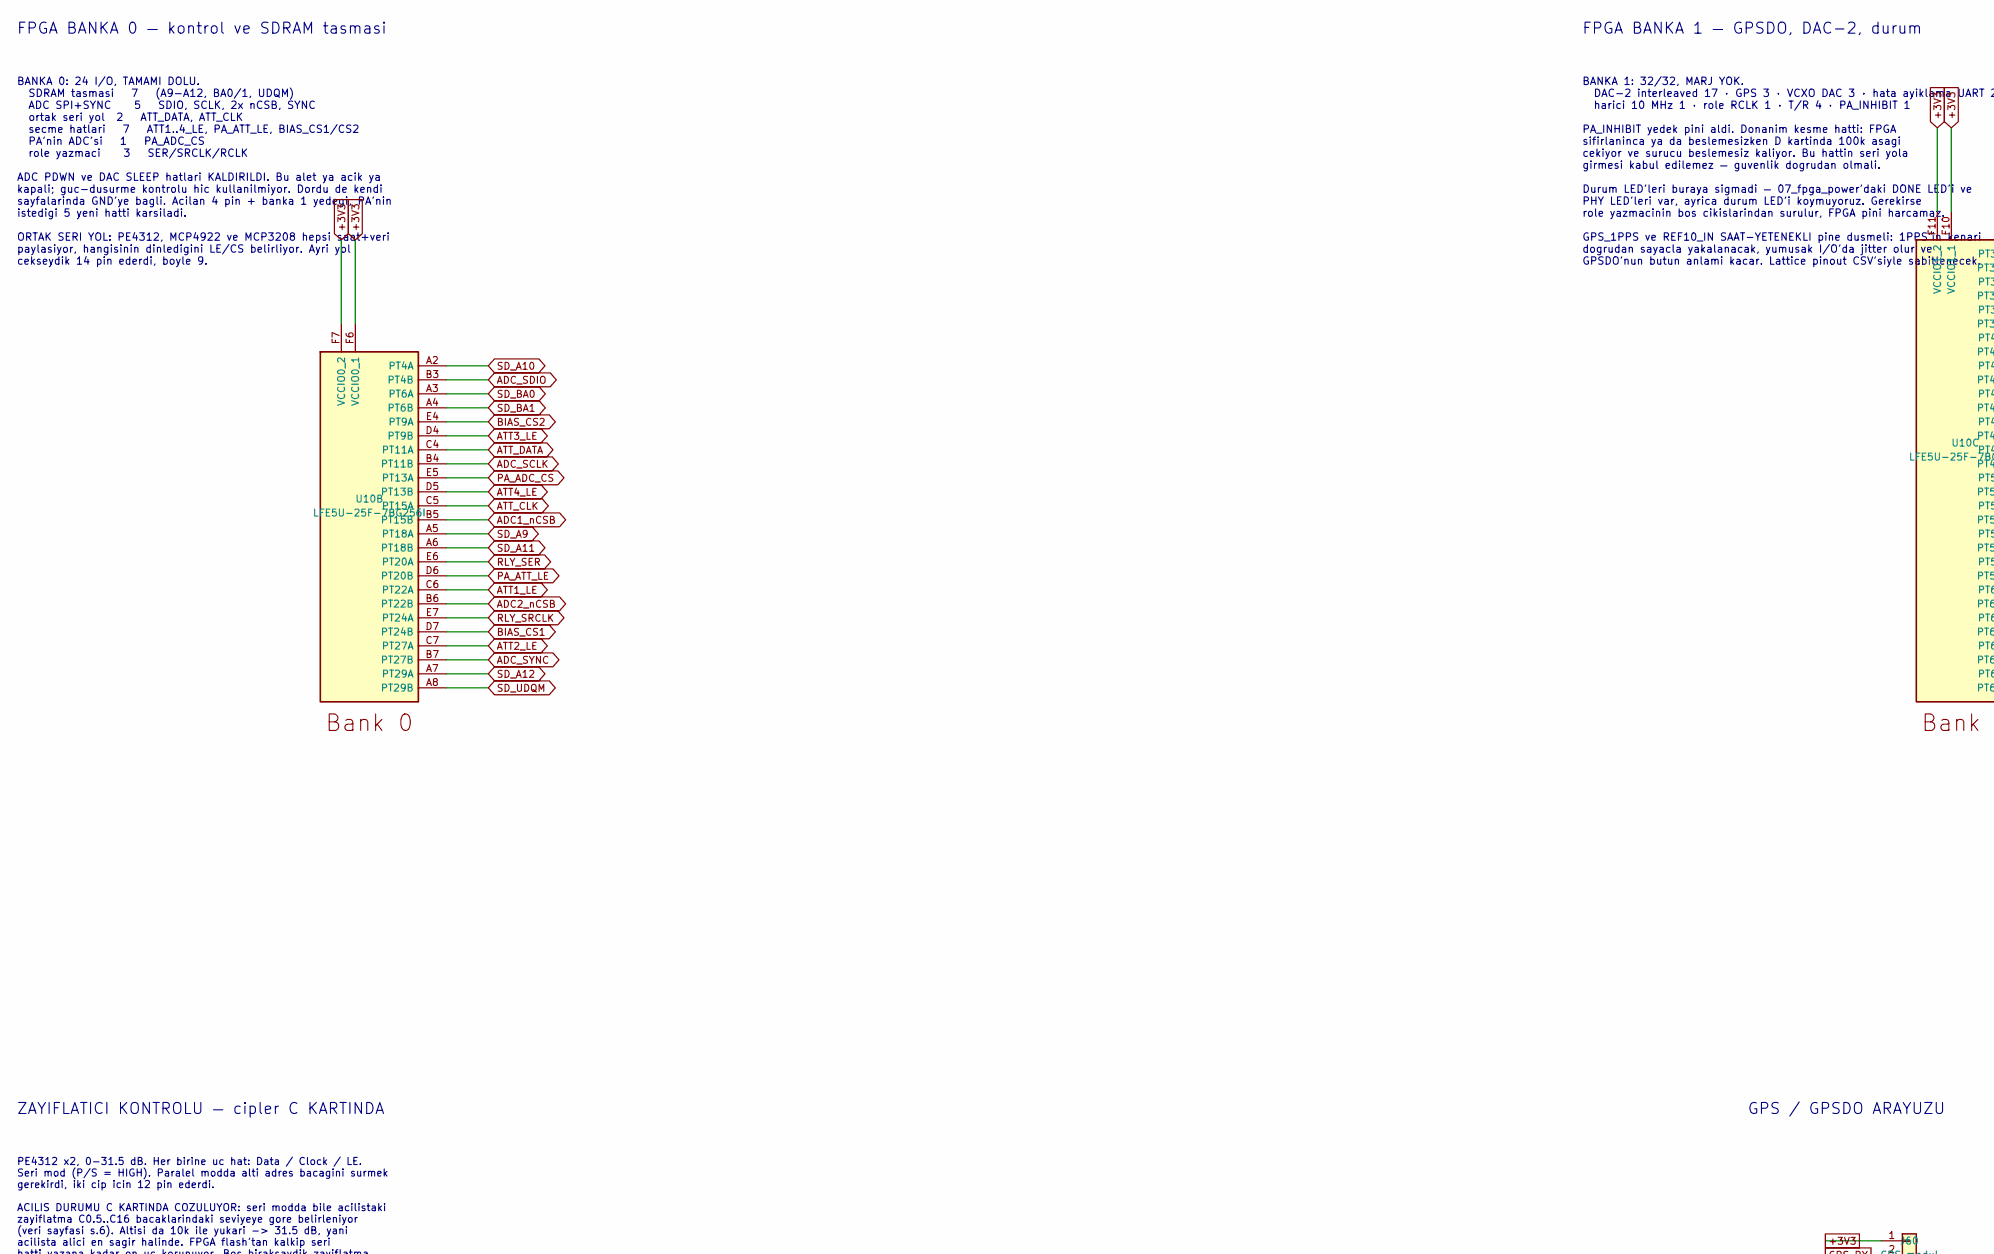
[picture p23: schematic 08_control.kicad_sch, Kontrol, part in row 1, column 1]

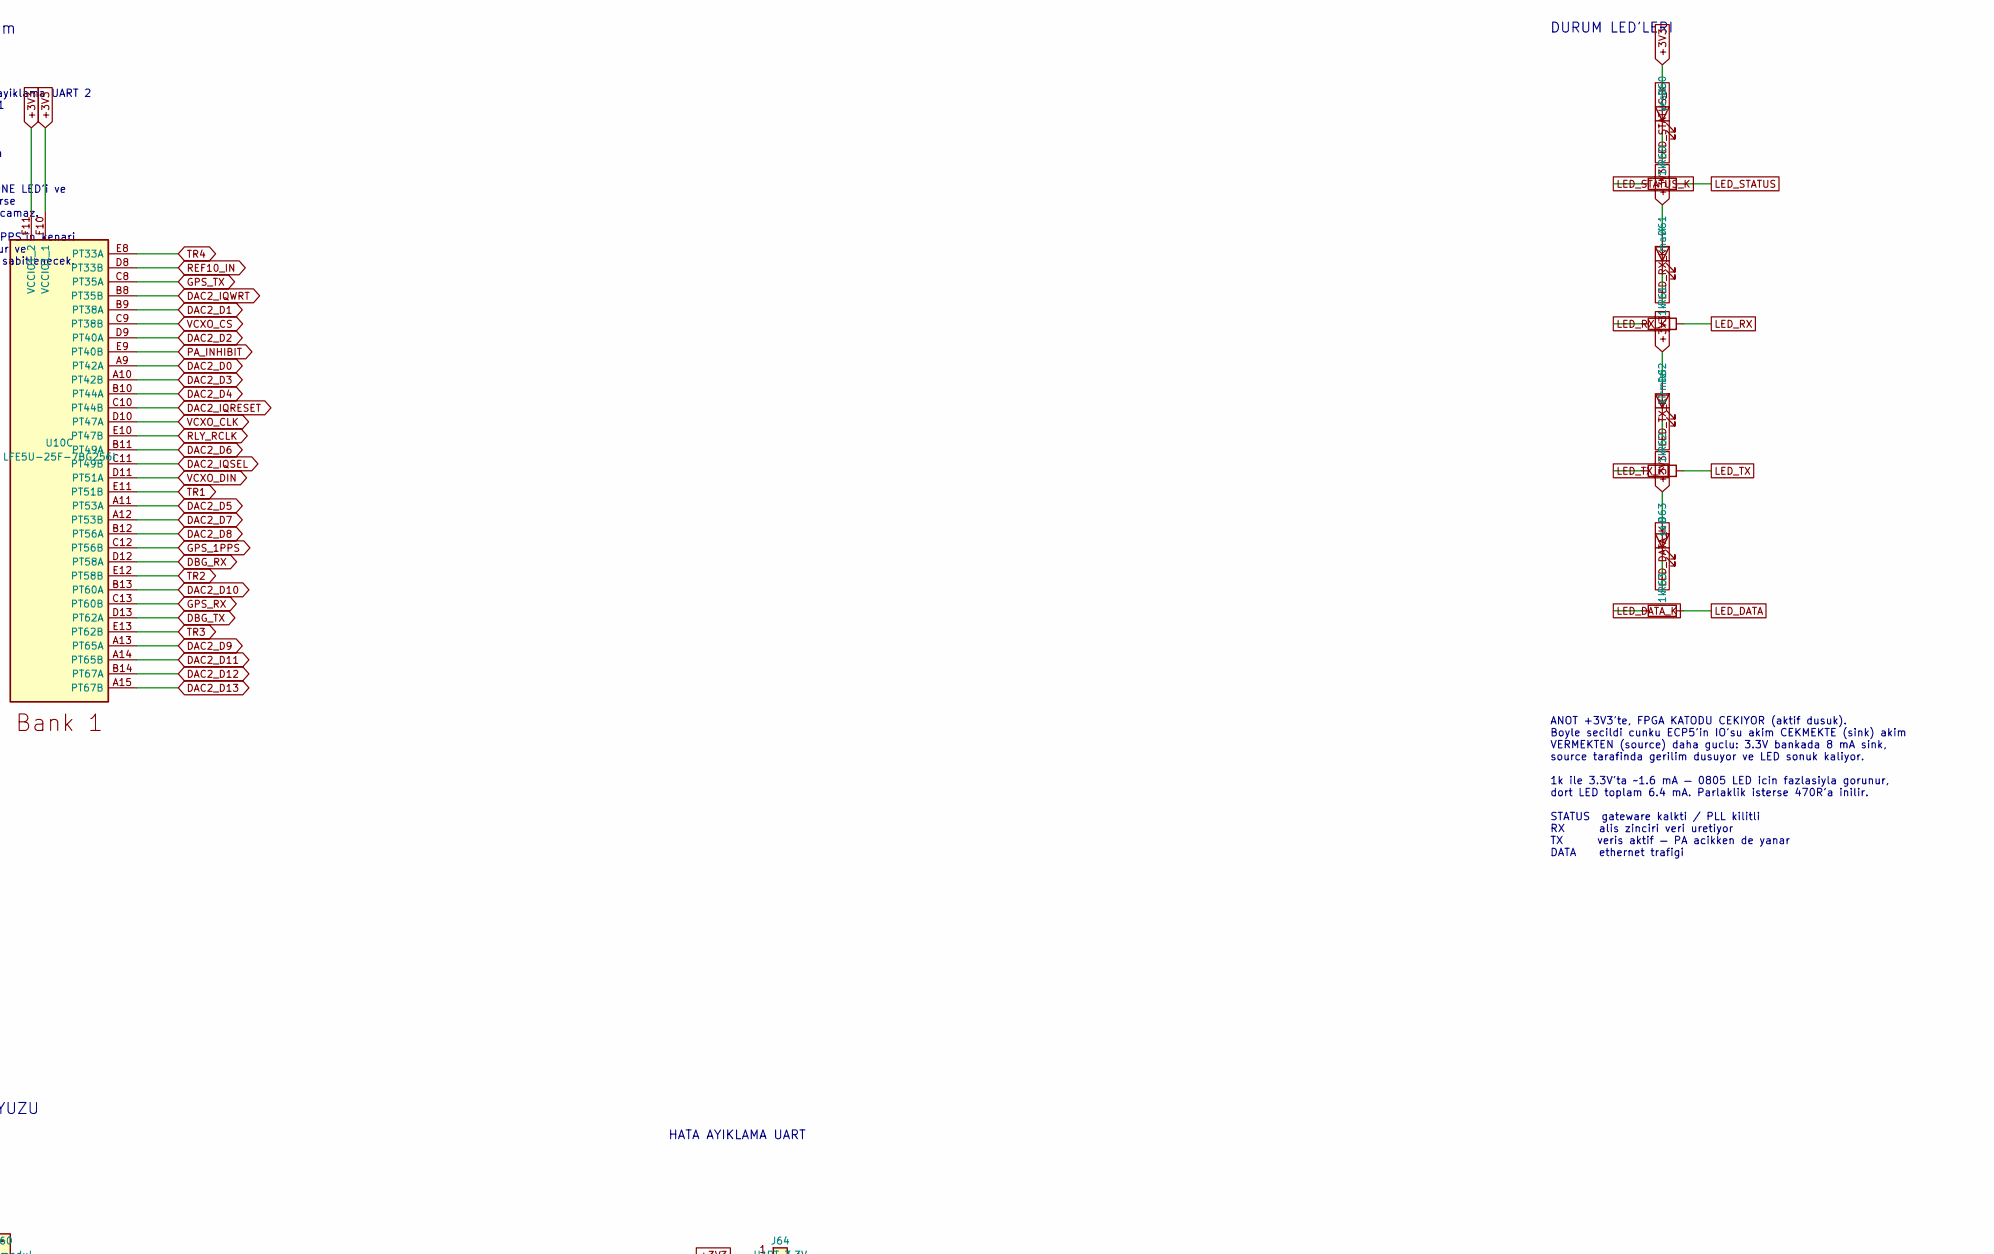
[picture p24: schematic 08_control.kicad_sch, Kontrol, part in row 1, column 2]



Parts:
C900, C901, C902: 100nF; C_0603_1608Metric
D60: yesil; LED_0805_2012Metric
D61: mavi; LED_0805_2012Metric
D62: kirmizi; LED_0805_2012Metric
D63: sari; LED_0805_2012Metric
J60: GPS modul; PinHeader_1x06_P2.54mm_Vertical
J61: SMA 10MHz ref; SMA_Amphenol_132289_EdgeMount
J62: DAC modul; PinHeader_1x06_P2.54mm_Vertical
J63: C kartina; PinHeader_2x10_P2.54mm_Vertical
J64: UART 3.3V; PinHeader_1x04_P2.54mm_Vertical
J65: C kartina #2; PinHeader_1x06_P2.54mm_Vertical
J66: D kartina; PinHeader_2x10_P2.54mm_Vertical
R60, R61, R62, R63: 1k; R_0603_1608Metric
R801: 0R; R_0603_1608Metric
R900: 50R 1%; R_0603_1608Metric
R901, R902, R903, R904: 10k; R_0603_1608Metric
U10: LFE5U-25F-7BG256I; BGA-256_14.0x14.0mm_Layout16x16_P0.8mm_Ball0.45mm_Pad0.32mm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
U62: TLV3501AIDBVR; SOT-23-6

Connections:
ADC1_nCSB: U10.B5 (PT15B); also elsewhere on the board
ADC2_nCSB: U10.B6 (PT22B); also elsewhere on the board
ADC_SCLK: U10.B4 (PT11B); also elsewhere on the board
ADC_SDIO: J66.17, U10.B3 (PT4B); also elsewhere on the board
ADC_SYNC: U10.B7 (PT27B); also elsewhere on the board
ATT1_LE: J63.19, U10.C6 (PT22A)
ATT2_LE: J65.1, U10.C7 (PT27A)
ATT3_LE: J65.2, U10.D4 (PT9B)
ATT4_LE: J65.3, U10.D5 (PT13B)
ATT_CLK: J63.18, J66.5, U10.C5 (PT15A)
ATT_DATA: J63.17, J66.3, U10.C4 (PT11A)
BIAS_CS1: J66.9, U10.D7 (PT24B)
BIAS_CS2: J66.11, U10.E4 (PT9A)
DAC2_D0: U10.A9 (PT42A); also elsewhere on the board
DAC2_D1: U10.B9 (PT38A); also elsewhere on the board
DAC2_D2: U10.D9 (PT40A); also elsewhere on the board
DAC2_D3: U10.A10 (PT42B); also elsewhere on the board
DAC2_D4: U10.B10 (PT44A); also elsewhere on the board
DAC2_D5: U10.A11 (PT53A); also elsewhere on the board
DAC2_D6: U10.B11 (PT49A); also elsewhere on the board
DAC2_D7: U10.A12 (PT53B); also elsewhere on the board
DAC2_D8: U10.B12 (PT56A); also elsewhere on the board
DAC2_D9: U10.A13 (PT65A); also elsewhere on the board
DAC2_D10: U10.B13 (PT60A); also elsewhere on the board
DAC2_D11: U10.A14 (PT65B); also elsewhere on the board
DAC2_D12: U10.B14 (PT67A); also elsewhere on the board
DAC2_D13: U10.A15 (PT67B); also elsewhere on the board
DAC2_IQRESET: U10.C10 (PT44B); also elsewhere on the board
DAC2_IQSEL: U10.C11 (PT49B); also elsewhere on the board
DAC2_IQWRT: U10.B8 (PT35B); also elsewhere on the board
DBG_RX: J64.2, U10.D12 (PT58A)
DBG_TX: J64.3, U10.D13 (PT62A)
GND_HDR: J63.2, J63.4, J63.6, J63.8, J63.10, J63.12, J63.14, J63.16, J66.2, J66.4, J66.6, J66.8, J66.10, J66.12, J66.14, J66.16, J66.18, J66.19, J66.20, R801.1
GPS_1PPS: J60.4, U10.C12 (PT56B)
GPS_RX: J60.2, U10.C13 (PT60B)
GPS_TX: J60.3, U10.C8 (PT35A)
LED_DATA: R63.2; also elsewhere on the board
LED_DATA_K: D63.1 (K), R63.1
LED_RX: R61.2; also elsewhere on the board
LED_RX_K: D61.1 (K), R61.1
LED_STATUS: R60.2; also elsewhere on the board
LED_STATUS_K: D60.1 (K), R60.1
LED_TX: R62.2; also elsewhere on the board
LED_TX_K: D62.1 (K), R62.1
PA_ADC_CS: J66.13, U10.E5 (PT13A)
PA_ATT_LE: J66.7, U10.D6 (PT20B)
PA_INHIBIT: J66.15, U10.E9 (PT40B)
REF10_AC: C900.2, R901.2, R902.1, U62.3 (+)
REF10_BIAS: C901.1, R903.2, R904.1, U62.1 (-)
REF10_IN: U10.D8 (PT33B), U62.5; also elsewhere on the board
REF10_RAW: C900.1, J61.1 (In), R900.1
RLY_RCLK: J63.7, U10.E10 (PT47B)
RLY_SER: J63.3, U10.E6 (PT20A)
RLY_SRCLK: J63.5, U10.E7 (PT24A)
SD_A9: U10.A5 (PT18A); also elsewhere on the board
SD_A10: U10.A2 (PT4A); also elsewhere on the board
SD_A11: U10.A6 (PT18B); also elsewhere on the board
SD_A12: U10.A7 (PT29A); also elsewhere on the board
SD_BA0: U10.A3 (PT6A); also elsewhere on the board
SD_BA1: U10.A4 (PT6B); also elsewhere on the board
SD_UDQM: U10.A8 (PT29B); also elsewhere on the board
TR1: J63.9, U10.E11 (PT51B)
TR2: J63.11, U10.E12 (PT58B)
TR3: J63.13, U10.E13 (PT62B)
TR4: J63.15, U10.E8 (PT33A)
VCXO_CLK: J62.3, U10.D10 (PT47A)
VCXO_CS: J62.2, U10.C9 (PT38B)
VCXO_DIN: J62.4, U10.D11 (PT51A)
VCXO_VC: J62.5; also elsewhere on the board

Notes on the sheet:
FPGA BANKA 1 — GPSDO, DAC-2, durum
KART ARASI — A <-> C, NETLIST.md §8
FPGA BANKA 0 — kontrol ve SDRAM tasmasi
ANOT +3V3'te, FPGA KATODU CEKIYOR (aktif dusuk). Boyle secildi cunku ECP5'in IO'su akim CEKMEKTE (sink) akim VERMEKTEN (source) daha guclu: 3.3V bankada 8 mA sink, source tarafinda gerilim dusuyor ve LED sonuk kaliyor. 1k ile 3.3V'ta ~1.6 mA — 0805 LED icin fazlasiyla gorunur, dort LED toplam 6.4 m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
GPS / GPSDO ARAYUZU
HER SINYALIN YANINDA TOPRAK. 2.54 mm baslikta bitisik toprak donus yolunu kisaltiyor; role hatlari 12 V anahtarliyor ve kenarlari sert, yanindaki RF'e kuplaj yapmasin. ATT2 hatlari ve +12 V ikinci baslikta (yerlesimde eklenecek). RF kart arasi koaks kuyrukla — baslikla DEGIL. Toprak GND_HDR uzerind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
BANKA 0: 24 I/O, TAMAMI DOLU. SDRAM tasmasi 7 (A9-A12, BA0/1, UDQM) ADC SPI+SYNC 5 SDIO, SCLK, 2x nCSB, SYNC ortak seri yol 2 ATT_DATA, ATT_CLK secme hatlari 7 ATT1..4_LE, PA_ATT_LE, BIAS_CS1/CS2 PA'nin ADC'si 1 PA_ADC_CS role yazmaci 3 SER/SRCLK/RCLK ADC PDWN ve DAC SLEEP hatlari KALDIRILDI. Bu al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
3.3 V TTL, CP2102/FT232 tarzi ucuz donusturucu takilir. Bringup'ta FPGA icindeki yazilim buradan konusuyor; JTAG'den once calisan tek gozlem yolu.
HATA AYIKLAMA UART
PE4312 x2, 0-31.5 dB. Her birine uc hat: Data / Clock / LE. Seri mod (P/S = HIGH). Paralel modda alti adres bacagini surmek gerekirdi, iki cip icin 12 pin ederdi. ACILIS DURUMU C KARTINDA COZULUYOR: seri modda bile acilistaki zayiflatma C0.5..C16 bacaklarindaki seviyeye gore belirleniyor (veri sayf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
HARICI 10 MHz — SMA, 50R sonlandirma, AC kuplaj, KOMPARATOR. Iki 10k bolucu orta gerilim (1.65 V) uretiyor: sinyal bacagi o gerilim etrafinda salınıyor, referans bacagi ayni gerilimde sabit (100nF ile susturulmus). Komparator birkac yuz mV'luk sinusu tam salinimli kare dalgaya ceviriyor. TLV3501AID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
D KARTINA (PA)
ZAYIFLATICI KONTROLU — cipler C KARTINDA
BANKA 1: 32/32, MARJ YOK. DAC-2 interleaved 17 · GPS 3 · VCXO DAC 3 · hata ayiklama UART 2 harici 10 MHz 1 · role RCLK 1 · T/R 4 · PA_INHIBIT 1 PA_INHIBIT yedek pini aldi. Donanim kesme hatti: FPGA sifirlaninca ya da beslemesizken D kartinda 100k asagi cekiyor ve surucu beslemesiz kaliyor. Bu hatti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
PA'nin istedigi 13 sinyal 5 YENI HATLA karsilandi: ATT_DATA / ATT_CLK -> C kartiyla ORTAK, yeni hat yok ADC_SDIO -> ortak MISO, AD9251'in hatti role zinciri -> D'ye C KARTINDAN gidiyor, A'dan degil PA_ATT_LE, BIAS_CS1, BIAS_CS2, PA_ADC_CS, PA_INHIBIT -> yeni FLANGE_T, FWD_LOG, REV_LOG analog olcuml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
DAC parcasi HENUZ SECILMEDI — 16 bit, dusuk gurultulu, SPI. Vc gurultusu dogrudan faz gurultusune donusuyor, o yuzden beslemesi +3V3_CLK (VCXO'nun kendi LDO'su). Baslik olarak cizildi; parca secilince yerine konacak.
VCXO Vc — SPI DAC
DURUM LED'LERI


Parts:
C500, C501, C502, C503, C504, C505: 100nF; C_0603_1608Metric
C506: 10uF; C_0603_1608Metric
R550: 22R; R_0603_1608Metric
U10: LFE5U-25F-7BG256I; BGA-256_14.0x14.0mm_Layout16x16_P0.8mm_Ball0.45mm_Pad0.32mm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
U50: W9825G6KH-6I; TSOP-II-54_22.2x10.16mm_P0.8mm

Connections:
SD_A0: U10.E2 (PL8B), U50.23 (A0)
SD_A1: U10.F2 (PL11C), U50.24 (A1)
SD_A2: U10.G2 (PL14B), U50.25 (A2)
SD_A3: U10.H2 (PL20B), U50.26 (A3)
SD_A4: U10.G4 (PL11B), U50.29 (A4)
SD_A5: U10.H4 (PL17B), U50.30 (A5)
SD_A6: U10.F5 (PL8D), U50.31 (A6)
SD_A7: U10.G5 (PL11A), U50.32 (A7)
SD_A8: U10.H5 (PL17A), U50.33 (A8)
SD_A9: U50.34 (A9); also elsewhere on the board
SD_A10: U50.22 (A10); also elsewhere on the board
SD_A11: U50.35 (A11); also elsewhere on the board
SD_A12: U50.36 (A12); also elsewhere on the board
SD_BA0: U50.20 (BA0); also elsewhere on the board
SD_BA1: U50.21 (BA1); also elsewhere on the board
SD_CKE: U10.J5 (PL17D), U50.37 (CKE)
SD_CLK: R550.2, U50.38 (CLK)
SD_CLK_FPGA: R550.1, U10.K1 (PL23C)
SD_DQ0: U10.B1 (PL2A), U50.2 (DQ0)
SD_DQ1: U10.C1 (PL5A), U50.4 (DQ1)
SD_DQ2: U10.D1 (PL8A), U50.5 (DQ2)
SD_DQ3: U10.E1 (PL11D), U50.7 (DQ3)
SD_DQ4: U10.F1 (PL14A), U50.8 (DQ4)
SD_DQ5: U10.G1 (PL20A), U50.10 (DQ5)
SD_DQ6: U10.B2 (PL2B), U50.11 (DQ6)
SD_DQ7: U10.C2 (PL5B), U50.13 (DQ7)
SD_DQ8: U10.K2 (PL23D), U50.42 (DQ8)
SD_DQ9: U10.C3 (PL2C), U50.44 (DQ9)
SD_DQ10: U10.D3 (PL2D), U50.45 (DQ10)
SD_DQ11: U10.E3 (PL5C), U50.47 (DQ11)
SD_DQ12: U10.F3 (PL5D), U50.48 (DQ12)
SD_DQ13: U10.G3 (PL14C), U50.50 (DQ13)
SD_DQ14: U10.H3 (PL14D), U50.51 (DQ14)
SD_DQ15: U10.F4 (PL8C), U50.53 (DQ15)
SD_LDQM: U10.K3 (PL20D), U50.15 (LDQM)
SD_UDQM: U50.39 (UDQM); also elsewhere on the board
SD_nCAS: U10.J3 (PL20C), U50.17 (~CAS)
SD_nCS: U10.J1 (PL23A), U50.19 (~CS)
SD_nRAS: U10.J2 (PL23B), U50.18 (~RAS)
SD_nWE: U10.J4 (PL17C), U50.16 (~WE)

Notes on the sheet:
SAAT SONLANDIRMA
SDRAM — W9825G6KH-6I, 32 MB
VERI YOLU — birim 1, banka 7
ADRES VE KOMUT — birim 2
BANKA 7 TAM DOLU: 16 DQ + 9 adres + 6 komut + CLK = 32/32. VERI YOLU VE STROBE TEK BANKADA. Zamanlama acisindan onemli olan bu: aynı banka = ayni IO gerilimi, ayni surucu gecikmesi, ayni sicaklik davranisi. Adresin bir kismini bankaya sigmadigi icin banka 0'a tasidik — adres hatlarinin skew'i komut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
BANKA 0'a TASAN 7 SINYAL
VDD ve VDDQ ayni +3V3 rayindan. Ayristirma: her VDD/VDDQ ciftine bir 100nF (alti adet) + toplu 10uF. 166 MHz'de akim adimlari keskin; kondansatorler bacaga en yakin, viasi dogrudan duzleme.
SD_A9, SD_A10, SD_A11, SD_A12, SD_BA0, SD_BA1, SD_UDQM ECP5 sembolunun banka 0 birimi BU SAYFADA DEGIL, 08_control'de. KiCad'de cok birimli bir sembolun her birimi projede BIR KEZ yerlestirilebiliyor; birimi buraya da koyunca kalan 17 pini 'baglanmamis' diye isaretledi. Sinyaller etiketle gidiyor, 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
CLK hattinda 22R SERI sonlandirma, FPGA cikisina yakin. Tek yuk oldugu icin seri sonlandirma yetiyor; yansimasi kaynaga donunce sonuyor. 166 MHz'de yol uzunlugu farki setup marjini yiyor — CLK ile DQ grubunu es boy cek.
Patlama yakalama icin. ECP5'in dahili blok RAM'i 1008 kbit = 126 KB, tam hizda 0.79 ms eder — meteor olayinin sadece on kenarini yakalar. 32 MB / 160 MB/s = 200 ms. 250 kat. DDR3 DEGIL, SDR. Kasten: DDR3'un fly-by yonlendirmesi, ODT'si ve kalibrasyonu rev A'ya agir yuk. SDR tek cip, duz yonlendirme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
FPGA BANKA 7 — veri yolu
GUC

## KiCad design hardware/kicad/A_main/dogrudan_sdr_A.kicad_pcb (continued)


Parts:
C100, C104: 47uF; C_1206_3216Metric
C101, C102, C103, C105: 10uF; C_0603_1608Metric
C200, C201, C202, C203, C204, C205, C210, C211, C220, C221, C222, C223, C224, C225, C226, C227, C228, C240, C241, C242, C243: 100nF; C_0402_1005Metric
D10: yesil; LED_0603_1608Metric
J10: JTAG 2x3; PinHeader_2x03_P2.54mm_Vertical
R20, R21, R36, R37, R38: 10k; R_0603_1608Metric
R31, R35: 470R; R_0603_1608Metric
R32: 4.7k; R_0603_1608Metric
R39: 1k; R_0603_1608Metric
SW1: PROG; SW_SPST_TL3342
U10: LFE5U-25F-7BG256I; BGA-256_14.0x14.0mm_Layout16x16_P0.8mm_Ball0.45mm_Pad0.32mm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
U11: W25Q128JVSIQ; SOIC-8_5.3x5.3mm_P1.27mm

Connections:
+1V8: C240.1, C241.1, C242.1, C243.1; also elsewhere on the board
CFG0: R31.1, U10.N10 (CFG0)
CFG1: R32.2, U10.P10 (CFG1)
CFG2: R35.1, U10.R10 (CFG2)
CFG_CLK: U10.N9 (MCLK/CCLK), U11.6 (CLK)
CFG_CS: U10.N8 (~HOLD/DI/BUSY/~CSSPI/PB15A), U11.1 (~CS)
CFG_HOLD: R21.2, U11.7 (~HOLD/~RESET/IO_{3})
CFG_MISO: U10.T7 (D1/POCI/IO1/PB11A), U11.2 (DO/IO_{1})
CFG_MOSI: U10.T8 (D0/PICO/IO0/PB11B), U11.5 (DI/IO_{0})
CFG_WP: R20.2, U11.3 (~WP/IO_{2})
DONE: R38.2, R39.1, U10.P9 (DONE); also elsewhere on the board
JTAG_TCK: J10.1, U10.T10 (TCK)
JTAG_TDI: J10.5, U10.R11 (TDI)
JTAG_TDO: J10.2, U10.M10 (TDO)
JTAG_TMS: J10.3, U10.T11 (TMS)
LED_RX: U10.R6 (D6/PB4B); also elsewhere on the board
nINIT: R37.2, U10.T9 (~INIT); also elsewhere on the board
nPROGRAM: R36.2, SW1.1, U10.R9 (~PROGRAM)

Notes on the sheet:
ECP5 GUC — birim 1
6 VCC (+1V1) · 2 VCCAUX (+2V5) · 13 VCCIO (9 x +3V3, 4 x +1V8) = 21 adet 0402. YERLESIM KURALI: kondansator topun ALTINDA, viasi dogrudan toprak duzlemine, kondansatorden sonra degil. Vianin endüktansı kondansatorun faydasini yiyorsa parca bosuna.
KULLANILMAYAN KONFIG BACAKLARI D2..D7, ~CS1, ~CSO/DOUT, ~WRITE, D4/PICO2, D5/POCI2 — bunlar paralel/slave modlar icin. Master SPI'da bosta. Yine de TEST NOKTASI birakiliyor: mod degistirmek gerekirse kart revizyonu degil, bir tel yeter.
JTAG
2.54 mm 2x3, kart KENARINA — kutu kapaliyken erisilebilsin. Flash BOS gelecek: ilk bitstream buradan yuklenecek, sonra flash JTAG uzerinden programlanacak. Bu baslik olmadan kartin hicbir bringup yolu yok. +3V3 pini programlayiciyi BESLEMEK icin degil, seviye referansi icin (FT2232H/ft232r tarafi 3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
~WP ve ~HOLD dogrudan +3V3'e DEGIL, 10k uzerinden. Quad SPI'a gecersek bu iki bacak IO2/IO3 oluyor; raya baglanmis olsalardi cip yanardi.
DONE acik drenaj: FPGA yuklenene kadar asagida. LED yandi = bitstream gecerli. Bringup'ta bakilacak ilk sey. SW1 ~PROGRAM'i kisa devre yapinca yeniden yukleme basliyor.
SPI ESLESMESI N8 ~CSSPI -> flash ~CS N9 MCLK -> flash CLK (kullanici bitstream'inde USRMCLK) T8 D0/PICO -> flash DI T7 D1/POCI <- flash DO PICO/POCI Lattice'in MOSI/MISO adlandirmasi.
GUC SIRALAMASI — VCCIO ONCE, CEKIRDEK SONRA U1 (VIN -> +3V3) EN girise bagli, hep acik U8 (+3V3 -> +2V5 VCCAUX) U2 (+3V3 -> +1V1 VCC) EN = PG_3V3, 3.3 V oturunca kalkar yani +3V3 (VCCIO) -> +2V5 (VCCAUX) -> +1V1 (VCC) Bu sayfada once 'VCC once, VCCIO en son' yaziyordu; YANLISTI. Lattice ECP5 Hardwa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
VCC x6 = +1V1 cekirdek · VCCAUX x2 = +2V5 · GND x27
CFG[2:0] — MOD SECIMI
TOPLU AYRISTIRMA
MASTER SPI = CFGMDN[2:0] = 010 (TN1260 Tablo 5) CFG0 = 0 470R asagi CFG1 = 1 4.7k yukari CFG2 = 0 470R asagi ** DIRENC DEGERLERI TAHMIN EDILEMEZDI. ** CFGMDN bacaklarinda DAHILI ZAYIF PULL-UP var. TN1260: 'External <500-Ohm pull-down resistors ensure that the CFGMDN pin senses a low.' Ilk cizimde h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
KONFIGURASYON — birim 8
+2V5 rayi ilk guc agacinda YOKTU. ECP5 VCCAUX'suz calismiyor; kart basilmis olsaydi tel cekilecekti. 01_power U8, ADP150-2.5, LCSC C144257.
Master SPI: FPGA acilista flash'i kendi okuyor
PIN BASINA 100nF — her besleme topu icin bir adet
KONTROL


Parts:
C1, C2: 22uF; C_0603_1608Metric
C3: 10uF; C_1206_3216Metric
C4, C6, C19, C21: 100nF; C_0603_1608Metric
C5: 10uF; C_0805_2012Metric
C10, C11, C12, C13, C14, C15, C16, C17, C22, C23: 1uF; C_0603_1608Metric
C18, C20: 10uF; C_0603_1608Metric
D1: SMBJ20A; D_SMB
D2: 12V; D_SOD-323
F1: 2A; Fuse_1206_3216Metric
FB6, FB7: ferrit 600R; L_0603_1608Metric
J1: XT60; SolderWire-1.5sqmm_1x02_P6mm_D1.7mm_OD3mm_Relief
L1, L2: 2.2uH; L_Taiyo-Yuden_NR-30xx
Q1: DMP3098L; SOT-23
R1, R2, R3: 100k; R_0603_1608Metric
R4: 32k; R_0603_1608Metric
R5: 10k; R_0603_1608Metric
R6: 26.7k; R_0603_1608Metric
U1, U2: TPS62130; VQFN-16-1EP_3x3mm_P0.5mm_EP1.68x1.68mm
U3: TPS7A2018; SOT-23-5
U4, U5, U9: ADP150-1.8; TSOT-23-5
U8: ADP150-2.5; TSOT-23-5

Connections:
+1V8: C11.1, U3.5 (OUT); also elsewhere on the board
+1V8_D: C17.1, U5.5 (VOUT); also elsewhere on the board
FB_U1: R3.2, R4.1, U1.5 (FB)
FB_U2: R5.2, R6.1, U2.5 (FB)
unnamed: D2.2 (A), Q1.1 (G), R1.1
unnamed: J1.1, Q1.3 (D)
unnamed: L1.1, U1.1 (SW), U1.2 (SW), U1.3 (SW)
unnamed: L2.1, U2.1 (SW), U2.2 (SW), U2.3 (SW)
unnamed: F1.1, Q1.2 (S)
PG_3V3: R2.2, U1.4 (PG), U2.13 (EN)

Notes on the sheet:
ADC AVDD
GUC BUTCESI ~2.8 W -> 12V'ta ~230 mA. 10 Ah aku ile ~40 saat. Saha modunda ikinci PHY yazilimdan kapatilabilir, 0.25 W kazanc.
U9 (+1V8_CLK) ADCLK846'nin VS rayi. Veri sayfasi basligi: '1.8 V, 6 LVDS/12 CMOS Output Clock Fanout Buffer'. Saat bolumu bastan 3.3 V varsayilmisti — tampon o rayda calismaz.
Vout = 0.8 x (1 + R3/R4). 3.3V icin oran 3.125 L1, Cin ve Cout datasheet Tablo 8'den.
1.1V icin oran 0.375. EN zinciri: U1 PG -> U2 EN, guc siralamasi VCC(1.1) once, sonra VCCAUX, sonra VCCIO.
+1V8 FPGA VCCIO banka 6/3
DAC AVDD FERRIT, LDO DEGIL
FB6 (+3V3_CLK) VCXO zincirinin beslemesi, FB7 (+3V3_A) DAC AVDD. Once LDO'ydular: giris +3V3, cikis 3.3 V — bir regulator kendi giris gerilimini uretemez. Ferrit + 10 uF, 2.5 MHz'te ayni bastirmayi veriyor. Besleme gurultusu DOGRUDAN faz gurultusune donusuyor — manset spec burada.
PWR_FLAG sadece VIN_PROT'ta: o ray konnektorden geliyor, gercek guc cikisi pini yok. Regulator ciktilarina bayrak konursa ERC cakisma verir.
ANA RAY +3V3 — TPS62130, 3-17V giris, 3A
FPGA CEKIRDEK +1V1 — TPS62130 #2
ADC DRVDD
AYRISTIRMA (NETLIST.md §1) her ECP5 VCC/VCCIO topu 100nF, viasi dogrudan duzleme · ECP5 toplu 4x10uF + 2x47uF ADC AVDD x8 pin basina 100nF + toplu 10uF · ADC DRVDD x4 100nF VCXO 100nF + 10uF + FERRIT BONCUK · PHY 10uF X5R (Y5V KULLANMA, datasheet s.46-53)
GIRIS VE KORUMA — NETLIST.md §9 9-17 V aku ya da tezgah kaynagi. Ters polarite sahada bir kere olur, yeter. UST SINIR 18 DEGIL 17 V. TPS62130 veri sayfasi (SLVSBC3F) tablo 7.3: onerilen calisma araligi 3-17 V; mutlak azami 20 V. 18 V yazan bir tasarimda parca veri sayfasi disinda kosuyor ve TVS de 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
FPGA VCCAUX ZORUNLU
VCXO zinciri FERRIT, LDO DEGIL
Q1 kaynagi girise, drain VIN_PROT'a. Govde diyodu ters baglamada iletmiyor. R1 gate'i asagi ceker (P-kanal icin iletim), D2 Vgs'i 12V'ta sinirlar. TVS ve sigorta drain tarafinda — koruma yukun oncesinde.
ADCLK846 VS ZORUNLU 1.8V
U8 (+2V5) ECP5 VCCAUX. Ilk guc agacinda ATLANMISTI — FPGA'yi hic calistirmayan turden bir eksik. ADP150AUJZ-2.5, LCSC C144257.
HASSAS RAYLAR — her biri AYRI LDO, AYRI ADA. Anahtarlamalidan BESLENMEZ (§1).





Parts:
C200, C202, C203, C204, C205, C208, C210, C211, C212: 100nF; C_0603_1608Metric
C201, C206: 10uF; C_0603_1608Metric
FB10: ferrit 600R; L_0603_1608Metric
R207, R209, R211, R220, R221, R222, R230: 100R; R_0603_1608Metric
R210: 220R; R_0603_1608Metric
R212, R213: 1k; R_0603_1608Metric
U15: ADCLK846BCPZ; HVQFN-24-1EP_4x4mm_P0.5mm_EP2.5x2.5mm
U16, U17, U18: SN65LVDS2DBVR; SOT-23-5
Y10: ABLNO-V-80.000MHZ; Oscillator_Abracon_ABLNO_4pad_14.3x8.7mm

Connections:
ADCLK_U20_N: R220.2, U15.23 (OUT0B); also elsewhere on the board
ADCLK_U20_P: R220.1, U15.24 (OUT0A); also elsewhere on the board
ADCLK_U21_N: R221.2, U15.20 (OUT1B); also elsewhere on the board
ADCLK_U21_P: R221.1, U15.21 (OUT1A); also elsewhere on the board
CLK80: R210.1, Y10.3 (OUT)
CLKTEST_N: R230.2, U15.8 (OUT5B)
CLKTEST_P: R230.1, U15.9 (OUT5A)
CLK_VREF: C212.1, R212.1, R213.1, U15.1 (VREF)
DAC1_CLK: U16.5 (R); also elsewhere on the board
DAC2_CLK: U17.5 (R); also elsewhere on the board
DACCLK_LV1_N: R207.2, U15.14 (OUT3B), U16.4 (B)
DACCLK_LV1_P: R207.1, U15.15 (OUT3A), U16.3 (A)
DACCLK_LV2_N: R209.2, U15.11 (OUT4B), U17.4 (B)
DACCLK_LV2_P: R209.1, U15.12 (OUT4A), U17.3 (A)
FPGA_CLK80: U18.5 (R); also elsewhere on the board
FPGA_PCLK_N: R222.2, U15.17 (OUT2B), U18.4 (B)
FPGA_PCLK_P: R222.1, U15.18 (OUT2A), U18.3 (A)
VCXO_VC: Y10.1 (VC); also elsewhere on the board

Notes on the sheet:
TEST NOKTASI
FPGA SAATI — LVDS -> 3.3 V CMOS
** BU BOLUM ILK PLANDA YOKTU. ** VCXO cikisi 3.3 V LVCMOS, ADCLK846 girisinin AZAMI seviyesi 1.8 V p-p (Tablo 1): 'Larger voltage swings can turn on the protection diodes and can degrade jitter performance.' Dogrudan baglansaydi koruma diyotlari iletime girer, jitter bozulurdu — yani aletin manset 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
ADCLK846 eklemeli jitter (Tablo 1): 54 fs rms 12 kHz - 20 MHz 86 fs rms 10 Hz - 100 MHz 150 fs rms genis bant, 1 V/ns kenar hizinda VCXO 60 fs ile birlikte: dar bant sqrt(60^2 + 54^2) = 81 fs genis bant sqrt(60^2 + 150^2) = 162 fs SNR tavani = -20*log10(2*pi*f*tj): 30 MHz @ 81 fs -> 96 dB ADC'nin k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
DAC SAATLERI — LVDS -> 3.3 V CMOS cevirici
Alti numarali cikis test icin sonlandirilmis. Bringup'ta osiloskopla saatin gercekten 80 MHz oldugu buradan gorulur — TASARIM.md §11 adim 2. Kart kenarina iki pad.
SAAT DAGITIMI — aletin manset ozelligi bu sayfada
Dort ADC kanali ve iki DAC ayni saatten besleniyor. Gurultu iptali, yon bulma ve isin sekillendirme bu dagitimin simetrisine bagli.
ADCLK846 — 1:6 LVDS
Her LVDS ciftinin ucunda 100R sonlandirma, ALICIYA yakin. AD9251 saat girisi PECL/LVDS/1.8V CMOS kabul ediyor (Rev.C), cevirici gerekmiyor. ** IKI YOL ES UZUNLUKTA. ** Cikislar arasi skew veri sayfasinda 65 ps (ayni parca uzerinde). Bu SABIT bir fark, kalibre edilebilir; yol uzunlugu farki ise sica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
Besleme gurultusu DOGRUDAN faz gurultusune donusuyor. +3V3_CLK (01_power FB6) + ikinci ferrit + ayri toprak adasi. Olculen: 90.3 fs @50 MHz, 80 MHz'de <100 fs bekleniyor. Vc GPSDO'dan (08_control), DAC ile suruluyor.
U18 cikisi FPGA_CLK80 -> U10 ball K16 (PCLKT2_0, banka 2, VCCIO +3V3). Gercek saat pini ve seviyesi birebir uyuyor. K16 bosalsin diye LED_RX banka 8'e (R6) tasindi. U18 yerlesimde U15'e YAKIN durmali: aradaki LVDS cifti ne kadar kisaysa o kadar az ortak mod gurultusu topluyor. Sonlandirma R222 alic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
SN65LVDS2DBVR — LVDS alici, LVTTL cikis, SOT-23-5. LCSC C38204, $0.36, 1244 stok. NETLIST.md §10.2c bu ceviriciyi acik madde birakmisti; kapandi. Neden FPGA'dan uretmedik: FPGA cikis jitter'i ps mertebesinde, verilen sinyalin faz gurultusune dogrudan giriyor. 36 kurusluk parca TX spektrumunu kurtar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
** VS = 1.8 V, 3.3 V DEGIL. ** Veri sayfasinin basligi: '1.8 V, 6 LVDS/12 CMOS Output Clock Fanout Buffer'. Guc agacinda saat bolumu bastan 3.3 V varsayilmisti; tampona kendi +1V8_CLK rayi eklendi (01_power U9, ADP150-1.8, +2V5'ten besleniyor — 3.3'ten dusurmek gereksiz isi uretirdi). Acik ped (25)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
JITTER BUTCESI — artik tahmin degil
VCXO — ABLNO-V, 80.000 MHz
ADC SAATLERI — LVDS, DOGRUDAN
VCXO -> TAMPON ARAYUZU — seviye uyumu SART

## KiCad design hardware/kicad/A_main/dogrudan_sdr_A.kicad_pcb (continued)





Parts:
C303, C307, C311, C315: 22pF; C_0603_1608Metric
C316, C319: 1uF; C_0603_1608Metric
C318, C321: 100nF; C_0603_1608Metric
C400, C401, C402, C403, C404, C405, C406, C407, C408, C409, C410, C411, C412, C413, C414, C415, C420, C421, C422, C423, C424, C425, C426, C427: 100nF; C_0402_1005Metric
C430, C431: 10uF; C_0402_1005Metric
J20: SMA A1; SMA_Amphenol_132289_EdgeMount
J21: SMA B1; SMA_Amphenol_132289_EdgeMount
J22: SMA A2; SMA_Amphenol_132289_EdgeMount
J23: SMA B2; SMA_Amphenol_132289_EdgeMount
R300, R304, R308, R312: 49.9R 1%; R_0603_1608Metric
R301, R302, R305, R306, R309, R310, R313, R314: 33R 1%; R_0603_1608Metric
R317, R320: 10k 1%; R_0603_1608Metric
T1, T2, T3, T4: ADT1-1WT+; Mini-Circuits_CD542_H2.84mm
U10: LFE5U-25F-7BG256I; BGA-256_14.0x14.0mm_Layout16x16_P0.8mm_Ball0.45mm_Pad0.32mm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
U20, U21: AD9251BCPZ-80; QFN-64-1EP_9x9mm_P0.5mm_EP4.7x4.7mm

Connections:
+1V8: U10.J6 (VCCIO6_1), U10.J7 (VCCIO6_2); also elsewhere on the board
+1V8_D: C420.1, C421.1, C422.1, C423.1, C424.1, C425.1, C426.1, C427.1, U20.10 (DRVDD), U20.19 (DRVDD), U20.28 (DRVDD), U20.37 (DRVDD), U21.10 (DRVDD), U21.19 (DRVDD), U21.28 (DRVDD), U21.37 (DRVDD); also elsewhere on the board
ADC1_D0: U10.M6 (PL47A), U20.27 (D0A)
ADC1_D1: U10.N1 (PL32A), U20.29 (D1A)
ADC1_D2: U10.N3 (PL35D), U20.30 (D2A)
ADC1_D3: U10.N4 (PL38A), U20.31 (D3A)
ADC1_D4: U10.P1 (PL35A), U20.32 (D4A)
ADC1_D5: U10.M5 (PL44C), U20.33 (D5A)
ADC1_D6: U10.M4 (PL35C), U20.34 (D6A)
ADC1_D7: U10.M3 (PL32D), U20.35 (D7A)
ADC1_D8: U10.L5 (PL29D), U20.36 (D8A)
ADC1_D9: U10.L4 (PL29C), U20.38 (D9A)
ADC1_D10: U10.L3 (PL32C), U20.39 (D10A)
ADC1_D11: U10.L2 (PL26B), U20.40 (D11A)
ADC1_D12: U10.L1 (PL26A), U20.41 (D12A)
ADC1_D13: U10.K5 (PL29B), U20.42 (D13A)
ADC1_DCO: U10.M1 (PL26C), U20.24 (DCOA)
ADC1_OR: U10.K4 (PL29A), U20.43 (ORA)
ADC1_nCSB: U20.46 (~CSB); also elsewhere on the board
ADC2_D0: U10.R1 (PL35B), U21.27 (D0A)
ADC2_D1: U10.P2 (PL32B), U21.29 (D1A)
ADC2_D2: U10.R2 (PL38C), U21.30 (D2A)
ADC2_D3: U10.T2 (PL38D), U21.31 (D3A)
ADC2_D4: U10.P3 (PL38B), U21.32 (D4A)
ADC2_D5: U10.R3 (PL41B), U21.33 (D5A)
ADC2_D6: U10.T3 (PL41D), U21.34 (D6A)
ADC2_D7: U10.P4 (PL41A), U21.35 (D7A)
ADC2_D8: U10.R4 (PL41C), U21.36 (D8A)
ADC2_D9: U10.T4 (PL44B), U21.38 (D9A)
ADC2_D10: U10.N5 (PL44D), U21.39 (D10A)
ADC2_D11: U10.P5 (PL47D), U21.40 (D11A)
ADC2_D12: U10.R5 (PL44A), U21.41 (D12A)
ADC2_D13: U10.N6 (PL47B), U21.42 (D13A)
ADC2_DCO: U10.M2 (PL26D), U21.24 (DCOA)
ADC2_OR: U10.P6 (PL47C), U21.43 (ORA)
ADC2_nCSB: U21.46 (~CSB); also elsewhere on the board
ADCLK_U20_N: U20.2 (CLK-); also elsewhere on the board
ADCLK_U20_P: U20.1 (CLK+); also elsewhere on the board
ADCLK_U21_N: U21.2 (CLK-); also elsewhere on the board
ADCLK_U21_P: U21.1 (CLK+); also elsewhere on the board
ADC_SCLK: U20.45 (SCLK/DFS), U21.45 (SCLK/DFS); also elsewhere on the board
ADC_SDIO: U20.44 (SDIO/DCS), U21.44 (SDIO/DCS); also elsewhere on the board
ADC_SYNC: U20.3 (SYNC), U21.3 (SYNC); also elsewhere on the board
RBIAS_U20: R317.1, U20.58 (RBIAS)
RBIAS_U21: R320.1, U21.58 (RBIAS)
RF_A1: J20.1 (In), R300.1, T1.3 (PRI_DOT)
RF_A2: J22.1 (In), R308.1, T3.3 (PRI_DOT)
RF_B1: J21.1 (In), R304.1, T2.3 (PRI_DOT)
RF_B2: J23.1 (In), R312.1, T4.3 (PRI_DOT)
SEC_A1_N: R302.1, T1.4 (SEC)
SEC_A1_P: R301.1, T1.6 (SEC_DOT)
SEC_A2_N: R310.1, T3.4 (SEC)
SEC_A2_P: R309.1, T3.6 (SEC_DOT)
SEC_B1_N: R306.1, T2.4 (SEC)
SEC_B1_P: R305.1, T2.6 (SEC_DOT)
SEC_B2_N: R314.1, T4.4 (SEC)
SEC_B2_P: R313.1, T4.6 (SEC_DOT)
VCM_U20: C318.1, T1.2 (SEC_CT), T2.2 (SEC_CT), U20.57 (VCM)
VCM_U21: C321.1, T3.2 (SEC_CT), T4.2 (SEC_CT), U21.57 (VCM)
VIN_A1_N: C303.2, R302.2, U20.52 (VIN-A)
VIN_A1_P: C303.1, R301.2, U20.51 (VIN+A)
VIN_A2_N: C311.2, R310.2, U21.52 (VIN-A)
VIN_A2_P: C311.1, R309.2, U21.51 (VIN+A)
VIN_B1_N: C307.2, R306.2, U20.61 (VIN-B)
VIN_B1_P: C307.1, R305.2, U20.62 (VIN+B)
VIN_B2_N: C315.2, R314.2, U21.61 (VIN-B)
VIN_B2_P: C315.1, R313.2, U21.62 (VIN+B)
VREF_U20: C316.1, U20.55 (VREF)
VREF_U21: C319.1, U21.55 (VREF)

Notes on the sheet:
BANKA 6 TAM DOLU: 32/32. ADC1 14 veri + DCO + OR = 16 ADC2 14 veri + DCO + OR = 16 Marj yok. Buraya bir sinyal daha gerekirse OR bayraklarindan biri feda edilir (FPGA'da doygunluk zaten tespit edilebiliyor). ** PIN ATAMASI GECICI ** — asagidaki eslesme banka 6'nin PL pinlerini sirayla dagitiyor. DC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
GUC VE KONTROL — birim 4
RC AGI BANDA GORE DEGISIYOR — AD9251 Tablo 9: 0-70 MHz giris R seri 33R, C dif 22 pF 70-200 MHz giris R seri 125R, C dif ACIK (takilmiyor) Bu alet hem tabanbant hem alt-ornekleme yapiyor, tek deger ikisine birden uymuyor. Sematikte 33R + 22pF cizili (HF/6m kullanimi). VHF/UHF alt-ornekleme icin ayn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
AD9251 ANALOG + SAAT — birim 1
ANALOG ON UC — kanal basina bir trafo
KANAL B CIKISLARI — birim 3, COGULLAMA MODUNDA BOSTA
COGULLAMA ACIK (SPI'dan). Cip basina 15 hat @160 MHz SDR, 30 hat @80 MHz yerine. Iki gerekce: 1. pin butcesi — cogullamasiz iki cip 60 pin, tutmuyor 2. GURULTU — 30 yerine 15 anahtarlanan hat, analog ucun yaninda IKI CIP DE BANKA 6'DA. Ayni bankada olmalari zamanlama eslesmesi ve faz uyumu icin sar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
AVDD 8 pin x 2 cip = 16 adet 100nF + 2 adet toplu 10uF DRVDD 4 pin x 2 cip = 8 adet 100nF AVDD kondansatorleri ANALOG toprak adasinda, DRVDD'ninkiler dijital tarafta. Ikisini karistirmak ADC'nin gurultu tabanini yukseltir — bu kartta o taban aletin butun degeri.
SPI: SDIO ve SCLK ORTAK, ~CSB cip basina ayri (banka 0). ~OEB dogrudan AGND'ye — cikislar hep acik, kontrol edilecek bir sey yok. ** ADC_SYNC IKI CIPE DE ORTAK VE ES UZUNLUKTA ** Iki ADC'nin ic bolucusunu ayni anda sifirliyor. Dort kanalin faz uyumu — yani bu aletin butun ayirt edici ozelligi: guru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
SAAT: ADCLK_U20_P/N ve ADCLK_U21_P/N, 02_clock'taki ADCLK846'nin 1 ve 2 numarali cikislari. LVDS, dogrudan baglaniyor (AD9251 saat girisi PECL/LVDS/1.8V CMOS kabul ediyor). IKI YOL ES UZUNLUKTA CEKILECEK.
SMA (C kartindan gelen filtreli RF) -> ADT1-1WT+ 1:1 -> VIN cifti Orta uc VCM'e: ortak mod 0.9 V. Giris kapasitansi 6 pF. VIN cifti ES BOY, SIKI CIFT, KISA — dort kanalin faz uyumu buradaki simetriye bagli.
FPGA BANKA 6 — verinin gittigi yer
DIJITAL CIKIS — birim 2, cogullamali
SENSE (56) DOGRUDAN AGND'ye: dahili 1.0 V referans secilir. VREF (55) 1uF ile AGND'ye. RBIAS (58) 10k %1 — %5 direnc olcek hatasi yapar, tam deger onemli. VCM CIPE OZEL: U20'ninki A1/B1 trafolarina, U21'inki A2/B2'ye. Ortak baglamak iki cikisi paralel etmek olurdu. Pin 0 = exposed paddle, cipin TEK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
AYRISTIRMA — pin basina, 0402

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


Board: 6 copper layers, 235.0 x 225.0 mm, 297 parts (17 on the bottom side), 336 nets.

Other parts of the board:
FID1, FID2, FID3:  FID; Fiducial_1mm_Mask2mm
H1, H2, H3, H4: MountingHole_3.2mm_M3
TP1:  +1V1; TestPoint_Pad_D1.5mm
TP2:  +1V8_A; TestPoint_Pad_D1.5mm
TP3:  +1V8_D; TestPoint_Pad_D1.5mm
TP4:  +2V5; TestPoint_Pad_D1.5mm
TP5:  +3V3; TestPoint_Pad_D1.5mm
TP6:  VIN_PROT; TestPoint_Pad_D1.5mm
TP7:  FPGA_CLK80; TestPoint_Pad_D1.5mm
TP8:  DONE; TestPoint_Pad_D1.5mm
TP9:  nINIT; TestPoint_Pad_D1.5mm
TP10:  REF10_IN; TestPoint_Pad_D1.5mm

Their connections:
+1V8_D: TP3.1; also elsewhere on the board
DONE: TP8.1; also elsewhere on the board
FPGA_CLK80: TP7.1; also elsewhere on the board
REF10_IN: TP10.1; also elsewhere on the board
nINIT: TP9.1; also elsewhere on the board

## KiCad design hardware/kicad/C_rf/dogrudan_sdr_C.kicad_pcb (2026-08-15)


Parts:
D101, D110, D119, D128: SMBJ20A; D_SMB
D102, D105, D106, D111, D114, D115, D120, D123, D124, D129, D132, D133: 1N4148WS; D_SOD-323
E100, E109, E118, E127: GDT 90V; GDT_Disc_D12mm_W3.9mm_P7.5mm
J1: SMA anten 1; SMA_Amphenol_132289_EdgeMount
J2: SMA anten 2; SMA_Amphenol_132289_EdgeMount
J3: SMA anten 3; SMA_Amphenol_132289_EdgeMount
J4: SMA anten 4; SMA_Amphenol_132289_EdgeMount
KT1, KT2, KT3, KT4: G6K-2F-Y; Relay_DPDT_Omron_G6K-2F-Y
QT1, QT2, QT3, QT4: 2N7002; SOT-23
R103, R112, R121, R130: 1k; R_0603_1608Metric
R104, R113, R122, R131: 100k; R_0603_1608Metric
R107, R108, R116, R117, R125, R126, R134, R135: 0R; R_0603_1608Metric

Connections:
ANT1: D101.1 (A1), E100.1, J1.1 (In), KT1.3 (COM1)
ANT2: D110.1 (A1), E109.1, J2.1 (In), KT2.3 (COM1)
ANT3: D119.1 (A1), E118.1, J3.1 (In), KT3.3 (COM1)
ANT4: D128.1 (A1), E127.1, J4.1 (In), KT4.3 (COM1)
KT1_G: QT1.1 (G), R103.2, R104.1
KT1_LO: D102.1 (K), KT1.8 (COIL-), QT1.2 (S)
KT2_G: QT2.1 (G), R112.2, R113.1
KT2_LO: D111.1 (K), KT2.8 (COIL-), QT2.2 (S)
KT3_G: QT3.1 (G), R121.2, R122.1
KT3_LO: D120.1 (K), KT3.8 (COIL-), QT3.2 (S)
KT4_G: QT4.1 (G), R130.2, R131.1
KT4_LO: D129.1 (K), KT4.8 (COIL-), QT4.2 (S)
RX1_ANT: D105.1 (K), D106.2 (A), KT1.2 (NC1), R107.1
RX1_B1_IN: R107.2; also elsewhere on the board
RX1_B1_OUT: R108.2; also elsewhere on the board
RX1_GRD: KT1.6 (COM2), KT1.7 (NC2), R108.1
RX2_ANT: D114.1 (K), D115.2 (A), KT2.2 (NC1), R116.1
RX2_B1_IN: R116.2; also elsewhere on the board
RX2_B1_OUT: R117.2; also elsewhere on the board
RX2_GRD: KT2.6 (COM2), KT2.7 (NC2), R117.1
RX3_ANT: D123.1 (K), D124.2 (A), KT3.2 (NC1), R125.1
RX3_B1_IN: R125.2; also elsewhere on the board
RX3_B1_OUT: R126.2; also elsewhere on the board
RX3_GRD: KT3.6 (COM2), KT3.7 (NC2), R126.1
RX4_ANT: D132.1 (K), D133.2 (A), KT4.2 (NC1), R134.1
RX4_B1_IN: R134.2; also elsewhere on the board
RX4_B1_OUT: R135.2; also elsewhere on the board
RX4_GRD: KT4.6 (COM2), KT4.7 (NC2), R135.1
TR1: R103.1; also elsewhere on the board
TR2: R112.1; also elsewhere on the board
TR3: R121.1; also elsewhere on the board
TR4: R130.1; also elsewhere on the board
TX1: KT1.4 (NO1); also elsewhere on the board
TX2: KT2.4 (NO1); also elsewhere on the board
TX3: KT3.4 (NO1); also elsewhere on the board
TX4: KT4.4 (NO1); also elsewhere on the board

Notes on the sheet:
UC KATMAN, UC FARKLI ZAMAN OLCEGI 1 gaz desarj tupu yildirim/statik, kilovolt, mikrosaniye 2 TVS hizli gecici, nanosaniye, surekli guc TASIMAZ 3 diyot limitleyici yakindaki verici, SUREKLI calisir, kilovolt gorurse olur Biri digerinin yerine gecmiyor. Okul istasyonunda kendi vericimiz ayni catida; 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
T/R ROLESI KILITLENMEYEN — GUVENLIK Filtre bankasindaki roleler kilitlenen (guc butcesi icin). T/R'da tam tersi gerekiyor: kilitlenen role gucsuz kaldigi konumu KORUR, yani guc kesilse ya da firmware cokse anten PA'ya bagli kalir ve alici girisine 100 W dusebilir. G6K-2F-Y (kilitlenmeyen) birakildi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
** BU KART MILIVAT TARAFI ** G6KU sinyal rolesi: 0.3 A / 30 V. 100 W'ta 50 ohm'da 70 V rms ve 1.4 A var — bu role onu anahtarlayamaz, kontaklari yapisir. PA cikisindaki anten anahtari AYRI ve GUCLU, D2 kartinda. Buradaki T/R sadece milivat seviyesindeki DAC cikisini ve alis yolunu anahtarliyor. PA'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
Dort zincir BIREBIR AYNI. Faz uyumu antende basliyor: yollarin genlik ve faz cevabi ayni degilse gurultu iptali, yon bulma ve isin sekillendirme calismaz. Bu yuzden 'birine su, otekine bu' yok — ne yapiliyorsa dort kere yapiliyor.
KORUMA VE T/R — kanal basina ozdes zincir

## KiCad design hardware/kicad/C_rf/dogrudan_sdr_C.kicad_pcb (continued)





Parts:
C1001, C1003, C1037, C1039, C1073, C1075, C1109, C1111: 6800pF; C_0603_1608Metric
C1005, C1011, C1041, C1047, C1077, C1083, C1113, C1119: 390pF; C_0603_1608Metric
C1007, C1009, C1043, C1045, C1079, C1081, C1115, C1117: 1200pF; C_0603_1608Metric
C1013, C1015, C1049, C1051, C1085, C1087, C1121, C1123: 680pF; C_0603_1608Metric
C1017, C1053, C1089, C1125: 180pF; C_0603_1608Metric
C1019, C1021, C1055, C1057, C1091, C1093, C1127, C1129: 470pF; C_0603_1608Metric
C1023, C1059, C1095, C1131: 68pF; C_0603_1608Metric
C1025, C1027, C1031, C1033, C1061, C1063, C1067, C1069, C1097, C1099, C1103, C1105, C1133, C1135, C1139, C1141: 270pF; C_0603_1608Metric
C1029, C1065, C1101, C1137: 56pF; C_0603_1608Metric
C1035, C1071, C1107, C1143: 12pF; C_0603_1608Metric
K11, K12, K13, K14, K15, K16, K17, K21, K22, K23, K24, K25, K26, K27, K31, K32, K33, K34, K35, K36, K37, K41, K42, K43, K44, K45, K46, K47: G6KU-2F-Y; Relay_DPDT_Omron_G6K-2F-Y
L1000, L1002, L1006, L1008, L1036, L1038, L1042, L1044, L1072, L1074, L1078, L1080, L1108, L1110, L1114, L1116: 1uH; L_1210_3225Metric
L1004, L1040, L1076, L1112: 18uH; L_1210_3225Metric
L1010, L1046, L1082, L1118: 3.3uH; L_1210_3225Metric
L1012, L1014, L1048, L1050, L1084, L1086, L1120, L1122: 470nH; L_0805_2012Metric
L1016, L1052, L1088, L1124: 2.2uH; L_1210_3225Metric
L1018, L1020, L1054, L1056, L1090, L1092, L1126, L1128: 220nH; L_0603_1608Metric
L1022, L1058, L1094, L1130: 1.5uH; L_1210_3225Metric
L1024, L1026, L1060, L1062, L1096, L1098, L1132, L1134: 150nH; L_0603_1608Metric
L1028, L1064, L1100, L1136: 680nH; L_1210_3225Metric
L1030, L1032, L1066, L1068, L1102, L1104, L1138, L1140: 33nH; L_0603_1608Metric
L1034, L1070, L1106, L1142: 820nH; L_1210_3225Metric

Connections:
F11_A: C1001.1, K11.4 (N1B), L1000.1, L1004.1
F11_B: C1003.1, C1005.2, K11.5 (N2B), L1002.1
F12_A: C1007.1, K12.4 (N1B), L1006.1, L1010.1
F12_B: C1009.1, C1011.2, K12.5 (N2B), L1008.1
F13_A: C1013.1, K13.4 (N1B), L1012.1, L1016.1
F13_B: C1015.1, C1017.2, K13.5 (N2B), L1014.1
F14_A: C1019.1, K14.4 (N1B), L1018.1, L1022.1
F14_B: C1021.1, C1023.2, K14.5 (N2B), L1020.1
F15_A: C1025.1, K15.4 (N1B), L1024.1, L1028.1
F15_B: C1027.1, C1029.2, K15.5 (N2B), L1026.1
F16_A: C1031.1, K16.4 (N1B), L1030.1, L1034.1
F16_B: C1033.1, C1035.2, K16.5 (N2B), L1032.1
F21_A: C1037.1, K21.4 (N1B), L1036.1, L1040.1
F21_B: C1039.1, C1041.2, K21.5 (N2B), L1038.1
F22_A: C1043.1, K22.4 (N1B), L1042.1, L1046.1
F22_B: C1045.1, C1047.2, K22.5 (N2B), L1044.1
F23_A: C1049.1, K23.4 (N1B), L1048.1, L1052.1
F23_B: C1051.1, C1053.2, K23.5 (N2B), L1050.1
F24_A: C1055.1, K24.4 (N1B), L1054.1, L1058.1
F24_B: C1057.1, C1059.2, K24.5 (N2B), L1056.1
F25_A: C1061.1, K25.4 (N1B), L1060.1, L1064.1
F25_B: C1063.1, C1065.2, K25.5 (N2B), L1062.1
F26_A: C1067.1, K26.4 (N1B), L1066.1, L1070.1
F26_B: C1069.1, C1071.2, K26.5 (N2B), L1068.1
F31_A: C1073.1, K31.4 (N1B), L1072.1, L1076.1
F31_B: C1075.1, C1077.2, K31.5 (N2B), L1074.1
F32_A: C1079.1, K32.4 (N1B), L1078.1, L1082.1
F32_B: C1081.1, C1083.2, K32.5 (N2B), L1080.1
F33_A: C1085.1, K33.4 (N1B), L1084.1, L1088.1
F33_B: C1087.1, C1089.2, K33.5 (N2B), L1086.1
F34_A: C1091.1, K34.4 (N1B), L1090.1, L1094.1
F34_B: C1093.1, C1095.2, K34.5 (N2B), L1092.1
F35_A: C1097.1, K35.4 (N1B), L1096.1, L1100.1
F35_B: C1099.1, C1101.2, K35.5 (N2B), L1098.1
F36_A: C1103.1, K36.4 (N1B), L1102.1, L1106.1
F36_B: C1105.1, C1107.2, K36.5 (N2B), L1104.1
F41_A: C1109.1, K41.4 (N1B), L1108.1, L1112.1
F41_B: C1111.1, C1113.2, K41.5 (N2B), L1110.1
F42_A: C1115.1, K42.4 (N1B), L1114.1, L1118.1
F42_B: C1117.1, C1119.2, K42.5 (N2B), L1116.1
F43_A: C1121.1, K43.4 (N1B), L1120.1, L1124.1
F43_B: C1123.1, C1125.2, K43.5 (N2B), L1122.1
F44_A: C1127.1, K44.4 (N1B), L1126.1, L1130.1
F44_B: C1129.1, C1131.2, K44.5 (N2B), L1128.1
F45_A: C1133.1, K45.4 (N1B), L1132.1, L1136.1
F45_B: C1135.1, C1137.2, K45.5 (N2B), L1134.1
F46_A: C1139.1, K46.4 (N1B), L1138.1, L1142.1
F46_B: C1141.1, C1143.2, K46.5 (N2B), L1140.1
K11_R: K11.8 (COIL_R); also elsewhere on the board
K11_S: K11.1 (COIL_S); also elsewhere on the board
K12_R: K12.8 (COIL_R); also elsewhere on the board
K12_S: K12.1 (COIL_S); also elsewhere on the board
K13_R: K13.8 (COIL_R); also elsewhere on the board
K13_S: K13.1 (COIL_S); also elsewhere on the board
K14_R: K14.8 (COIL_R); also elsewhere on the board
K14_S: K14.1 (COIL_S); also elsewhere on the board
K15_R: K15.8 (COIL_R); also elsewhere on the board
K15_S: K15.1 (COIL_S); also elsewhere on the board
K16_R: K16.8 (COIL_R); also elsewhere on the board
K16_S: K16.1 (COIL_S); also elsewhere on the board
K17_R: K17.8 (COIL_R); also elsewhere on the board
K17_S: K17.1 (COIL_S); also elsewhere on the board
K21_R: K21.8 (COIL_R); also elsewhere on the board
K21_S: K21.1 (COIL_S); also elsewhere on the board
K22_R: K22.8 (COIL_R); also elsewhere on the board
K22_S: K22.1 (COIL_S); also elsewhere on the board
K23_R: K23.8 (COIL_R); also elsewhere on the board
K23_S: K23.1 (COIL_S); also elsewhere on the board
K24_R: K24.8 (COIL_R); also elsewhere on the board
K24_S: K24.1 (COIL_S); also elsewhere on the board
K25_R: K25.8 (COIL_R); also elsewhere on the board
K25_S: K25.1 (COIL_S); also elsewhere on the board
K26_R: K26.8 (COIL_R); also elsewhere on the board
K26_S: K26.1 (COIL_S); also elsewhere on the board
K27_R: K27.8 (COIL_R); also elsewhere on the board
K27_S: K27.1 (COIL_S); also elsewhere on the board
K31_R: K31.8 (COIL_R); also elsewhere on the board
K31_S: K31.1 (COIL_S); also elsewhere on the board
K32_R: K32.8 (COIL_R); also elsewhere on the board
K32_S: K32.1 (COIL_S); also elsewhere on the board
K33_R: K33.8 (COIL_R); also elsewhere on the board
K33_S: K33.1 (COIL_S); also elsewhere on the board
K34_R: K34.8 (COIL_R); also elsewhere on the board
K34_S: K34.1 (COIL_S); also elsewhere on the board
K35_R: K35.8 (COIL_R); also elsewhere on the board
K35_S: K35.1 (COIL_S); also elsewhere on the board
K36_R: K36.8 (COIL_R); also elsewhere on the board
K36_S: K36.1 (COIL_S); also elsewhere on the board
K37_R: K37.8 (COIL_R); also elsewhere on the board
K37_S: K37.1 (COIL_S); also elsewhere on the board
K41_R: K41.8 (COIL_R); also elsewhere on the board
K41_S: K41.1 (COIL_S); also elsewhere on the board
K42_R: K42.8 (COIL_R); also elsewhere on the board
K42_S: K42.1 (COIL_S); also elsewhere on the board
K43_R: K43.8 (COIL_R); also elsewhere on the board
K43_S: K43.1 (COIL_S); also elsewhere on the board
K44_R: K44.8 (COIL_R); also elsewhere on the board
K44_S: K44.1 (COIL_S); also elsewhere on the board
K45_R: K45.8 (COIL_R); also elsewhere on the board
K45_S: K45.1 (COIL_S); also elsewhere on the board
K46_R: K46.8 (COIL_R); also elsewhere on the board
K46_S: K46.1 (COIL_S); also elsewhere on the board
K47_R: K47.8 (COIL_R); also elsewhere on the board
K47_S: K47.1 (COIL_S); also elsewhere on the board
N11_S: C1005.1, L1004.2
N12_S: C1011.1, L1010.2
N13_S: C1017.1, L1016.2
N14_S: C1023.1, L1022.2
N15_S: C1029.1, L1028.2
N16_S: C1035.1, L1034.2
N21_S: C1041.1, L1040.2
N22_S: C1047.1, L1046.2
N23_S: C1053.1, L1052.2
N24_S: C1059.1, L1058.2
N25_S: C1065.1, L1064.2
N26_S: C1071.1, L1070.2
N31_S: C1077.1, L1076.2
N32_S: C1083.1, L1082.2
N33_S: C1089.1, L1088.2
N34_S: C1095.1, L1094.2
N35_S: C1101.1, L1100.2
N36_S: C1107.1, L1106.2
N41_S: C1113.1, L1112.2
N42_S: C1119.1, L1118.2
N43_S: C1125.1, L1124.2
N44_S: C1131.1, L1130.2
N45_S: C1137.1, L1136.2
N46_S: C1143.1, L1142.2
RX1_B1_IN: K11.3 (COM1); also elsewhere on the board
RX1_B1_OUT: K11.6 (COM2); also elsewhere on the board
RX1_B2_IN: K11.2 (N1A), K12.3 (COM1)
RX1_B2_OUT: K11.7 (N2A), K12.6 (COM2)
RX1_B3_IN: K12.2 (N1A), K13.3 (COM1)
RX1_B3_OUT: K12.7 (N2A), K13.6 (COM2)
RX1_B4_IN: K13.2 (N1A), K14.3 (COM1)
RX1_B4_OUT: K13.7 (N2A), K14.6 (COM2)
RX1_B5_IN: K14.2 (N1A), K15.3 (COM1)
RX1_B5_OUT: K14.7 (N2A), K15.6 (COM2)
RX1_B6_IN: K15.2 (N1A), K16.3 (COM1)
RX1_B6_OUT: K15.7 (N2A), K16.6 (COM2)
RX1_B7_IN: K16.2 (N1A), K17.3 (COM1)
RX1_B7_OUT: K16.7 (N2A), K17.6 (COM2)
RX1_FILT: K17.2 (N1A), K17.4 (N1B), K17.5 (N2B), K17.7 (N2A); also elsewhere on the board
RX2_B1_IN: K21.3 (COM1); also elsewhere on the board
RX2_B1_OUT: K21.6 (COM2); also elsewhere on the board
RX2_B2_IN: K21.2 (N1A), K22.3 (COM1)
RX2_B2_OUT: K21.7 (N2A), K22.6 (COM2)
RX2_B3_IN: K22.2 (N1A), K23.3 (COM1)
RX2_B3_OUT: K22.7 (N2A), K23.6 (COM2)
RX2_B4_IN: K23.2 (N1A), K24.3 (COM1)
RX2_B4_OUT: K23.7 (N2A), K24.6 (COM2)
RX2_B5_IN: K24.2 (N1A), K25.3 (COM1)
RX2_B5_OUT: K24.7 (N2A), K25.6 (COM2)
RX2_B6_IN: K25.2 (N1A), K26.3 (COM1)
RX2_B6_OUT: K25.7 (N2A), K26.6 (COM2)
RX2_B7_IN: K26.2 (N1A), K27.3 (COM1)
RX2_B7_OUT: K26.7 (N2A), K27.6 (COM2)
RX2_FILT: K27.2 (N1A), K27.4 (N1B), K27.5 (N2B), K27.7 (N2A); also elsewhere on the board
RX3_B1_IN: K31.3 (COM1); also elsewhere on the board
RX3_B1_OUT: K31.6 (COM2); also elsewhere on the board
RX3_B2_IN: K31.2 (N1A), K32.3 (COM1)
RX3_B2_OUT: K31.7 (N2A), K32.6 (COM2)
RX3_B3_IN: K32.2 (N1A), K33.3 (COM1)
RX3_B3_OUT: K32.7 (N2A), K33.6 (COM2)
RX3_B4_IN: K33.2 (N1A), K34.3 (COM1)
RX3_B4_OUT: K33.7 (N2A), K34.6 (COM2)
RX3_B5_IN: K34.2 (N1A), K35.3 (COM1)
RX3_B5_OUT: K34.7 (N2A), K35.6 (COM2)
RX3_B6_IN: K35.2 (N1A), K36.3 (COM1)
RX3_B6_OUT: K35.7 (N2A), K36.6 (COM2)
RX3_B7_IN: K36.2 (N1A), K37.3 (COM1)
RX3_B7_OUT: K36.7 (N2A), K37.6 (COM2)
RX3_FILT: K37.2 (N1A), K37.4 (N1B), K37.5 (N2B), K37.7 (N2A); also elsewhere on the board
RX4_B1_IN: K41.3 (COM1); also elsewhere on the board
RX4_B1_OUT: K41.6 (COM2); also elsewhere on the board
RX4_B2_IN: K41.2 (N1A), K42.3 (COM1)
RX4_B2_OUT: K41.7 (N2A), K42.6 (COM2)
RX4_B3_IN: K42.2 (N1A), K43.3 (COM1)
RX4_B3_OUT: K42.7 (N2A), K43.6 (COM2)
RX4_B4_IN: K43.2 (N1A), K44.3 (COM1)
RX4_B4_OUT: K43.7 (N2A), K44.6 (COM2)
RX4_B5_IN: K44.2 (N1A), K45.3 (COM1)
RX4_B5_OUT: K44.7 (N2A), K45.6 (COM2)
RX4_B6_IN: K45.2 (N1A), K46.3 (COM1)
RX4_B6_OUT: K45.7 (N2A), K46.6 (COM2)
RX4_B7_IN: K46.2 (N1A), K47.3 (COM1)
RX4_B7_OUT: K46.7 (N2A), K47.6 (COM2)
RX4_FILT: K47.2 (N1A), K47.4 (N1B), K47.5 (N2B), K47.7 (N2A); also elsewhere on the board

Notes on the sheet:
KANAL 4
Uc rezonatorlu, tepeden kapasitif kuplajli Chebyshev 0.1 dB. Rezonator reaktansi 200 ohm hedeflendi (once kapasiteyi sabit tutmustum, 160m'de 68 uH cikmisti — o degerde RF bobini yok). bant f0 BW L Crez Ckup Cuc IL 160m 1.89 0.30 16uH 430p 62p 270p 3.5/0.5 dB 80/60m 4.32 2.10 7.5uH 180p 82p 390p 0.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
KANAL 2
BANT FILTRESI BANKASI — 7 pozisyon x 4 kanal
** 160m VE 6m TOROID ** O iki bantta SMD bobinin Q'su cokuyor (160m'de 16 uH'lik parca ferrit cekirdekli guc bobini, Q=25 -> 3.5 dB ekleme kaybi). Alicida on yukseltec YOK, kayip dogrudan duyarliliktan dusuyor. Toz demir toroid (T50-2/T50-6) Q=180 veriyor, kayip 0.5 dB'ye iniyor. Diger dort bantta 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
DEGERLER — filtre_hesap.py
KANAL 3
ROLE SURUCUSU — 05_driver G6KU TEK SARIMLI kilitlenen: bobine verilen gerilimin YONU konumu belirliyor. Acik drenaj surucu yetmiyor, H koprusu sart. Her role icin K__S ve K__R hatti, DRV8833'un iki girisi. 28 role (7 pozisyon x 4 kanal) + 4 T/R = 32 role 32 role x 2 hat = 64 hat -> 8 x 74HC595 32 b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
Roleler ZINCIRLI: her role kendi bandini secmezse sinyali bir sonraki bolume geciriyor (N1A/N2A). Hicbiri secilmezse sinyal zincirin sonundaki BYPASS'a dusuyor. Tek anda tek role cekili. Bir role 2 Form C: HEM girisi HEM cikisi anahtarliyor. Ayri giris/cikis rolesi kullansaydik adet iki katina cika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
Bypass rolesinin iki konumu da RX_FILT'e gidiyor: bu pozisyon filtre YOK demek, dogrudan gecis. VHF/UHF alt-ornekleme, uydu, radiosonde ve genel tarama buradan. Zincirin sonu oldugu icin hicbir bant secilmediginde de sinyal buraya dusuyor — yani varsayilan durum GENIS BANT. Acilista roleler bilinme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
KANAL 1
BYPASS — 7. pozisyon

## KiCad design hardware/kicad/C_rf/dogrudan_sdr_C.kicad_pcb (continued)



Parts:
C407, C408, C416, C417, C425, C426, C434, C435: 100nF; C_0402_1005Metric
R400, R401, R402, R403, R404, R405, R406, R409, R410, R411, R412, R413, R414, R415, R418, R419, R420, R421, R422, R423, R424, R427, R428, R429, R430, R431, R432, R433: 10k; R_0603_1608Metric
U40, U41, U42, U43: PE4312C-Z; TQFN-20-1EP_4x4mm_P0.5mm_EP2.1x2.1mm

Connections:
+3V3: C407.1, C408.1, C416.1, C417.1, C425.1, C426.1, C434.1, C435.1, R401.1, R402.1, R403.1, R404.1, R405.1, R406.1, R410.1, R411.1, R412.1, R413.1, R414.1, R415.1, R419.1, R420.1, R421.1, R422.1, R423.1, R424.1, R428.1, R429.1, R430.1, R431.1, R432.1, R433.1, U40.6 (VDD), U40.9 (VDD), U40.13 (P/S), U41.6 (VDD), U41.9 (VDD), U41.13 (P/S), U42.6 (VDD), U42.9 (VDD), U42.13 (P/S), U43.6 (VDD), U43.9 (VDD), U43.13 (P/S); also elsewhere on the board
ATT1_C0: R401.2, U40.1 (C16)
ATT1_C1: R402.2, U40.15 (C8)
ATT1_C2: R403.2, U40.16 (C4)
ATT1_C3: R404.2, U40.17 (C2)
ATT1_C4: R405.2, U40.19 (C1)
ATT1_C5: R406.2, U40.20 (C0.5)
ATT1_DAT: R400.2, U40.3 (Data)
ATT1_LE: U40.5 (LE); also elsewhere on the board
ATT2_C0: R410.2, U41.1 (C16)
ATT2_C1: R411.2, U41.15 (C8)
ATT2_C2: R412.2, U41.16 (C4)
ATT2_C3: R413.2, U41.17 (C2)
ATT2_C4: R414.2, U41.19 (C1)
ATT2_C5: R415.2, U41.20 (C0.5)
ATT2_DAT: R409.2, U41.3 (Data)
ATT2_LE: U41.5 (LE); also elsewhere on the board
ATT3_C0: R419.2, U42.1 (C16)
ATT3_C1: R420.2, U42.15 (C8)
ATT3_C2: R421.2, U42.16 (C4)
ATT3_C3: R422.2, U42.17 (C2)
ATT3_C4: R423.2, U42.19 (C1)
ATT3_C5: R424.2, U42.20 (C0.5)
ATT3_DAT: R418.2, U42.3 (Data)
ATT3_LE: U42.5 (LE); also elsewhere on the board
ATT4_C0: R428.2, U43.1 (C16)
ATT4_C1: R429.2, U43.15 (C8)
ATT4_C2: R430.2, U43.16 (C4)
ATT4_C3: R431.2, U43.17 (C2)
ATT4_C4: R432.2, U43.19 (C1)
ATT4_C5: R433.2, U43.20 (C0.5)
ATT4_DAT: R427.2, U43.3 (Data)
ATT4_LE: U43.5 (LE); also elsewhere on the board
ATT_CLK: U40.4 (Clock), U41.4 (Clock), U42.4 (Clock), U43.4 (Clock); also elsewhere on the board
ATT_DATA: R400.1, R409.1, R418.1, R427.1; also elsewhere on the board
RX1_FILT: U40.2 (RF1); also elsewhere on the board
RX1_OUT: U40.14 (RF2); also elsewhere on the board
RX2_FILT: U41.2 (RF1); also elsewhere on the board
RX2_OUT: U41.14 (RF2); also elsewhere on the board
RX3_FILT: U42.2 (RF1); also elsewhere on the board
RX3_OUT: U42.14 (RF2); also elsewhere on the board
RX4_FILT: U43.2 (RF1); also elsewhere on the board
RX4_OUT: U43.14 (RF2); also elsewhere on the board

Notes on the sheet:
ZAYIFLATICILAR — PE4312 x4, 0-31.5 dB
P/S = +3V3 -> SERI mod. Paralel modda alti C bacagini surmek gerekirdi: dort cip icin 24 hat. Seri hatta uc hat yetiyor (Data, Clock ortak + LE). Data ve Clock ortak oldugu icin dort cip ayni veriyi goruyor; hangisine yazilacagini LE belirliyor. Firmware sirayla LE darbeliyor. Dort kanal ayni zayif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
ACILIS DURUMU — KRITIK Veri sayfasi s.6: 'When the attenuator powers up in serial mode (P/S = 1), the six control bits are set to whatever data is present on the six parallel data inputs (C0.5 to C16).' Yani SERI modda bile acilis zayiflatmasini o alti bacak belirliyor. Bos birakilsalardi tanimsiz 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
DORT KANAL, DORT ZAYIFLATICI. Sartnamede iki taneydi; faz uyumu zincirlerin ozdes olmasini sart kosuyor, iki kanal zayiflatilip ikisi zayiflatilmadan birakilamaz. A kartinda ayrilan hat sayisi degismedi: Data ve Clock DORT CIPTE DE ORTAK, LE'ler ayri. 2 + 4 = 6 hat — ilk planda iki cipe ucer hat ol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

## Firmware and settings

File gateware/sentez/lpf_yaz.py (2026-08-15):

#!/usr/bin/env python3
# SPDX-FileCopyrightText: Copyright (c) 2026 TA4DTA
# SPDX-License-Identifier: GPL-3.0-only
"""LPF'i KARTTAN uret, elle yazma.

    python3 sentez/lpf_yaz.py            # sentez/ust.lpf yazar

NEDEN URETILIYOR. Pin kisit dosyasini elle tutmak, kart degistiginde
sessizce yanlis kalan ikinci bir gercek kaynagi demek. Bir ball yanlis
yazilirsa sentez de yerlestirme de sorunsuz gecer; hata ancak kart
elde, olcu aletiyle bulunur. Kartin kendisi tek kaynak olsun.

BU ARAC AYRICA DENETCI. Ust modulun her portu icin kartta bir ag
aramak zorunda oldugu icin, karsiligi olmayan portu ve suruclenmeyen
onemli agi hemen bildiriyor. Boyle uc bosluk zaten bulundu: rst_n'in
kartta pini yoktu, dac_clk kartta FPGA'dan degil saat agacindan
geliyordu, ve kayit arayuzunun hicbir yere baglanmadigi icin
gateware'i yapilandirmanin YOLU YOKTU.
"""
import json
import os
import re
import sys

import pcbnew

KOK = os.path.dirname(os.path.dirname(os.path.abspath(__file__)))
KART = os.path.join(os.path.dirname(KOK), "kicad",
                    "A_main", "dogrudan_sdr_A.kicad_pcb")
IODB = ("/home/cinar/opt/oss-cad-suite/share/trellis/database/"
        "ECP5/LFE5U-25F/iodb.json")
PAKET = "CABGA256"

# ust.v portu -> karttaki ag adi.
# Demetler icin {i} indeksle genisletiliyor.
ESLEME = [
    # clk_sys VCXO_CLK'e baglanmiyor. VCXO_CLK bir FPGA CIKISI —
    # J62'ye giden, VCXO varaktorunu suren SPI DAC'inin SCK'si.
    # Sistem saati ADCLK846 -> SN65LVDS2 (U18) -> FPGA_CLK80 yolundan
    # geliyor ve K16 (PCLKT2_0) gercek saat pini.
    ("clk_sys",      "FPGA_CLK80",    None),
    ("adc1_dco",     "ADC1_DCO",      None),
    ("adc1_d",       "ADC1_D{i}",     14),
    ("adc1_or",      "ADC1_OR",       None),
    ("adc2_dco",     "ADC2_DCO",      None),
    ("adc2_d",       "ADC2_D{i}",     14),
    ("adc2_or",      "ADC2_OR",       None),
    ("dac_a",        "DAC1_P1_D{i}",  14),
    ("dac_wrt_a",    "DAC1_WRT1",     None),
    # DORT VERIS KANALI: U30 cift port (P1+P2), U31 cogullanmis.
    ("dac_b",        "DAC1_P2_D{i}",  14),
    ("dac_wrt_b",    "DAC1_WRT2",     None),
    ("dac2_d",       "DAC2_D{i}",     14),
    ("dac2_iqwrt",   "DAC2_IQWRT",    None),
    ("dac2_iqsel",   "DAC2_IQSEL",    None),
    ("dac2_iqreset", "DAC2_IQRESET",  None),
    ("rgmii_td",     "PHY1_TXD{i}",   4),
    # ALIS: saat PHY'den geliyor, RXC bir GIRIS saati.
    ("rgmii_rd",     "PHY1_RXD{i}",  4),
    ("rgmii_rctl",   "PHY1_RXCTL",   None),
    ("rgmii_rxc",    "PHY1_RXC",     None),
    ("rgmii_tctl",   "PHY1_TXCTL",    None),
    ("rgmii_tclk",   "PHY1_TXC",      None),
    ("rly_ser",      "RLY_SER",       None),
    ("rly_srclk",    "RLY_SRCLK",     None),
    ("rly_rclk",     "RLY_RCLK",      None),
    ("pa_inhibit",   "PA_INHIBIT",    None),
    ("led_status",   "LED_STATUS",    None),
    ("led_rx",       "LED_RX",        None),
    ("led_tx",       "LED_TX",        None),
    ("led_data",     "LED_DATA",      None),
    ("dbg_rx",       "DBG_RX",        None),
    ("dbg_tx",       "DBG_TX",        None),

    # SPI — kart ici ADC yolu
    ("adc_sclk",     "ADC_SCLK",      None),
    ("adc_sdio",     "ADC_SDIO",      None),
    ("adc1_ncsb",    "ADC1_nCSB",     None),
    ("adc2_ncsb",    "ADC2_nCSB",     None),
    ("adc_sync",     "ADC_SYNC",      None),

    # SPI — cevre yolu (zayiflaticilar, PA bias, PA ADC)
    ("att_clk",      "ATT_CLK",       None),
    ("att_data",     "ATT_DATA",      None),
    ("att1_le",      "ATT1_LE",       None),
    ("att2_le",      "ATT2_LE",       None),
    ("att3_le",      "ATT3_LE",       None),
    ("att4_le",      "ATT4_LE",       None),
    ("pa_att_le",    "PA_ATT_LE",     None),
    ("bias_cs1",     "BIAS_CS1",      None),
    ("bias_cs2",     "BIAS_CS2",      None),
    ("pa_adc_cs",    "PA_ADC_CS",     None),

    ("mdc",          "MDC",           None),
    ("mdio_hat",     "MDIO",          None),
    ("phy1_nrst",    "PHY1_nRST",     None),
    ("phy2_nrst",    "PHY2_nRST",     None),
]

# Banka gerilimleri kartin besleme agindan (gen_01_power.py):
#   banka 6  +1V8   AD9251 sayisal cikislari
#   banka 3  +1V8   RTL8211F DVDD_RG ile ayni, RGMII 1.8 V
#   digeri   +3V3
BANKA_TIPI = {6: "LVCMOS18", 3: "LVCMOS18"}
VARSAYILAN_TIP = "LVCMOS33"

# Saat frekanslari. clk_eth PLL cikisi, kisiti EHXPLLL uzerindeki
# FREQUENCY_PIN_CLKOP niteliginden geliyor — burada tekrarlanmaz.
FREKANS = {
    "clk_sys":  80.0,
    "adc1_dco": 80.0,
    "adc2_dco": 80.0,
    # RGMII ALIS SAATI 125 MHz — KISIT YAZILMAZSA VARSAYILAN ALINIR.
    # Ilk kosuda pnr "rgmii_rxc: 132.24 MHz (hedef 12.00)" dedi:
    # kisit yoktu, nextpnr 12 MHz varsaydi ve yol "gecti". 12 MHz'e
    # gore kapanan bir yol 125 MHz'te on kat pay eksigi demek, yani
    # zamanlama raporu dogru gorunurken kart calismaz.
    "rgmii_rxc": 125.0,
}

# RGMII cikislarinda hizli kenar: 1.8 V'ta 125 MHz DDR, yavas kenar
# veri gozunu yiyor. Diger cikislarda hizli kenar sadece gurultu.
HIZLI = re.compile(r"^rgmii_")


def ust_portlari(yol):
    """ust.v'nin port listesini oku: [(ad, genislik|None, yon)]"""
    s = open(yol, encoding="utf-8").read()
    m = re.search(r"module\s+ust\s*\((.*?)\n\);", s, re.S)
    if not m:
        sys.exit("HATA: ust modulunun port listesi bulunamadi")
    out = []
    for yon, gen, ad in re.findall(
            r"\b(input|output|inout)\s+wire\s*(\[\s*\d+\s*:\s*\d+\s*\])?\s*(\w+)",
            m.group(1)):
        n = None
        if gen:
            ust, alt = re.findall(r"\d+", gen)
            n = int(ust) - int(alt) + 1
        out.append((ad, n, yon))
    return out


def kart_haritasi():
    b = pcbnew.LoadBoard(KART)
    fpga = [f for f in b.GetFootprints() if len(f.Pads()) > 200]
    if not fpga:
        sys.exit("HATA: FPGA footprint'i bulunamadi")
    fpga = fpga[0]
    h = {}
    for p in fpga.Pads():
        n = p.GetNetname() or ""
        if n and not n.startswith("unconnected"):
            h[n] = p.GetPadName()
    return h, fpga.GetValue()


def banka_haritasi():
    d = json.load(open(IODB))
    pkg = d["packages"][PAKET]
    md = {(m["row"], m["col"], m["pio"]): m for m in d["pio_metadata"]}
    out = {}
    for ball, loc in pkg.items():
        m = md.get((loc["row"], loc["col"], loc["pio"]))
        out[ball] = (m.get("bank"), m.get("function", "")) if m else (None, "")
    return out


def main():
    net2ball, parca = kart_haritasi()
    banka = banka_haritasi()
    portlar = dict((a, (n, y)) for a, n, y in ust_portlari(
        os.path.join(KOK, "rtl", "ust.v")))

    satir = []
    uyari = []
    eslesen = set()

    satir.append("# BU DOSYA URETILIYOR — ELLE DUZENLEME.")
    satir.append("#   python3 sentez/lpf_yaz.py")
    satir.append("# Kaynak: kicad/A_main/dogrudan_sdr_A.kicad_pcb")
    satir.append("# Parca:  %s" % parca)
    satir.append("")

    for port, kalip, genislik in ESLEME:
        if port not in portlar:
            uyari.append("ESLEMEDE var, ust.v'de YOK: %s" % port)
            continue
        eslesen.add(port)
        p_gen = portlar[port][0]
        if (p_gen or 0) != (genislik or 0):
            uyari.append("genislik uyusmuyor: %s ust.v'de %s, eslemede %s"
                         % (port, p_gen, genislik))

        indeksler = range(genislik) if genislik else [None]
        for i in indeksler:
            ag = kalip.format(i=i) if i is not None else kalip
            ad = "%s[%d]" % (port, i) if i is not None else port
            ball = net2ball.get(ag)
            if ball is None:
                uyari.append("KARTTA AG YOK: %s (port %s)" % (ag, ad))
                continue
            bank, islev = banka.get(ball, (None, ""))
            if bank is None:
                uyari.append("BALL KULLANICI I/O DEGIL: %s = %s (port %s)"
                             % (ball, ag, ad))
                continue
            tip = BANKA_TIPI.get(bank, VARSAYILAN_TIP)
            ek = " SLEWRATE=FAST" if HIZLI.match(port) else ""
            satir.append('LOCATE COMP "%s" SITE "%s";   # %s, banka %d%s'
                         % (ad, ball, ag, bank,
                            " " + islev if islev else ""))
            satir.append('IOBUF PORT "%s" IO_TYPE=%s%s;' % (ad, tip, ek))
        satir.append("")

    satir.append("# Saat kisitlari")
    for port, mhz in sorted(FREKANS.items()):
        if port in eslesen:
            satir.append('FREQUENCY PORT "%s" %.1f MHZ;' % (port, mhz))
    satir.append("")

    # ust.v'de olup eslemede olmayan port
    for p in portlar:
        if p not in eslesen:
            uyari.append("ust.v'de var, ESLEMEDE yok (pini olmayacak): %s" % p)

    cikti = os.path.join(KOK, "sentez", "ust.lpf")
    os.makedirs(os.path.dirname(cikti), exist_ok=True)
    open(cikti, "w", encoding="utf-8").write("\n".join(satir) + "\n")

    kisit = sum(1 for s in satir if s.startswith("LOCATE"))
    print("%s yazildi, %d pin kisiti" % (cikti, kisit))
    if uyari:
        print("\nUYARI (%d):" % len(uyari))
        for u in uyari:
            print("  " + u)
        return 1
    print("uyari yok")
    return 0


if __name__ == "__main__":
    sys.exit(main())

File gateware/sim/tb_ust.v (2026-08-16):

// SPDX-FileCopyrightText: Copyright (c) 2026 TA4DTA
// SPDX-License-Identifier: GPL-3.0-only
//
// TUM SISTEM TESTI — birlestirilmis cip, her cikis pininde gozlemci.
//
// NEDEN VAR. sim/ dizininde ondokuz test tezgahi vardi ve hepsi
// geciyordu, ama hicbiri UST MODULU kosturmuyordu; ust.v sadece
// sentezden geciyordu. Yani her modul tek basina dogruydu ve
// BIRLESTIRILMIS sistem hic calistirilmamisti. Entegrasyon hatalari
// tam bu boslukta yasar: yanlis baglanmis bir sinyal, ters
// polariteyle takilmis bir bayrak, hic surulmeyen bir cikis. Modul
// testleri bunlarin hicbirini goremez.
//
// UC IS YAPIYOR:
//
//   1 GERCEK UYARIM. ADC bacaklarina sinus veriliyor (cogullanmis
//     ikili kanal, tipki AD9251'in surdugu gibi), RGMII alis
//     yolundan gercek bir UDP kayit yazmasi geliyor. Uydurma
//     dahili sinyal yok — cipin gordugu sey kartta gorecegi sey.
//
//   2 HER CIKIS PININDE GOZLEMCI. Otuz yedi cikis ve iki cift
//     yonlu hattin her biri izleniyor: kac kez degisti, son degeri
//     ne. HIC DEGISMEYEN bir cikis ya test edilmemis bir islev ya
//     da baglanmamis bir sinyaldir; ikisi de bulunmasi gereken sey.
//     Bu, "kart geldi, sekiz cikis olu" surprizini tezgahta yakalar.
//
//   3 ISLEV DENETIMI. Alis zinciri paket uretiyor mu, kayit yazmasi
//     etki ediyor mu, DAC suruluyor mu, role zinciri kayiyor mu,
//     PA izni guvenli varsayilanda mi.
//
// ECP5 ilkelleri sim/ecp5_sim.v'deki davranis modelleriyle
// kosuyor ve o modellerin KENDI testi var (tb_ecp5_sim.v) — biri
// yanlis olsaydi bu test gecer ama hicbir sey kanitlamazdi.

`timescale 1ns/1ps
`default_nettype none

module tb_ust;

    integer hata = 0;

    // =================================================================
    // saatler
    // =================================================================
    reg clk_sys = 1'b0;
    always #6.25 clk_sys = ~clk_sys;        // 80 MHz

    // IKI ADC'NIN SAATI AYRI VE ARALARINDA FAZ FARKI VAR.
    //
    // Once ikisine de TEK bir saat veriyordum. Sonucu su oldu: iki
    // gecis FIFO'sunu bilerek bagimsiz bosaltip testi mutasyona
    // soktum ve test YAKALAMADI — ayni saatle iki FIFO kilitli adimda
    // doluyor, bagimsiz bosalsalar bile kaymiyorlar. Yani hizalama
    // denetimi gecen ama hicbir sey kanitlamayan bir denetimdi.
    //
    // Gercekte iki AD9251'in DCO'su ayri cikislar: ayni frekans (ayni
    // VCXO'dan turuyorlar) ama yol uzunlugu ve cip ici gecikme
    // yuzunden faz farki var. Fark modellenince FIFO'lar farkli
    // anlarda doluyor ve bagimsiz bosaltma gercekten kaydiriyor.
    reg adc_dco = 1'b0;
    always #6.25 adc_dco = ~adc_dco;        // ADC1, 80 MHz

    reg adc2_dco_r = 1'b0;
    initial begin
        #3.1;                                // faz farki, yarim cevrimden az
        forever #6.25 adc2_dco_r = ~adc2_dco_r;
    end

    reg rgmii_rxc = 1'b0;
    always #4 rgmii_rxc = ~rgmii_rxc;       // 125 MHz, PHY'den

    // =================================================================
    // cip
    // =================================================================
    reg  [13:0] adc1_d = 14'd0, adc2_d = 14'd0;
    reg         adc1_or = 1'b0, adc2_or = 1'b0;
    reg  [3:0]  rgmii_rd = 4'd0;
    reg         rgmii_rctl = 1'b0;
    reg         dbg_rx = 1'b1;

    wire [13:0] dac_a, dac_b, dac2_d;
    wire dac_wrt_a, dac_wrt_b, dac2_iqwrt, dac2_iqsel, dac2_iqreset;
    wire [3:0] rgmii_td;
    wire rgmii_tctl, rgmii_tclk;
    wire rly_ser, rly_srclk, rly_rclk, pa_inhibit;
    wire led_status, led_rx, led_tx, led_data, dbg_tx;
    wire adc_sclk, adc1_ncsb, adc2_ncsb, adc_sync;
    wire att_clk, att_data, att1_le, att2_le, att3_le, att4_le;
    wire pa_att_le, bias_cs1, bias_cs2, pa_adc_cs;
    wire phy1_nrst, phy2_nrst, mdc;
    wire adc_sdio, mdio_hat;

    ust dut (
        .clk_sys(clk_sys),
        .adc1_dco(adc_dco), .adc1_d(adc1_d), .adc1_or(adc1_or),
        .adc2_dco(adc2_dco_r), .adc2_d(adc2_d), .adc2_or(adc2_or),
        .dac_a(dac_a), .dac_wrt_a(dac_wrt_a),
        .dac_b(dac_b), .dac_wrt_b(dac_wrt_b),
        .dac2_d(dac2_d), .dac2_iqwrt(dac2_iqwrt),
        .dac2_iqsel(dac2_iqsel), .dac2_iqreset(dac2_iqreset),
        .rgmii_td(rgmii_td), .rgmii_tctl(rgmii_tctl),
        .rgmii_tclk(rgmii_tclk),
        .rgmii_rd(rgmii_rd), .rgmii_rctl(rgmii_rctl),
        .rgmii_rxc(rgmii_rxc),
        .rly_ser(rly_ser), .rly_srclk(rly_srclk), .rly_rclk(rly_rclk),
        .pa_inhibit(pa_inhibit),
        .led_status(led_status), .led_rx(led_rx),
        .led_tx(led_tx), .led_data(led_data),
        .dbg_rx(dbg_rx), .dbg_tx(dbg_tx),
        .adc_sclk(adc_sclk), .adc_sdio(adc_sdio),
        .adc1_ncsb(adc1_ncsb), .adc2_ncsb(adc2_ncsb), .adc_sync(adc_sync),
        .att_clk(att_clk), .att_data(att_data),
        .att1_le(att1_le), .att2_le(att2_le),
        .att3_le(att3_le), .att4_le(att4_le),
        .pa_att_le(pa_att_le),
        .bias_cs1(bias_cs1), .bias_cs2(bias_cs2), .pa_adc_cs(pa_adc_cs),
        .phy1_nrst(phy1_nrst), .phy2_nrst(phy2_nrst),
        .mdc(mdc), .mdio_hat(mdio_hat)
    );

    // =================================================================
    // ADC UYARIMI — cogullanmis ikili kanal, sinus
    //
    // AD9251 cogullanmis modda iki kanali TEK yolda veriyor: A ve B
    // ornekleri DCO'nun ayri kenarlarinda. Veri, yakalayacak kenardan
    // once degisiyor ki goz merkezi kenara denk gelsin (tb_adc.v ile
    // ayni yaklasim).
    //
    // Iki kanala FARKLI frekans veriliyor. Ayni sinyali verseydik
    // kanallarin yer degistirmesi gorunmezdi.
    // =================================================================
    // HIZALAMA KIPI. ADC arayuzu hangi kenarin A hangisinin B
    // oldugunu kendi buluyor: iki kanala FARKLI test deseni yazilip
    // hangisinin tuttuguna bakiliyor. Bu islev sistem duzeyinde hic
    // test edilmemisti, ve gozlemci raporu onu dolayli yoldan
    // gosterdi — pa_inhibit hic yukselmiyordu, cunku
    //     pa_inhibit = veris_ac & a1_hizali & a2_hizali & kopek_canli
    // ve hizalama hic tamamlanmiyordu.
    //
    // Yani "verici acilmiyor" bulgusunun altindan "hizalama test
    // edilmemis" cikti. Tasarim dogru: ADC hizalanmadan yayin
    // yapilmamali.
    // IKI ADC'YE AYRI VERI. Yorumda "farkli frekans veriliyor"
    // yaziyordu ama kod ikisine de AYNI degeri suruyordu; yani iki
    // ADC'nin yer degistirmesi ya da FIFO'larin birbirine gore
    // kaymasi bu testte hic gorunmezdi. Yorum dogru, kod yanlisti.
    //
    // Simdi ADC2, ADC1'in sabit bir ofset kaymisi. Boylece hizalama
    // dogrudan olculebiliyor: FIFO cikisinda fark HER ZAMAN AYRIM
    // olmali. Kayarlarsa fark degisir.
    localparam signed [13:0] AYRIM = 14'sd1000;

    reg        hiza_kip = 1'b0;
    localparam [13:0] DESEN_A = 14'h1234;
    localparam [13:0] DESEN_B = 14'h2ABC;

    real faz_a = 0.0, faz_b = 0.0;
    localparam real PI = 3.14159265358979;
    integer ornek_sayaci = 0;
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

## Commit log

2026-08-14 Initial release
    A direct-sampling SDR transceiver with four phase-coherent receive
    channels, and a class-A power amplifier that gives 5 to 100 W. The
    frequency range is 1.8 MHz to 54 MHz.
    Three boards: A holds the converters, the FPGA and the host interface;
    C holds the band filters and the transmit/receive relays; D is the
    power amplifier.
    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
    [01_driver.kicad_sch, 01_power.kicad_sch, 02_clock.kicad_sch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]
2026-08-14 Correct the converter and clock figures
    The README gave 65 MSPS for the ADC and 125 MSPS for the DAC. Those are
    other speed grades of the same part families and not what this design
    uses. The board carries an AD9251BCPZ-80 and clocks both converters at
    80 MSPS from an 80.000 MHz VCXO.
    The jitter section was also wrong. It quoted 1 ps and a 74.5 dB limit.
    The measured budget is 60 fs from the VCXO and 54 or 150 fs from the
    fan-out buffer, which give 81 fs in a narrow band and 162 fs in a wide
    band. The table now gives the limit at 30 MHz and at 500 MHz.
2026-08-15 Update the hardware tools and add the gateware
    This commit makes the public tree equal to the development tree. The
    public tree was behind. It did not have the verification tools, the
    build chain, or the FPGA source.
    The hardware/kicad directory now has the full tool chain. This
    includes yap.sh, which runs the steps in the correct order, and the
    tools that check the boards.
    The gateware directory is new. It has the Verilog source for the
    Lattice ECP5, the test benches, and the synthesis script. The
    gateware does the four-channel receive chain, the transmit chain, the
    packet interface, and the control interface.
    The internal Turkish documents stay in the development tree. The
    documentation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
    [01_driver.kicad_sch, 02_final.kicad_sch, 03_bias.kicad_sch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]
2026-08-15 Connect the four transmit channels
    The gateware had a four-channel transmit chain and a driver for the
    multiplexed DAC. The top level did not use them. It used one channel
    and sent zero samples. Two test benches were not in the test list.
    The driver for the multiplexed DAC was too slow. It used four phases
    for each sample pair. At 80 MHz this gives 20 MSPS for each channel.
    The module header said 40 MSPS. Two phases give 40 MSPS.
    The IQWRT signal comes from a DDR output. The data changes on the
    rising clock edge. IQWRT goes high on the falling clock edge. This
    gives 6.25 ns of setup time and 6.25 ns of hold time. The AD9767
    needs 2.0 ns and 1.5 ns.
    All four channels must use the same samp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
2026-08-15 Connect the pads that had no net
    A symbol pin number must agree with the footprint pad number. If the
    numbers do not agree, the net goes nowhere. The netlist removes it
    and gives no message. ERC examines the schematic and sees a wire. DRC
    does not count an unconnected pad as a violation. All three boards
    showed zero ERC violations while 31 pads had no net.
    Two of these faults stopped a board.
    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
    [01_driver.kicad_sch, 01_power.kicad_sch, 02_clock.kicad_sch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]
2026-08-15 Add the Ethernet receive path
    The transmit path operated correctly. The receive path did not exist.
    The host could only write registers through the UART at 115200 baud.
    rgmii_alis makes bytes from the DDR nibbles. It looks for the start
    frame delimiter and does not count the preamble bytes, because
    switches make the preamble shorter. It decodes RX_CTL on both clock
    edges and thus uses the error signal of the PHY. It checks the CRC
    with the residue of the data and the FCS together. The residue is
    0xDEBB20E3 for this reflected CRC.
    udp_ayikla removes the Ethernet, IPv4 and UDP headers. The payload
    uses the same frame format as the UART. Thus host_arayuz decodes both
    paths. The module holds t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
    [lpf_yaz.py]
2026-08-15 Remove the pads that have no copper from the DSN export
    The router reported the same 220 clearance violations in each pass.
    At the same time the number of unrouted connections decreased. The
    violations were thus in the input and not in the routing.
    The -1EP footprints of KiCad put four paste apertures on the exposed
    pad. These apertures stop full paste coverage and they have no copper
    layer. The DSN export put them on the top copper layer. The image of
    U51 in the DSN had 21 pins: 17 correct pins and four unconnected
    copper islands in the exposed pad. These islands are always in
    conflict with the pad and they close the area below it.
    The export now removes a pad that has no copper layer. Th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
    [01_driver.kicad_sch, 01_power.kicad_sch, 02_clock.kicad_sch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]
2026-08-15 Correct the clearance test for the pre-routed traces
    The clearance test used a circle for each pad. The radius was
    max(width, height)/2. The corner of a rectangle is at
    hypot(width, height)/2 from the center. The test thus made the pad
    smaller than it is. On the 2.5 x 4.5 mm gate pad of a TO-247 the
    difference is 2.250 mm against 2.574 mm.
    The DRN_A trace was on the gate pad of Q10 with an overlap of 35 um.
    This is a short circuit between the 50 V drain rail and the gate of a
    100 W device. The search that finds the tee offset accepted this
    route. The overlap is at a corner and 35 um wide. You cannot see it
    on a plot.
    The test now uses the real shape of the pad and the collision test of
    pcb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
    [01_driver.kicad_sch, 01_power.kicad_sch, 02_clock.kicad_sch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]
2026-08-15 Correct the schematic faults that ERC cannot find
    An agent examined the three schematics against the datasheets. ERC
    reported zero violations before and after this work. None of these
    faults are visible to ERC.
    The comparator for the external 10 MHz reference was in shutdown. The
    SHDN pin of the TLV3501 went to +3V3. Sixteen DRV8833 devices had VCP
    and VINT unconnected. Without the charge pump none of the 28 filter
    relays can latch. Seven regulators had no decoupling capacitor within
    18 mm to 94 mm. On board D the nearest +12V capacitor to an LM358 was
    227 mm away on a 275 mm board.
    The PE4312 devices had no series 10k resistor on pin 3. The datasheet
    makes this necessary for the attenuati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
    [01_driver.kicad_sch, 01_power.kicad_sch, 02_clock.kicad_sch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]
2026-08-15 Correct the status and the size of board D in the README
    The README said that the gateware does not exist. The gateware exists
    and it operates in simulation. The status section now gives the
    correct information and it says that no board is ready for
    manufacture.
    The size of board D was 240 x 185 mm in the table. The board is
    275 x 185 mm.
    The repository content table now shows the gateware directories.
2026-08-15 Move each decoupling capacitor to the pin it serves
    The audit found 14 chips with no decoupling capacitor within 15 mm.
    Across the boards the nearest capacitor to a supply rail was a median
    7.5 mm on A and 6.3 mm on C, and 91 mm in the worst case. A capacitor
    45 mm from its pin has about 45 nH of loop inductance, near 2.8 ohm at
    10 MHz, where milliohms are necessary. It is on the schematic, it is
    in the BOM, it is fitted, and it does nothing.
    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
    [01_driver.kicad_sch, 01_power.kicad_sch, 02_clock.kicad_sch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]
2026-08-15 Do not count a bulk capacitor as decoupling
    The placement pass accepted any capacitor on the rail as sufficient.
    On board A the flash memory had 10 uF at 5.5 mm and 47 uF at 16.3 mm,
    so the pass was satisfied. Both are bulk. The nearest 100 nF was
    17.0 mm away, and at that distance the loop inductance removes the
    reason to fit it.
    The audit tool already used a 10 uF ceiling for this. The placer did
    not, so the two disagreed, and the placer was wrong.
    The pass now treats only capacitors of 1 uF and below as decoupling,
    both when it asks whether a pin is served and when it selects one to
    move. It also searches a ring around the pin for free space instead
    of using a fixed offset.
    Findings fa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
    [01_driver.kicad_sch, 01_power.kicad_sch, 02_clock.kicad_sch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]
2026-08-15 Let the placer, not the separator, own the capacitor position
    Placing a capacitor beside its supply pin and then resolving overlaps
    moves it away again. On board C the pass put a 100 nF 4.7 mm from the
    attenuator's pin, the separator cleared 191 overlaps, and the
    capacitor finished 17.9 mm away.
    The pass now runs after separation and searches for free space around
    the pin itself, so it does not need the separator afterwards. It
    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
    [dogrudan_sdr_A.kicad_pcb, dogrudan_sdr_C.kicad_pcb, dogrudan_sdr_D.kicad_pcb]
2026-08-15 Compare symbol pins against footprint pads before placement
    Every fault that would have stopped a board in this work sits in one
    layer: a symbol pin number that does not agree with a footprint pad
    number. The ADC paddle was pin 0 against pad 65. The attenuator
    paddle was named Pad against pad 21. The gas discharge tubes used
    pins 1 and 3 against pads 1 and 2. The crystal had two pins on a
    four-pad part, so XO went to the can. The Ethernet PHY carried the
    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
    [01_driver.kicad_sch, 02_final.kicad_sch, 03_bias.kicad_sch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]
2026-08-15 Replace the receive band filters: they passed nothing
    Simulation in ngspice shows all six filter positions peak below the
    band they must pass, with the band itself 24 to 41 dB down. The
    receiver would have been deaf on every band. No connectivity check
    can find this: the netlist is correct and the values are wrong.
    The cause is arithmetic. The three resonators were tuned as bare LC
    pairs, but the coupling capacitors sit in parallel with them and pull
    the frequency down. On 160m, 430 pF of resonator plus 270 pF of end
    coupling plus 62 pF between resonators gives 762 pF, and with 16 uH
    that is 1.44 MHz against a band at 1.8 to 2.0 MHz.
    Compensation alone is not sufficient. Top coupling is a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
    [01_power.kicad_sch, 02_protect.kicad_sch, 03_filter.kicad_sch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]
2026-08-15 Replace the transmit filters: harmonic suppression was illegal
    Simulation of the output filters shows second-harmonic suppression
    between 3 and 30 dB, where 43 dB is necessary below 30 MHz and 60 dB
    above. On the 80/60 m position the second harmonic of 3.5 MHz is
    3.4 dB down: the filter barely touches it. The transmitter would have
    been out of specification on every band, and the board gives no sign
    of it. Output power, SWR and efficiency all read correctly while the
    harmonic radiates.
    The cause is the band grouping. One position must pass 5.37 MHz, so
    its cutoff is at 6.0, and the second harmonic of the same position's
    lowest band, 3.5 MHz, falls at 7.0. More poles do not help: by the
    Cheb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
    [01_driver.kicad_sch, 02_final.kicad_sch, 03_bias.kicad_sch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]
2026-08-15 Fit the filter bank and clear the overlaps
    Board D's filter bank needs 285.6 mm of width with both inductors of
    each band side by side, against about 236 mm available. Stacking them
    vertically corrects the width and breaks the height: the strip
    between the driver transformer and the relay row is 15.8 mm and a
    stacked pair of T68 cores needs 37.7 mm.
    Mapping the board in 10 mm bands gave the answer. Everything below
    the relay row is the coupler and detector block at x above 250, while
    the filter columns run from x 4 to 236. The space under them was
    empty. The relay row moves from y 130 to 142 and its drivers from 155
    to 172, with the filter block following. No board grew and the chain
    stays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
    [01_power.kicad_sch, 02_protect.kicad_sch, 03_filter.kicad_sch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]
2026-08-15 Update the ARDC package and record the simulation results
    The package had drifted from the boards again: board C's BOM was 45
    lines out of date and D's 46, and the schematic PDFs predated both
    filter redesigns.
    The verification document gains a section on circuit simulation. Every
    check before it asks which pin joins which net; none of them can say
    whether a capacitor's value is correct. That section holds the
    measurements for both redesigns and, separately, the three faults the
    simulation tools had themselves: a source divider that made every
    insertion loss 6 dB too pessimistic, an E12 rounding helper that
    multiplied instead of dividing, and an inductor loss computed at a
    fixed 1 MHz.
    Two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
    [01_driver.kicad_sch, 01_power.kicad_sch, 02_clock.kicad_sch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]
2026-08-15 Close the last overlaps and record the pass that undid the other
    Board D reaches zero overlaps. Two remained after the relay row
    moved: a T68 clipping the driver transformer by 1 x 2 mm, and two
    2N7002 transistors two millimetres apart, which the separator was
    never going to touch because both begin with Q.
    One finding is left on D. Tracing a single capacitor through every
    stage shows the mechanism:
    pcb_kur 121.2 mm from the chip
    placement 5.1 mm correct
    separation 21.0 mm pushed away
    decoupling pass 25.3 mm handed to another chip
    The placer puts the capacitor beside the pin that needs it, the
    separator finds an overlap and moves it, and the decoup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
    [dogrudan_sdr_A.kicad_pcb, dogrudan_sdr_C.kicad_pcb, dogrudan_sdr_D.kicad_pcb]
2026-08-15 Give each regulator the part number its rail needs
    A fixed-output LDO carries its voltage in the part number. If the
    number is wrong the schematic does not change: the netlist is correct,
    ERC is clean, DRC is clean, and the rail comes up at the wrong
    voltage.
    U3 was specified as TPS7A2033. The last two digits are the output, so
    33 is 3.3 V and 18 is 1.8 V. Its output feeds +1V8, which supplies the
    FPGA's bank 6 and 3 VCCIO across twenty pads. The wiring was correct
    and only the part number was wrong.
    The six ADP150 regulators all carried the value "ADP150" and collapsed
    into one BOM line under one code, which is the 2.5 V version. Their
    outputs are 1.8, 1.8, 1.8, 2.5, 3.3 and 3.3 V. That l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
    [01_power.kicad_sch, 02_clock.kicad_sch, 03_adc.kicad_sch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]
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2026-08-15 Correct the filters, and the tools that had stopped matching them
    Rounding a trap capacitor to the E24 series moves its notch by 2% and
    costs 19 dB of rejection. On the 40/30 m position that left 39 dB of
    second-harmonic suppression where the legal limit is 43. The original
    measurement used the exact synthesised value while the schematic used
    the rounded one, and nothing compared the two. Each trap now uses two
    E24 capacitors in parallel. All seven positions pass, with 58.7 dB in
    the worst case.
    This came to light only because three verification tools had drifted
    from the boards they check. One modelled six filter positions without
    traps while the board has seven with them, and called every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
2026-08-15 Add a transmission zero to two preselector positions
    The receiver samples at 80 MSPS. Nyquist is 40 MHz. A signal above
    40 MHz folds onto the band as |f - 80|. After the fold, the receiver
    cannot tell it from the wanted signal. Digital processing cannot
    remove it. The preselector is the only protection.
    A new tool measures the full chain. It goes from the antenna to the
    ADC pin. It includes the attenuator, the transformer, the series
    resistors and the ADC input capacitance. A filter alone gives the
    wrong answer, because each block sees the impedance of its neighbour.
    The tool found two weak bands:
    15 m to 10 m 50.3 MHz folds onto 29.7 MHz 24 dB
    6 m 30.0 MHz folds onto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
    [01_power.kicad_sch, 02_protect.kicad_sch, 03_filter.kicad_sch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]
2026-08-15 Correct the voltage rating of the RF capacitors on board D
    The BOM had no verified order code for 245 parts. The BOM program
    recognised the format of a value and wrote "BASE" for all of them. It
    did not examine availability.
    A new tool queries the supplier. It does not accept "the part
    exists". The package and the value must agree exactly. The stock must
    be more than the quantity. It also reads the properties of the part.
    Two faults came out of this:
    The trap capacitors were 50 V parts. The carrier peak voltage is
    100 V at 100 W into 50 ohms, and the voltage across the trap inductor
    is 93 V. A 50 V part shows the same value in the catalogue and then
    breaks down. The fault appears only whe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
    [01_driver.kicad_sch, 02_final.kicad_sch, 03_bias.kicad_sch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]
2026-08-15 Correct the transmit envelope and add a third zero on 15 m to 10 m
    The unit has no reconstruction filter. A comment on board A said that
    the filter is on board C. Board C has no such filter: the transmit
    signal enters through an SMA connector and goes to the transmit and
    receive relay. The datasheet also gave a cutoff frequency for this
    filter that does not exist.
    A sampling DAC does not make one frequency. It makes images at
    |k*fs +/- fd|. The zero-order hold gives each image a different
    level, and the function falls slowly. If the carrier is near Nyquist,
    an image at a lower frequency can be stronger than the carrier.
    A new tool measures this. It uses the harmonic filter of board D,
    beca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
    [01_driver.kicad_sch, 01_power.kicad_sch, 02_clock.kicad_sch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]
2026-08-15 Add BIAS_KILL to remove a single-fault destruction path
    Each final device has its own closed-loop bias servo: a 0.01 ohm
    sense resistor, an INA240A1 with a gain of 20, an LM358 integrator,
    and the gate. Separate servos are correct for paralleled MOSFETs,
    because different threshold voltages make one device take most of the
    current.
    A new tool measures the loop in ngspice. It does not model the inside
    of the MOSFET. The boundary conditions are sufficient: input
    capacitance, transconductance and threshold voltage.
    The loop is stable. The crossover is at 25.7 Hz, the phase margin is
    90 degrees, and the current reaches the set value in 106 ms.
    The failure behaviour is destructive. The integra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
    [01_driver.kicad_sch, 02_final.kicad_sch, 03_bias.kicad_sch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]
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2026-08-15 Give the cooling requirement and the mounting constraint
    Class A gives the most linear operating point, and this unit needs
    linearity. The cost appears here. At 100 W output the DC input is
    333 W, and 233 W becomes heat. Each device dissipates 58.3 W.
    The first two thermal steps see the power of ONE device. The
    heatsink-to-air step sees the TOTAL power. This difference changes
    the answer by a factor of two.
    Direct mounting is not possible. The tab of the TO-247 package is the
    drain. This is a push-pull stage, and the two arms have different
    drain voltages. Four devices on one heatsink without insulation
    short-circuit the output transformer primary. The first version of
    the tool offered dir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
2026-08-15 Add bulk capacitors to the 1.8 V rails and measure the supply network
    Counting decoupling capacitors is not enough. The existing check asks
    whether each supply pin has a capacitor. That is necessary but not
    sufficient. What matters is the impedance that the chip sees on the
    rail, against frequency. No connectivity check can see this: the
    schematic is correct, the netlist is correct, the DRC is clean, and
    the rail still rings.
    The +1V8 rail and the +1V8_D rail had no bulk capacitor. The largest
    part was 1 uF. The regulator loop holds the impedance low to about
    100 kHz. The ceramics hold it above about 1 MHz. Between them there
    was nothing. The peak impedance on +1V8 was 994 mohm against a ta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
    [01_power.kicad_sch, 02_clock.kicad_sch, 03_adc.kicad_sch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]
2026-08-16 Design for tolerance, not for nominal values
    Every measurement until now used nominal component values, and all
    six bands passed. But no component is nominal. A design that passes
    at nominal values and fails in production is the most expensive kind
    of fault, because it appears only after the boards arrive.
    A new tool measures the same design with real parts: capacitors at
    ±5 %, inductors at ±5 %, temperature from −20 °C to +60 °C. It does
    two things. Worst-case analysis puts every part at its worst end at
    the same time. Monte Carlo gives the fraction of boards that pass.
    The result was bad:
    6 m 54 % of boards pass, flatness 1.8 dB to 10.2 dB
    15 m to 10 m 77.5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
    [01_power.kicad_sch, 02_protect.kicad_sch, 03_filter.kicad_sch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]
2026-08-16 Simulate the assembled chip and put an observer on every output
    The simulation directory had nineteen testbenches, and all of them
    passed. But none of them ran the top module. The top module only went
    through synthesis. Each module was correct alone, and the assembled
    system had never run. Integration faults live in that gap: a wrong
    connection, a flag with reversed polarity, an output that nothing
    drives.
    The cause was also found. The top module declared twenty-four
    internal signals after their use. With `default_nettype none` there
    are no implicit wires, so synthesis was correct. But Icarus Verilog
    applies the declare-before-use rule, so the top module COULD NOT be
    simulated. That is why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
    [tb_ust.v]
2026-08-16 Prove the register write path and synchronise the reset per clock domain
    A testbench proves the cases it tries. Formal verification proves
    that no input exists that breaks the property. Three proofs were
    written, and all three were tested by mutation. A proof that passes
    but catches nothing is the worst kind of verification, because it
    gives confidence.
    host_arayuz No byte sequence with a wrong checksum can produce a
    register write, in any order. The written address and
    data are the values in the frame. This path drives the
    PA gate bias, the transmit frequency and the relay
    chain.
    fifo_gecis No valid signal when empty, no re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
    [tb_ust.v]
2026-08-16 Add a capture register, flatten the CRC, and run the netlist
    Three changes. Measurement drove each one.
    **The phase budget.** The nextpnr LPF cannot express this constraint.
    `BLOCK PATH FROM CLKNET ... TO CLKNET ...` gives "ignoring
    unsupported LPF command". A false path is also the wrong answer,
    because it tells the tool not to measure the path, and we want it
    measured.
    A new tool computes the budget outside the placer. The delay inside
    the FPGA comes from the nextpnr report, the ADC delay from the
    datasheet, and the board traces from the length measurement. The
    boards are not routed yet, so the trace terms are zero for now.
    The first measurement showed that setup was not met: −1.72 ns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
2026-08-16 Build the grant package with the tools, and correct the board documents
    This folder was assembled by hand once. Thirteen commits then went by.
    The bill of materials in it gave 150 nH for a band filter inductor
    when the board had 68 nH, after two separate redesigns. If that
    package had gone out, it would have carried the wrong schematic.
    A package assembled by hand becomes old without anyone seeing it.
    `ardc/topla.py` now builds it from nothing on each run: the schematic
    PDFs from the current source, the bills of materials from the current
    generator, and the evidence document by running the tools and
    recording what they report. Each number in the document was measured
    by the run that wrote t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
    [BOM_A.csv, BOM_C.csv, BOM_D.csv]

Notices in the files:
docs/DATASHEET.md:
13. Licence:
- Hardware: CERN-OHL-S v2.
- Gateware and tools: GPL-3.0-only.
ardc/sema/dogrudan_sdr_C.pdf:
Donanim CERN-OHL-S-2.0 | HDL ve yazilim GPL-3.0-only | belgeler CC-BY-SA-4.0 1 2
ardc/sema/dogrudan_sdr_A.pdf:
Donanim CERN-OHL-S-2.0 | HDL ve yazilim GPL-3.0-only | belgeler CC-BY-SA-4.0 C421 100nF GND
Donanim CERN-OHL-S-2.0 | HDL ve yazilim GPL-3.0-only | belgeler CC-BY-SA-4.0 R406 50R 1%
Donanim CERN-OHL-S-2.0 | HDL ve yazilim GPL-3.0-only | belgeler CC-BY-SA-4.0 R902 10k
